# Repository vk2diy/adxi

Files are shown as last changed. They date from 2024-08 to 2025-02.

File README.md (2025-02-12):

# adxi - ADX Improved

[ADX](https://github.com/WB2CBA/ADX) is an abbreviation for Arduino Digital Xceiver, a project emphasizing simplicity and Arduino hardware creating a [direct-conversion receiver](https://en.wikipedia.org/wiki/Direct-conversion_receiver) focused on [digital modes](http://www.arrl.org/digital-data-modes).

The ADX project was based upon firmware by [JE1RAV](https://github.com/je1rav/QP-7C) extending on original work by Burkhard Kainka (DK7JD) ([original German](https://www.elektronik-labor.de/HF/FT8QRP.html), [English translation](https://www-elektronik--labor-de.translate.goog/HF/FT8QRP.html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)).

This (very distant!) fork of ADX is called __adxi__ (or "ADX Improved") with the following major changes:
 * __abandon simplicity as a design philosophy__ since it limits our feature set and understanding
 * __improved design documentation__ to facilitate learning
 * __restores access to the project for modern KiCad__
 * __integrate known bug fixes__
 * __operates from a single USB-C cable__ replacing the need for an MCU programming cable, a power cable, an audio input cable, an audio output cable, and a host computer sound card.
 * __USB-C power supply__
 * __full computer control__ (remove buttons/blinkenlights interface)
 * __improved filtering__
 * __SWR, forward power and reverse power metering__ for debugging, safety and performance analysis
 * __supports more amateur bands__: 70cm/2m/10m/15m/17m/20m/30m/40m/60m/80m/160m/630m/2200m
 * __use of modern surface mount components__ for repeatability
 * __using platformio__ to manage the firmware build and dependencies in a modern way

## Other projects
 * Same MCU
   * [ADX](https://github.com/WB2CBA/ADX) ($? / ATMega328P based / multiple bands with effort / LED blinkenlights/ CD2003GP direct conversion receiver)
   * [(tr)uSDX](https://dl2man.de/) (PE1NNZ and DL2MAN) ($50 / ATMega328P based / multiple bands with effort / small OLED / direct sampling)
     * Based on [µSDX](https://github.com/threeme3/usdx)
 * Fancy-pants MCU
   * [sbitx](https://github.com/afarhan/sbitx) ($150+ / RPi4 based / 8 bands preconfigured / large OLED) ([documentation](https://www.sbitx.net/), [designer website](https://www.hfsignals.com/index.php/sbitx-v3/)) (newer zbitx)
 * Discussion
   * [ucx discussion group](https://groups.io/g/ucx)

## Project scope

The project scope generally includes the following:
 * Main board
 * Late stage board modules (each for different frequency bands)
 * Assembly information
 * Design documentation
 * Debugging documentation

## Current status of this fork

The first boards have been received and despite issues have been verified as partly functional.

Completed:

 - [x] Updated schematic (Kicad 8)
 - [x] Layout
 - [x] Late stage module interface design
 - [x] Design and layout of first late stage module 
 - [x] Firmware building correctly under platformio
 - [x] Final design review
 - [x] Order boards

Underway:

 - [x] Board testing and bringup
   - [x] USB hub verified
   - [x] USB audio verified
   - [x] USB MCU module passthru verified
   - [x] Power stage testing completed (issues found; resolution proposed and partly bench tested)
     - [x] Design and order power stage fix board
     - [x] Receive and assemble power stage fix board
     - [x] Debug power stages with fix board
   - [x] Assemble, solder-configure and mount late stage module
   - [ ] Firmware authoring to verify remaining functional blocks (in progress)
   - [ ] WSJT software integration testing (in progress)
 - [ ] Test late stage module
 - [ ] Verify overall system functionality
 - [ ] adxi-1.3 main board revision - incorporating power stage fixes and other improvements.
   - [x] Created new board tree

## Update (2025-01-27)

 * Started on looking at the late stage module (LSM) board.
 * Isolated 40M band LPF on a new board by cutting the trace from the impedance matching.
 * Instrumented both sides with NanoVNA but did not get expected results from the 7th order Butterworth approximation with values produced by [classe2-calculator](https://github.com/vk2diy/classe2-calculator), namely:
   * Command line: `./classe2 -p 5 -v 12 -b 40m -t infinite --l1 7.755uh -m SI2304DDS`
     * ie. Power 5W, voltage 12V, band 40m, type infinite, Class E L1 value 7.755uH, MOSFET SI2304DDS.
   * Output for precise configuration (not used): `7th = (0.23% error, 18 parts): C1_lpf=132.00pF (220.00pF || 330.00pF) L1_lpf=0.93µH (2.2µH || 2.7µH || 3.9µH) C2_lpf=536.00pF (33.00pF + 33.00pF + 470.00pF) L2_lpf=1.5µH (2.7µH || 3.3µH) C3_lpf=536.00pF (33.00pF + 33.00pF + 470.00pF) L3_lpf=0.93µH (2.2µH || 2.7µH || 3.9µH) C4_lpf=132.00pF (220.00pF || 330.00pF)`
   * Output for approximation configuration (used): `7th ≈ (13.57% error, 7 parts): C1_lpf=150.00pF L1_lpf=1µH C2_lpf=470.00pF L2_lpf=1.5µH C3_lpf=470.00pF L3_lpf=1µH C4_lpf=150.00pF`
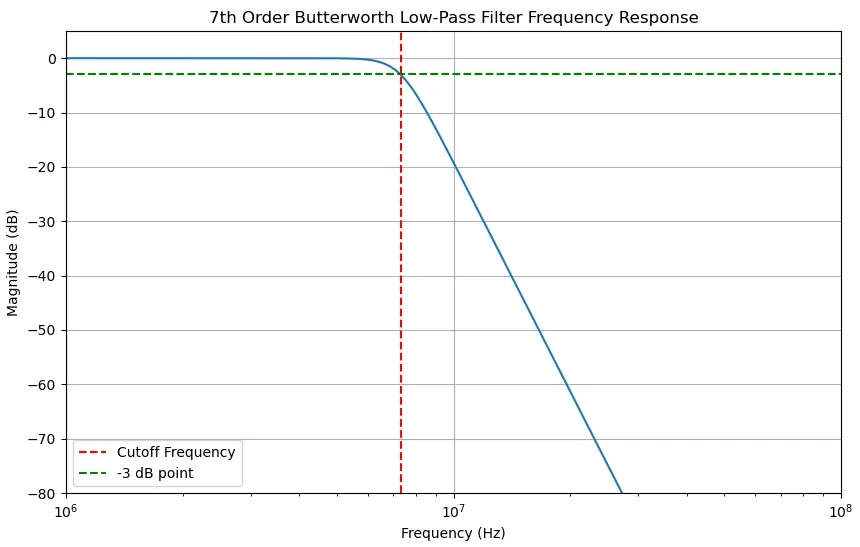
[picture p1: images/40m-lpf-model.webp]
 * I had expected to see a rapid falloff at a specific frequency, like this modeled version: 
 * However, instead I obtained very different results.
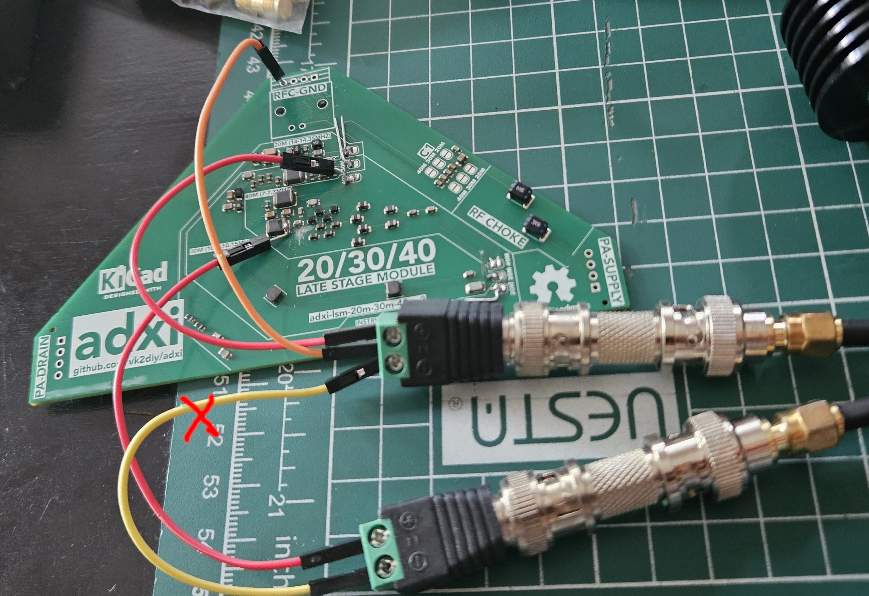
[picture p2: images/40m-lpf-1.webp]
   * __Test setup__. I did try to test with the extra ground cable shown with a red X, but removed it (ground loop). No substantial change.  
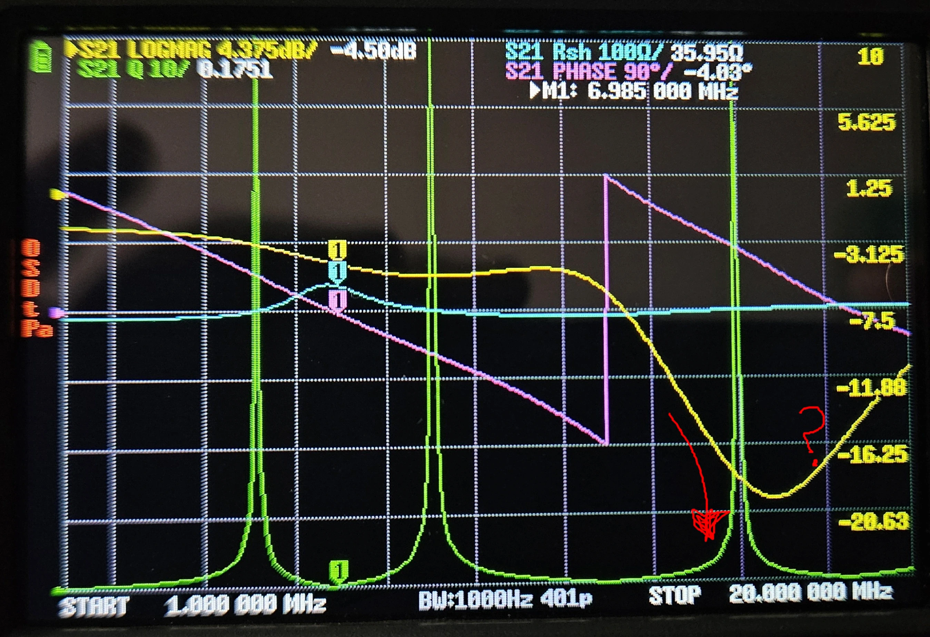
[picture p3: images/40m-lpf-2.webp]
   * __Test result__. This remained fairly constant in all test configurations (with and without termination resistors, various ground configurations). 
     * What we can see here is:
       * __S21 Logmag__ in yellow (~"through signal attenuation") shows a downward slope within the target band (marker location) before a flat response through around 13MHz at which it begins to taper off fairly steeply until 17MHz at which point it begins to climb again.
         * Our expectation would have been "falling off a cliff" after the filter cutoff frequency and not recovering until very high frequencies due to self-resonance of individual components.
         * This is a head scratcher.
       * __S21 Q10__ in green (~"resonance or energy storage potential") is an undesirable feature in a low pass filter. However, we can see significant Q values around 5MHz and 9MHz.
         * This would seem to indicate there is a source of resonance within the test circuit which we have not identified. However, without other points of comparison it may be hard to determine how abnormal this is.
       * __S21 Rsh__ in cyan (~"shunt resistance") exhibits a small peak around the target frequency but is otherwise flat.
       * __S21 Phase__ in magenta (~"phase angle") shows the target frequency band exists within the middle of a smooth phase cycle. There is no information in this to suggest an issue. However, it is notable that the phase shifts at 13MHz where we see the attenuation increase markedly. From prior experience it is common and expected for phase change to align with the end of designed frequency ranges.
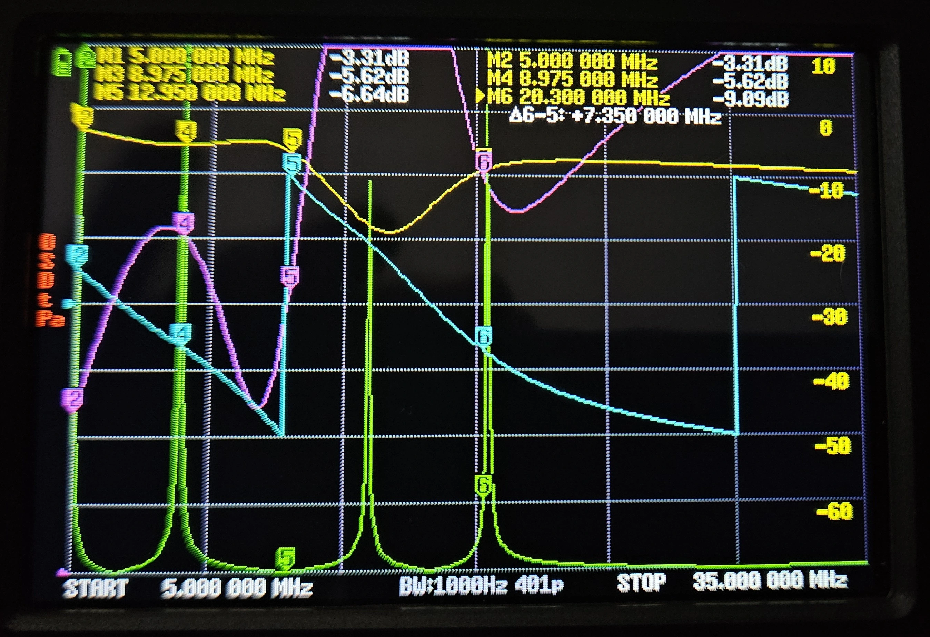
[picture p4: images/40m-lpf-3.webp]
   * __Broader result__. This shows markers for the 40m as well as 30m and 20m bands. You can see the attenuation restores rather than decays with increasing frequency after 17MHz, which is unexpected.  
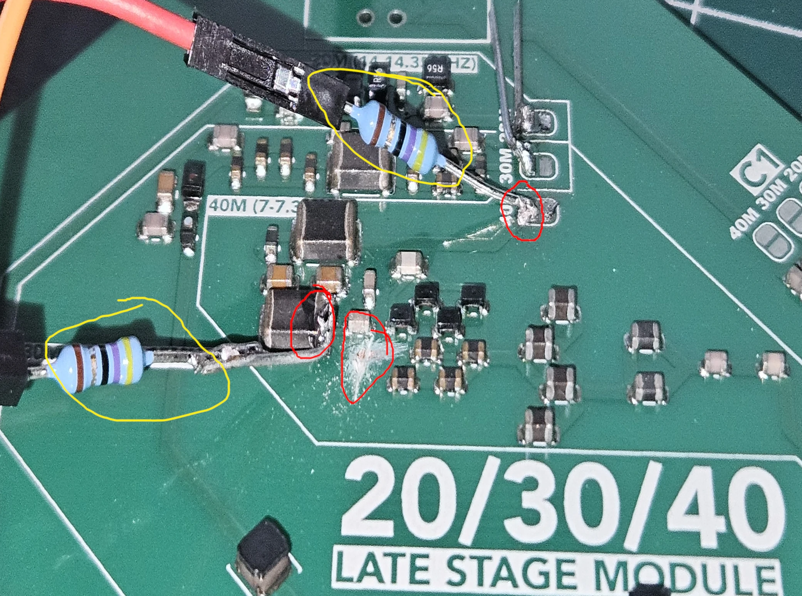
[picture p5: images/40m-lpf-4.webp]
   * __Final test setup__. Note cut trace, solder points and 47 ohm series resistors at either end. No substantial difference. 
 * I am as yet uncertain why this is.
   * Hypothesis: Incorrect impedance matching.
     * Determination: Invalid. Added 47Ω resistors either site of the LPF DUT with no substantial difference observed.
   * Hypothesis: Low SRF components.
     * Determination: Invalid. All components in the filter, both small capacitors and inductors should have higher SRFs, at least in the 100-200M+ range at a minimum. However, they are not reported in the datasheet as they are not high end components. Even with low end assumptions this should provide a safe 'order of magnitude' (<10M vs 100M+) buffer.
   * Hypothesis: Poor grounding.
     * Determination: Possible but unlikely. Connecting the ground at both ends of the DUT (ie. ground loop) causes no significant shift in the VNA output, versus just one end.
   * Hypothesis: Poor calibration.
     * Determination: Used a range of new calibrations, stored calibrations and recalibrations but in no case did this alter the general frequency response.
 * __Next steps__
   * I put it away and will come back to it another day to look at the 30M and 20M LPFs - hopefully one of them works!
   * I could try adding a solid ground plane just to see the difference.
   * I could try fabricating a range of physically separate filters as standalone PCBs to simplify debugging (no test points and cutting traces is a real pain).

## Update (2025-01-19)

 * Been awhile since an update, but haven't been idle.
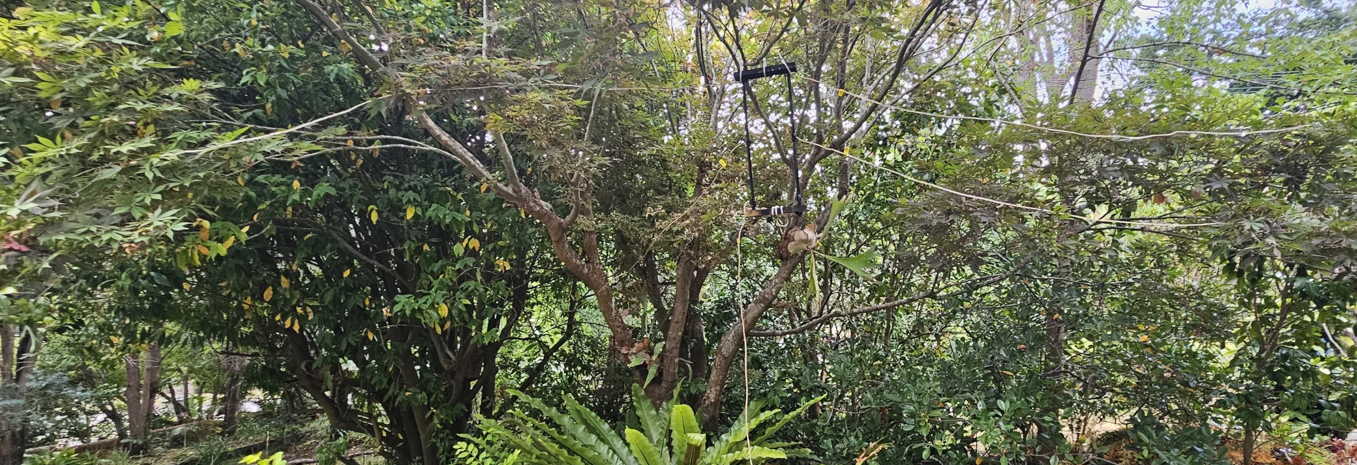
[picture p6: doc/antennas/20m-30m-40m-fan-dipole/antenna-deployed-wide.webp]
 * [Built, tuned and tested a 20m/30m/40m fan dipole antenna](doc/antennas/20m-30m-40m-fan-dipole) and got this running with an RTLSDR as a reference point in order to support further testing. Despite being barely 1.5m off the ground and threaded through foliage, it works! Signals have been received from most continents already. 
 * Updated test plan:
   - [x] Antenna system
     - [x] Build or acquire a viable antenna
     - [x] Verify with NanoVNA and attenuator for protection
     - [x] Verify with other radio hardware
   - [ ] The power amplifier
     * Power amplifier low pass filter, matching network and resonator
       * NanoVNA between the band-specific solder bridges (fresh board, none soldered closed)
     * RF choke
       * NanoVNA between the `PA-SUPPLY` and the nearby solder bridges (fresh board, none soldered closed)
   - [ ] MCU power amplifier drive PWM signal
     * Instrument appropriately with scope then test with custom firmware
   - [ ] MCU receive enable signal
     * Instrument appropriately with scope then test with custom firmware
   - [ ] The demodulator chip
     * Verify configuration straps with scope
     * Verify expected input signal is present with scope
     * Verify output signal is present with scope
   - [ ] The USB sound chip
     * Verify configuration straps and/or MCU control lines
     * Verify input from demodulator and channel mixing is present
     * Monitor computer audio through regular audio software
     * Try creating static if necessary by shorting low voltage leads
     * Verify static comes through to computer audio software

## Update (2024-12-04)
 * [Proposed test plan](kicad-pcbs/adxi/README.md) for resolving current state focused on iterative verification

## Update (2024-11-25)

 * Researched Linux-based serial data capture solutions with an eye toward [Wireshark](https://www.wireshark.org/) (which my brain still calls *Ethereal*!) and hit on [socat](http://www.dest-unreach.org/socat/), which is a spiritual successor to Hobbit's [netcat](https://sectools.org/tool/netcat/) that talks serial in addition to TCP/UDP and should therefore do the job.
   * It seems [very closely aligned functionality for logging devices under control by other programs was added in or before 2021](https://news.ycombinator.com/item?id=26604002)
   * To date I have been attempting to manually interact with the firmware using [minicom](https://salsa.debian.org/minicom-team/minicom) which is tedious.
   * It would be much better idea to create a test harness using [platformio](https://platformio.org/) to fire up [WSJT-X](https://wsjt.sourceforge.io/) and monitor the serial traffic to verify suspected interactions are taking place.
   * The best time to do this is immediately after a successful firmware upload, when the device firmware version, device name, etc. are all known.
   * Well written, such a test harness should:
     * Provide a high iteration speed platform for firmware testing and development
     * Catch changes to `WSJT-X`
     * Catch firmware bugs
     * Protect against firmware regressions.
     * Be portable to alternative, future MCUs (eg. `RP2040`).

## Update (2024-11-24)

 * [Stepping through manual clock control](kicad-pcbs/adxi/README.md) with the `SI5351` as a means to test the subsystem.

## Update (2024-11-22)
 * Got host system audio working.
 * WSJT initial errors all resolved
   * Audio interface errors resolved
   * USB serial interface errors resolved
   * Configuration errors resolved
   * Basic interface testing should now be possible.  The following error simply indicates the firmware is not responding as expected over serial (because we have been modifying it for testing).

```
Hamlib error: read_string_generic called, rxmax=4095 direct=1, expected_len=1
tcflush
write_block(): TX 3 bytes, method=2
0000    46 41 3b                                            FA;
read_string_generic called, rxmax=128 direct=1, expected_len=1
read_string_generic(): Timed out 0.200 seconds after 0 chars, direct=1
kenwood_transaction: read_string(expected=128, len=0)=''
kenwood_transaction: read_string retval < 0, retval = -5, retry_read=0, rs->rigport.retry=0
kenwood.c(628):kenwood_transaction returning2(-5) Communication timed out

kenwood_open: no response from rig
  2:kenwood.c(940):kenwood_open returning(-5) Communication timed out

  2:rig.c(7525):async_data_handler_stop entered
  2:rig.c(7555):async_data_handler_stop returning(0)
ser_close: restoring options
 1:rig.c(1301):rig_open returning(-5) Communication timed out

Communication timed out
Communication timed out
 while opening connection to rig

Timestamp: 2024-11-21T23:32:09.208Z
```
 * Turned out that even when dropping the effectively original serial handling code in place, the same error persisted.
   * This lead me to believe that there was some sort of timeout going on; perhaps in the I2C communication with the clock generator chip.
     * I tried uploading the same firmware to an MCU module with no hardware connected and obtained the same result; this was semi-confirmatory.
     * I instrumented the code by hand to obtain an understanding of where the latency was occurring.
     * After re-enabling `Serial.setTimeout(4)` things sped up.
   * I tried going back to the assembled board with this revised code to see if WSJT would initialize correctly.
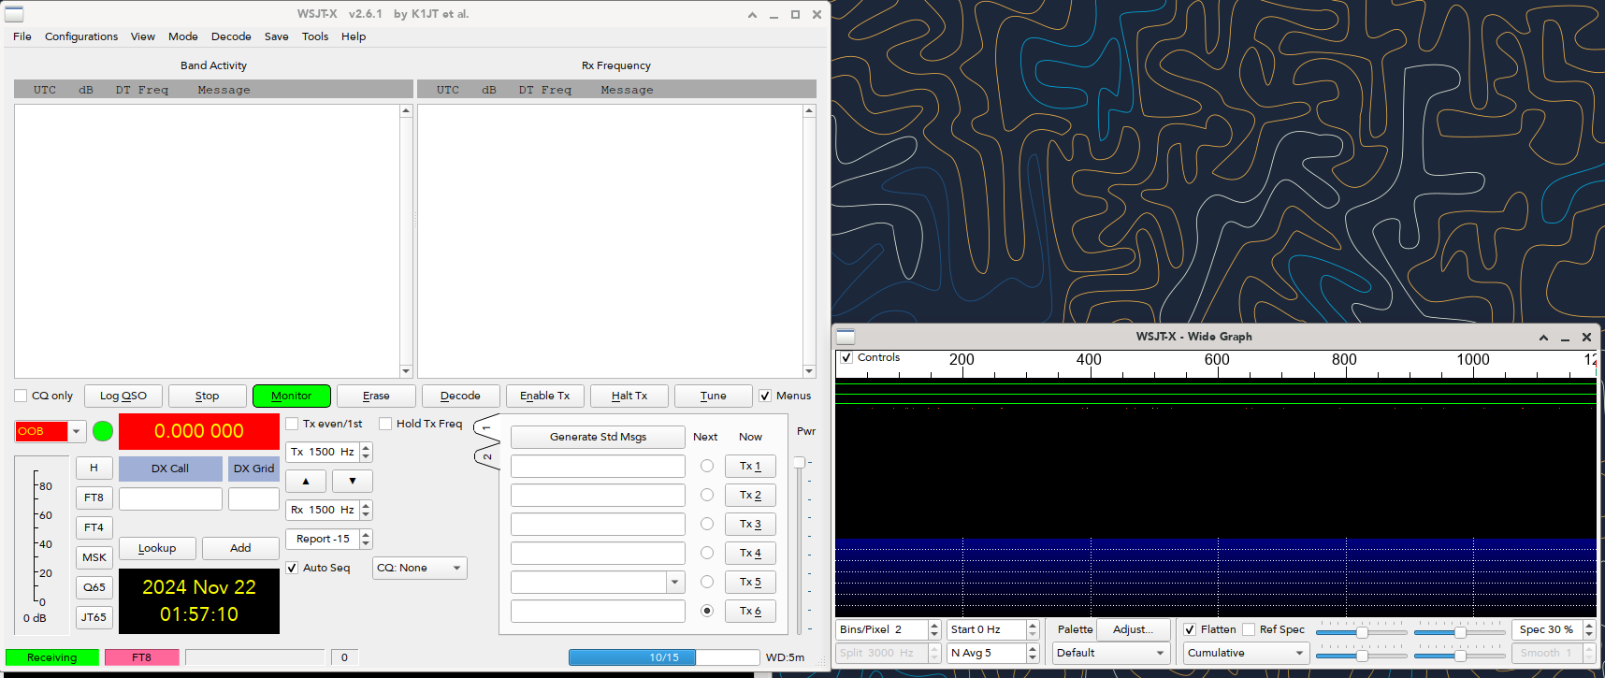
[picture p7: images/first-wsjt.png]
 * WSJT now starts with no error! This is a pretty good milestone for further work. 

## Update (2024-11-20)
 * Went to test the [WSJT](https://wsjt.sourceforge.io/) integration and found my kernel doesn't have audio, wasted most of a day rejigging Gentoo packages and kernels (to be fair, upgraded almost everything on the system to latest and overcame some rustic and pythonic meta-situational transgressions)

## Update (2024-11-19)
 * Power stage fix board [fully debugged](kicad-pcbs/adxi-1.2-powerfix-1/), plugs in and works from USB-C
 * Firmware can now be uploaded and tested with no bench supply
 * Modified platformio configuration to get firmware uploads reliably working 

## Update (2024-11-11)
 * Began rewriting firmware, made gross simplifications, probably broke some stuff, and found another hardware bug.
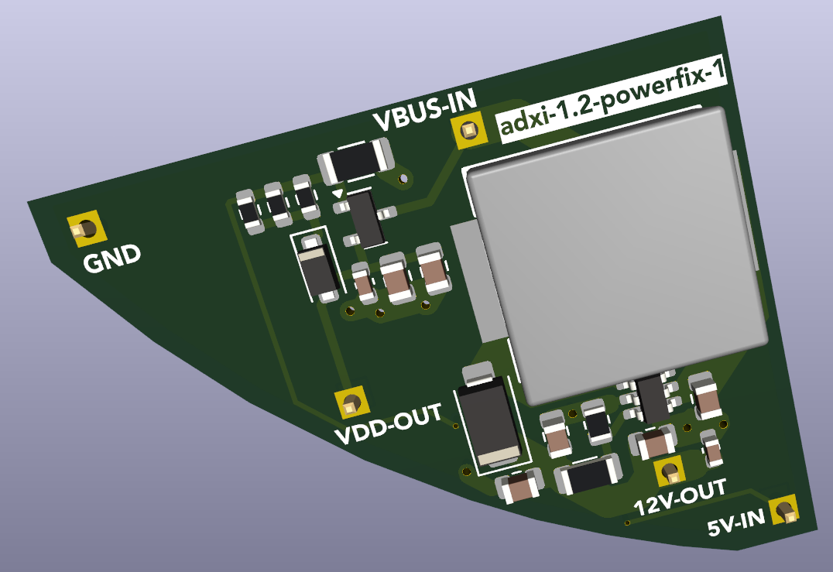
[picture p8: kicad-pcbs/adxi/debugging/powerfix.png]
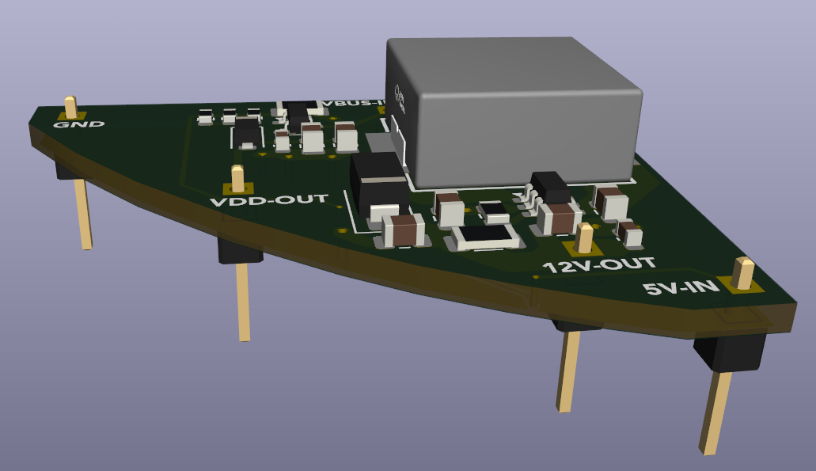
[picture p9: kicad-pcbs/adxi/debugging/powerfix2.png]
 * Designed and ordered a power stage fix board. This should resolve the issues detected to date.   

## Update (2024-11-10)
 * [Bench testing](kicad-pcbs/adxi/) of the switchover part of the proposed power solution did not go according to plan, despite attempting two different combinations of Schottky diodes in a passive configuration, adding resistors and generally investing time.
   * The final perspective was that the issue could be the components themselves, could be the topology or could be a property of the bench supply channels when simultaneously applied to a circuit (various earthing options were tested).
   * The conclusion was to move to an active switching topology using a power MOSFET in a standard package size. This will disconnect the early stage supply once the regulated supply becomes available.

## Update (2024-11-09)
 * A [very busy week testing](kicad-pcbs/adxi/). 
   * Issues found in the power stages were numerous.
     * First there was a topology error in the USB power, mostly due to lack of personal dilligence in critically evaluating the datasheets, but also inexperience with USB power.
       * I am confident this should be resolved in the next revision or in a fix.
     * Second the boost converter had huge issues
       * First it was missing capacitance which was actually critical (unlike bulk output capacitance which may often be removed or reduced, high frequency capacitors are very important for stable boost conversion)
       * Second the inductor was oversized, as the datasheet simply suggested a range and I'd picked the larger end. Well, turns out there's a way to select these and I should have picked the middle to low end.
     * Third the unstable boost converter output with huge 75V swings was probably responsible for burning itself out, but also it was responsible for making the subsequent 12V regulator fail. Thankfully I was able to demonstrate that as soon as power was cut, however, the capacitor (added) was able to feed the 12V regulator and achieve perfect output.
   * None of these issues are critical, all can be resolved by power bypass or modification.
   * A potential fix board has been generally designed, but firmware testing to allow the evaluation of other functional blocks will proceed before an order is placed, just in case we have other issues and it may be more useful to redo the board as a whole.
   * Once this has been done, the new problem of testing the late stage module begins, which will no doubt involve some pretty NanoVNA graphs. I might cut one board to segment it in to functional blocks so that each can be characterised independently. This will not cause any loss of boards, because after testing is complete the board can be solder-configured for an alternate band (each initial late stage module supports 20m/30m/40m bands, but only one at a time, and I had 20 made for only 10 radios).

## Update (2024-11-05)

 * Boards arrived yesterday!
 * A [detailed log of debugging is available here](kicad-pcbs/adxi/)
 * Currently there is an issue with the USB power circuitry which I am working to resolve. It seems I made a mistake on this part of the design due to inexperience.
 * Bypassing that supply with a bench supply results in correct USB connectivity to all devices, which is very promising and quite rewarding given this is my first USB device.  
 * Probably, this means I can use the current boards by adding some external components, which have been ordered.
 * Further testing continues.

## Update (2024-10-24)

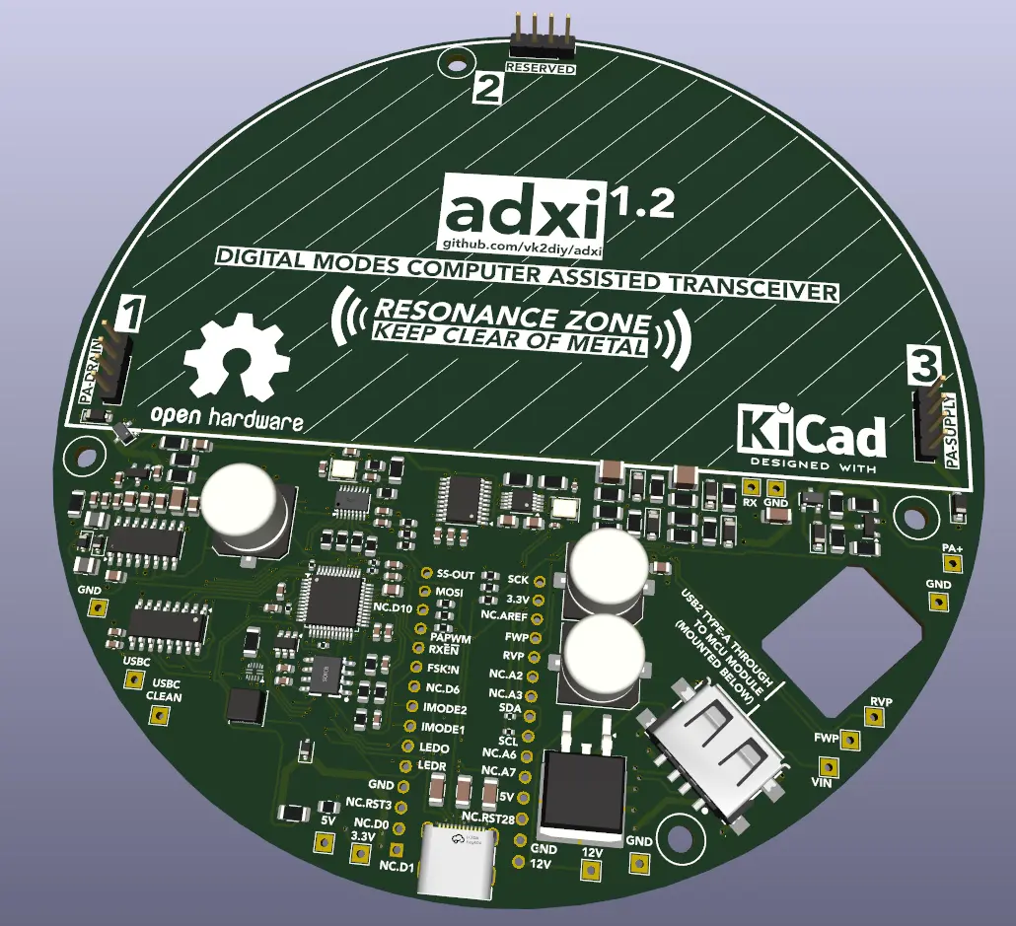
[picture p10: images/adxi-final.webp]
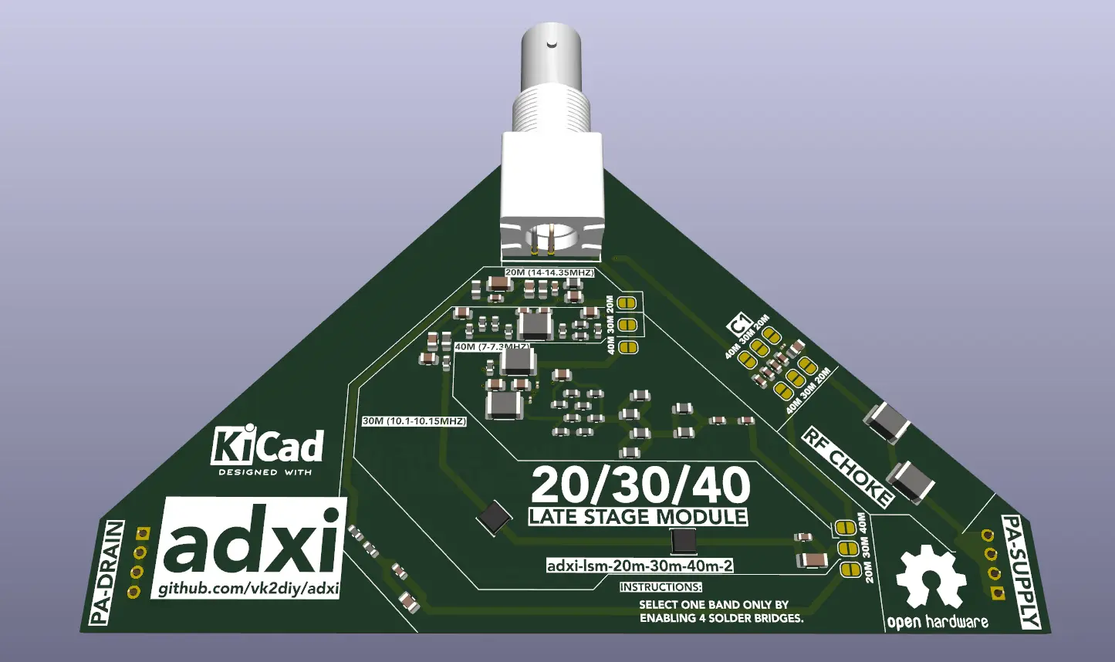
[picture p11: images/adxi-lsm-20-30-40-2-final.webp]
 * Finally ordered the boards, final versions as follows.  
   * Delays were mostly due to the need to update [classe2-calculator](https://github.com/vk2diy/classe2-calculator) to replace portions deemed inappropriate during DFM review and other matters taking my time.
   * I expect to receive the boards in a couple of weeks... looking forward to testing!

## Update (2024-10-03)

 * Quite a lot of progress.
   * [classe2-calculator](https://github.com/vk2diy/classe2-calculator) (pronounced "classier calculator") is reaching a fairly mature state with some very useful output.
     * Three power amplifier topologies are support: `-t infinite`, `-t finite` and `-t inverse`.
     * Three matching network topologies are supported: `-M l`, `-M t` and `-M pi`.
     * 1st-7th order low pass Butterworth filter networks are supported, these are automatically generated for all orders.
     * In all cases, practical approximations using standard component values are generated and ranked in descending order of accuracy along with part counts.
   * Late stage module
     * The late stage module has been redesigned with the new calculations.
     * Upon advice, the antenna tuning features have been dropped.
   * Main board
     * The main board has been redesigned as v1.1 and subsequently (underway) as v1.2
     * When the v1.1 was ordered, a number of issues were uncovered:
       * Component selection: overpriced components, unavailable components and undue component quantities
       * Double-sided assembly: one of the key components that is unrealistic to manually assemble is the USB-C port which had been placed on the underside. This however needs to move to the top side for process reasons.
       * In order to facilitate the above, a hole must be cut in the board for the MCU to MCU USB-2 interface port cable, since it cannot be on top of the board.
       * Thankfully some component upgrades (1000uF caps) and consequent board space downsizing has shown there is probably *just* enough space to make this happen.
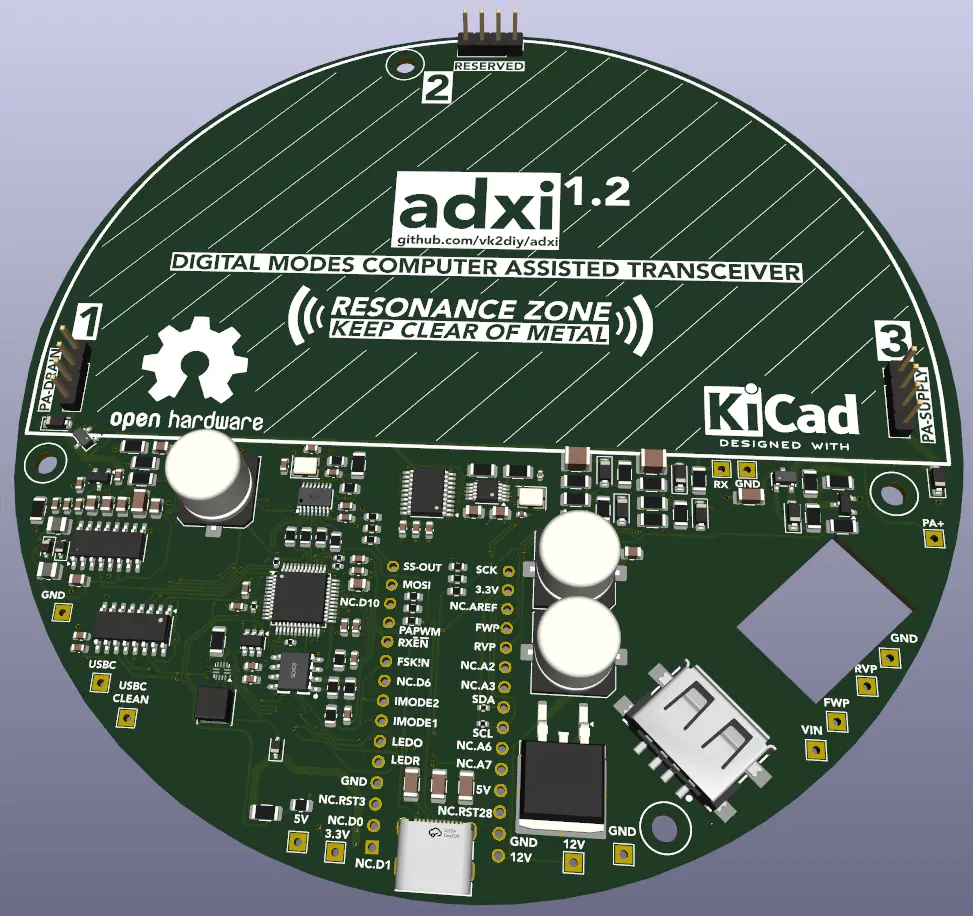
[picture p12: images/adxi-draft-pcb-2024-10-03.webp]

   * I will not be focused on this project for a little while due to other commitments but will finish it ASAP.

## Update (2024-09-18)

 * __Still working on the [novel Class E component calculator tool](https://github.com/vk2diy/classe2-calculator)__. Turns out there's a lot of background to the evolution of the physics equations and AC circuit theory is a bit different to the DC stuff I'm used to, so this is taking awhile.
 * __Discovered another component concern__, this time Zener Diodes. 
   * Basically due to the difficulty of finding high voltage rated components the approach of using zener protection had been put forward. This is not particularly common in resonators, and probably for good reason.
   * Further research revealed the reason why.  So it seems that the use of Zener Diodes creates an increase in effective shunt capacitance (somewhat similar to the output gate capacitance or `C(OSS)` of a MOSFET) which effectively works in parallel to the shunt capacitor `C1`.
   * The previous zener diode was selected for as low a voltage as possible, but this is not a good look, particularly when using multiple zener diodes in parallel (the design had three).
   * Apparently, the higher the zener diode voltage rating, the lower the capacitance, because:
     * Depletion region width: As the voltage rating of a zener diode increases, the width of the depletion region in the PN junction also increases, and the wider depletion region results in a lower capacitance, as capacitance is inversely proportional to the distance between charge carriers.
     * Doping levels: Higher voltage zener diodes typically have lower doping levels. Lower doping leads to a wider depletion region and thus lower capacitance
.
     * Junction area: For a given power rating, higher voltage zener diodes often have smaller junction areas. A smaller junction area results in lower capacitance.
     * Reverse bias effect: As reverse voltage is applied to a zener diode (before breakdown), the depletion region expands further, reducing capacitance.
     * Higher voltage zeners operate at higher reverse voltages, leading to lower capacitance.
     * This relationship can be expressed mathematically as $$C = \frac{K \times D^4}{(\rho V_C)^n}$$ or the Unicode equivalent `C = (K × D^4) / (ρV_C)^n`
       * `C` = Capacitance
       * `K` = Constant
       * `D` = Junction diameter
       * `ρ` ($\rho$) = Material resistivity (related to doping)
       * `V_C` ($V_C$) = Voltage across the junction
       * `n` = Exponent (typically around 0.5) 
     * As the voltage rating (`V_C`) increases, the capacitance (`C`) decreases.
     * Once the zener reaches its breakdown voltage, the capacitance tends to stabilize and doesn't change significantly with further increases in current.
 * __Discovered some low-voltage components__.
   * Certain components will be swapped out for higher voltage equivalents.
 * __Discovered less than ideal diode selection__.
   * Diode switching speed in the forward and reverse power sampling circuit was identified as a concern.
   * I have done a [write-up on this](doc/swr-and-power-metering)
 * __Discovered topology error__.
   * Through a manual review, discovered not one but two topology errors in the late stage modules.
   * One error was to do with the overall topology across the main board interface.
   * One error was to do with the ordering of resonator components (`L2`/`C2` inverse).
   * The first prototype late stage module schematic has been updated to reflect the correct topology.

## Update (2024-09-11)

 * No update for almost a week, but I have been busy! The design review has revealed a large number of issues requiring resolution.
 * __Two full days were spent creating and enhancing new Class E calculator software__.
   * This decision was prompted by the revelation that repeatedly running existing third party software was an inefficient means to explore the solution space and certain concerns were raised regarding ambiguities in the algorithm, inputs and outputs for third party tools. No final tool was created however a lot of functionality was explored, including:
   * The generation of basic Class E circuit values.
   * The generation of matching networks in both "L" and "Pi" configurations.
   * The storage, retrieval and referencing of band information, transistor information, capacitor and inductor information.
   * Efficient caching systems for achieving faster reslts than naive depth-first search in the solution space.
 * __Development of the tool put on hold temporarily, and to assist with verification a number of existing third party tools were surveyed__.
   * The conclusion of the existing software survey was that much existing (pre-SMD) software is sub-optimal for a modern SMD-based device design use case:
     * Often the software is produced by HAM hobbyists to scratch and itch and does not meet broader requirements.
     * A common shortcoming was the explicit assumption of the use of hand-wound coils and the provisioning of coil-winding instructions rather than SMD component selection information.
     * Another shortcoming was the use of imperial measurements (no metric support).
     * Another shortcoming was the use of simple algorithms where more advanced information and methods are now available. For example, it is generally impossible with most tools to model the use of a given circuit with anything but a 50% duty cycle.
     * The main and overwhelming shortcoming was a critical lack of design documentation, specifically including an explanation of which algorithm was in use, and for what purpose, informed by which literature, etc. The majority of HAM-grade tools just provide hand-wavey references to *Sokal*, *NM0S*, and it has been shown that the latter incorporate circular references of dubious or limited connection the broader scientific literature. This is just not a good basis for moving forward with a proper understanding of the design space.
 * From a practical standpoint:
   * __Transistor selection was shown to be bad__. The transistor somewhat arbitrarily selected has proven insufficient for the application and thus will be replaced. While the power handling was excellent, certain aspects of its design (in particular output capacitance) were shown to be far in excess of practical for this application. Currently it seems the preferred replacement citing availablity, cost and modeling will be the `SI2304DDS`.
   * In terms of design verification, education and tuning, __current sensing would be very useful__.
     * Specifically, the ability to sense current in order to visualize the switching action of the Class E Power Amplifier primary switching device across input drive signal, load current and load voltage in order to verify the primary properties of the Class E Power Amplifier are in tune with the required characteristics, ie. zero voltage and zero current at the time of switching.
     * According to various sources ([TI](https://www.ti.com/lit/eb/slyy154b/slyy154b.pdf), [Analog Devices / Linear Technology](https://www.analog.com/media/en/technical-documentation/app-notes/an-105fa.pdf), [Renesas](https://www.renesas.com/us/en/document/apn/current-sensing-low-voltage-precision-op-amps), [Bourns](https://www.mouser.com/pdfdocs/bourns_n1702_current_sense_accurate_measurement_appnote.pdf), [Mouser/Microchip/Vishay](https://www.mouser.com/pdfDocs/microchip-vishay-current-sensing-whitepaper.pdf) and [ElectroicDesign](https://www.electronicdesign.com/technologies/power/article/21806322/electronic-design-using-resistors-for-current-sensing-its-more-than-just-i-v-r)) and a cursory review of lab equipment available for current sensing with oscilloscopes, plus some prior experience building current sensing circuits within boards using op amps, __it seems that it would be desirable to provide a measurement test point across a shunt resistor specifically for the provisoning of current measurement__.
     * Not having had the need for higher frequency measurements in the past, __my oscilloscope is limited to 70MHz which the following calculations show is perhaps just within the recommended range for this purpose__. For the higher frequency bands, this sampling and verification strategy will certainly run in to issues with my current test equipment.

| Band | Frequency | Nyquist | Practical Rate (2.5x) | Recommended Rate (3-5x) |
| ---- | --- | --- | --- | --- |
| 20m  | 14 MHz	 | 28 MHz	 | 35 MHz | 42-70 MHz |
| 30m  | 10 MHz | 20 MHz  | 25 MHz | 30-50 MHz |
| 40m  | 7 MHz | 14 MHz  | 17.5 MHz | 21-35 MHz |

 * From a theoretical standpoint:
   * It was found that Class F and Class E/F circuits are sometimes mislabelled as Class E in software and this should be kept in mind.
   * The generation of Class F and Class E/F could be a rational decision for the analysis software.
   * It seems *critical* to actually visualize the actual switching-time voltage and current in order to fully comprehend and verify a Class E implementation, thus hardware must be designed to facilitate.
   * The degree to which different component blocks interact or are operation or replaceable should be more thoroughly investigated. For example:
     * Many source suggest the L1 RF Choke should be 10-15x L2 (resonator inductance) but do not further specify tuning.
     * Some sources suggest the L1 RF Choke can be larger than specified without incident, thus a common large inductor might be selected to cross all bands.
     * L1 (RF Choke) is apparently possible to replace with a "finite DC feed inductance" (FDI) and this is apparently well known and desirable at higher frequencies, eg. our targeted 70cm.
 * Next steps:
    * It now makes sense to spin the emergent calculation tool off in to its own tool which can be managed separately
    * After that is in a state of relative verification (re. generates values that generally concur with alternative calculators, includes reasonable defaults, provides useful output) then the component values will be recalculated for the initial late stage module board
    * The late stage module will be modified to include a current sense resistor and test point explicitly to facilitate the visualization of current information on the oscilloscope to demonstrate and tune the Class E circuit operation

## Update (2024-09-05)

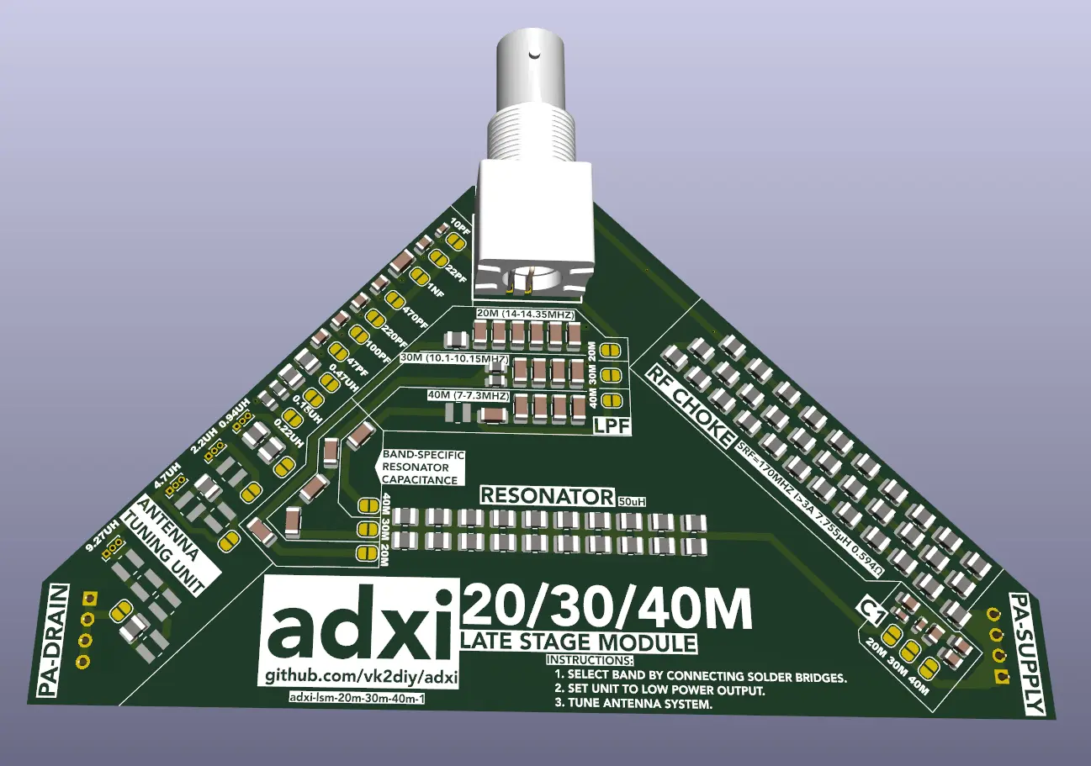
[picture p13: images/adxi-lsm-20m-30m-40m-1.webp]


 * Improved prototype late stage interface module for 20m, 30m and 40m bands
   * Correct rather than vague geometry
   * Correct orientation
   * Inclusion of RF choke
   * Inclusion of Sokal `C1` capacitor
   * Silk screen labels
 * Built-in antenna tuning
   * Based on a series of SMD-fixed elements with a solder-bridge enable
     * This should allow for reasonable tuning without the need for a separate antenna tuning system

## Update (2024-09-04)

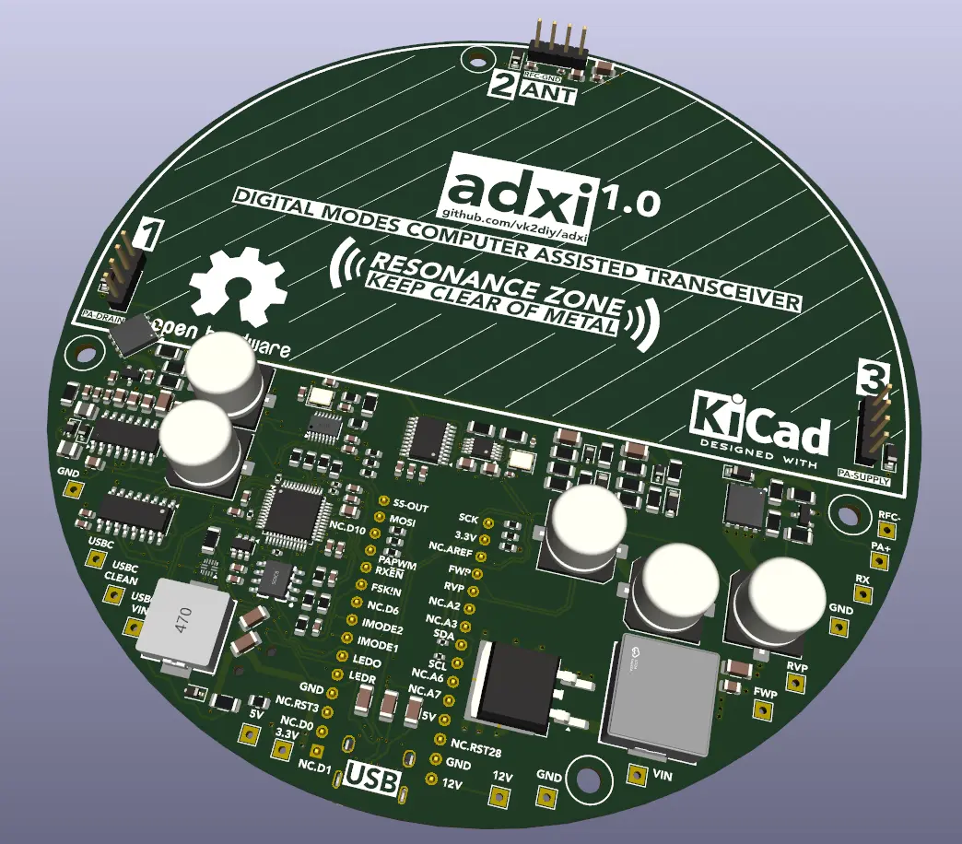
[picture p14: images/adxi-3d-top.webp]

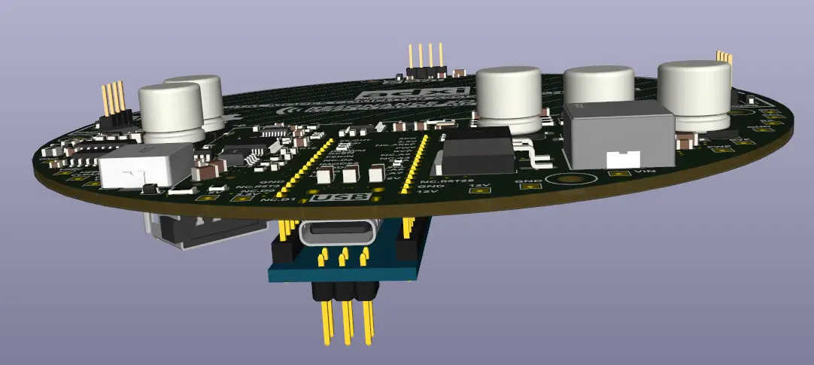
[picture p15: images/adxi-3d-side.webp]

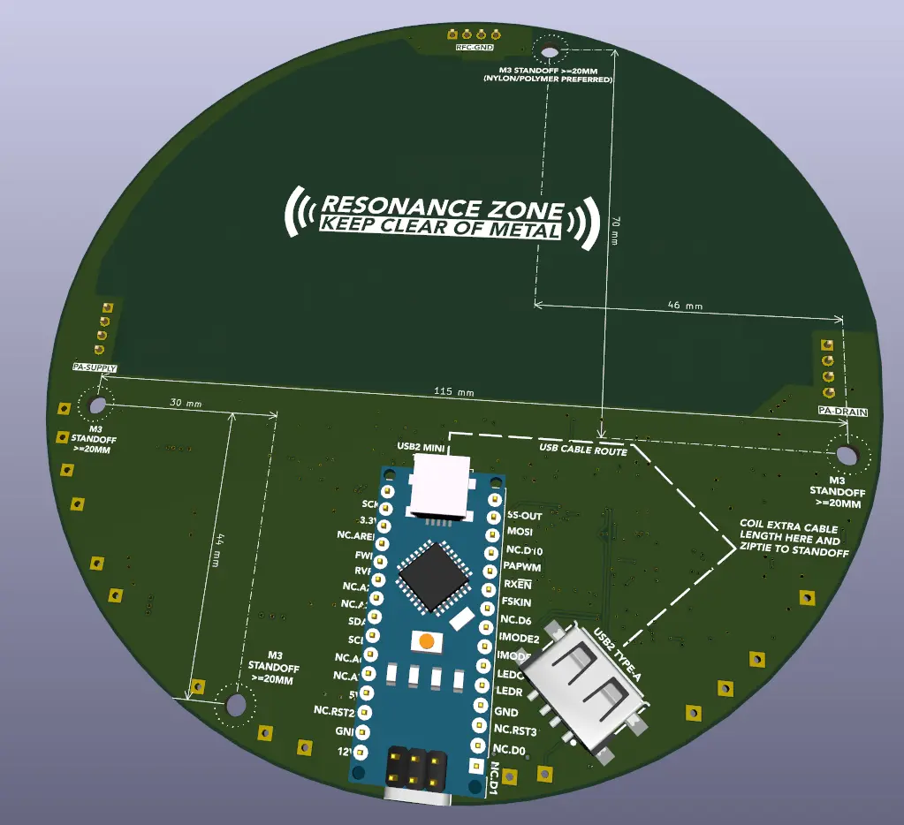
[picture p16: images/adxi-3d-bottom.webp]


 * Add mount point dimensions
 * Updates to silkscreen, including a "what it does" description and MCU labels visible on all pins
 * Significant updates test pads (preferred compact format for oscilloscope attachment, add more `GND` points, reposition a few pads)
 * Add 3D model of Arduino Nano from [over here](https://github.com/g200kg/kicad-lib-arduino) for demonstrative visualization purposes
 * Revisit layout for more cost effective vias (0.3mm vs 0.2mm)
 * Specify (and order) standoffs and cables
 * Moved out late stage schematics (done ages ago) to a separate directory in preparation for late-stage module PCBs
 * __Layout complete! This is version 1.__
 * Bullet point design review to date:
   * Total part-time design time was about 4.5-5 weeks. Actual design time maybe 2 weeks.
   * Initial estimate of "maybe one week" vs actual time investment of 2 weeks and calendar time investment of 5 weeks off by around 100%/500% (not a bad guesstimate!) ... 
     * Learning: Next time multiply the optimistic estimate by five for a real calendar time estimate.
   * Learned a *lot* of basic RF and radio design - both areas totally new to me - including:
     * Which stages require frequency-specific considerations (almost all of them, thus a combined [late stage interface](doc/late-stage-interface) incorporating parts of the Class E Power Amplifier and the band filter made sense, this being an architectural distinction from the previous project)
     * The various classes of amplifiers and detail regarding [Class E Power Amplifier design](doc/class-e-pa)
     * [How to design band-specific LPFs](doc/multi-band-lpfs) and why SRF is important
     * [How to get power from USB](doc/power-supply) and negotiate different power levels, without relying on the MCU module for the same
     * How to on-board a [USB hub](doc/usb-hub)
     * How to on-board a [USB audio chipset](doc/usb-audio-chipset)
     * How to [combine audio channels in hardware](doc/audio-summing)
     * [How to implement SWR, forward power and reverse power metering](doc/swr-and-power-metering)
     * The design history and AM-side configuration of a major family of [receiver chipsets](doc/receiver)
     * Why the old HAM radio trick of building your own coils is a pain in the ass but nonetheless useful to understand
     * A bunch about [antenna tuning hardware](doc/antenna-tuning)
     * Roughly how to use a vector network analyzer and link it with Linux software to characterize an antenna system, filter system, etc. with a frequency response curve
   * Also learned some better fundamentals including:
     * More of a decent background on available filter topologies (usually I just copy whatever's recommended)
     * How to torture AI in to giving you insights in to aspects of electronics design you have no clue about
   * Also came up to date with a few ecosystem state of play issues regarding KiCad 8 library management, fabrication partner file format preferences, etc.
 * Outstanding items
   * No idea if this will work, rather than attempting to roll in a frequency sweep / filter-characterization feature using the spare channel of the programmable clock generator I thought it was best to just order one revision and get things working.
   * Late stage boards with band-specific hardware still require layout
     * Perhaps first produce one popular band so that we can validate the overall design before investing in the others
     * The 20m band has been selected as the band to go for, based upon [WSPRNet Activity](https://www.wsprnet.org/drupal/wsprnet/activity) which is reporting the following bands have the highest recent activity levels:
       * 20m (675× contacts)
       * 40m (540× contacts)
       * 30m (437× contacts)
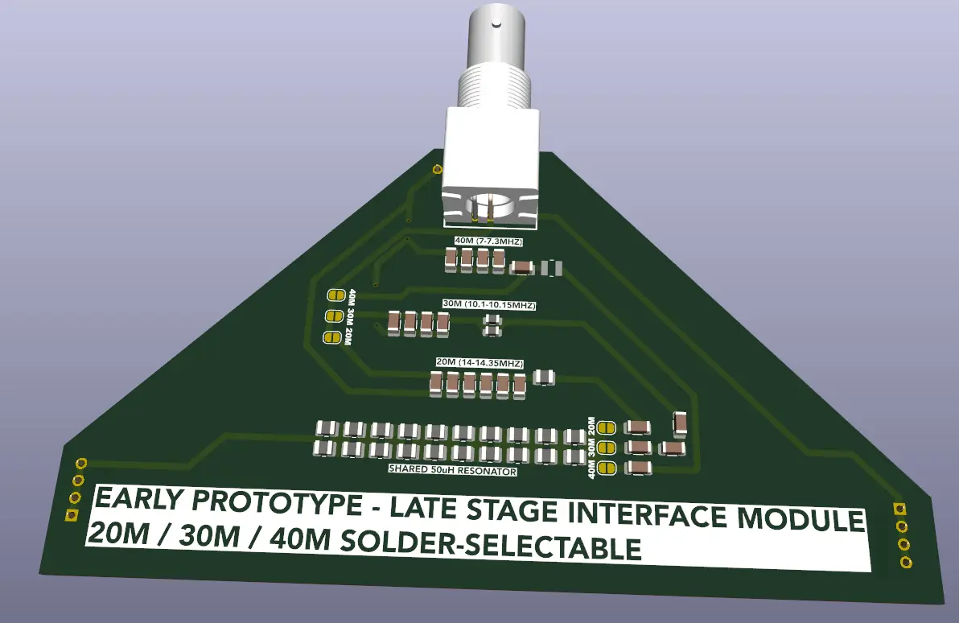
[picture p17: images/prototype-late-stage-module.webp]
     * Made an early-stage prototype with solder-selectable support for all three bands 
   * Ordering
   * Post-ordering
     * Further firmware review and development
     * Try to plan out a test process for each block

## Update (2024-09-03)

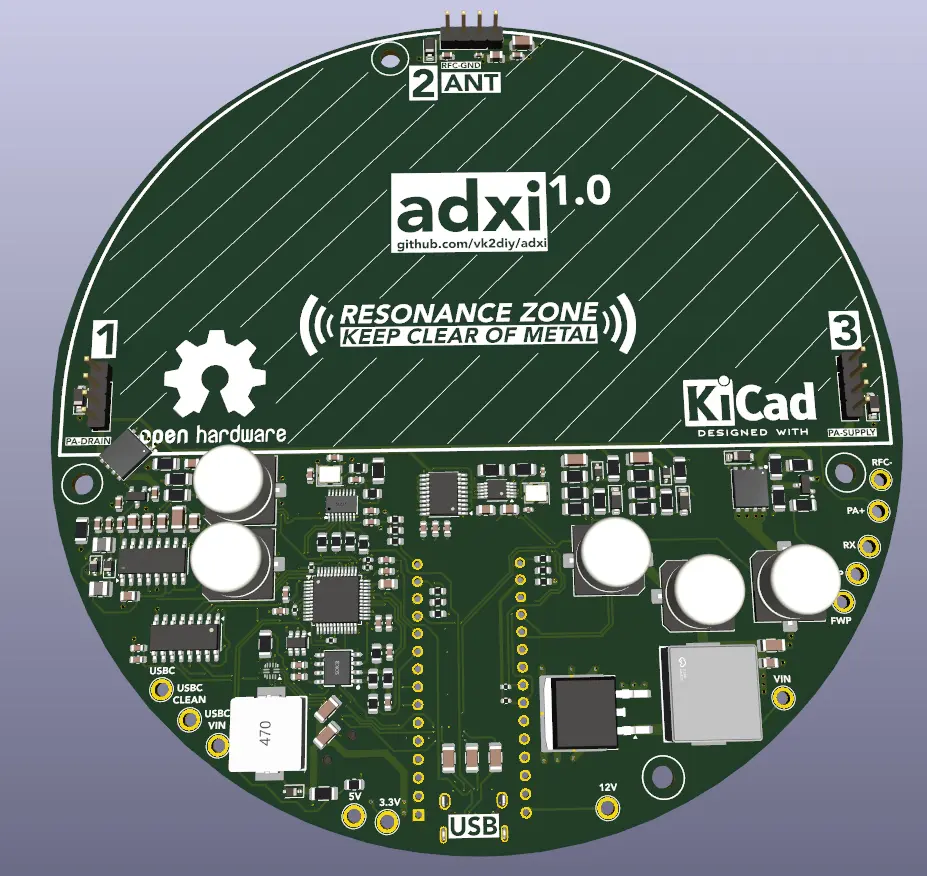
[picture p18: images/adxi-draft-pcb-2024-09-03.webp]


 * Add silkscreen graphics
 * Add four M3 mounting holes with screw head footprint indicator silkscreen
 * Improve certain footprints
 * Simplify power supply to USBC only
 * Complete layout and DRC. (Also [discover and report DRC bug in KiCad](https://gitlab.com/kicad/code/kicad/-/issues/18642).)

## Update (2024-09-02)

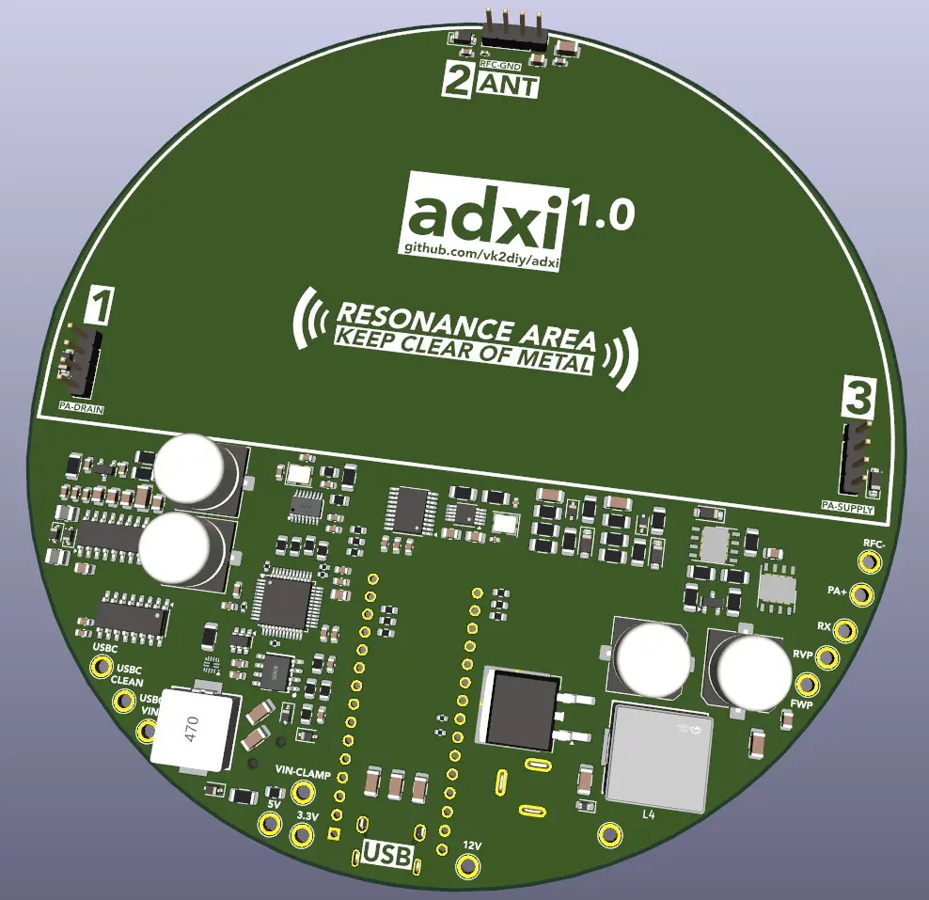
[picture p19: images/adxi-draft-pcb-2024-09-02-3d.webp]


 * Remodeled and improved [receiver chip](doc/receiver) [power filter](doc/filter-models/cd2003-supply-low-pass-filter).
 * Changed [stereo to mono audio summing to op-amp based](doc/audio-summing) (despite probable functional futility thereof since this is sourced locally) as theoretically this results in a cleaner output for an extremely nominal cost, and integrated the correct output bias line.
 * Found, reported and worked around [some](https://github.com/TousstNicolas/JLC2KiCad_lib/issues/77) [bugs](https://github.com/TousstNicolas/JLC2KiCad_lib/issues/76) in an [upstream library tool](https://github.com/TousstNicolas/JLC2KiCad_lib).
 * Executed most basic layout and verified all components fit in the allocated board space.

## Update (2024-09-01)

 * Specified the majority of schematic components still lacking footprints
 * Reconsider [receiver chip](doc/receiver) associated circuitry using a plethora of datasheets from chips in this family.
   * Learn more about the benefits of DC isolation for mixed AC/DC ICs.
   * [Model RF LPF](doc/filter-models/cd2003-rf-low-pass-filter).
   * Update peripheral circuitry to reduce cost and improve outcomes.

## Update (2024-08-29)

 * Detailed pin-wise documentation of MCU signals
 * Altered proposed PA schematic to show logical flow (top left to bottom right) with the proposed abstraction (*Sokal* flows "backwards" with respect to preferred schematic convention)
 * Completed crystal selection and load capacitance calculation for timer circuit (25MHz@12pF, 2x18pF)
 * Investigated frequency-specific questions regarding the MCU PA drive PWM line pullup, in particular to support 70cm frequencies, concluding no pullup is best (rely on MCU to set state, conserve power when operating in lower frequency bands, one less component)
 * Updated `TUSB321` power delivery chipset interface to remove mode-irrelevant pins and configuration.
 * Updated forward power, reverse power and standing-wave ratio (SWR) sensing schematic to provide better matching of voltage divider output to MCU ADC input range
 * Revised schematic for legibility, removed certain spurious elements
 * Reviewed original firmware

## Update (2024-08-28)

 * Completed audio summing for USB audio chip output
 * Wrapped frequency-response significant portions of the power amplifier (PA), the low pass filter (LPF) and antenna (ANT) interface in to a single unified prototype physical interface
   * Began to compare proposed component count board space with potential physical designs
   * An early stage prototype is shown in 3D and schematic views, based upon 3x2.54mm pin headers
   * Began to write this up as [doc/late-stage-interface](doc/late-stage-interface)

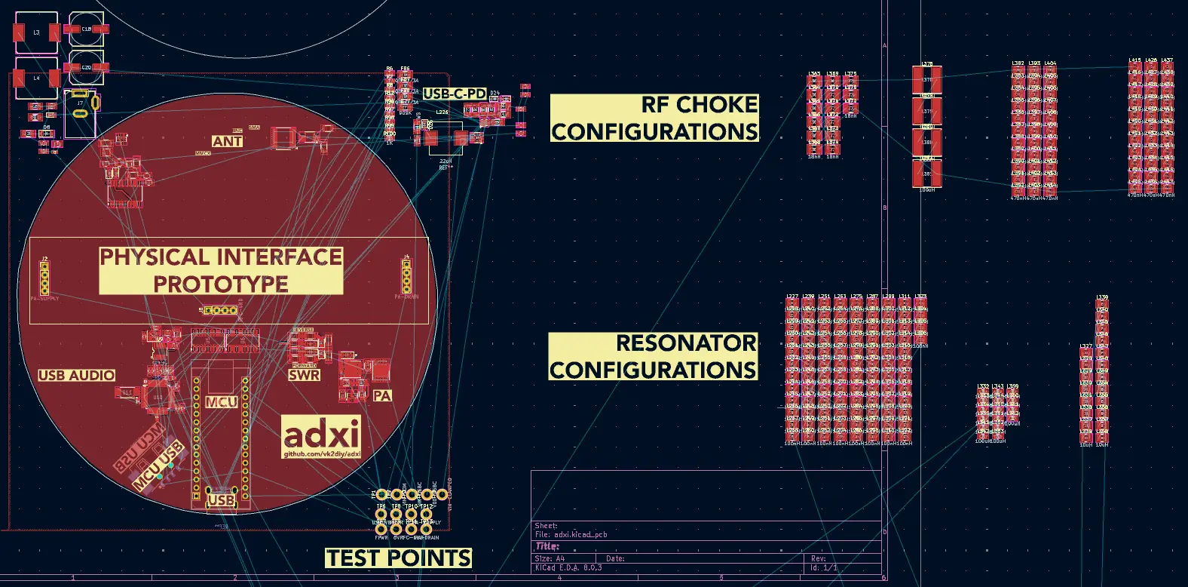
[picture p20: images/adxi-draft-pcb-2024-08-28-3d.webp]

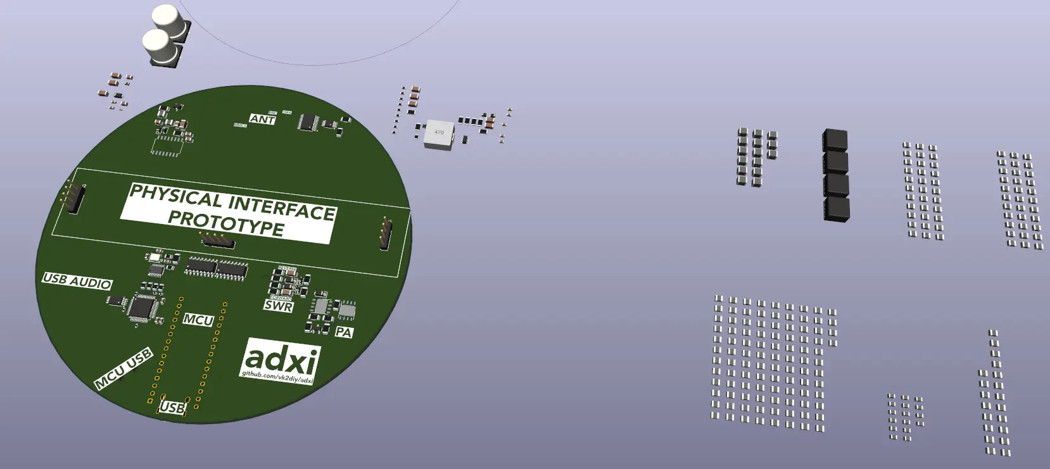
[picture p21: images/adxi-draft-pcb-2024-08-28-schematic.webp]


## Update (2024-08-27)

 * __Substantial amount of additional schematic work and documentation__
   * [USB hub](doc/usb-hub)
   * [Power supply](doc/power-supply)
   * [SPI level conversion](doc/spi-level-conversion)
   * Added many test points
 * More component footprints and models
 * Finished off some missing parts in earlier areas of the schematic
 * Readying to refocus on the new joint PA/LPF module mechanical and electrical interface design, after which layout should be straightforward

## Update (2024-08-24)

 * Power supply path further implemented
 * USB-C unified port for all purposes largely implemented including power delivery
 * USB hub configured
 * USB audio configured
 * New parts and footprints created
 * Minor amount of layout work

## Update (2024-08-22)

 * __New power supply mostly implemented__ with dual inputs, either USB-C PD or ~12-36V DC IN
   * Precise nature of fallback for USB-C power chain yet to be determined re. 1.5A negotiation failure
 * __Plan is now to onboard both the digital audio interface and a USB hub__ in order to facilitate the use of a __single USB-C cable to the host__ replacing six elements:
   * Batteries and a charge controller for mobile operation
   * DC-IN for fixed operation
   * Audio in
   * Audio out
   * Either an onboard module or external sound card for audio interfacing
   * Programming cable
 * It will be necessary to draw the schematics for these.

## Update (2024-08-21)

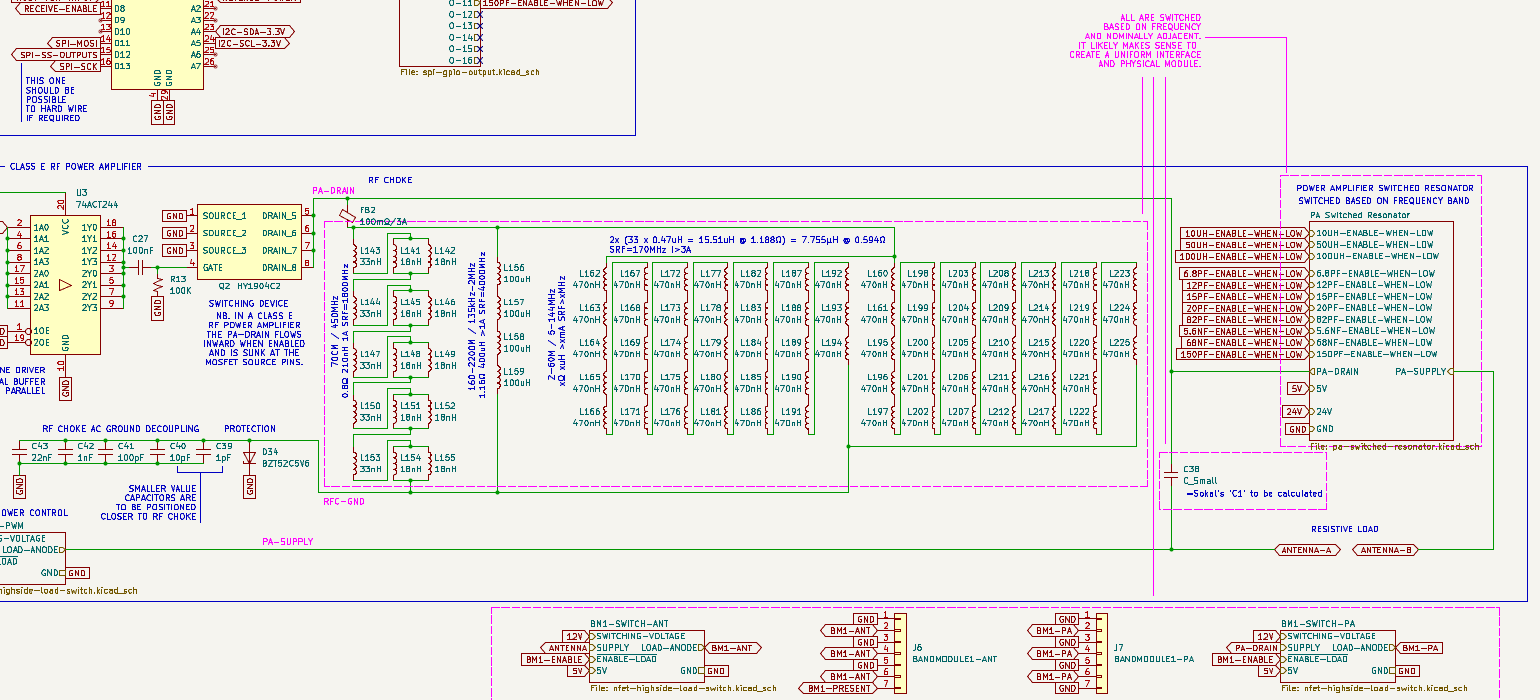
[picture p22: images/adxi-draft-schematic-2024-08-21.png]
 * Early stage band module schematic proposal. 
   * The primary difference to the prior ADX design is that the physical module will include portions of the power amplifier (RF choke, Sokals' `C1`, resonator) in addition to the low pass filter (LPF).
   * This is thought to make sense because:
     1.  All of these elements were found to require adjustment when considering the revised design's wide aggregate proposed band capabilities; and
     2. "Getting it right first time" may not be either (a) rational expectation; or (b) therefore a cost-effective development trajectory.
   * In other words:
     * I don't trust myself enough to commit to a PCB run where these aspects cannot be further tuned.
     * By putting in the thinking up front to reduce my own development cost, it should also make the process of extending or tweaking the design further by others much easier.
   * Outstanding questions:
     * Since the modular portion includes all of the last stages of the transceiver, it would thus logically include the antenna connection
     * Since the antenna connection is something that people may want in various formats to suit various wavelengths and usage scenarios (IPEX, BNC, SMA) and some of those physical interfaces are not designed for longevity, and the "tiffin" approach will facilitate both vertical layering and improved EMI, it might make sense to zoom out to consider whether or not the antenna should be part of that module or signals should be routed back to the main board before connecting to the antenna.
       * Layering up makes sense because an antenna connection on top of the system would be a logical position, batteries are heavy and could fit below, and minimizing the overall inter-module routing of RF signals would be desirable.
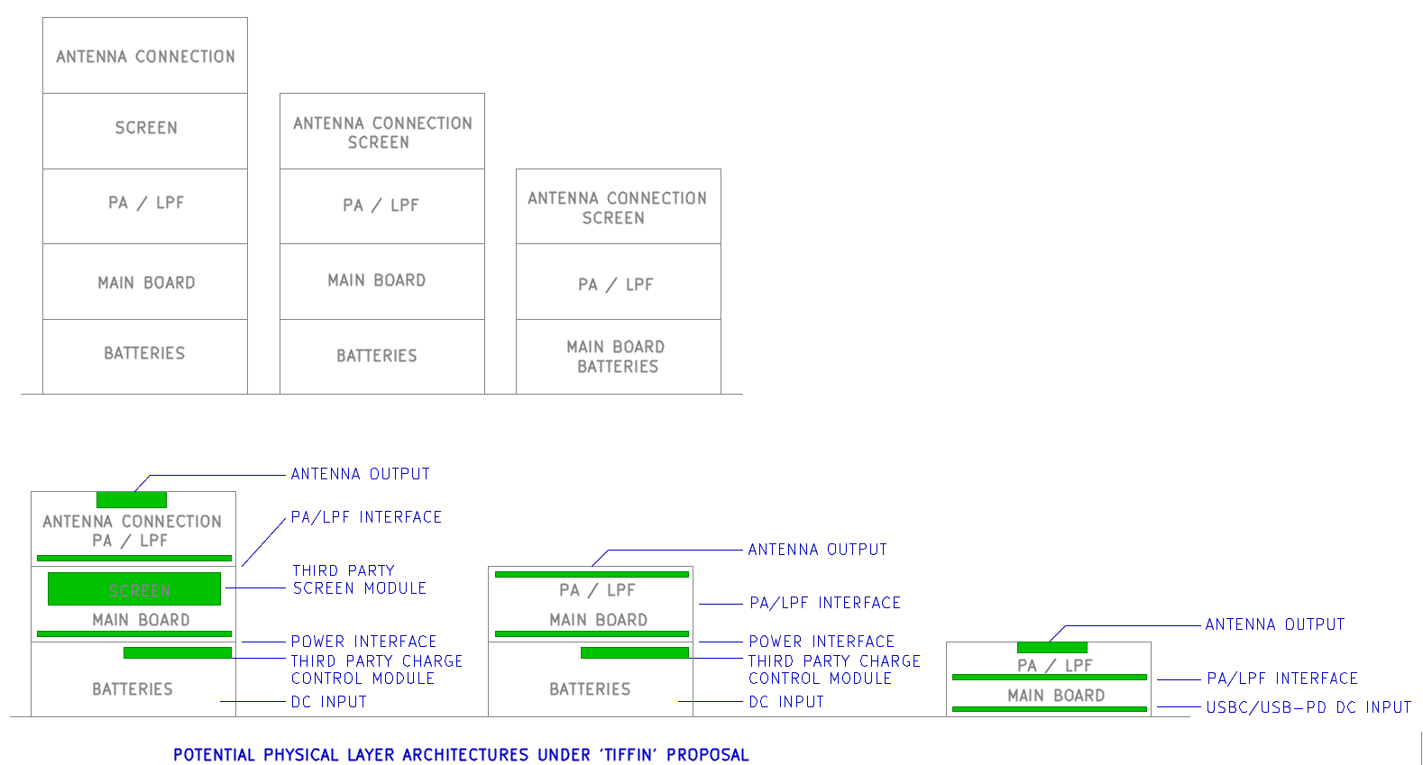
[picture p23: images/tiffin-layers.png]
       * Routing back makes sense because fewer modules are required and the specific modules would presumably work out cheaper. 
 * Design conclusions:
   * Don't bother with a screen, instead rely on the computer to provide status information.
   * Don't bother with a battery or charge controller, instead rely on an external USB power bank when mobile.
     * For the purposes of easier mobility and the fact that many laptops or embedded systems cannot supply anything near 1A on their USB ports it may be useful to obtain 5V nominal supply from one port and data from another port, ie. have two USB ports, one for MCU interfacing and one for power delivery.
     * For the purposes of maximum transmit power draw (~1A @ 5V) versus many USB supply limits (~900mA) and safety buffering, it may be useful to add a supercapacitor to the main board.
       * This could also allow switching between power sources without loss of operating state and configuration
     * Given that we are sailing so close to maximum draw it seems a tested solution would be desirable. A shortlist of potential integrated solutions includes:
       * TI TUSB312 - [Chinese](https://wmsc.lcsc.com/wmsc/upload/file/pdf/v2/lcsc/1809072322_Texas-Instruments-TUSB321RWBR_C139392.pdf), [English](https://www.ti.com/lit/ds/symlink/tusb321.pdf) @ $0.34
       * ST STUSB4500QTR - [English](https://wmsc.lcsc.com/wmsc/upload/file/pdf/v2/lcsc/2106070703_STMicroelectronics-STUSB4500QTR_C2678061.pdf) @ $1.29
       * ONSemi FUSB302 - [English](https://wmsc.lcsc.com/wmsc/upload/file/pdf/v2/lcsc/2304140030_onsemi-Fusb302mpx_C442699.pdf) @ $0.71
       * Cypress CYPD3177 - [English](https://wmsc.lcsc.com/wmsc/upload/file/pdf/v2/lcsc/2208051100_Infineon-Cypress-Semicon-CYPD3177-24LQXQ_C2959321.pdf) @ $0.81
     * Given that the TI chip is so much cheaper but they will all probably do the job I think it's worth moving forward with TI.
   * With increasing density comes decreased isolation and increased potential for electromagnetic coupling which is a double-edged sword.
 * Other developments:
   * Considering placing USB audio bridge, USB hub and port for MCU connection on board
     * This would allow programming and operation through a single port - no audio cables required
     * The only conceivable downside is, in a mobile scenario, USB power delivery capabilities of some host devices are limited
       * People can solve this themselves by using USB battery packs with built-in powered USB hubs
   * At this point, it sort of seems ridiculous to keep using the MCU as a module, but it is a pleasant eccentricity to preserve this design element and hard to match on price
     * Future versions could be released with newer MCUs, possibly mounted via adapter boards

## Update (2024-08-19)

 * Issues largely resolved with the PA choke.
   * Operating range was divided in to 3 band-groups (similar to resonator) and 2/3 completed with switching work yet to be done.
 * It seems that to obtain good values for `C1` (Sokal) it will be [necessary to recompute those at each end of the operating band for each resonator and choke selection](https://people.physics.anu.edu.au/~dxt103/calculators/class-e.php), and also to switch those when either PA or resonator change. If these figures work out, however, then confidence in the design should grow.
 * The fact that the Class E PA's RF choke, resonator, C1, and band-specific LPFs all require switching means it is probably best to redesign the group of adjacent passives as a single physical interface and module to support easier and more cost-effective experimental iteration.
 * This means the previous modularity scheme (ie. one of pluggable band-specific LPFs inspired by previous projects) is probably going to evolve to a higher component count, higher flexibility approach incorporating all of these functional blocks.

## Update (2024-08-18)

 * MCU output expansion added to drive switched PA resonator inductance and capcitance to achieve full band range
 * [Having issues](doc/class-e-pa/) identifying a sane strategy for an RF choke capable of the 70cm (450MHz) required
   * To this end, attempted to make at fabricating a coil for main RF choke but failed
   * Still keen to obtain an SMT solution

## Update (2024-08-15)

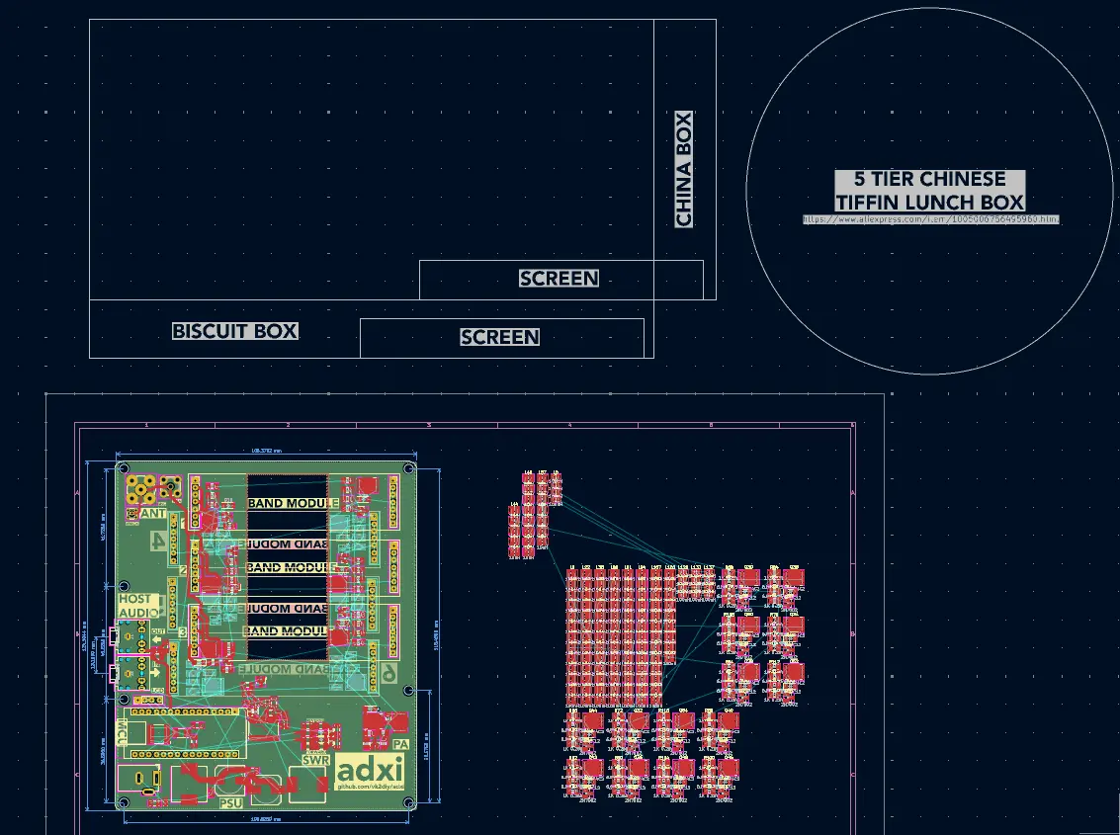
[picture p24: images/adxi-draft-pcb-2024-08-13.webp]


 * [Further work on power amplifier theory and component selection](doc/class-e-pa/)
   * We now have theoretically adequate SRF on inductor arrays for all bands
 * RF choke still needs a high SRF all-band solution but nominal values of near 220uF and an associated capacitor array have been chosen
 * Tiffin system added to potential footprint drawings

## Updated (2024-08-13)

Recent work:
 * More work on power amplifier
   * Three-mode RF choke inductor mostly completed (one tier to be re-specified)
   * Switchable capacitance calculated and to be added
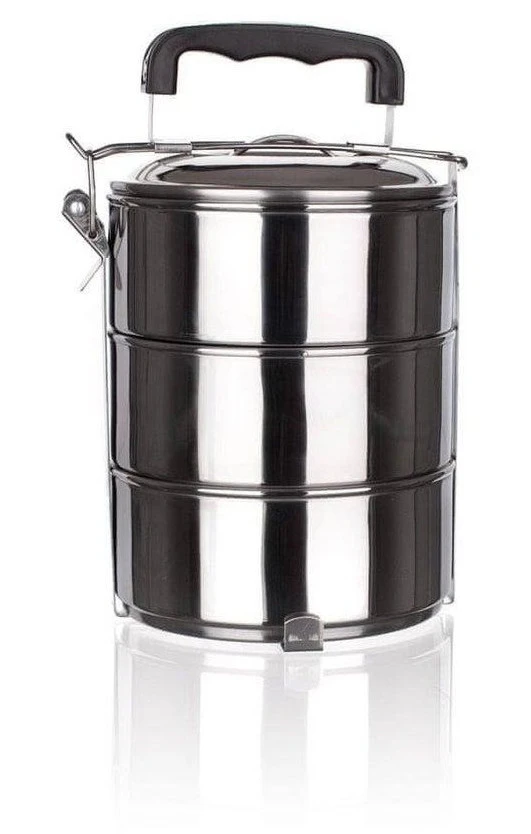
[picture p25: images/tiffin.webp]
 * Input of general dimensions of two boxes which have been selected as possible form factors. Have another idea to use this sort of thing as a modular approach: 
 * General cleanup of schematic

## Updated draft PCB (2024-08-10)

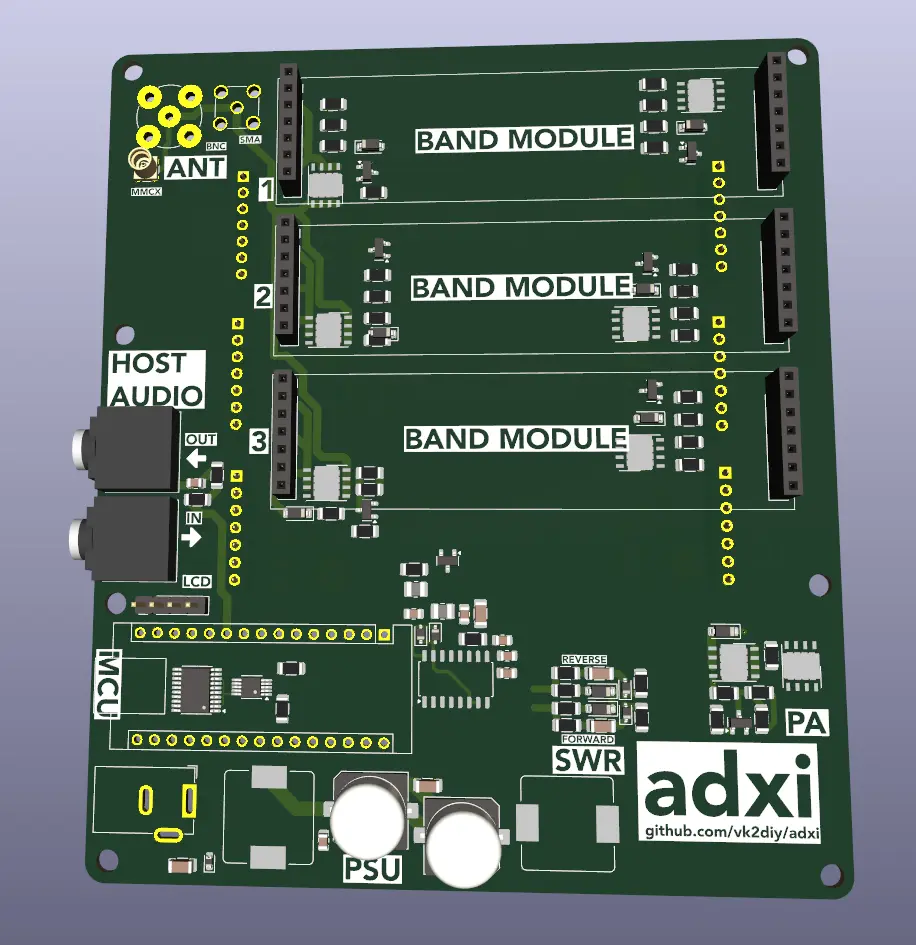
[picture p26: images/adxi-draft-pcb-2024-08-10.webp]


 * Further consideration of overall layout, switching placement.
 * It seems there will need to be a series-parallel array of RF choke inductors to cover the broad target frequency range.
   * This is not necessarily expensive, just complex.
   * There will also be at least one switchable inductor in the main RF choke.
 * Other additions:
   * I2C LCD pin header
   * Further antenna connector (MMCX)

## Updated draft PCB (2024-08-09)

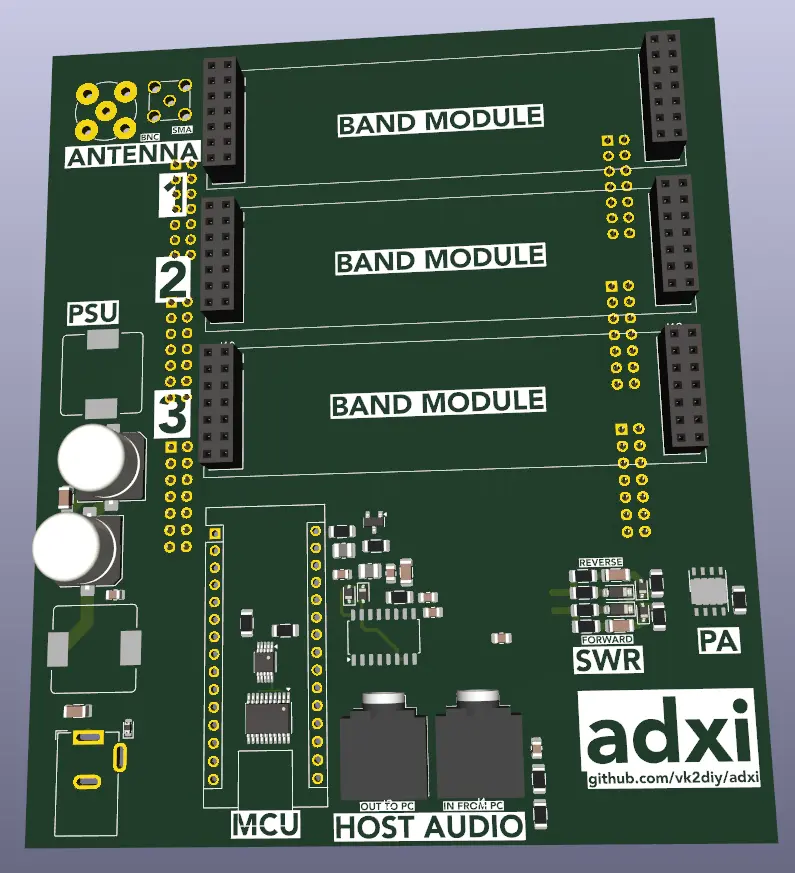
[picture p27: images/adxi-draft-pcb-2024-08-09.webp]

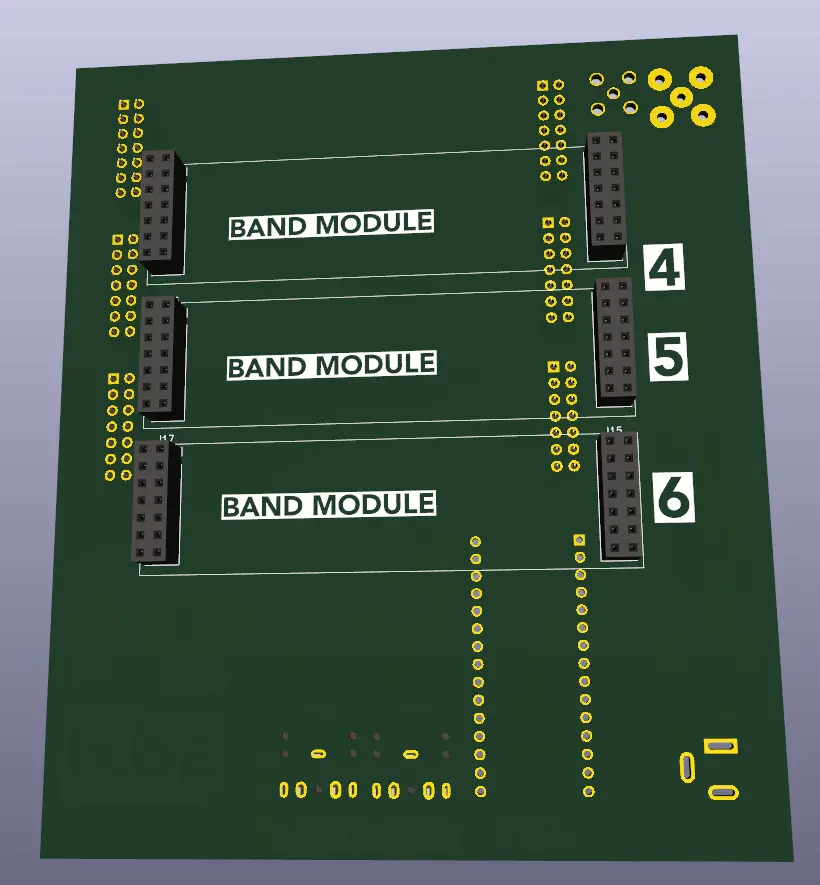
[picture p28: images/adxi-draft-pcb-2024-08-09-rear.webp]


This version adopts a band-module approach in order to reduce iteration cost.

The basic notion is that a 7x3cm module can be plugged in to provide band-specific low pass filtering.

There is space on the front of the PCB for three of these modules, and on the rear of the board another three modules. Modules are staggered to minimize the effects of electromagnetic coupling between modules and their terminals. Sockets are used on the board and pins on the filter modules in order to reduce the volume of metal present when less filters are connected.

## Initial draft PCB (2024-08-07)

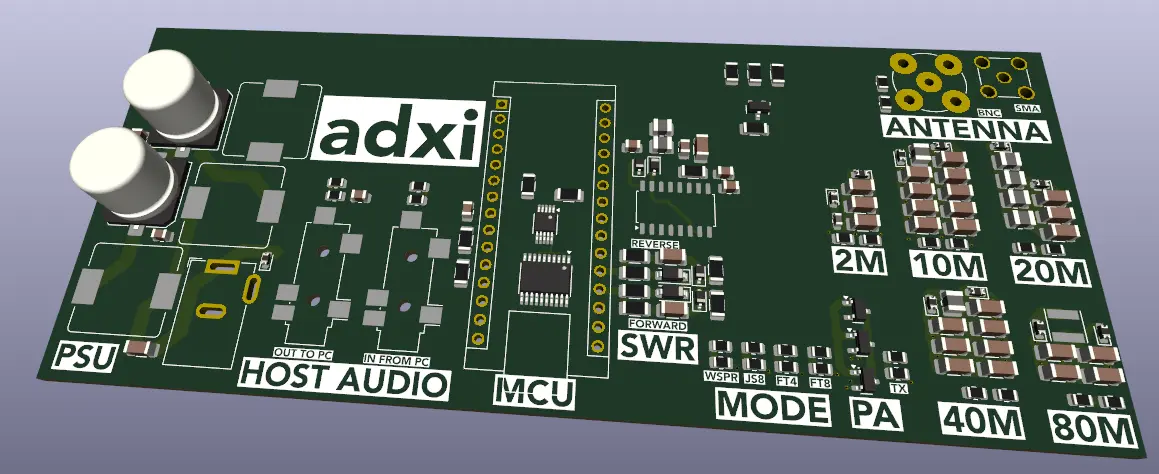
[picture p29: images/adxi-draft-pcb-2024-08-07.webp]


 * Draft now changed, potentially to have pluggable LPFs instead of a monolithic all-band-onboard architecture
   * This requires the design of an interface for the same
 * Filter switching added

## Current documentation
 * Filters
   * [Bandpass filter model](doc/filter-models/bandpass-filter/) showing audio frequency bandpass filter
   * [CD2003 5V supply filter model](doc/filter-models/cd2003-supply-low-pass-filter/) showing power supply filtering for the radio receiver chipset
   * [DC blocking filter](doc/filter-models/dc-blocking-filter/) showing how capacitors block DC and their nominal frequency relationship
 * Schematic design notes
   * [Multi-band low pass filters](doc/multi-band-lpfs) showing various third party designs for multi-band LPFs and including notes considering practical aspects of the design problem.
   * [SWR and power metering](doc/swr-and-power-metering) discussing the planned approach to obtaining this information simply
 * Wireless protocols
   * *[The FT4 and FT8 Communication Protocols](doc/wireless-protocols/FT4_FT8_QEX.pdf)*

## ADX Original Project

### Features

 * ADX is a mono band (actually quad band) digital modes optimized HF transceiver that can cover four pre-programmed bands one band at a time by swapping Band LPF Modules.
   * It can work on 80m, 40m, 30m, 20m, 17m, 15m and 10m bands
   * It can operate on four of the most popular digital modes, FT8, FT4, JS8call and WSPR.
 * ADX supports computer control (CAT) by emulating KENWOOD TS2000 HF Transceiver over a 9600 8N1 serial link to control Band and Mode changes.

### Goals

The project was originally designed by [Barb (WB2CBA)](https://github.com/WB2CBA/ADX) ([original project website](https://antrak.org.tr/blog/adx-arduino-digital-transceiver/))  with the goal to design a simple HF Transceiver optimized for operating on Digital modes:
 - Simple to procure – meaning not effected by chip shortage
 - Simple to build – 2 modules, 2 IC’s and 4 Mosfets!
 - Simple to setup and tune – One simple calibration procedure is all needed.
 - Simple to operate – Plug in ADX MIC to soundcard MIC input and ADX SPK to PC soundcard speaker input and we are good to go with any digital modes Software.
 - Dirt Cheap – Costs less than 25$ to get all parts and PCB if we exclude ridiculous shipping costs!
 - Plug in a USB cable between ADX Arduino and your PC, Select Kenwood TS2000 with 9600bps,8,1 setup as your CAT rig and you will have CAT control on ADX!

It has since been built all over the world.

### Design

The original design was based on the following major physical modules:
 * Main ADX PCB
   * CD2003 radio chip
   * 74ACT244 buffer/line driver
 * Arduino Nano (ATmega328P MCU module)
 * Si535x clock generator module
 * uSDX LPF band module
 * External PC microphone interface (for sending received signals to the computer)
 * External PC speaker interface (for receiving encoded signals from the computer)

## Building the firmware

Firmware is managed through [platformio](https://github.com/platformio/platformio-core).

Rationale:
 - While excellent in its simplicity, Arduino IDE is generally inappropriate for long lived projects.
   - Why?
     - It has brittle dependency management
     - It relies on non-scriptable GUI actions.
     - It lacks modern features like unit testing, CI/CD, etc.

Result:
 - You will need to install either [platformio-core](https://github.com/platformio/platformio-core) (command line) or [platformio IDE](https://platformio.org/platformio-ide).

Benefits:
 - Notes about specific versions of specific libraries and compatibility are now a thing of the past.
 - The addition of future libraries, compilers, or tools is easy
 - Users become familiar with more modern, cross platform and professional grade approach to firmware development and management while working on personal projects

### Under platform-io core (command line)

Simply change to the source code directory and type `pio run`.

```
$ cd firmware
$ pio run
```

### Under platformio IDE

Open the project in the IDE then use the buttons provided.

## History

### 2024-08-07
 - First 'mostly there' release of Kicad v8 schematic and board design

### 2024-08-03

 - Forked, general cleanup and migrated to [platformio](https://github.com/platformio/platformio-core).
   - Previously Arduino IDE builds were the norm
   - Apparently the files had apparently not been opened since KiCad v4 ... KiCad is now at v8.0.4
 - Outstanding issues
   - KiCad has altered its library management so much that the old files will not import directly to v8.0.4
   - KiCad has improved its internal libraries so that external libraries for many parts are no longer required
   - KiCad has integrated the historic DigiKey library
   - The schematic is missing known PCB fixes not integrated but documented by the original author
   - The schematic uses a non-standard symbol for the MCU which is unhelpful
   - The schematic has a number of further errors making it suboptimal for introducing new students
   - The layout used a type of fill which is no longer supported by modern KiCad
   - The layout can probably be improved
 - Conclusion
   - Given the simple nature of the schematic it is better at this point to redraw the schematic and redo the layout, removing all previous KiCad 4 era files

### 2023-07-14

- Release band display bug fixes by Peter Petrov (LA7WRA) and Mark Culross (KD5RXT).

### 2023-06-10

- Cowtown Amateur Radio Club ADX Buildathon Construction Manual v1.5 by Richard Hinsley (W5ARH/VK2ARH)

### 2023-04-08

- SI5351 module pull up resistor fix added to build manual v1.4 by Richard Hinsley (W5ARH/VK2ARH)

### 2022-12-20

- Calibration procedure changed to protect EEPROM from R/W wear.
- Add zener diode PA mosfet protection from excessive SWR conditions.

## Contributors

### adxi project

 * VK2DIY

### ADX Project

 * [Barb (WB2CBA)](https://github.com/WB2CBA/ADX): Project conception and original design.
 * [Richard Hinsley (W5ARH/VK2ARH)](https://www.qrz.com/db/W5ARH): Buildathons, outreach and build documentation.
 * [Joerg Frede (DK3JF)](https://www.qrz.com/db/DK3JF): CAT and other software contributions.
 * [Peter Petrov (LA7WRA)](https://www.qrz.com/db/LA7WRA) and [Mark Culross (KD5RXT)](https://www.qrz.com/db/KD5RXT): Band display bug corrections.
 * [Burkhard Kainka (DK7JD)](http://elektronik-labor.de/): Initial FSK TX signal generation code - http://elektronik-labor.de/HF/SDRtxFSK2.html
 * [Jason Mildrum (NT7S)](https://www.qrz.com/db/NT7S): SI5351 Library - https://github.com/etherkit/Si5351Arduino
 * [Lajos Höss (HA8HL)](https://www.qrz.com/db/HA8HL): Inspiration for CAT code based on his TS2000 CAT implementation.
 * [JE1RAV](https://www.qrz.com/db/JE1RAV): Improved FSK TX signal generation code - https://github.com/je1rav/QP-7C

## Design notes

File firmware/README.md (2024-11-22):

# Firmware directory

Firmware may be compiled using [platformio](https://piolabs.com/), which provides a vendor-neutral command line environment for embedded development supporting modern features such as continous integration, unit testing and operating system independence.

## Installing platformio

See [What is PlatformIO?](https://docs.platformio.org/en/latest/what-is-platformio.html?utm_source=github&utm_medium=core) and then either [PlatformIO IDE](https://docs.platformio.org/en/latest/integration/ide/pioide.html) or [PlatformIO CLI](https://docs.platformio.org/en/latest/core/index.html).

## Using platformio

### Python venv

You may need a python virtual environment to run. This cross-platform mechanism provides a way for different python environments to be manage on one system.

In order to create a python virtual environment, run `python venv init`.

In order to enter a pre-existing python virtual environment, change to the correct directory at the top of the tree and run `. ./bin/activate`.

In this environment, all python commands (including `pio` for platform IO) will use the virtual python environment and its packages.

When you are done, type `exit` to return to the normal system shell.

### General use

To compile simply type `pio run`.

For other commands, see [CLI command list](https://docs.platformio.org/en/latest/core/userguide/index.html#piocore-userguide).

For example:

 * `pio project config --lint` will verify project configuration.
 * `pio package install` will install missing dependencies.
 * `pio pkg update` will update dependencies.
 * `pio check` will run a static code analysis.
 * `pio run` will build the project.
 * `pio run -t upload` will upload the project to the device.
 * `pio test -h` will show testing related commands.

## Firmware architecture

Similar to other Arduino-inspired firmware, the general architecture of the firmware is as follows.

 * The firmware sets up the various pins of the microcontroller in its `setup()` routine.
 * The firmware then iterates repeatedly through a `loop()` routine.

The loop routine varies in its function depending upon operating mode and input, for example:
 * It may receive and send information from and to the host computer via USB serial interface.
   * The physical chip in use for serial UART interface on most Arduino Nano MCU modules is the CH341. In the past this needed drivers for various systems and did not work well on many Macs. It works well on Linux. If you are using Windows or similar, you may need to find a driver.
   * The protocol used for this purpose is an emulated subset of the Kenwood TS-2000 protocol, as [implemented](https://github.com/Hamlib/Hamlib/blob/master/rigs/kenwood/ts2000.c) in the [hamlib](https://github.com/Hamlib/Hamlib/) library which drives the [WSJT](https://wsjt.sourceforge.io/) software. The protocol is documented on pages 114-141 of the [Kenwood TW-2000 owner manual](https://erikarn.github.io/kenwood/TS-2000/TS-2000-Owner-Manual.PDF) ([wayback machine archive](https://web.archive.org/web/20240713202306/https://erikarn.github.io/kenwood/TS-2000/TS-2000-Owner-Manual.PDF), [archive.today archive](https://archive.is/gLoBM)).
   * It may reconfigure, enable or disable the radio and audio subsystems for disparate frequencies and output power levels.
   * It may obtain forward power or reverse power readings.
   * It may calculate standing wave ratio (SWR) readings from forward and reverse power readings.

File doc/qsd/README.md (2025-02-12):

# Quadrature Sampling Detection

Quadrature sampling detection (aka 'quadrature detection' or 'quadrature detector') circuits are used in signal processing to extract in-phase (`I`) and quadrature (`Q`) components from an input signal.

```

input signal ---> QSD ---> in-phase component (I) ------> further processing ---> output
                   |                                       ^
                   `-----> quadrature component (Q) -------'
```

## Types of QSD

There are several types of quadrature sampling detection circuits, each with its own advantages and implementation methods:

### Analog Quadrature Detector

This traditional method uses analog circuits to perform quadrature detection:

 * It multiplies the incoming signal with two local oscillators that are 90 degrees out of phase.
 * The resulting `I` and `Q` signals are then low-pass filtered to remove high-frequency components.
 * Advantages: Can handle high-frequency signals.
 * Disadvantages: Requires precise analog components and may suffer from imbalances.

### Digital Quadrature Detector

Modern transceivers often implement quadrature detection digitally:

 * The incoming analog signal is first converted to digital form using an analog-to-digital converter (ADC).
 * Digital multiplication and filtering are then used to extract `I` and `Q` components.
 * Advantages: More flexible, can be easily reconfigured in software.
 * Disadvantages: May be limited by ADC sampling rate for very high-frequency signals.

### Tayloe Quadrature Detector

This is a unique type of quadrature sampling detector:

 * It uses a switching mechanism to sample the input signal at four points, 90 degrees apart.
 * The sampled values are integrated using capacitors to produce `I` and `Q` outputs.
 * Advantages:
   * Near unity gain (much better than a diode mixer/detector, which will be worse than –6dB. QSD uses near peak detection instead of RMS and there is not a sum product which otherwise is thrown away and wasted)
   * Large dynamic range (primarily a function of operating voltage of the analog switches)
   * Simple design (no tuned circuits, agnostic to RF below the maximum switching rate of the analog switch input, easily adjusted, 
   * Built in front end selectivity (eg. if input = 10Mhz and filter knee = 1KHz (need to double this for the calculation), then front end selectivity `Q` = 10Mhz/2KHz = 5000)
 * Disadvantages:
   * Performance may degrade at very high frequencies.
   * Needs to be driven by a Local Oscillator (LO) at 4X the desired reception frequency. For example, to listen to a 10MHz station you need to generate 40MHz and divide into 4 (90 degree phased) clock signals).
   * Needs to be driven by a square wave – which introduces harmonic detecting and spurious signals. Front end selectivity will mitigate this.
   * The gain, bandwidth and noise of the detector are very sensitive to antenna impedance matching. Requires a well-defined RF input impedance for best performance.
   * AM leakage can be present, although it is much better than traditional product detectors (worse with huge resonant antennas)
   * Makes a beat note, so AM detection requires careful tuning with a really stable oscillator or requires tuning above 20KHz, band pass filtering, and summing to full wave rectified output (absolute value circuit) to create AM detection. Alternatively, you can A/D convert and use DSP signal processing.

At first glance, this circuit appears to be to be a switching mixer used as a product detector. This is not quite accurate. It really is a sampling detector which generates a difference beat(when LO is slightly out of tune with the incoming signal), but not a sum product. The very basic idea is to switch on and off  a RF input into an audio range low pass RC filter and detect (integrate) the difference beat frequency or modulation envelope, when exactly at zero beat. A simple diode detector is analagous to some degree – the difference is; it self switches so it is always perfectly synchronized to zero beat. Also, a diode only switches on for a portion of  a half cycle, hence there are losses.

The fact this is a detector (not a mixer) and that it is quadrature sampling leads to two very important benefits. One, I and Q signals are easily obtained. This allows sideband rejection via an analog all pass filter or DSP processing. Second, it provides near unity gain (since you have no sum product, you do not lose half of your energy in detection, aswell, you detect at 90% of peak not RMS).

References:
 * [this site](https://circuitsalad.com/2013/12/30/my-phasing-receiver-is-a-success/)

### Second Order Quadrature Detector

This method is particularly useful for narrowband signals:

 * It samples the input signal at a rate much lower than the carrier frequency.
 * In-phase samples are taken at intervals of `l/(2f0)`, where `f0` is the carrier frequency and `l` is an integer.
 * Quadrature samples are taken after a delay of `1/(4f0)` relative to the in-phase samples.
 * Advantages: Allows for a much lower sampling rate compared to the carrier frequency.
 * Disadvantages: May introduce some approximation errors for wider bandwidth signals.

### Interleaved Quadrature Detector

This method is optimized for efficient digitization:

 * It uses interleaved in-phase and quadrature clock pulses at twice the carrier frequency (or a subharmonic).
 * The interleaved clock is used as an external clock for digitization of the phase-modulated carrier.
 * Advantages: Requires sampling at only twice the information bandwidth rather than twice the carrier frequency.
 * Disadvantages: Requires precise timing control for the interleaved clock signals.

Each of these quadrature sampling detection methods has its own strengths and is suited for different applications depending on factors such as signal bandwidth, carrier frequency, and required precision.

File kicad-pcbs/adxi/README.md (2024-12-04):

# adxi

## Timeline

 * Conceived: 2024-08-03
 * Designed: 2024-08-03 - 2024-10-10ish
 * Ordered: 2024-10-24
   * Cost: $41.40 for 10 boards + $154.20 for 10 pieces SMT = $195.60 for 10 pieces / 10 = $19.56 each (ex shipping)
   * Note that the ordering was delayed for 2 weeks or something owing to the late stage module design needing revision and wanting to share shipping costs, and this required updates to the [classe2-calculator](https://github.com/vk2diy/classe2-calculator) software.
 * ETA: 2024-11-06 
 * Received: 2024-11-04 (~midday) - total time since ordering ~10-11 days
 * Testing:
   * 2024-11-04: Blew up two boards, discovered USB power issue.
   * 2024-11-05: USB hub, audio and MCU passthru verified with bypass supply. Restored lab to functionality. Worked on a fix, ordered parts.
   * 2024-11-06: Parts received. Testing done manually powering the `TUSB321` chipset and negotiation appears to occur. This suggests a fixable situation. The boost converter still needs debugging.
   * 2024-11-07: Boost converter block instrumentation and testing.
   * 2024-11-08: Plan for potential power stage resolution patch board, scheme for early stage power and failover, benchtop regulator testing.
   * 2024-11-09: Irregular 'regulator free' early stage power solution, new board setup, prepare for firmware programming.
   * 2024-11-24: Test clock generator.

## Initial test

 * Visual inspection
   * No obvious defects
   * The silkscreen now appears to be printed with an inkjet and is much less clear than previous eras
 * Multimeter inspection
   * The GND net appears to be consistent across the board
   * None of the power nets short to GND
 * Assembly test
   * Hard to get the cable through the hole.
   * While easy to thread (dimensions are fine) I failed to account for the solid plug being in the way of the cable
 * Fiddly to tighten nylon nuts around standoffs

## Initial soldering

 * Found pins for MCU not easy to solder, maybe soldermask problem
 * Put one in backwards (oops!)
   * Result: First destroyed board. Nine remain.

## Issue #1: USB-C Power Distribution
 * Next board tried connecting USB-C to a powered USB2 hub just to probe board power
 * See some power on USBC = 0.xV and USBC CLEAN = 0.xV but nothing elsewhere, have to trace back using schematic.
 * Soldered some test leads on to the related test points
 * Configured oscilloscope to view these channels:
   * The scope shows 300mV for CH2 = USBC CLEAN and 500mV for CH1 = USBC
 * Both boards show this issue, which suggests a probable design problem
 * Test results for all three cases (backwards MCU on otherwise new board, no MCU on new board, correct orientation MCU on new board):
   * Test point '5V' = 0V
   * Test point 'USBC' = 500mV
   * Test point 'USBC CLEAN' = 300mV
   * Net 'USB-C-VBUS' = 5V
 * __Conclusion__
   * Design, configuration or placement problem regarding `TUSB321` chipset.
   * Chip is too small to probe directly. but pins are as follows:
     * CC1 = bidirectional USB PD channel
     * CC2 = bidirectional USB PD channel
     * ...
   * __Hypothesis__
     * I misunderstood the datasheet.
       * Instead of the chip relaying the power, which is obtained through the CC channels, it in fact requires a separate supply, which it was not given (and I was treating as an output).
       * Therefore, no power was being relayed to the rest of the board.
       * Additionally, the last page of the datasheet specifies that a 100nF bypass should be present at the VDD pin.
     * The good news is this should be possible to fix without a board revision by bringing VDD power from the 5V verified as present on the `USB-C-VBUS` net, after the ferrite bead.

 * __Attempted fix #1: Jumper cable__
   * Soldered a cable between the `USB-C-VBUS` output after the ferrite and the `USB-C-CLEAN` net (which connects to the `TUSB321` `VDD` pin.
   * __Hypothesis__
     * This should have taken 5V to the 5V clean output as input to the `TUSB321` boost converter, allowing it to negotiate more power.
   * __Result__
     * The `TUSB321` boost converter released magic smoke instantly.
     * Second destroyed board. Eight remain.
   * __Analysis__
     * IC orientation is visually verified as correct
     * Unsure why this occurred, in particular:
       * Given that 5V was measured
       * Given `TUSB321` is supposed to have thermal shutdown
       * Given `TUSB321` only has two inputs, the feedback pin and the main input pin, the latter receiving 5V only
       * Given that the feedback circuit had been modeled.
   * __Conclusion__
     * Design, configuration or placement issue within the `TUB321` circuit
   * __Potential next steps__
     * Use the first destroyed board where this section is intact to test the circuit more carefully using a bench supply and the oscilloscope.
       * This will rely on restoring the test equipment network which appears to be down right now.
       * Very short pulses of power or power with a current cutoff could be measured on the input, output and feedback pins to understand the behaviour without destroying the chip.
       * In the worst case, it should be possible to simply relegate this portion of the circuit to next edition and power the board through the 12V test point.
       * If it appears things are generally in order, then, to reduce inrush current, bulk capacitors could perhaps be disconnected.
     * Bypass the power stage with a direct supply

 * __Attempted bypass #1: Direct 12V supply__
   * Prepared an LXI network configurable power supply Rigol DP832 to connect to 12V test point and GND test point
     * Channel configuration is 12V with overvoltage protection enabled, and 0.05A with overcurrent protection enabled
   * A timed script will enable power for a short time so that the oscilloscope can capture the effect of the power on the other power rails (5V, 3.3V) which should come up.
     * The current limit will be iteratively increased slightly until bring-up succeeds.
     * If these come up, based on the MCU module's internal regulator, then we should be in business, and can move on to testing USB functionality.
     * We may also discover additional problems, although shorts have already been ruled out with multimeter-based continuity probing.
   * Before this test can proceed:
     * I had to debug some issues with my test network due to long period of disuse (network cable had been removed and replaced for another purpose)
     * I had to verify connectivity to the oscilloscope (for screenshot capability) and power supply (for control purposes)
     * It would be good to to first verify the script and control circuit with no load using the multimeter.
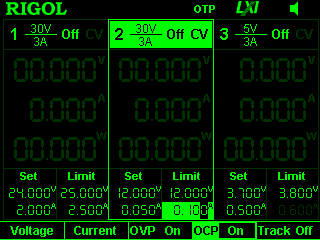
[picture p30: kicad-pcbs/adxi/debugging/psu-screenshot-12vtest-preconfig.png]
   * Configuration screenshot: 
   * Script output: 
```
Tue Nov  5 09:21:44 AM AEDT 2024
DP832 PSU
 - Status: OFF
 - Version: RIGOL TECHNOLOGIES,DP832,DP8C233203778,00.01.16
 - Self test: TopBoard:PASS,BottomBoard:PASS,Fan:PASS

Turning channels off... OK
Setting up channel #1
 - Voltage: 24.000V
 - Voltage limit: 24.000V
 - Voltage limiting: ON
 - Current: 0.500A
 - Current limit: 0.500A
 - Current limiting: ON
Setting up channel #2
 - Voltage: 12.000V
 - Voltage limit: 12.000V
 - Voltage limiting: ON
 - Current: 0.050A
 - Current limit: 0.050A
 - Current limiting: ON
Setting up channel #3
 - Voltage: 5.000V
 - Voltage limit: 5.000V
 - Voltage limiting: ON
 - Current: 0.500A
 - Current limiting: ON

Triggering channel 2 (12V) for test period
 - Enable
Saved screenshot_192.168.8.3_2024-11-05T09:21:44.png
 - Disable

Tue Nov  5 09:21:45 AM AEDT 2024
```

   * Analysis:
     * The screenshot showed no current consumption
     * Connections were therefore checked and an alligator clip was replaced with a soft solder tie-down to the test point
     * The script still ran without change, however re-enabling the channel manually resulted in an overcurrent alarm
     * The current was manually increased as follows: 0.1A, 0.2A
     * At 0.2A power-on occurs and the LED from the MCU can be seen, but this is not reliable.
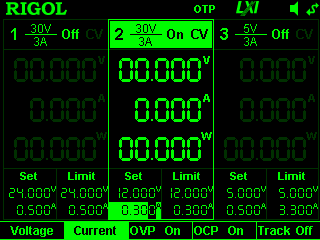
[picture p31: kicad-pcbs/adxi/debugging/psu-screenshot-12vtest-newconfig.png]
     * At 0.3A reliability is attained 

```
Tue Nov  5 09:37:42 AM AEDT 2024
DP832 PSU
 - Status: OFF
 - Version: RIGOL TECHNOLOGIES,DP832,DP8C233203778,00.01.16
 - Self test: TopBoard:PASS,BottomBoard:PASS,Fan:PASS

Turning channels off... OK
Setting up channel #1
 - Voltage: 24.000V
 - Voltage limit: 24.000V
 - Voltage limiting: ON
 - Current: 0.500A
 - Current limit: 0.500A
 - Current limiting: ON
Setting up channel #2
 - Voltage: 12.000V
 - Voltage limit: 12.000V
 - Voltage limiting: ON
 - Current: 0.300A
 - Current limit: 0.300A
 - Current limiting: ON
Setting up channel #3
 - Voltage: 5.000V
 - Voltage limit: 5.000V
 - Voltage limiting: ON
 - Current: 0.500A
 - Current limiting: ON

Triggering channel 2 (12V) for test period
 - Enable
Saved screenshot_192.168.8.3_2024-11-05T09:37:43.png
 - Disable

Tue Nov  5 09:37:44 AM AEDT 2024
```

   * Conclusion:
     * Board is at least partly functional with MCU power-on detected
     * Additional channels of 5V and 3.3V also come up as follows  

## USB testing

Now that we have power, it may be possible to test USB connectivity.

Firstly we should take care before plugging in the USB to ensure that the USB VBUS does not burn anything else. The jumper lead that allowed this to burn the boost converter has been removed and the initial state (some minor voltage seen through `TUSB321` `VDD` pin presumably bleeding through from `VBUS_DET` via the large resistor) should be replicated. Since this is insufficient to enable `TUSB321` we should see it remain idle, and the subsequent power stage which burned, namely the jumpered input to the boost converter `MT3608B`, has been removed. Subsequent diodes should prevent further issue.

So the plan is:
 * Plug in USBC
 * See whether anything burns or gets hot
 * If not, then proceed to apply power.
 * After applying power, see if the USB hub comes up, USB audio chipset comes up, or the passthru to the MCU for serial control and programming over the shared USB-C line works.

Here we go... success! `dmesg` output showed the following.

```
[131935.240875] usb 5-4.3: new high-speed USB device number 9 using xhci_hcd
[131935.354394] usb 5-4.3: New USB device found, idVendor=1a40, idProduct=0101,
bcdDevice= 1.00
[131935.354397] usb 5-4.3: New USB device strings: Mfr=0, Product=1, SerialNumbe
r=0
[131935.354399] usb 5-4.3: Product: USB2.0 HUB
[131935.364516] hub 5-4.3:1.0: USB hub found
[131935.364585] hub 5-4.3:1.0: 4 ports detected
[131935.747540] usb 5-4.3.2: new full-speed USB device number 10 using xhci_hcd
[131936.021358] usb 5-4.3.2: New USB device found, idVendor=1a86, idProduct=7523
, bcdDevice= 2.54
[131936.021362] usb 5-4.3.2: New USB device strings: Mfr=0, Product=2, SerialNum
ber=0
[131936.021365] usb 5-4.3.2: Product: USB2.0-Ser!
[131936.360870] usb 5-4.3.1: new full-speed USB device number 11 using xhci_hcd
[131936.635396] usb 5-4.3.1: New USB device found, idVendor=0d8c, idProduct=0012
, bcdDevice= 1.00
[131936.635398] usb 5-4.3.1: New USB device strings: Mfr=1, Product=2, SerialNum
ber=0
[131936.635399] usb 5-4.3.1: Product: USB Audio Device
[131936.635400] usb 5-4.3.1: Manufacturer: C-Media Electronics Inc.
[131936.675747] input: C-Media Electronics Inc. USB Audio Device as /devices/pci
0000:00/0000:00:02.1/0000:03:00.0/0000:04:0c.0/0000:14:00.0/usb5/5-4/5-4.3/5-4.3
.1/5-4.3.1:1.3/0003:0D8C:0012.0009/input/input33
[131936.734251] hid-generic 0003:0D8C:0012.0009: input,hidraw8: USB HID v1.00 De
vice [C-Media Electronics Inc. USB Audio Device] on usb-0000:14:00.0-4.3.1/input
3
[131936.762002] usbcore: registered new interface driver usbserial_generic
[131936.762010] usbserial: USB Serial support registered for generic
[131936.766921] usbcore: registered new interface driver ch341
[131936.766929] usbserial: USB Serial support registered for ch341-uart
[131936.766937] ch341 5-4.3.2:1.0: ch341-uart converter detected
[131936.767494] ch341-uart ttyUSB0: break control not supported, using simulated
 break
[131936.767523] usb 5-4.3.2: ch341-uart converter now attached to ttyUSB0
[131937.067790] usb 5-4.3: USB disconnect, device number 9
[131937.067792] usb 5-4.3.1: USB disconnect, device number 11
[131937.137341] usb 5-4.3.2: USB disconnect, device number 10
[131937.137450] ch341-uart ttyUSB0: ch341-uart converter now disconnected from t
tyUSB0
[131937.137464] ch341 5-4.3.2:1.0: device disconnected
```

This tells us that:
 * USB data lines work both on the host-side and the board-side
 * The USB hub works
 * The audio chipset is detected
 * The USB cable passthru to the MCU module works
   * The CH341 serial UART on the MCU is detected

Fantastic! Let's power it on a bit longer to get a USB tree display.

```
        |__ Port 003: Dev 015, If 0, Class=Hub, Driver=hub/4p, 480M
            |__ Port 001: Dev 017, If 0, Class=Audio, Driver=snd-usb-audio, 12M
            |__ Port 001: Dev 017, If 1, Class=Audio, Driver=snd-usb-audio, 12M
            |__ Port 001: Dev 017, If 2, Class=Audio, Driver=snd-usb-audio, 12M
            |__ Port 001: Dev 017, If 3, Class=Human Interface Device, Driver=usbhid, 12M
            |__ Port 002: Dev 016, If 0, Class=Vendor Specific Class, Driver=ch341, 12M
```

Great. 

Here we can see four device interfaces on the audio chipset, three audio and one USB HID (used for microphone buttons).

The audio devices are used to receive audio from and send audio to the transceiver.

The final device is the MCU module's CH341 serial UART interface which is used for serial control and programming.

## Next steps

A reasonable step might now be to __attempt to program the device__ in order to better verify on-board functionality.

Alternatively, we could __go back and try to solve the USB C power distribution issue__.  Let's do that as it's annoying me that we've been so lucky with the later-stage USB devices but failed with the base power.

## Back to the USB power distribution problem

It seems that what may have happened is that I misunderstood the USB-C power distribution system, as it is my first time designing both USB devices and USBC powered devices.

Basically, there are three logical lines related to power on the USB C standard:
 * The `VBUS` line, which is the USB bus voltage. This goes all the way back to USB 1.0.
 * The `CC1` and `CC2` lines, which are new to USB-C and used for the negotiation of more power.

It seems that my wrong-headed design-time assumption was that the power would be negotiated on *and distributed on* the `CC1` and `CC2` lines, because `VBUS` has far too many backwards compatibility issues to be brought up to a high voltage and amperage.

However, it seems this assumption was wrong, and that in fact the `VBUS` line is used for the power distribution and the `CC1` and `CC2` lines are only used for power negotiation. This is odd to me, but I suppose that's how it is, because it would explain our situation as follows:
 * The `TUSB321` chip never comes up
 * The `TUSB321` documentation final page suggests adding a 100nF bypass cap on the `VDD` pin (implying external power input required through this pin)
 * The direct connection between `VBUS` and the boost converter fried it, because:
   * After `VDD` was powered on for `TUSB321` (since it's on the same net that was directly powered), it negotiated more power which was in excess of the boost converter `MT3608B` `IN` pin's absolute maximum voltage.

This is a sketchy comprehension but seems like it may be heading in the right direction.

If that holds, and we could probably do some further testing to verify the theory, then:
 * In terms of safely bringing up the TUSB321 using only USB power, we could perhaps cut the connection from VDD to the `MT3608B` and instead connect it to pin 5 (`VBUS_DET`) which lies behind a protective 909K resistor which the `TUSB321` datasheet states is for reducing modern high VBUS voltages to a safe small level. Presumably this power level may be adequate for powering the chip.
 * The `TUSB321` datasheet says that it should be functional at 4.5V, that all pins have an absolute maximum of 6-6.3V, and that the threshold voltage should be 4V
 * We should perhaps go back to re-measure the threshold voltage presented before and after the 909K resistor, however I believe the voltage is well below 1V and thus insufficient.

Some potential fixes:
 * Some __parallel, alternate resistor configuration__ to obtain a higher voltage (eg. 200K instead of 909K)
 * A __5V regulator__ capable of the higher voltages that may be presented on the `VBUS` line
   * Most regulators seem to fail around 17V (AMS1117)
   * I found a local supply of 35V 1.5A capable 5V regulators, L7805CV, and procured them. They should arrive tomorrow.
 * A __12V regulator__ to reduce the `VBUS` line (if higher than 5V) down to 12V stable, instead of the current boost converter

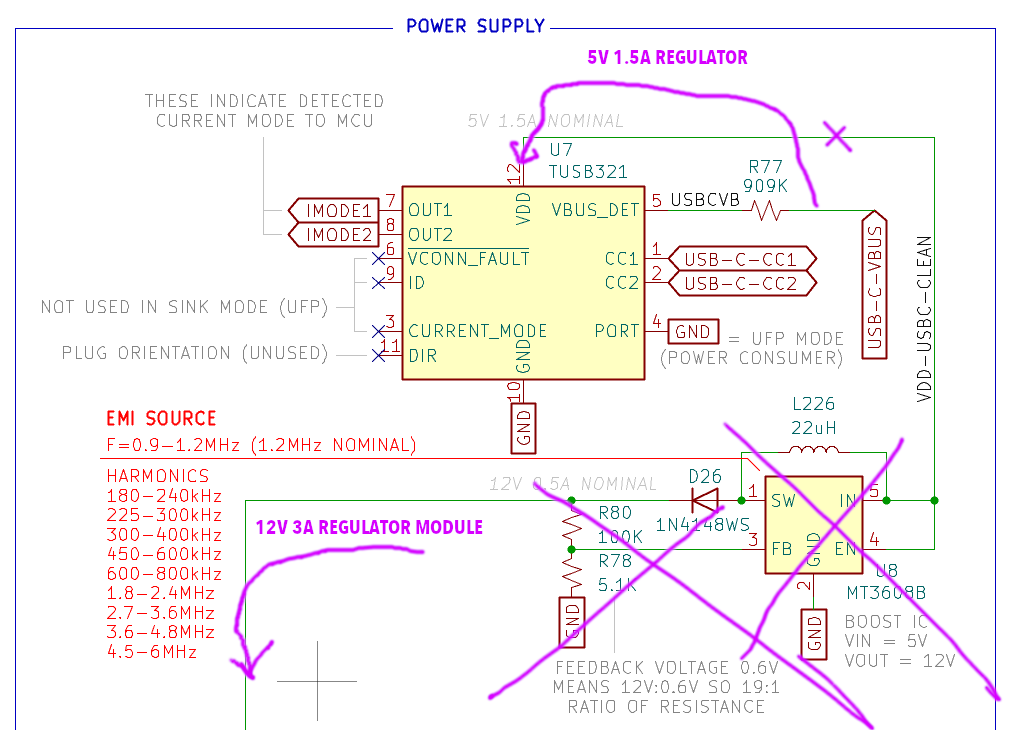
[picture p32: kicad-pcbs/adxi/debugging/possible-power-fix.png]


## The Plan

 * Cut the connection between the `TUSB321` and the `MT3608B`.
 * Wire a 5V regulator output or a resistor setup to the `TUSB321` chip's `VDD` pin.
 * Instrument `CC1`, `CC2`, `VDD` and the USB `VBUS` line.
 * Run a power-up test capturing oscilloscope output to verify that `TUSB321` is now powering up correctly, and what effect this has if any on the `VBUS` line voltage.
 * Then, move on to `MT3608B` subsystem testing based on the newly clarified and verified context.
   * If, as suspected, the `TUSB321` negotiates changes to the `VBUS` line that present a voltage higher than desired for the `MT3608B`, use a 12V regulator module instead.
   * If, after verifying power-up, the `TUSB321` negotiates changes to the `VBUS` line that only present a higher amperage, further consideration will be required.

## Regulator insertion

It seems this test point is the correct place to target: solderable, large, out of the way.

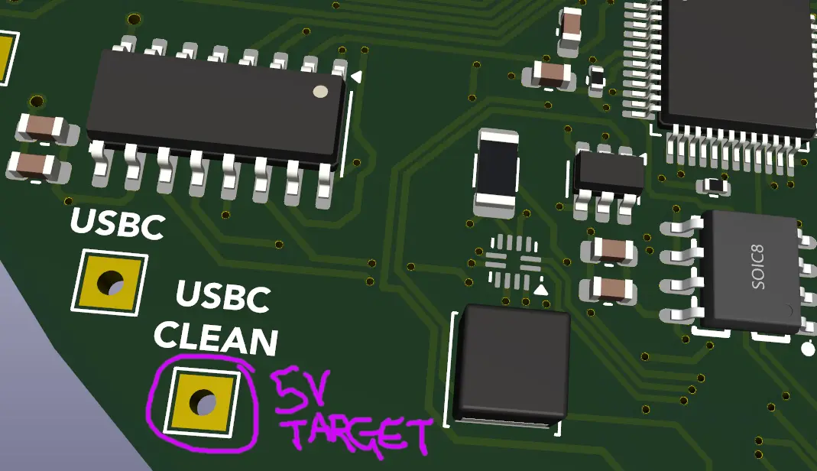
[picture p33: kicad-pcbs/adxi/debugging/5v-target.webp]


However, before executing that plan it may be beneficial to first use the bench supply with a low current set just to see what happens when voltage is applied.

### Bench supply pre-test

The first step was removing the `MT3608B` boost converter which had anyway blown up. After failing with the soldering iron I succeeded with the hot air gun, while holding the part with tweezers and applying horizontal pressure to dislodge it. This effectively isolates the `VDD` pin of the `TUSB321` so that the 'USBC CLEAN' test point can be used to feed it a specific and precise current from the bench supply.

The next step was to move the alligator clip for supply from the previous 12V configuration used for board bringup to 5V terminals on the PSU and this new target test point on the board.

The next step was to solder on test leads to allow instrumenting the lines of interest in order to monitor the power-up and functioning of the `TUSB321` chip.
 * `CC1`
 * `CC2`
 * `VBUS-DET` (detection pin input, after 909K resistor, at 'USBC' test point)
 * `VBUS` (post ferrite, pre-resistor)

The final step is to write a test program to set the PSU configuration and enable power temporarily.

The expected functionality is something like:
 * USB is connected to an external powered hub
 * Power is introduced to the `VDD` pin from the bench supply
 * Some sort of process occurs on `CC1` and `CC2` representing negotiation for more power
 * Change occurs on the `VBUS` and should be measured
 * The bench supply powers off

The orignal state, with USB disconnected and no power applied, is as follows.



In other words, everything is at zero as expected.

More interestingly, the original state, with USB connected and no bench power applied, is as follows.



Here you can see:
 * `CH1` = `CC1` is ~0V
 * `CH2` = `CC2` is ~0.9V
 * `CH3` = `VBUS-DET` is ~0.5V
 * `CH4` = `VBUS` is ~5.25V

We now need to define a trigger from which to action our oscilloscope capture.

Perhaps a voltage higher than 5.5V occuring on `VBUS` would be good signal, or a signal appearing on `CC1`. Let's try the latter first, since it should occur before any VBUS rise.

I tested the proposed trigger on plugging in the USB cable and obtained this capture.



Here you can see:
 * `CH1` = `CC1` begins at an initial 0.4V or so before rapidly dropping to 0V.
 * `CH2` = `CC2` rises from an initial 0.6V to 0.9V within around 100us.
 * `CH3` = `VBUS-DET` remains stable at 0.5V
 * `CH4` = `VBUS` remains stable at ~5.25V

This may be useful as a point of comparison for subsequent captures.

Let's try powering up the `TUSB321` chipset with the bench supply and seeing what happens.

```
DP832 PSU
 - Status: OFF
 - Version: RIGOL TECHNOLOGIES,DP832,DP8C233203778,00.01.16
 - Self test: TopBoard:PASS,BottomBoard:PASS,Fan:PASS

Turning channels off... OK
Setting up channel #1
 - Voltage: 24.000V
 - Voltage limit: 24.000V
 - Voltage limiting: ON
 - Current: 0.500A
 - Current limit: 0.500A
 - Current limiting: ON
Setting up channel #2
 - Voltage: 12.000V
 - Voltage limit: 12.000V
 - Voltage limiting: ON
 - Current: 0.300A
 - Current limit: 0.300A
 - Current limiting: ON
Setting up channel #3
 - Voltage: 5.000V
 - Voltage limit: 5.000V
 - Voltage limiting: ON
 - Current: 0.100A
 - Current limit: 0.100A
 - Current limiting: ON

Triggering channel 3 (5V) for test period
 - Enable
Saved screenshot_192.168.8.3_2024-11-06T11:43:32.png
 - Disable
```

I repeated the test a few times, but in each case the screenshot showed no power draw, the scope did not trigger.

After that, attempting to power on the 5V channel manually resulted in an error about overvoltage protection.

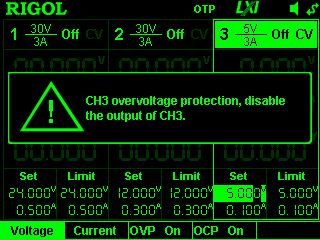
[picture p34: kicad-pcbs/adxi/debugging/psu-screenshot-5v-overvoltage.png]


The overvoltage protection was adjusted to 5.5V and then the test was retried.

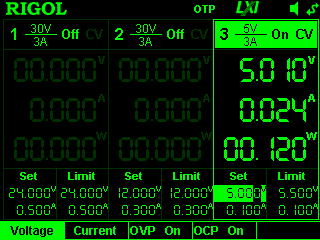
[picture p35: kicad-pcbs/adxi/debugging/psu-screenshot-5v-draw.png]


This appears to work.

However, still the scope does not trigger.

Rather than worrying about triggering, I switched it to auto mode to see if anything was visibly changing when the `TUSB321` chip is powered by the bench supply.

It was then apparent that things were changing.

Recall the USB connected, `TUSB321` unpowered state.



 * `CH1` = `CC1` is ~0V
 * `CH2` = `CC2` is ~0.9V
 * `CH3` = `VBUS-DET` is ~0.5V
 * `CH4` = `VBUS` is ~5.25V

Contrast the USB connected, `TUSB321` powered state.



 * `CH1` = `CC1` is ~0V (same)
 * `CH2` = `CC2` is ~0.4V (reduced from ~0.9V)
 * `CH3` = `VBUS-DET` is ~0.5V (same)
 * `CH4` = `VBUS` is ~5.25V (same)

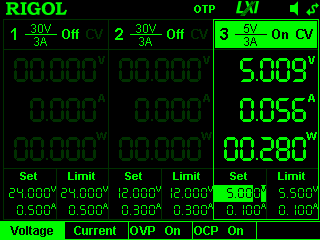
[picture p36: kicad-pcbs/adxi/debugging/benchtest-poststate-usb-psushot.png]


We also note some 56mA of power draw evidenced on the PSU.

So what's going on here? According to the `TUSB321` datasheet, there are various signalling levels used on the `CC1` and `CC2` channels.

 * "LOW" is 0.4V, which is perhaps what we are seeing in the second state
 * "MEDIUM" is 0.28-0.56 x VDD which works out to 1.47-2.94V, most likely in the middle, or around 2.2V
 * "HIGH" is VDD-0.3V which works out to 4.95V

None of these levels appear to describe the rest state we are seeing (0.9V).

Probably it would be best not to try to spend time understanding all of the signalling state transitions and just get the thing working.

Given that the `VBUS` voltage doesn't change in this case, but some negotiation does appear to have occurred, perhaps a higher amperage 5V supply has been negotiated successfully.

Checking the power supply design notes I did state that 5V 1.5A = 7.5W was the negotiation target, so this would appear to be the case.

In terms of next steps:
 * We could connect a DC load to test what the power draw is under each scenario: no `TUSB321` power, and `TUSB321` powered and negotiations complete.
   * The hypothesis would be that ~1.5A can be drawn in the second case only.
 * Since the USB powered device which we plugged in to in this case is a USB2.0 hub, perhaps we will see a different result if we plug in to a USBC "wall wart" AC charger with known high current capability. Unfortunately that's hard to achieve in the current position due to cable length constraints and AC outlet locations on my bench.
   * While I could muck around with existing extension cords, it's a lot of hassle. Instead, I have ordered a small benchtop AC extension lead and sockets to resolve this, it should arrive tomorrow and make this feasible.
 * We could instrument the output pins of the `TUSB321` and look for state changes.

## 2024-11-07 Testing

The game plan today is to instrument the `MT3608B` boost converter stage of the power system and see what happens when very short pulses of controlled power are inserted in order to characterise its performance and determine why it may have blown up on board 2.

Since exposure to any very short pulses is less likely to damage the system, and we have access to an easy insertion point for power in, the main challenge is going to be finding a way to get a read off of the other pins, such as the feedback pin (critical) and the output pin (what the rest of the system takes as input).

In this way we can test the performance of the subsystem against projected behaviour and determine the magnitude of any differences.

In theory when 5V is applied, 12V is output.

For this testing I will revert from using board 2 to using board 1. Board 1 has a backward MCU hard-soldered in, but that's OK because we're uninterested in any later stages. This gives us a clean start with the boost converter in place without risking another board.

Oscilloscope configuration:
 * `CH1` = 'USB CLEAN' test point and also our input voltage supply point. Anticipated range in test: 0-5V.
 * `CH2` = Boost converter output (after the diode). Anticipated range in test: 0-12V.
 * `CH3` = Boost converter feedback (scaled down with resistor divider). Anticipated range in test: 0-1V.
 * `CH4` = '12V' test point, after subsequent regulator. In case everything works (wouldn't that be nice!). Anticipated range in test: 0-12V.

According to the [`MT3608B` datasheet](https://www.olimex.com/Products/Breadboarding/BB-PWR-3608/resources/MT3608.pdf), page 3:
 * `VIN` can take 2-24V. Anticipated range in test: 0-5V.
 * `EN` needs only 1.5V, but we are feeding it 5V, which is allowed and expected. Anticipated range in test: 0-5V.
 * `FB` should range between 0.588-0.612V (ie. 0.6V is the target). Anticipated range in test: 0-1V.
 * `SW` can take up to 4A of current at 50% duty cycle and 5V.

In double-checking the configuration against the datasheet we do not notice anything significant, only missing input-side capacitance which should not be required to test basic circuit configuration and one may assume mainly comes in to play under dynamically supply and load conditions.

Now we are ready to write a test routine for the boost converter subsystem.

Our general strategy should be to start at a short interval of supply, for which we will use the datasheet to ascertain a reasonable value, and a low voltage.

We will then work our way up in terms of time until we see the output stabilise (ie. the integrated feedback process has enough time to enter a stable state).

Once we have a stable output at a low voltage, we will increase the voltage toward the target input voltage of 5V.

In this way we will minimize the potential for damage to the component.

The suggested start parameters are 2.1V (being a safe margin above the 2V nominal input limit) and 5ms. We note that on page 5 of the datasheet poor efficiency and reduced switching frequency are anticipated until around 4V, therefore we should not worry too much about behaviour seen at 2.1V and seek to verify any observations at higher voltages 4V, 4.5V, 5V. The datasheet had no information on timing, which may possibly be because it is circuit-dependant and thus of dubious utility to include.

Before power is applied, the oscilloscope setup is as follows.



After running a setup script, the PSU configuration is as follows.

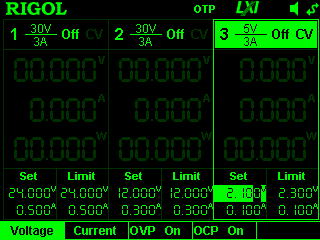
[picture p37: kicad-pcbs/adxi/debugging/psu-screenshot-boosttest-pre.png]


Since there is no easy way to apply a voltage for a very short interval, I have written the script to simply apply power with one command then immediately run another command to disable it.

This should provide a short burst that is safe, at least 2.1V 0.1A should not burn anything!

```
./psu-boosttest
DP832 PSU
 - Status: OFF
 - Version: RIGOL TECHNOLOGIES,DP832,DP8C233203778,00.01.16
 - Self test: TopBoard:PASS,BottomBoard:PASS,Fan:PASS

Turning channels off... OK
Setting up channel #1
 - Voltage: 24.000V
 - Voltage limit: 24.000V
 - Voltage limiting: ON
 - Current: 0.500A
 - Current limit: 0.500A
 - Current limiting: ON
Setting up channel #2
 - Voltage: 12.000V
 - Voltage limit: 12.000V
 - Voltage limiting: ON
 - Current: 0.300A
 - Current limit: 0.300A
 - Current limiting: ON
Setting up channel #3
 - Voltage: 2.100V
 - Voltage limit: 2.300V
 - Voltage limiting: ON
 - Current: 0.100A
 - Current limit: 0.100A
 - Current limiting: ON

Triggering channel 3 (2.1V) for test period
 - Enable
 - Disable
```

This test obtained the following result.



Here we can see the `VIN` ramping up, the `OUT`put ramping up, and the `FB` (feedback) ramping up.

However, we can't see enough detail owing to scale. I will reconfigure the oscilloscope to show higher scale and place all channels at the base.

We can't see any 12V output past the subsequent regulator, which is to be expected as its threshold turn-on voltage is never achieved.

Let's see the same result with more details.



Here we can see the same data, partly obscured by overlay and with some significant abberations on the feedback pin.

The key takeaway is that the maximum voltage attained on the input pin is still short of the target voltage, implying that we haven't provided power long enough.

We should therefore add a small delay in the script and determine whether input reaches the programmed level before proceeding.



We now see the boost converter appear to reach a fully ramped-up state, with stable output attained.

While we're seeing quite some abberations on the feedback pin, this may partly be to do with the lack of a load and the lack of capacitance before the subsequent 12v regulator.

The stable output levels are:

| Input | Feedback | Output |
| ----- | --- | --- |
| 2.1V  | 75mV | 1.95V  |

Let's try again, increasing the maximum current from 0.1A to 0.2A, just to see if there's a change.



We see similar curves with similar final values and a similar period here, that is to say again with about a 20ms ramp-up time. So it seems the additional current has not really changed things. We can turn it down again and proceed to increase voltage. Let's try 2.5V.



OK, so that's interesting. We appear to have reached a particularly high abberation point within the circuit. This is certainly not looking healthy.

When we zoom in here's what we see.



This shows that the output is cycling between a series of decreasing peaks, and the feedback pin (which should be a scaled-down version of the same waveform, albeit at higher scale/detail) echoes this perspective. The input voltage is very stable.

We note that the peak of the feedback pin occurs at nearly 8x50mV = 600mV which is around the point at which it is supposed to stabilize. So this is potentially correct activity.

Let's look at the frequency ranges shown at this voltage in the `MT3608B` boost converter datasheet and compare those to any curves present in the inductor datasheet and in the capture.

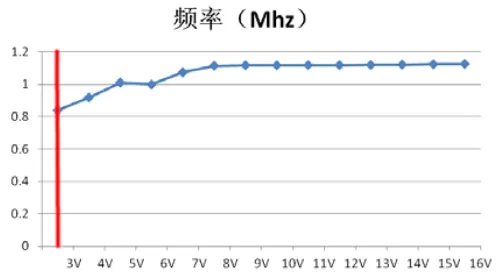
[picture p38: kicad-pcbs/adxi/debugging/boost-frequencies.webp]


This implies that the boost converter switching frequency we are seeing should be around 800kHz which works out to around one cycle per 1250ns.

In the oscilloscope output we can see the cycle repeats at around 1000ns. This is in the range of expected behaviour.

A key problem seems to be that the output is not stable, this is due to lack of capacitance, and may improve with load.

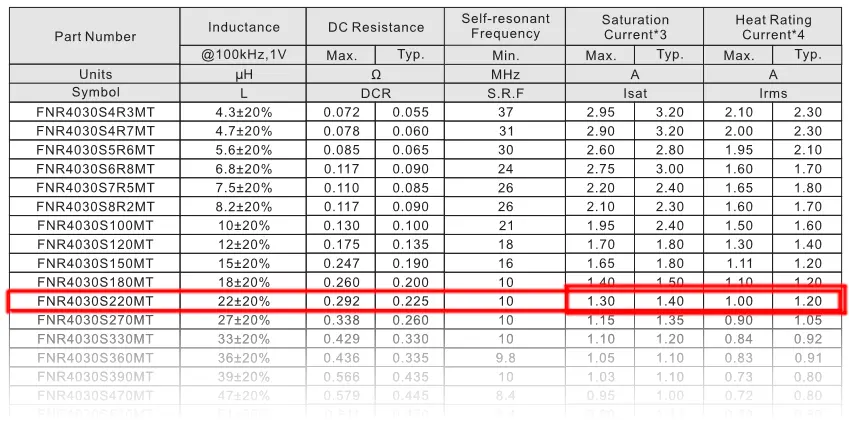
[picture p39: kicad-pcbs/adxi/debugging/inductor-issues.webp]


Double-checking the inductor we find that it is not really rated for more than 1.2A which at 5V gives us only around 6W less losses, which is cutting it fine for a 5W output.

Probably we could have selected a better inductor, but this one should - at a minimum - function fine until we exceed 1A load, at which heat should be expected, and safely for short periods up to 1.2A load (if the datasheet may be believed). So in short we're probably slightly underpowered but that may not be a problem given bulk capacitance is present in later stages.

Now let's try the same capture after updating the voltage to 3.5V and observe how the detailed curves change. We would anticipate the potential of an increased switching frequency, according to the frequencies graph we just saw in the boost converter datasheet.



Here we see the same frequency as we had before, which is around 1000ns.

Notably, we only see a small increase in the input voltage and the output power which is not in line with the input voltage increase. This implies the current may be insufficient. Let's increase the current to 0.2A and see what happens.



Wow, that's a substantial difference. We're seeing periods of total output power absence which implies we're browning out the boost regulator in some way. This is definitely bad news.

Let's increase the current again to 0.3A and see what happens.



We are still seeing this issue. Let's increase it again, this time to 0.4A.



We are still seeing this issue. Let's increase it again, this time to 0.5A.



OK, so that's not really doing it for us. Let's try to increase the voltage instead. We'll bring it up from 3.5V to 4.0V and look for change.



Here we can see that the previously flat period with no output has begun to recover. I think we're just sailing too close to the low-end of the functional paramters for this subsystem and this is made worse by a lack of local capacitance on the input side. Let's bring the voltage up to 5V and get in to standard operating territory. This should give us a clear view of what's going on and move us now closer to the intended circuit configuration.



We're still seeing similar results. We can try adding a load now and we'll likely see things become stable.

I had a 12V 0.3A fan lying around, we'll see what that does to things.



Well that's apparently working. The fan began to move before the power cut out, and what we see in the oscilloscope that has changed is the introduction of a period of oscillations in the feedback output which matches the addition of a load. If we add a capacitor rather than just the load itself the anticipation would be a smoothing out of the curves.

However, first of all let's zoom back out to the bigger picture before making any changes.



Here we see the ramp-up period of around 4ms. Let's get a slightly better view.



And better...



Here we can see some interesting properties.

Firstly, we are seeing the output (light blue) touching around 15V.

Secondly, we are seeing the feedback exceed the range which is set to 8x50=600mV. That's expected, since we were anticipating 680mV. Let's scale that down and see how high it gets. We'd expect it to move higher than the reference point during the periods at which the output oscillates beyond 12V.



So here we can see a much more useful view of the overall system startup. 
 * `VIN` scales up smoothly but oscillates with the switching load due to lack of local capacitance.
 * `OUT` reaches around 15V at peak but generally is in the range we would anticipate but oscillates probably due to lack of local capacitance.
 * `FB` oscillates as high as around 4.5V or slightly below `VIN`, which again is probably expected and will disappear if capacitance is added.
 * `12V` is actually powering on, it seems the regulator downstream begins to generate output as power arrives albeit at something less than its input level in this time period. We should zoom out further to see if it actually completes its rise.



Well that's interesting. Looking at the overall picture now, we notice that the regulator flattens its output to around 6V or half of what it should anticipate. This may be due to the effect of the fan as an additional load drawing too much power. Let's unplug that and see what happens.



A very different picture as we anticipated.

We're seeing the downstream 12V regulator output plateau, this is unexpected.

Next steps:
 - Double check the calculations for the resistor divider on the feedback pin. If these are wrong, it can affect the output voltage. However, they appear correct, and we are actually seeing ~15V peaks.
 - Add some capacitance to see how this smooths out the curves.
 - Try increasing the length of on time and seeing what happens, checking for thermal buildup.

On the double-checking front, from the datasheet:
 * "The feedback voltage is 0.6V." (Elsewhere the range is specified as 0.588-0.612V)
 * The formula is given: `VOUT = VREF x (1 + (R1/R2))`
 * Substituting:
   * `12V ~= 0.6V x (1 + (100K/5.1K))`
   * `12V ~= 0.6V x (1 + (19.6078431))`
   * `12V ~= 0.6V x 20.6078431`
   * `12V ~= 12.36470588V`
 * In the most extreme cases within stated manufacturing tolerance (ie. VREF is misplaced between 0.588V or 0.612V) we expect instead 12.12V through 12.61V

So in theory the output should be correct or within a few percent, we should not see a half output. We could add a capacitor to smooth things out, this will need to be ordered as I don't have any leaded ones lying around. Correction, found one! 1000uF.

Let's see what a recapture looks like now.



That's looking a lot cleaner. We can see a substantial reduction in the oscillations.

Let's try increasing the current to 0.9A and see what happens.



The 12V regulator output now rises to around 7V. Let's give it a bit more time and see what happens.



This is interesting. It seems at a later point we now see the boost converter circuit state change. Once this occurs, feedback oscillations decrease, output voltage oscillation decreases and he 12V regulator settles on a 7V output. As we are stil seeing large oscillations in the input volatage, it seems that area is critically missing capacitance. If only we could find another leaded cap... I will go hunt one down. Got one, 100uF 50V.

Let's retry with both the input cap and the output cap and see what happens.



This has removed the state change, and the voltage continues to ramp upwards.

Overall however we still see the following picture:
 * __Very high oscillation in the input voltage__ due presumably to non-local capacitance, insufficient current, and wrong capacitor type. The switched inductor is 'right next to' the boost converter (actually the layout of this part of the board is sub-optimal) but the off-board capacitor is some distance away. This does not help. Checking the datasheet for the boost converter, the recommended capacitor type is ceramic whereas we are using electrolytic which are less suitable for high frequencies. I have ordered some ceramics to test with. This may become stable once downstream caps have charged and the load has normalized.
 * __Input and output voltage still both trending upwards at input termination__. This suggests a longer power-on period may assist with achieving more stable output.

While waiting for new capacitors to arrive, let's give the system a bit more time and see what happens.

### More power!



Here we can see:
 * Input voltage stabilizes around 3.5V after 250ms. This suggests it is insufficiently powerful to drive the boost converter.
 * Boost output voltage stabilizes around 10V after 250ms. Given we have checked our calculations and added capacitance, this suggests a power shortage.
 * The feedback pin continues to oscillate with peaks up to 6.5V
 * The 12V regulator output voltage does stabilize (around 250ms) at 9V.

At this point we will try adding more power by bringing the amperage up to 1.1A.



Here we see much the same picture, although the input voltage stabilizes at 3.5V more quickly, here about 100ms or so.

We could try raising the input voltage slightly to see if it affects the output voltage.
 * Hypothesis: If the input voltage increase yields a higher than 9V output of the 12V regulator, then we are still underpowered. Otherwise, we are not underpowered and the issue may be in the resistor divider being inaccurate.

Let's try 5.3V.



This appears to have triggered the built-in overvoltage protection in the third channel of the bench PSU.

I will reprogram the PSU to have 5V on channel 2 (which has higher output capacity to 30V/3A) and retry the same capture.



This appears to have the same curve, which appears to show the input voltage rising abruptly before decreasing.

Here is the channel 1 view.



As you can see it drops quite abruptly.

Theories:
 * The boost converter changed state, eg. frequency?
   * We can verify or discount this by zooming in to the detailed curves around the time of transition.   
     * Result: The switching indeed appears to have altered in character although not necessarily frequency. Could this be the boost converter unexpectedly entering a stable "hold" state? Could it be that the resistors defining the output voltage point are poorly matched to their nominal values?
 * The boost converter enters a state in which it requires more power than is available?
   * Unlikely, since we are supply a lot of power at this point.
     * Result: Discount this theory.
 * Non-local input or output capacitance finished charging?
   * We can potentially confirm or discount the capacitance as a cause of state change by adding and removing capacitance.
 * The downstream 12V regulator changed state? 
   * We should discount the 12V regulator as the cause since it curves down slowly in resonse to the abrupt change earlier in the circuit, the earliest of course being the input voltage, which is affected by the boost converter switching frequency and current draw.
     * Result: Discount this theory.

### Bad resistance?

Other than waiting for extra and superior capacitance to arrive, it seems the best way to move forward at this point is perhaps to cover the basics by double-checking the resistor values. If the resistors do not appear to be correct, we may have found our issue. Reflowing the area with the heat gun may also help. First let's measure.
 * 97.1k
 * 5.04k

After recalculating against the 0.6V nominal reference, 12.16v. If the reference is at the extreme ends of the datasheet quoted range, then this could be as low as 11.9V and as high as 12.4V.

None of these account for the observed behaviour.

### Irregular regulator?

Another option is that the 12V regulator is outputting 9V because the wrong part was added.

However, the label on the part matches the label on the [JLCPCB component page](https://jlcpcb.com/partdetail/Xblw-L7812CDTR_XBLW/C22357877), and the label in the datasheet for a 12V part, specifically `XBLW L7812 CHN 343B`.

What if I remove the regulator part from the board, and test it with the bench supply? This would finally determine whether in fact the part is 9V internally or 12V.

After investigation, removal seems irritating owing to the close proximity to other components, and the soldered ground plate being a large surface area.

Another option would be lifting a pin, however this is hard to achieve with my present hand tools.

A final option which does seem feasible is to cut the regulator's output pin, bend a portion upward, and instrument that. This would presumably isolate it from the rest of the circuit sufficiently to identify whether or not there is a problem. I have ordered a precision cutting tool for this purpose, which should arrive tomorrow.

In the mean time, I will consider that the 9V being shown is some sort of mix between 12V correct output and 5V elsewhere (so 7V difference meaning 8.5V is the nominal middle) due to the MCU module being incorrectly installed and thus through some combination of circumstance this regulator may be fighting another regulator, or some kind of alternate circumstance having similar outcomes.

### Third time lucky?

Perhaps a fresh board would not have this problem, in other words. Re-instrumenting a third board could be a way forward, since this board #1 has the backward MCU and board #2 had a burned out boost converter. The question that then remains is why did the boost converter burn out? It seems I may have found the issue in terms of current. Nothing is really limiting current on the board, whereas the boost converter only supports ~1.2A (or really 1A comfortably) the other components like the 12V regulator are higher rated and there's quite a bit of capacitance to fill. Perhaps the issue was that the boost converter simply fried due to too much inrush current?

This would explain everything.

However, this does not position things well for a revision without a new board.

Perhaps a plug-in board could be developed which provides an alternative circuit path to the part of the board currently broken.

I will look in to alternative boost converters with higher current potential.

Shortlist:
 * [MT3540-F23](https://jlcpcb.com/partdetail/xi_an_AerosemiTech-MT3540F23/C181783) @ 1.5A (Xi'an Aerosemi Tech) - same manufacturer as current chip
 * [L7812CV-DG](https://jlcpcb.com/partdetail/Stmicroelectronics-L7812CVDG/C2914) @ 1.5A (STMicro)
 * [MC34063ECN](https://jlcpcb.com/partdetail/Stmicroelectronics-MC34063ECN/C5180) @ 1.5A (STMicro)

... argh! So it turns out the component selection was good, and it's actully a 4A part. However, it's a 'China clone' part that's based on an original part with ~1-1.2A limits.

The China ones are much better, and available from multiple manufacturers for ~nothing. So the part selection was actually ideal.

Unsure what the issue is/was about it blowing up then.

I've managed to find a tool to cut the leg on the downstream regulator and re-instrument directly off the pin, so let's check out a retry.

### Reintroducing Mr. Regulator (Xi'an Special Edition)

A retry with the same settings yielded this capture.



Looking a lot more regular. Let's zoom out and see where we're at.



This looks like now we are only getting around 5V output from the regulator.

I am now worried that we've fried the resistor through over-zealous soldering (the probes came loose).

To test this theory I will run the multimeter over both sides to determine resistance.

Yes, it appears to have dropped from ~100K to ~35K.

This explains the drop in voltage, from `VOUT = VREF × (1 + (R1/R2))`.

```
VREF = 0.6V (reference voltage)
R1 = 35k (damaged upper resistor)
R2 = 5.04k (lower resistor, previously measured) Let's calculate: VOUT = 0.6V × (1 + (35k/5.04k))
= 0.6V × (1 + 6.9444444)
= 0.6V × 7.9444444
= 4.76666667V
```

Therefore, with the damaged upper resistor now measuring 35k, the expected output voltage of the boost converter would be approximately 4.77V. 

This is exactly what we are seeing. We note also that the previous 9V may have also been due to resistor damage from soldering performed after measuring the resistor.

## New Mister Resistor

Found another 100K resistor and installed in place. It measures 96.4K which should be fine.

Let's try again.



Well, here we can see very little, it's all over the place. Let's try a second capture, after moving some probes around to ensure good grounding.



Very similar to what we had before the resistor replacement, except all the curves are much higher. It seems that the output voltage continues to rise the whole way through the capture until power is cut, reaching something like 15V average but 30V peaks.

Let's see if we scale that down and recapture just how high it goes.



Wow. Again off the charts, reaching something like 50V or more.

Let's see what happens if we temporarily remove the 1000uF capacitor.



OK that's definitely bad.

I think we need to wait for the capacitors to arrive and try some functioning caps.

I put the cap back in and got back to this sort of thing, similar to two images ago.



The key takeaway is that, once the power is cut and all is said and done, the 12V regulator actually outputs 12V.

The hope is that, after we add some more capacitance, we will see this without unplugging, and that will be a stable output suitable for the rest of the circuit.

In the mean time we will try running a little longer to see what happens.



I flipped the acquire mode to 'high res' which seems to have removed the sketchyness and shows more of a reasonable output.

Here you can see:
 * The `VIN` voltage comes up in about 200ms on the supply side (yellow)
 * While this is happening, the boost output (light blue) ramps steadily upward toward 20V or more
 * While this is going on the 24V regulator is cutting its output back to something tiny, probably sensing dangerous levels of supply.
 * Finally, the power is cut. Immediately, boost output begins to drain as the 1000uF 25V capacitor empties, but the regulator is now happy and switches to a 12V output which remains stable.

It seems, perhaps, that the state of the circuit between the boost converter and the regulator is causing issues for the regulator. 

We can hope that the new capacitance fixes the problem, noting the old 1000uF is ~25 years old and only rated for 25V which is already being exceeded.



This was the 'peak' acquire mode, zoomed out to maximum level. Less clear, but it shows some high voltages on the output side well above 35V.

After that we see stability, which continues until the boost stage output drops below 12V, at which point the later-stage 12V regulator begins a steady decline.



This is the same capture in 'normal' acquire mode.



Here is a zoomed in version, with layers selected so as to increase legibility.



Here is the same capture in peak mode.

### MT3608B Design Review

 * With regards to the mode switch we have been seeing, it seems the datasheet has a clue: "The MT3608B has internal soft start to limit the amount of input current at startup and to also limit the amount of overshoot on the output." This suggests we're seeing the end of the soft start ramp-up.
 * Layout is specified strictly and we have an absolute chop-shop slop job, so this needs rejigging.
   * Key issues are large loops, unduly long traces, and thin traces.
 * Inductor is specified as 4.7uH-22uH and we selected 22uH. Just relying on general assumption, it may be beneficial to move toward the middle of the range (10uH). [This option](https://jlcpcb.com/partdetail/Sunlord-WPN4020H100MT/C98364) looks good, or an [overkill high current option](https://jlcpcb.com/partdetail/Sunlord-MWSA0603S100MT/C132141). Checking relevant theory, based on the circuit parameters we should have selected something in the 5-10uH range anyway, 6.8uH or 10uH would be better. 22uH is too large which leads to feedback loop issues and slow transient response which is what we were perhaps seeing.
 * Inductor should be low DCR, according to [this similar (same clone) part Chinese datasheet](https://www.lcsc.com/datasheet/lcsc_datasheet_2105242005_NATLINEAR-LN2220PAR_C2833712.pdf).
 * Recommended 22uF caps missing on input and output pins
 * Schottky diode is 75V rated, and must have current rating over RMS, so looks OK from that perspective.
 ```
ID(RMS) = SQRT(IOUT x IPEAK)
ID(RMS) = SQRT(12V x 67V)
ID(RMS) = SQRT(804V)
ID(RMS) = 28.35V
```
 * Schottky diode should be selected for low forward voltage drop, to achieve higher load efficiency.

### 2024-11-08 Debugging

I am going to start the day by reading up on boost converter design equations, documenting the novel material in the power supply notes, and then revisiting the current situation with a new board. Only electrolytic capacitors arrived last night, I have no ceramics, and the fundamental problem of a larger inductor than is preferred is going to be difficult to solve without a new board given that the inductors are so small and come in such a range of disparate form factors.

#### New board plan

One option is to produce an intermediate board that upgrades the current boards with a reimplmentation of the power supply stages. This would have to pull in the `VBUS` current to power the `TUSB321` chipset. Presumably we can rely on the `VBUS` current never being over 5V because we will not negotiate such. Therefore, we should aim to have a resistor just large enough to provide power to the `TUSB321` directly from bus power, with some kind of protection diode, but perhaps have this circuit disabled once the local 5V comes online so that supply is continuous and transitions to onboard 5V as the preferred source. It would implement interfaces to the `VDD` and `VBUSDET` pins, as well as to a reimplementation of the `MT3608B` block, then output to the input of the 12V regulator. So it would need connections to raw `VBUS`, `TUSB321:VDD`, `5V`, `GND`, and the 12V regulator input. On the board itself, some modifications would be required, including the removal of at last one of the feedback resistors and the `MT3608B` chip.
 * `VBUS`: Raw USB bus voltage
   * Used for: Early stage and later stage power to boot the `TUSB321`, new input to re-implemented `MT3608B` block for main power draw.
   * Source from: Ferrite bead terminal or resistor terminal (both dangerous as overheating may damage the components)
 * `TUSB321:VDD`: Power input to `TUSB321`
   * Used for: Powering on the chip to negotiate a higher amperage on `VBUS`.
   * Source from: Test point 'USBC CLEAN', after removing existing `MT3608B` and inductor which are the only other things on the net.
 * `5V`: Regulated 5V supply
   * Used for: Power input to `TUSB321` after boot completes
   * Source from: Test point '5V'.
 * `GND`: Ground
   * Used for: Everything
   * Source from: Test point 'GND'.
 * `L7812:VIN`: Regulator input.
   * Used for: Boost stage power passthru from bus.
   * Source from: L7812 VIN pin directly (trace width too thin on test point).

Here's what I came up with in terms of those five connection points.



This could be quite a small 2 layer board, the only issue is I will need to import the geometry which KiCad is not great for.

Its components will be: 100uF + 100nF cap for TUSB321 VDD, diodes and resistors for smooth power transition sourcing from `VBUS` to `5V`, `MT3608B` and associated inductor (6.8uF or 10uF this time), diode (same as last time), resistors (same as last time) and input and output capacitors (22uF each), 330nF cap before `L7812:VIN`, and 100nF cap after `L7812:OUT` output before passing to mainboard 12V regulator.

Although it seems from various comments that TI does not encourage people to power `VDD` from the `VBUS` source although other people have stated this goal and tried. [One attempt](https://e2e.ti.com/support/interface-group/interface/f/interface-forum/873752/tusb321-configuration-issues-when-using-tusb321-as-ufp) (inconclusive result) tries to use two bypass capacitors of 10uF and 0.1uF at the port with no filtering or limiting. We already have a ferrite, at least. Other sources suggest the combination of transients during connect/disconnect events and potentially higher bus voltages such as from misbehaving peers mean that this is a bad idea.

Overall I think that small board will be a good cheap fix, at least it should work.

The power transition stuff might be buggy, perhaps it would be good to model that first with a bench PSU changeover.

#### Bench model

The power switching situation to model would be a 4.5V-5.5V VBUS supply needing a schottky diode, some zener protection and a slight voltage reduction (say to 4.55V regulated, say through a 5V regulator like L6705CV plus a subsequent voltage divider of 10K/100K to reduce voltage) before feeding to an output. After this occurs, a second supply channel is switched on at 5V (simulating the regulated output) and should take over. We should see the bench supply current level switch over entirely to the new supply channel. If this works, we can progress with confidence.

The relationship between the two sources should be as follows:
 * A schottky diode from each source ensures unidirectional flow
 * When the higher voltage source appears, it will take precedence

I have ordered some schottky diodes for testing, they will arrive tomorrow.

I already have the other components: 5V regulator, associated 0.33uF/0.1uF in/out ceramic caps, 100K/10K resistors and 7.5V zener diodes.

With the following PSU configuration, ie. 6V...



We observe the following output, ie. 4.45V, as expected.



However, with the following PSU configuration, ie. 5V...



We observe the following output, ie. 3.4V, which is too low!

This means the output before the voltage divider was about 3.74V. Let's instrument that and confirm.



Yes, 3.72V.

There must be substantial losses in the regulator at low draw.

Internet hearsay suggests an 'LDO' type regulator will not have high levels of losses, however it turns out this is an LDO.

Unfortunately, I don't have any others lying around and such regulators are not available locally at short notice.

Therefore, I will have to trust the datasheet in selecting one in the final circuit and hope for adequate performance.

In the mean time, we could remove the divider network to yield the higher current.

Whether the current exceeds our required 4.5V threshold for turning on the `TUSB321` via its `VDD` pin or not, we still can test an automatic changeover of source channel when the zener diodes arrive. That will be the limit of available bench testing.

#### Stepping back

It would be worthwhile to check later stage functionality on a fresh board before committing to a fix. Point being, if there are other issues, we probably want to discover them first and decide whether it makes sense to just do a new revision of the main board instead of mucking about with fixes. Today then I will start to mark out those portions of the schematic which have been tested and work through programming the MCU. 

Areas needing attention:
 * MCU/audio chipset interface
 * Clock generator
 * Power amplifier
 * 3.3V outputs
 * Forward power, reverse power and SWR

Best approach:
 * Get a totally fresh board supplied with 12V bench power
 * Plug in a fresh MCU module (use mounts this time not direct soldering)
 * Begin process to alter firmware from previous reference firmware to current schematic

### 2024-11-09

Interesting to [see people recommending uSDX](https://news.ycombinator.com/item?id=42085304) today.

Began with looking at the datasheets for the LDOs. None of them seem to actually state 'for X voltage in, expect Y voltage out'. Maybe there is a good reason for this, maybe it is also and to a significant extent a function of current, load, temperature, etc.

However, the L7805s seem to be in higher efficiency category for what is out there. A quick look showed this is really *the* standard component and anything else is a hassle.

Given what we learned yesterday about efficiency, this makes the whole "regulate then reduce" architecture on the proposed `VBUS` early stage power supply prior to USB power distribution (PD) negotiation completing somewhat dead in the water. The mindset was 'achieve a known stable output, then precisely reduce'. This has to be reconsidered.

Perhaps:
 * We can try to add a nominal resistor divider to ensure:
   * The maximum anticipated legacy bus voltage remains below the MCU module's 5V regulator output
   * The minimum anticipated legacy bus voltage remains above the `TUSB321` chipset minimum voltage for turn-on
 * Protect from overvoltage transients with a zener diode
 * Assumptions
   * Maximum legacy bus voltage: 5.5V (ie. 5V+10% per USB spec) 
   * Minimum legacy bus voltage: 4.5V (ie. 5V-10% per USB spec)
   * Minimum MCU module 5V regulator output 4.9V
   * Minimum output voltage = workable `TUSB321` `VDD` turn-on voltage >=4.4V (since 4.5V is 'recommended')
   * Maximum output voltage < MCU module 5V regulator output = 4.85V (since MCU regulator output is 4.9V)

Given this requirement, a proposed resistor divider is as follows:
 * R1 = 11Ω 1%
 * R2 = 91Ω 1%

This should land us in the expected range:
 * At 5.5V input: `Vout = 5.5V * (91 / (11 + 91)) = 4.85V`
 * At 4.5V input: `Vout = 4.5V * (91 / (11 + 91)) = 4.40V`

While theoretically some issues may occur with `VBUS` voltages extremely close to the extreme limits if component tolerances are also taken in to account, it is perhaps reasonable to consider such situations to be extremely unlikely to occur in practice.

An alternative design would be to utilize some form of active switching, such that when `TUSB321` reports negotiation completed the raw `VBUS` supply is cut off.

This strikes me as unduly complicated, expensive, error-prone and component-linked for our purposes. The resistor approach should be sufficient.

So that's simplified things moving forward. Time to move on to the firmware testing, I'll clean the bench now and set up a new board, #3.

Cleaned the bench off, got to work setting up the new board and wanted to add some 2.54mm pin headers to make the MCU removable this time. Had to search a bit, found some but almost out. Bought some more. My soldering skills have returned, this one is much better than the previous board. I think part of it was changing soldering irons, but also JLC's default through hole finish must have changed, I guess they may have removed some lead from their HASL formula or something.

All set up: bench cleaned, new MCU module, new cable, standoffs attached, cable routed in. Ready for MCU programming.

### Bench test of power priority failover

[Schottky diodes 10SQ050 (10A 50V)](https://www.smc-diodes.com/propdf/10SQ050%20N0019%20REV.A.pdf) arrived, bench testing with first Schottky diode's anode to bench supply channel 1 (4.85V), second Schottky diode's anode to bench supply channel 2 (5.0V), cathodes are a common load point which links to GND through a 100K load resistor.

The common load point links is instrumented with the oscilloscope to determine the output voltage.

Test process:
 1. __Channel 1 (4.85V 0.1A) is on, Channel 2 (5.0V 0.05A) diode path is physically disconnected.__
   * Expected result: ~4.85V shows at common load point.
   * Result: 4.8V shows at common load point, equating to a loss of 0.05V for one diode present.  
 2. __Channel 1 (4.85V 0.1A) is on, Channel 2 (5.0V 0.05A) diode path is physically connected but switched off.__
   * Expected result: ~4.85V shows at common load point, or ~4.8V (previous result) or ~4.75V (less similar losses for second diode).
   * Result: Not as expected. 4.55V shows at common load point, equating to a further loss from 4.8V of 0.25V for the second diode present.   
   * Hypothesis: Some kind of reverse voltage loss is present in the second diode path. Perhaps this can be mitigated by adding a small, high amperage rated resistor? It is interesting to see the scale of difference between the two diodes, these diodes may have higher manufacturing tolerances because they are intended for less precision loads and therefore probably do not have many users considering this level of precision. I should really have acquired some smaller Schottky diodes... went off to the store, which was closing in 30 min, and got some `1N5822` for $3 for 2 (Bargain! And even included a stack of free [Silicon Chip](https://www.siliconchip.com.au/) back-issues!) which are 40V 3A rated. This is about the level we'd like.
 3. __Diodes both `1N5822`, repeated test 1 with Channel 1 (4.85V 0.1A) on, Channel 2 (5.0V 0.05A) diode path physically disconnected.__
   * Expected result: ~4.85V shows at common load point.
   * Result: 4.74V shows at common load point. 0.4V shows with the PSU off. So around 4.7V is present. This is a 0.15V loss from the source for one diode present. This is around 3x the losses we saw with the previous `10SQ050` diodes.   
 4. __Diodes both `1N5822`, repeated test 2 with Channel 1 (4.85V 0.1A) on, Channel 2 (5.0V 0.05A) diode path physically connected but switched off.__
   * Expected result: Increased losses.
   * Result: Better than expected! 4.75V shows at common load point.   
 5. __Diodes both `1N5822`. Scope trigger is set for 4.9V. Channel 1 (4.85V, with 4.75V presenting) remains on, Channel 2 (5.0V) is switched on as well.__
   * Expected result: 5.0V shows at common load point, limited or no overshoot.
   * Result: Doesn't trigger. While voltage raises from 4.75V to 4.89V, channel 1 continues to supply while channel 2 is available, despite having a higher voltage.   
   * Hypothesis: This may be due to the established state of the Schottky diode holding it open in preference to the second one, in terms of relative resistance being lower due to established current flow, or even just manufacturing differences in tolerance, but also perhaps due to the current limit on the bench supply channel. One way to vastly increase preference for a second source is to add a resistor to the first source to create a favourable circumstance for switching to the second source. Let's first increase the current limit to 0.3A and see what that does.
 6. __Diodes both `1N5822`. Same test as last time, with Channel 2 current set to 0.3A.__
   * Expected result: Possibly cleanly switches to Channel 2 when activated.
   * Result: Still fails to switch over, although voltage rise is seen.  
   * Hypothesis: Since the current limit didn't help, let's add a resistor to Channel 1. We'll make it 10K.
 7. __Diodes both `1N5822`. Same test as last time, with Channel 1 having a 10K resistor before the Schottky diode.__
   * Expected result: Possibly cleanly switches to Channel 2 when activated.
   * Result: Still fails to switch over, although voltage rise is seen.  
   * Hypothesis: The voltage difference is insufficient to make the change occur. To test this, we can increase the voltage to 10V and see if the change occurs.
 8. __Diodes both `1N5822`. Same test as last time, with Channel 1 having a 10K resistor before the Schottky diode.__
   * Expected result: Possibly cleanly switches to Channel 2 when activated.
   * Result: 9.88V, which is a difference of 0.12V from the nominal voltage. However, switchover does not occur.  
   * Hypothesis: Earthing the common multi-channel ground point may assist with establishing a switchover. Let's repeat with the bench PSU earth connected to the load resistor cathode at which the PSU supply channels connect.
 9. __Diodes both `1N5822`. Same test as last time, with earth lead from PSU earth to common cathode after load resistor.__
   * Expected result: Possibly cleanly switches to Channel 2 when activated.
   * Result: Changeover still fails.  

Further plans if it worked were:

 1. Both channels are switched off.
 2. A >5V zener diode is added between the load point and ground.
 3. The tests are repeated, but with Channel 1 being raised to 6V.
   * Expected result: Zener diode protection voltage shows at load, somewhere between the original voltage and 6V. This shows transient protection works. Channel 2 never engages and shows no load, even after being turned on, since it's under the Zener protection voltage.
 4. The tests are repeated, but with Channel 2 being raised to 6V.
   * Expected result: When Channel 2 is switched on, the Zener protection voltage is shown.

Since this fairly detailed bench test din't work however, and the power priority circuit therefore cannot be reasonably expected to function, we should look at alternatives.

It seems the alternative to two passive Schottkys is an active MOSFET switch, which would necessitate applying the voltage from the second source to the switch to cut off the initial supply.

### 2024-11-10 Power fix board

The goal for today is to get the power fix board designed and ordered.

With reference to yesterday's failed bench testing of a passive Schottky diode and resistor based topology, the fix will instead use an n-channel MOSFET to perform the changeover for the `TUSB321` chip from early-stage power (`VBUS`) to later stage power (regulated `5V` rail).

There are a few stages to this:
 * Get the correct geometry out of the existing board and in to the new board
 * Design the schematic
   * `VBUS` to n-channel MOSFET drain
   * `TUSB321:VDD` to n-channel MOSFET source
   * `5V` regulated supply to n-channel MOSFET gate via pulldown and current-limiting resistor
   * Zener diode between gate (cathode; but after a 100-1000 ohm transient current-limiting resistor) and source (anode) for transient protection with voltage rating:
     * less than MOSFET V_GS(max); but
     * significantly higher than MOSFET V_GS(th);
       * ... so that the MOSFET can turn on fully and reach its lowest RDS(on).
 * Final part selection
 * Lay out the schematic

OK, now time to get started on the KiCad.

#### Copy geometry

First I had to fix my KiCad project duplication script, which had a bug and had not been used in awhile. Fixed that.

Then I replicated the entire board to a new project, then began to edit it.

#### Design the schematic

 * Shifted the old schematic off the page
 * Copied the power block back to the page as a reference
 * Drew the five identified input/output points per last two days' research
 * Began reimplementing the power stages with recommended changes

#### Final part selection

 * During this phase I found a new error, the previously selected Schottky diode was insufficiently rated for the anticipated current. This may also have contributed to the breakdown seen in the earlier testing. This was duly replaced with an `SS34` which is 40V 3A rated with 80A peak support (should be adequate).
 * The MOSFET selected was JLCPCB's recommended ('basic') [`AO3401A`](https://jlcpcb.com/partdetail/Alpha_OmegaSemicon-AO3400A/C20917) which handily supports 4.7A RMS / 5.7A peak current.
   * `V_GS` is 12V
   * `V_GS(th)` is <1.45V
   * Therefore we need a zener diode with a voltage rating set to limit voltage between 1.45-12V.
   * However, since our supply voltage is only 5V, we actually need a zener diode with a voltage rating between 1.45V and 5V.
   * For this purpose, 3.3V would do.
 * The Zener diode selected was [BZT52B3V3](https://jlcpcb.com/partdetail/Hongjiacheng-BZT52B3V3/C19077392).
 * Current limiting resistors were selected from basic parts available at JLC which means 3 x 1.2k in parallel, based on the calculation on the schematic.
 * The inductor selected was [Changjiang FXL1350_100M](https://jlcpcb.com/partdetail/544122-FXL1350_100M/C526017) which has the benefits of being:
   * Wide and short, meaning a higher surface area to volume ratio, meaning lower EMI due to better shielding
   * Large in current rating and therefore stable over the anticipated range of current draw
   * In good stock
   * Unlikely to be suddenly a favourite of others, since it has a non-standard package size

The completed schematic looked like this:



## Lay out the schematic

First, I carefully added pad edges and placeholder positioning indicators to a board comment layer. This allows easier reasoning around interface pin placement, particularly where a test point is not available and an interface must be made at the edge of an existing component.

Second, I had to import the footprint for the inductor since it was non standard. This was achieved using a [modified form of the `JLC2KiCad_lib` python script](https://github.com/vk2diy/JLC2KiCad_lib) as follows:

```
$ cd ~/code/JLC2KiCad_lib/ # enter the directory
$ . ./bin/activate # activate previously prepared local virtual python environment (venv)
$ $ JLC2KiCadLib --no_symbol C526017
2024-11-10 11:49:12,310 - INFO - creating library for component C526017
2024-11-10 11:49:12,619 - INFO - creating footprint ...
2024-11-10 11:49:13,438 - INFO - creating 3D model ...
2024-11-10 11:49:14,378 - INFO - added /home/vk2diy/code/JLC2KiCad_lib/JLC2KiCad_lib/footprint/packages3d/IND-SMD_L12.6-W13.5.wrl to footprint
2024-11-10 11:49:14,379 - INFO - created 'JLC2KiCad_lib/footprint/IND-SMD_L12.6-W13.5.kicad_mod'
```

Owing to an [open pull request](https://github.com/TousstNicolas/JLC2KiCad_lib/pull/75) it is necessary to do some hacking.

```
$ sed -i -e 's/model .*\//model /' JLC2KiCad_lib/footprint/IND-SMD_L12.6-W13.5.kicad_mod # replace absolute path with relative path
```

Now we want to copy the footprint definition file and the associated 3D model to the KiCad project.

```
$ mkdir ../adxi/kicad-pcbs/adxi-1.2-powerfix-1/library # make a library subdirectory for the project
$ cp JLC2KiCad_lib/footprint/IND-SMD_L12.6-W13.5.kicad_mod JLC2KiCad_lib/footprint/packages3d/IND-SMD_L12.6-W13.5.wrl ../adxi/kicad-pcbs/adxi-1.2-powerfix-1/library/
```

Before associating the new footprint with the symbol in the schematic it was necessary to tell the KiCad project about the footprint library.

This is a very ridiculous process which will hopefully improve in future.

First, you have to enter the layout part of the program.

Then, you click 'Manage Footprint Libraries' from the top menus to specify the path using the shorthand value `${KIPRJMOD}/library`.



Then, once saved you go back to the schematic.

In the schematic you edit the symbol.



Here you specify the footprint via the chooser. To save time you can type a part of the footprint, like '12.6' and the long list will be shortened for easy selection.



Actually you should edit library footprint here, set 'SMD' instead of 'Through Hole' in the properties ([open issue here](https://github.com/TousstNicolas/JLC2KiCad_lib/issues/77)), and draw a courtyard box ([open issue here](https://github.com/TousstNicolas/JLC2KiCad_lib/issues/76)). Save. Then return to the dialog, and click 'Update from library footprint'. This prevents errors later.

I made a backup of the directory before updating the board to import new items to allow me to clear old components for clarity while maintaining geometry without fear of losing any data.

```
$ cp -R ../adxi/kicad-pcbs/adxi-1.2-powerfix-1/ ../adxi/kicad-pcbs/adxi-1.2-powerfix-1-backup/
```

Once the footprints were imported it looked like this.



With a few placements, the gist of the board began to appear.



The main problem is after adding the oversized inductor (good quality; nice part; worth testing) there wasn't a lot of board space left. I could have done a double-sided board for top dollar but that's sort of ridiculous. So I chose to drop the 27 ohm ripple rejection resistors which in aggregate take half the board since they are 1W each. I guess that's the price you pay for current. This should be safe enough to get us past the finish line regardless, since there's already a regulator between this part of the circuit and the functional blocks, and there's a lot of capacitance spread around.

After awhile, all done.

Deviated slightly from the recommended layout around the boost converter, but nothing that should be significant.




Got that ordered.

#### Firmware beginnings

Began the process of rewriting the prior firmware.

When I actually sat down and looked at it, something like 50% was LED control and button processing, the other 50% had about 50% comments.

Removing that stuff has whittled it down to a much shorter and more comprehensible length.

Removed the EEPROM use (not long-term reliable anyway), I would prefer to have the device power on to a known state and all configuration to be made from the host machine.

Discovered another hardware bug through the process of firmware alteration: namely the `SI5351` requires 6pf, 8pf or 10pf crystal load capacitance and this must be set internally. While alternatives are available, one must be selected. We had already set load capacitance externally with capacitors. While this is a supported mode, it appears to be a differential configuration rather than an exclusive configuration option with regards to the internal load capacitance setting which appears to be mandatory. This could be a significant source of timing inaccuracy in this hardware revision and will need a rejig at some future point. However, for now, it will suffice, and worst case we can probably fix it with a new external cap. Added this to the list of hardware issues. There's [way more Si5351 documentation than any sane person can read before taking it for a spin](https://github.com/MR-DOS/Si5351-lib/tree/master/documentation). The critical info was buried in an associated application note and not even in the main datasheet. Thanks a lot guys...

### 2024-11-11

Continued to set firmware initial states.

Discovered unduly thin traces in PA drain MOSFET area, added to issues list.

Discovered that the borrowed third-party optimized implementation for inbound receieve decoding in the original firmware ([documented narratively with reference to other projects and hardware in Japanese over here](https://github.com/je1rav/QP-7C); [auto-translation](https://github-com.translate.goog/je1rav/QP-7C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)) depended on having a seemingly but not actually redundant ground input to an otherwise unused pin via a relatively obscure microcontroller feature known as the "analog comparator", which has an explicit reliance on that particular pin despite never naming it in the code. Nowhere was this effectively documented, thus it was missed as design time as I have never used this feature despite making 100s of boards. It was necessary to read the [ATMega328P microcontroller datasheet](https://ww1.microchip.com/downloads/en/DeviceDoc/Atmel-7810-Automotive-Microcontrollers-ATmega328P_Datasheet.pdf) (page 202 onward of 294) to determine this dependency. This is a great example of why hardware is tedious: you can't make this stuff up. Anyway, the situation can be worked around with a jumper cable for now. Subsequent revisions will require explicit grounding of this pin.

### 2024-11-24

 * Watching the clock
   * I instrumented the TX clock line by soldering a pin to the corner of `U4`.
   * First clock generator output observed. 
   * The clock generator output appears to be short (around 12ms) and is occurring at a frequency of 2.94kHz with 170us peaks and troughs. 
   * Why is the output this brief?
     * Perhaps the clock is reconfigured
     * Perhaps the power state changes
     * Perhaps the input timing crystal signal exceeds anticipated capacitance due to duplicate capacitance being added
   * Tried changing the configuration to `si5351.init(SI5351_CRYSTAL_LOAD_0PF, 0, 0)` to account for external load capacitance. The result was 
   * Resoldered the tap pin after knocking it loose, tried disabling calibration calls
   * New capture looks like this: 
   * On the basis that was frequency related, I dropped the test frequency to `5 * 100ULL`, resulting in a 4kHz capture. 
   * On the basis that doubling that frequency should be feasible, I increased the test frequency to `10 * 100ULL`, still resulting in a 4kHz capture. 
   * After commenting out the test code, nothing changed. This meant the issue was coming from the device `setup()` routine.
   * After re-ordering the `setup()` code, specifically placing the output disable lines immediately after the `.init()` call, I was able to obtain a situation having no output during a reset.
 * Verifying control
   * After then adding the test code, I obtained correct signal frequency of 1MHz. 
   * After halving the frequency, I obtained correct signal frequency of 500kHz. 
   * It can now be said that the clock generator is functioning correctly for the TX clock channel (channel 0).
 * Verifying dual channel control
   * I instrumented the north pad of `C13` to get access to the RX clock channel (channel 1). Initial capture was as expected. 
   * After modifying the test code to set double frequency on the RX clock, the observed signals were not as expected, the RX showed nothing.
   * The reason was determined to be that the north pad instrumentation soldering had bridged to the adjacent capacitor ground pad. After much fiddling I was able to remedy this, and repeated the test. I obtained the correct frequency (1MHz) but not the correct levels (1.1V low to 2.8V high instead of 0V low to 3.3V high).
   * The issue could either be due to board damage due to hot air gun for instrumentation, or could be a topology problem in the original layout. 
   * One issue was the instrumentation pin breaking loose and shorting. Once replaced, the capture was restored.  
   * The levels are as expected, because the RXC line has a 100nF capacitor meaning the trace is [AC-coupled](https://www.youtube.com/watch?v=y5aAjd9YPok).
   * Therefore, we can reasonably expect that we can proceed with testing the Power Amplifier.

### 2024-12-03

 * After a week or so of other matters, I plugged the system in again and revisited the current status:
   * Board plugs in
   * USB devices detected
   * Firmware can upload
   * WSJTX starts
 * After studying the apparent functionality of WSJTX, I found that no audio is received from the device.

### 2024-12-04

 * First of all, strapping `D6` to `GND` to fix the analog comparator should be done 
 * There are a daunting series of layers between the verified core and audio reception
   * The antenna system
   * The antenna to late stage module connection
   * The power amplifier
     * The low pass filter
     * The matching network
     * The PA resonator inductance
     * The PA resonator capacitance
     * The RF choke
   * MCU power amplifier drive PWM signal
   * The demodulator chip
   * The channel-mixing logic
   * The USB sound chip
 * Proposed test strategies for:
   * The antenna system
     * NanoVNA with attenuator for protection
     * Need a viable antenna first
   * The antenna to late stage module connection
     * Multimeter on connectivity test mode, resistance test mode
     * NanoVNA for further verification as an option
   * The power amplifier
     * Power amplifier low pass filter, matching network and resonator
       * NanoVNA between the band-specific solder bridges (fresh board, none soldered closed)
     * RF choke
       * NanoVNA between the `PA-SUPPLY` and the nearby solder bridges (fresh board, none soldered closed)
   * MCU power amplifier drive PWM signal
     * Instrument appropriately with scope then test with custom firmware 
   * MCU receive enable signal
     * Instrument appropriately with scope then test with custom firmware 
   * The demodulator chip
     * Verify configuration straps with scope
     * Verify expected input signal is present with scope
     * Verify output signal is present with scope
   * The USB sound chip
     * Verify configuration straps and/or MCU control lines
     * Verify input from demodulator and channel mixing is present
     * Monitor computer audio through regular audio software
     * Try creating static if necessary by shorting low voltage leads
     * Verify static comes through to computer audio software
 * Potential test strategies
   * For individual PA stages
     * It would be possible to isolate these by cutting traces then repeating NanoVNA tests if necessary
   * Channel mixing logic
     * If problematic, bypass entirely
 * Progress
   * Soldered fix jumper for comparator to `GND`
     * Re-verified bootup contact, programming, WSJTX
   * Altered firmware to ensure receive enable pin is set low (enabled)
   * Soldered contact pin to instrument `RXEN`
   * Instrumented `RXEN` with scope
     * Verified pin is brought high momentarily during `setup()` then set low for 'force receive enable', which should trigger audio passthru at `Q1` 

## Complete issues list

 * Cable passthru too difficult, hole should be enlarged
 * `TUSB321` PD chip incorrect topology
 * `TUSB321` PD chip missing 100uF and 100nF caps at VDD
 * `MT3608B` self-destructed for unknown reasons, maybe voltage peaks from oversized inductor, current-incapable diode
 * `MT3608B` inductor too large at 22uH, reduce to 6.8uH or 10uH.
 * `MT3608B` inductor should be low DCR.
 * `MT3608B` missing 22uF cap at VIN input (place directly across terminals)
 * `MT3608B` missing 22uF output cap at OUT
 * `MT3608B` fast-switching diode had insufficient current capacity and should be replaced with `SS34`.
 * `MT3608B` block layout is crap: large loops, unduly long traces, thin traces.
 * `SI5351B` crystal capacitance is unsuitable: *must* be 6, 8 or 10pF per AN554
 * `SI5351B` external load capacitors for crystal unnecessary per AN554
 * `SI5351B` lacks test points on clock outputs
 * PA drain traces to MOSFET too thin, which will cause issuses with the power amplifier at higher current.
 * `ATMEGA328P` analog comparator input (undocumented in original design and firmware) requires grounding.

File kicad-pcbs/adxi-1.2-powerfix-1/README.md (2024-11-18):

# adxi-1.2-powerfix-1

## Timeline

 * Conceived: 2024-11-08ish
 * Designed: 2024-11-11
 * Ordered: 2024-11-11
   * Cost: $5 for 10 pieces of 2-layer PCB + $23.57 for surface mount and components = $28.57 for 10 boards, or $2.86 each
   * Shipping: $28.58
   * Effective cost: $5 each
 * ETA: 2024-11-21
 * Received: 2024-11-17 (morning) - ie. 6 days!
 * Assembled: 2024-11-17 (evening)
   * VBUS-IN pin and 12V-OUT pins must be clipped short by around 50% as they are not through-hole and the others are
   * Other pins may require some bending/re-alignment
 * Installation: 2024-11-18 (morning)
   * Proposed process:
     1. Remove `R80` (100K) beneath `VIN-OUT` pin. This has the effect of disabling existing boost conversion stage upstream connectivity from the 12V regulator.
       * Done
     2. Remove `L226` (22uH) east of below the `VDD-OUT` pin. This has the effect of disabling boost conversion stage resonance.
       * Done
     3. Remove `U8` (MT3608B) east of below the `VBUS` pin. This has the effect of disabling boost conversion entirely.
       * Done
     4. Verify pin alignment in all cases.
       * Done
     5. Solder in place.
       * First load solder on to the two non through-hole pins, ie. `VBUS-IN` and `12V-OUT`, because the first one is beneath an undercut and the second one also has reduce accessibility.
         * Done
       * Now tack down `VBUS-IN`. Verify the connectivity with a multimeter between the `VBUS-IN` pad on the fix board and the northern (inner) pad of the ferrite bead `FB6` at the `MCU`.
         * Done
       * Solder all through-hole pins from below.
         * Done
       * Finally solder the remaining pin, `12V-OUT`, to the pad. Verify the connectivity with a multimeter between the `12V-OUT` pad on the fix board and pin 1 on the mainboard regulator `U3`.
         * Done

## Test process

### Initial power tests

Rather than plugging the board straight in to USB-C it might be worth testing the power subsystems one by one before doing so, to prevent losing the soldering and assembly work and another board.

What can be realistically tested?

First of all we can test feeding 12V from the `GND` and `12V-OUT` pins on the fix board through to the regulator and see if the other power channels come up.

We will try 0.1A 12V for a short period and instrument 12V, 5V, and 3.3V during the test. If these all come up, then we know source power pass-through is working and should be able to plug in a USB source.

First, the power supply configuration will be programmed for 0.1 seconds in the test program `debugging/powertest` which activates the PSU's channel #2 for a short period and takes a PSU screenshot under load before shutting down.

A dry run resulted in the expected output.



After hooking up channel #2 as an input to the board, the oscilloscope channels need to be connected and set to trigger with input power. 

```
$ ./powertest
DP832 PSU
 - Status: OFF
 - Version: RIGOL TECHNOLOGIES,DP832,DP8C233203778,00.01.16
 - Self test: TopBoard:PASS,BottomBoard:PASS,Fan:PASS

Turning channels off... OK
Setting up channel #1
 - Voltage: 24.000V
 - Voltage limit: 24.000V
 - Voltage limiting: ON
 - Current: 0.500A
 - Current limit: 0.500A
 - Current limiting: ON
Setting up channel #2
 - Voltage: 12.000V
 - Voltage limit: 12.000V
 - Voltage limiting: ON
 - Current: 0.100A
 - Current limit: 0.100A
 - Current limiting: ON
Setting up channel #3
 - Voltage: 5.000V
 - Voltage limit: 5.000V
 - Voltage limiting: ON
 - Current: 0.500A
 - Current limiting: ON

Triggering channel 2 (12V) for test period
 - Enable
Saved screenshot_192.168.8.3_2024-11-18T07:02:51.png
 - Disable
```

Hrrm. Well the first run didn't trigger the scope or show any draw on the PSU screenshot.



A second attempt, leaving the channel on manually for a under a second resulted in an overcurrent condition on the PSU channel.

Let's increase the current to 0.3A, which was the level in the previous test scripts, and retry with the programmatic approach.



Same thing, no output, no capture.

Let's try increasing the time to one second or so.



Aha! We can see some draw at least. I wonder why the scope didn't trigger?

I tried switching it to real time and repeated, all the scope channels did move.

After changing the scope configuration (shorter time window, reset trigger level, change trigger to omnidirectional, etc.) I retried and it worked.




Needs to zoom out, clearly, but you can see the `VIN` input from the power supply is ramping up.




Zoomed out, retried.




And again... bang! We're in business.




Here you can see all channels have ramped up, although not yet stabilised.




And finally here is the full view of all power rails from zero to stable.




The conclusion is that, as expected, after performing surgery on the original board and connecting the fix board carefully we can confirm there is still expected and correct functionality obtained in terms of power system startup when powering the 12V rail directly from the fix board's output. The total time from power input to stable operation is around seven divisions of 20ms each, or 7x20 = 140ms.
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

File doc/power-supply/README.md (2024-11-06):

# Power Supply

## Requirement

ADXI aims to support 5 watt output since this is the most common output level limitation in regulations globally affecting amateur radio operators.

Given the 5 watt output goal, the majority of power consumption is going to be in trasmit power, since the rest of the components are unlikely to consume a significant amount of power.

Therefore, we should expect rapidly changing power draw as transmit is enabled and disabled, and this will nominally peak at 5 watts.

Almost all of this power will be on the 12V power supply (noting that power supply lines are conventionally termed "rail", so "12V rail" would refer to the 12V supply line).

Although the power amplifier (PA) operates at a nominal 12V, the minor current requirements for the rest of the system are mostly measured in 5V or 3.3V.

## Design evolution
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

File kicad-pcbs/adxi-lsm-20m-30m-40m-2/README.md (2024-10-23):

# adxi-lsm-20m-30m-40m-2

## Timeline

 * Conceived: 2024-10-01 or so
 * Designed: 2024-10-01 to 2024-10-24
   * Main design challenges were re-working existing designs coming out of [classe2-calculator](https://github.com/vk2diy/classe2-calculator)
   * The rework function `--equivalent-inductor` had to be authored and debugged
   * The reworked circuits are definitely better than the originals
 * Ordered: 2024-10-24
   * Cost: $17.80 for 20 boards + $98.70 for 20 boards assembly = $116.5 / 20 = $5.825 each
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

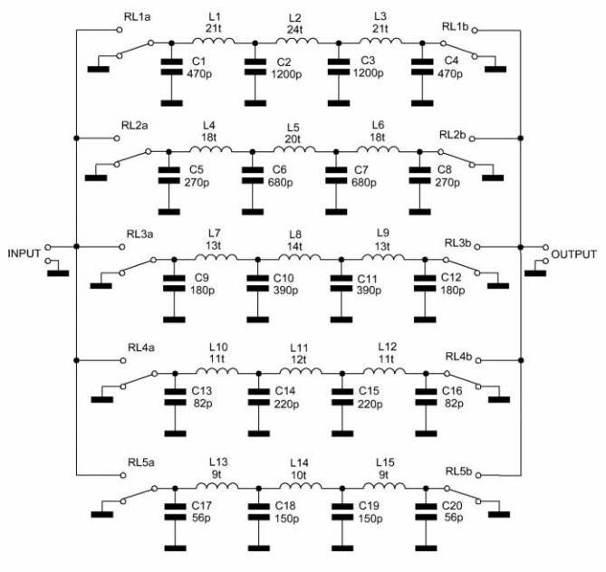
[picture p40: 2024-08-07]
doc/multi-band-lpfs/reference-lpf-design-7-f5npv.png

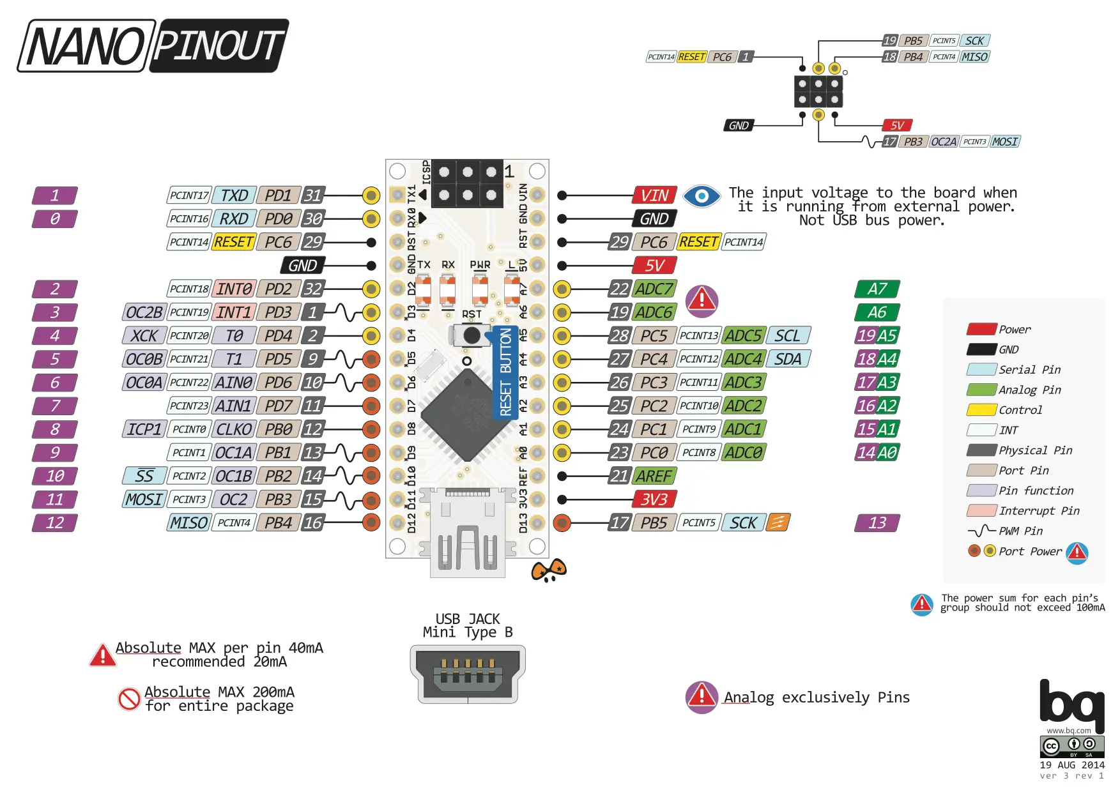
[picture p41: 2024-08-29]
doc/mcu/arduino-nano-pinout.webp

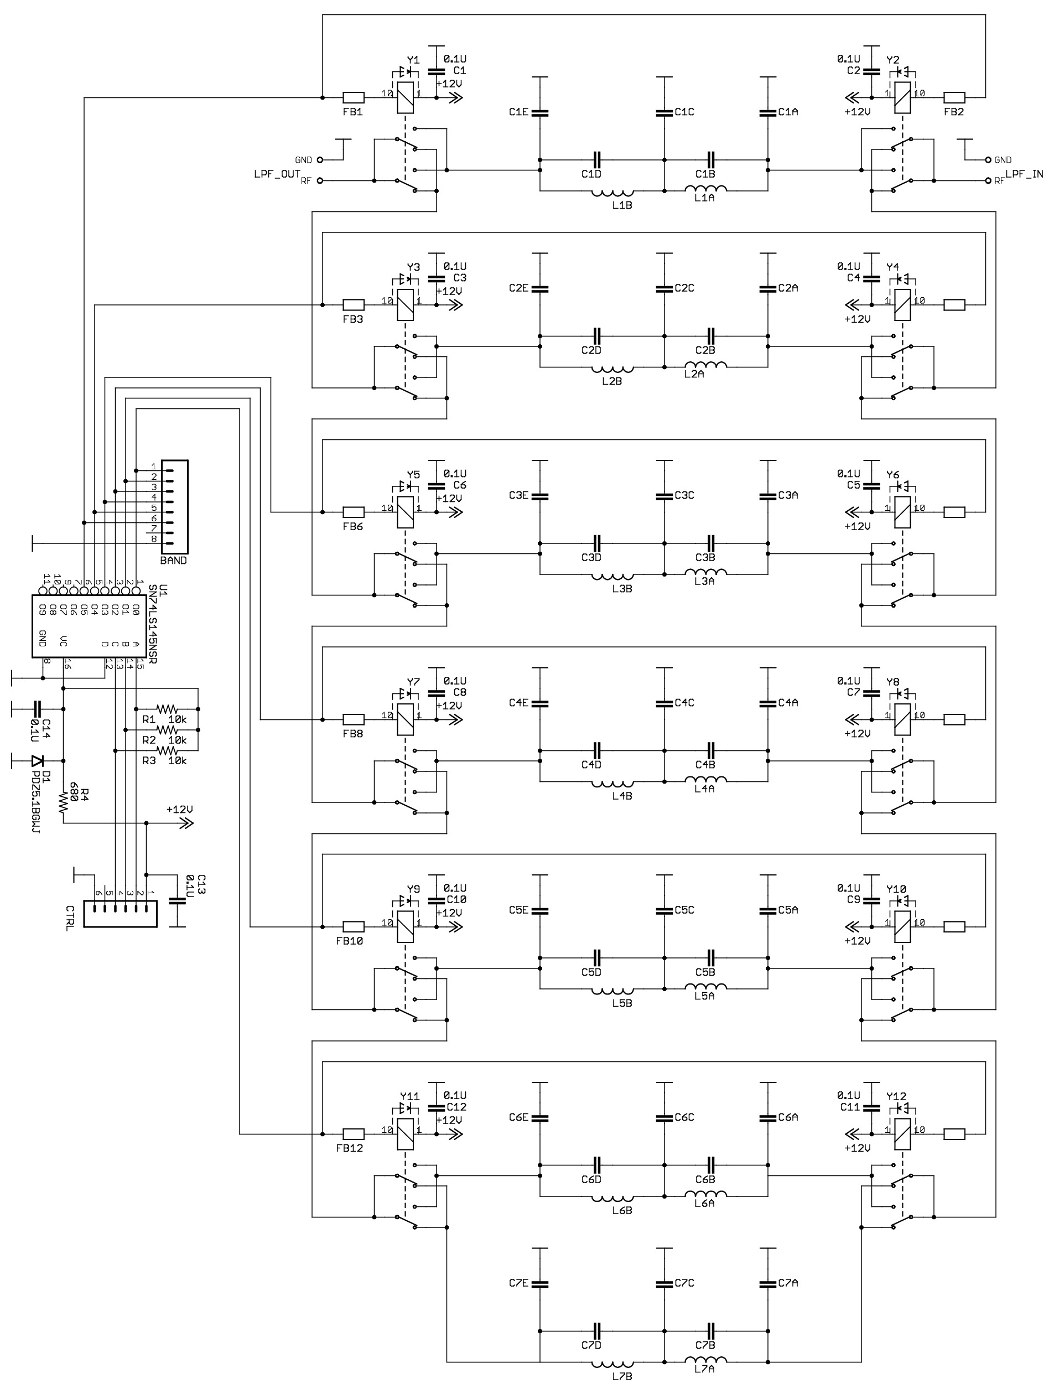
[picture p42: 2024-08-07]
doc/multi-band-lpfs/reference-lpf-design-3-rf-power-tools.png

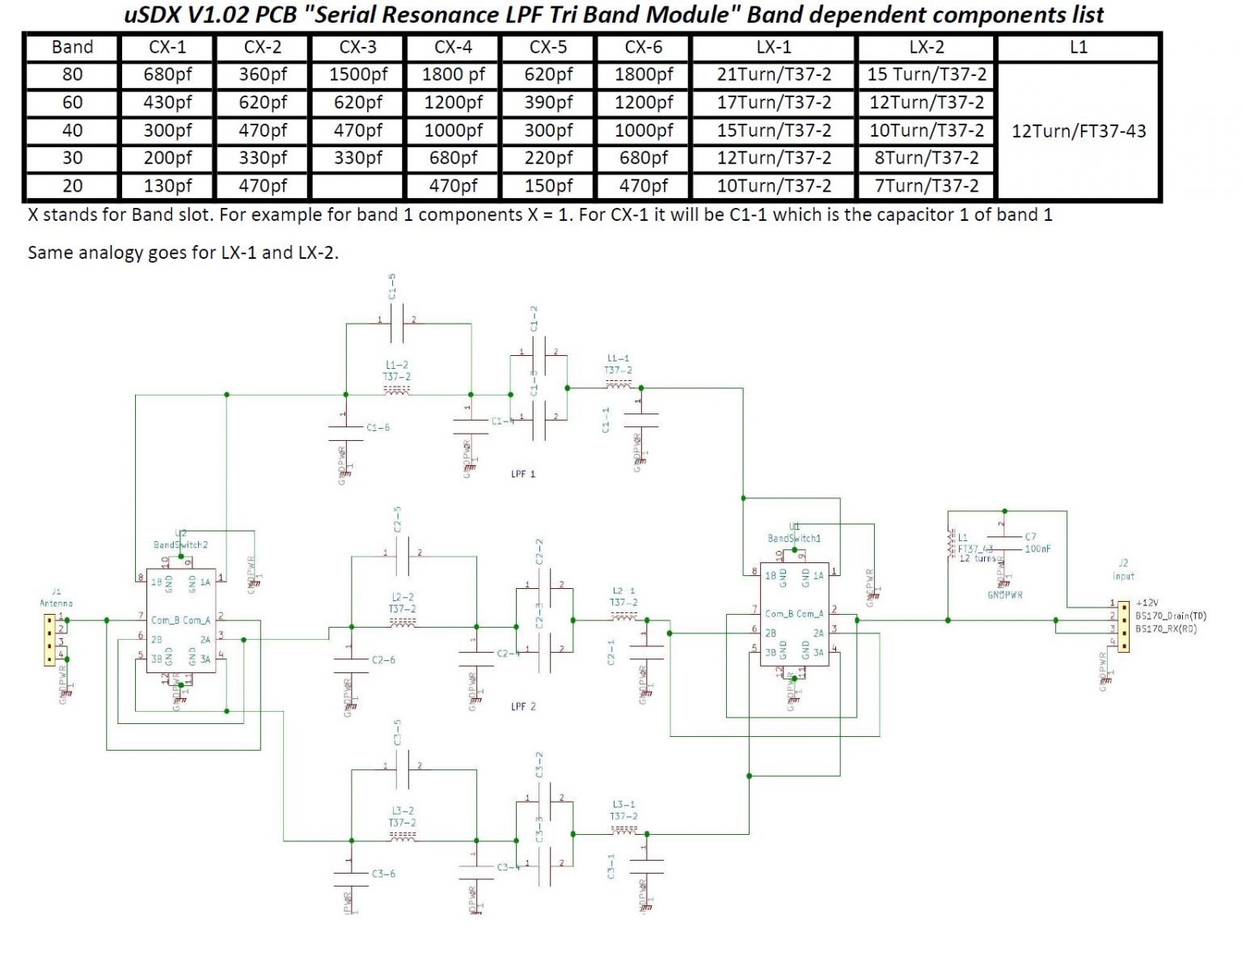
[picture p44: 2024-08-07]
doc/multi-band-lpfs/reference-lpf-design-4-usdx.jpg

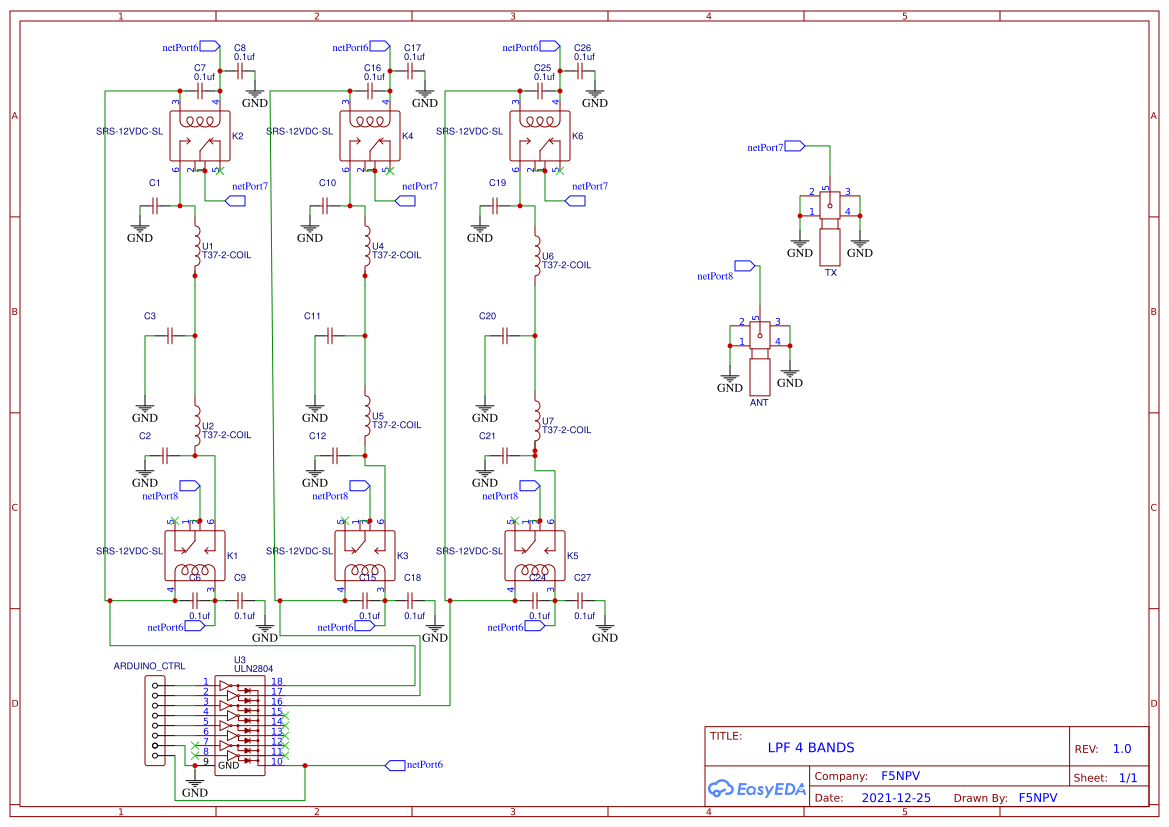
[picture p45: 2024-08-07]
doc/multi-band-lpfs/reference-lpf-design-6-f5npv.png

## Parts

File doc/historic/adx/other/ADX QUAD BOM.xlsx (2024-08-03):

Part | Designator | Footprint
100uF/16V | C1,C16,C24 | Capacitor_THT:CP_Radial_D5.0mm_P2.50mm
620pF | C11 | Capacitor_THT:C_Disc_D3.0mm_W1.6mm_P2.50mm
10nF | C12,C17 | Capacitor_THT:C_Disc_D3.0mm_W2.0mm_P2.50mm
10uF/16V | C13,C18 | Capacitor_THT:CP_Radial_D5.0mm_P2.50mm
100nF | C2,C3,C6,C8,C9,C10,C14,C15,C19,C20,C21,C22,C23 | Capacitor_THT:C_Disc_D3.0mm_W1.6mm_P2.50mm
10nF | C4,C5 | Capacitor_THT:C_Disc_D3.0mm_W1.6mm_P2.50mm
470nF | C7 | Capacitor_THT:C_Disc_D3.0mm_W1.6mm_P2.50mm
SPK | CON1 | digikey-footprints:Headphone_Jack_3.5mm_SJ1-3523N
MIC | CON2 | digikey-footprints:Headphone_Jack_3.5mm_SJ1-3523N
TX | D1 | LED_THT:LED_D3.0mm
FT8 | D2 | LED_THT:LED_D3.0mm
FT4 | D3 | LED_THT:LED_D3.0mm
JS8 | D4 | LED_THT:LED_D3.0mm
WSPR | D5 | LED_THT:LED_D3.0mm
1N4148 | D6 | Diode_THT:D_A-405_P2.54mm_Vertical_AnodeUp
1N4148 | D7,D8 | Diode_THT:D_A-405_P2.54mm_Vertical_KathodeUp
1N5817 | D9 | Diode_THT:D_A-405_P2.54mm_Vertical_KathodeUp
SMA | J1 | SMA_EDGE:SMA_Samtec_SMA-J-P-X-ST-EM1_EdgeMount
BNC | J1A1 | Connector_Coaxial:BNC_Amphenol_B6252HB-NPP3G-50_Horizontal
PJ-102A | J2 | digikey-footprints:Barrel_Jack_5.5mmODx2.1mmID_PJ-102A
1uH | L1 | Inductor_THT:L_Toroid_Vertical_L10.0mm_W5.0mm_P5.08mm
100uH | L2 | Resistor_THT:R_Axial_DIN0204_L3.6mm_D1.6mm_P2.54mm_Vertical
BS170 | Q1,Q2,Q3 | Package_TO_SOT_THT:TO-92_HandSolder
BS170 | Q4 | Package_TO_SOT_THT:TO-92L_HandSolder
1M | R1 | Resistor_THT:R_Axial_DIN0204_L3.6mm_D1.6mm_P1.90mm_Vertical
2.7k | R12 | Resistor_THT:R_Axial_DIN0204_L3.6mm_D1.6mm_P1.90mm_Vertical
100 | R14 | Resistor_THT:R_Axial_DIN0204_L3.6mm_D1.6mm_P1.90mm_Vertical
4.7k | R2 | Resistor_THT:R_Axial_DIN0204_L3.6mm_D1.6mm_P1.90mm_Vertical
10k | R3,R4,R10,R11,R15 | Resistor_THT:R_Axial_DIN0204_L3.6mm_D1.6mm_P1.90mm_Vertical
1k | R5,R6,R7,R8,R9,R13 | Resistor_THT:R_Axial_DIN0204_L3.6mm_D1.6mm_P1.90mm_Vertical
UP(BAND) | SW1 | Button_Switch_THT:SW_PUSH_6mm
DOWN(CAL) | SW2 | Button_Switch_THT:SW_PUSH_6mm
TX | SW3 | Button_Switch_THT:SW_PUSH_6mm
CD2003GB_GP | U1 | Package_DIP:DIP-16_W7.62mm_Socket_LongPads
SI5351_Module | U2 | VFO_footprint:SI5351 Module_Vertical
74ACT244 | U3 | Package_DIP:DIP-20_W7.62mm_LongPads
uSDX_LPF_BAND_MODULE | U4 | uSDX_LPF_BAND_MODULE:uSDX_mOnO LPF_Band_Module
Arduino_Nano_Socket | XA1 | Arduino:Arduino_Nano

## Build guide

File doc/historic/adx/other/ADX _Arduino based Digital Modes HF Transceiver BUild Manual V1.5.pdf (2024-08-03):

## ADX – An Arduino based HF Digital Modes Transceiver

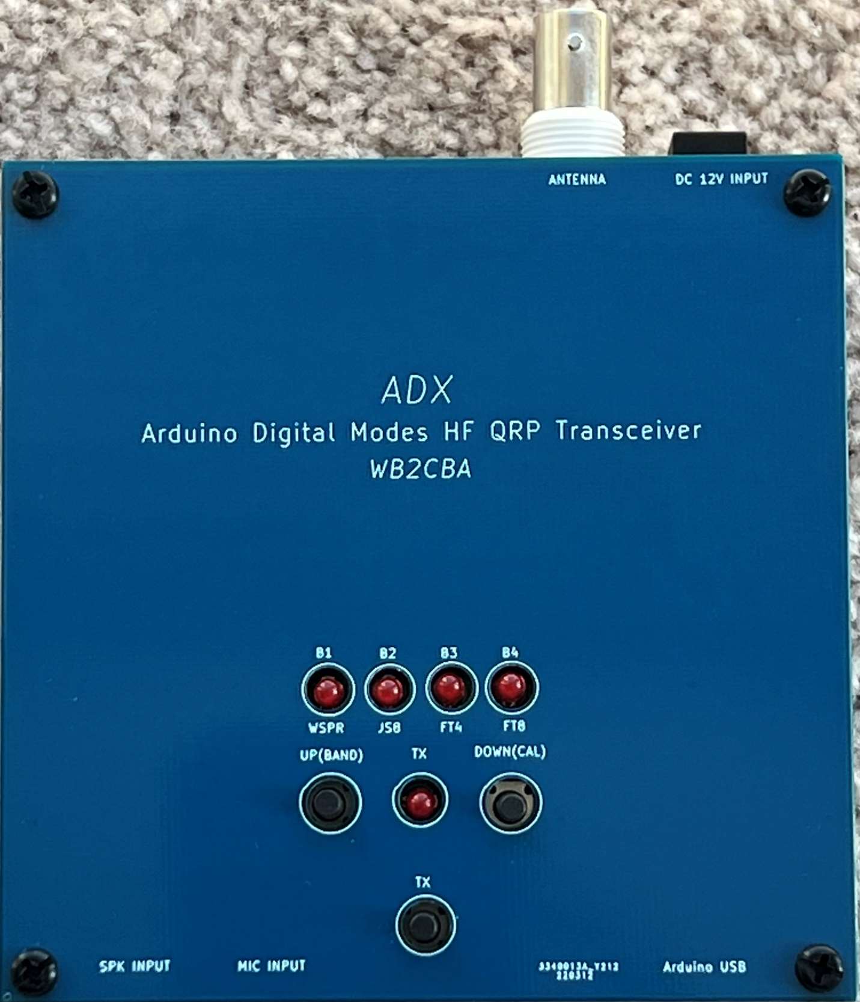
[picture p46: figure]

## Build Manual V1.5

## UPDATE:

- Calibration Procedure Change.
- Caution Note on SI5351 Library.
- ZENER DIODE PA MOSFET PROTECTION.
- CAT Control Functionality added. Changing CAT baud rate to 9600 bps as hamlib has problems with 115200 bps for TS2000.
- FSK TX code improved to perform under 500 Hz audio TX.
- ADX_CAT_VX.X Firmware
- SI5351 Module Pull UP Resistor FIX
ADX is an Arduino based Digital Modes Transceiver. ADX is abbreviation for Arduino Digital Xceiver. So where does thing come from?

When QRP labs released QDX Transceiver for Digital Modes I watched with fascination Hans Summers’s youtube video explaining details of QDX. For me QDX is the perfect optimized Transceiver for digital modes. Inspired by QDX I decided to put together my own!
Of course I wasn’t Hans Summers and QRP Labs so no way I had all that programming and RF skills to create something as sophisticated as QDX so I cheated and settled for something super stripped and simple! I christened it as ADX. It has an Arduino which justifies “A” and it is for digital modes so a “D” and it is a transceiver so it is a “X”! ADX fit that purpose for naming

convention quite nicely!
ADX is a mono band (actually quad band) digital modes optimized HF transceiver that can cover four pre-programmed bands one band at a time! More on that later. It can work on 80m,40m,30m,20m, 17m, 15m and 10m bands and also covers four of the most popular digital modes, FT8, FT4, JS8call and WSPR. I thought about using SA612 though this CD2003GP IC gave much better sensitivity results as it has a RF preamplifier section and it is dirt cheap and readily available from every online Chinese marketing site!
My goal with this project is to design a simple HF QRP Transceiver optimized for Digital modes:
- Simple to procure – meaning not effected by chip shortage
- Simple to build – 2 modules, 2 IC’s and 4 Mosfets!
- Simple to setup and tune – One simple calibration procedure is all needed.

- Simple to operate – Plug in ADX MIC to soundcard MIC input and ADX SPK to PC soundcard speaker input and we are good to go with any digital modes Software.
- Dirt Cheap – Costs less than 25$ to get all parts and PCB if we exclude ridiculous shipping costs! ADX Building Blocks:

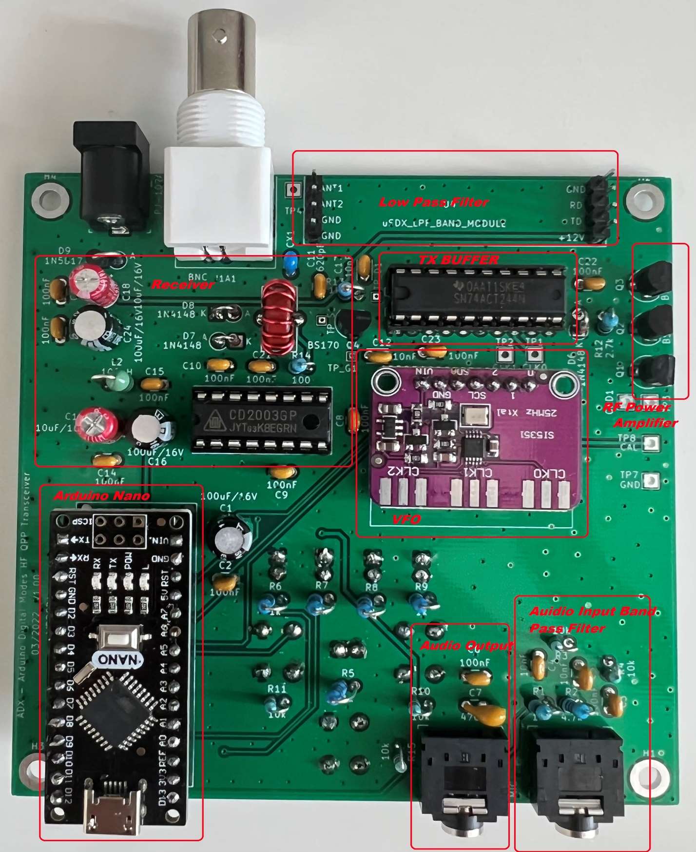
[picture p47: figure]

Building blocks of ADX Transceiver:
- Brain of ADX is an Arduino Nano which takes care of signal generation from audio tones of digital modes, user interface and calibration of SI5351 Module. ADX uses direct FSK Signal generating method similar to QDX or QRPGUYS Digital Transceiver III.
- Audio interface consists of a Speaker input from PC sound card which is actually an input to Arduino nano analog comparator for tone frequency detection and sampling. Before inputting signal to analog comparator of Arduino it passes through a band pass filter which has an audio band pass frequency range of 500 Hz to 3500 Hz.

This input acts like a VOX so no need for any PTT or serial PTT CAT input. When ADX hears a tone from for example WSJT/X audio output it starts transmitting. And when the tone of digital mode stops it stops TX. It’s that simple. The AFP-FSK (Audio frequency processed Frequency shift keying) technique used in ADX is developed by Burkhard Kainka(DK7JD) - http://elektronik-labor.de/HF/SDRtxFSK2.html

So how does this actually work?
Any digital tonal mode consists of varying audio tones that change frequency in relation to the data they correlate to. This audio tone generated for example for FT8 with WSJT/X software is passed through an audio band pass filter and then it is compared with Arduino Nano’s Atmega328P processor A/D comparator for start and stop zero cross detection to determine period of that tone. From that period, frequency of that particular tone that is determined and added to base transmit frequency, for example 14074000 Hz for 20m FT8. If the tone let’s say is 1000 Hz then the carrier TX is now 14074000 Hz + 1000 Hz = 14075000 Hz.
As it is summed it will be in USB frequency range of any SSB receiver though the signal is not pure SSB signal still any SSB TRX set to USB can’t tell the difference! This tone frequency detection and adding to base frequency is continuously repeated 400 times per second and refreshed until the FT8 tone transmission generation is over. In that case TX stops.
What fascinates me about this FSK signal generation technique is to generate a signal that is received in USB without any SSB mixing or filtering which eliminates problems of IMD or phase differences etc that comes with SSB signal generation technique which allows such a simple Transceiver to be conceived with minimal parts.
- VFO: VFO is a classic cheap SI5351 Module from Aliexpress or any other site similar to that. VFO generates CLK0 TX signal, CLK1 RX signal and CLK2 calibration signal. No need to modify SI5351 Module as we did in uSDX rig builds. SI5351 module works in a cozy 400khz I2C speed.
- TX BUFFER: TX buffer is an inverting 74ACT244 octal buffer connected in parallel to drive Class E RF power amplifier consisting of 3 x BS170 mosfets. RF power output -varies from band to band - around 5 watts.
- Low Pass Filter Module is a serial resonance class E LPF filter similar to that one used in uSDX designs.
- RECEIVER is CD2003GP – A Chinese clone of Toshiba’s TA2003GP AM/FM radio IC. Only AM section is used as a direct conversion receiver.
- And some caps for RF and VCC filtering etc.
- 5 LEDs and three tactile pushbutton switches for user visual interface and controls. No fancy displays or rotary encoders!
- Now we have CAT support!

Here is ADX Schematics:

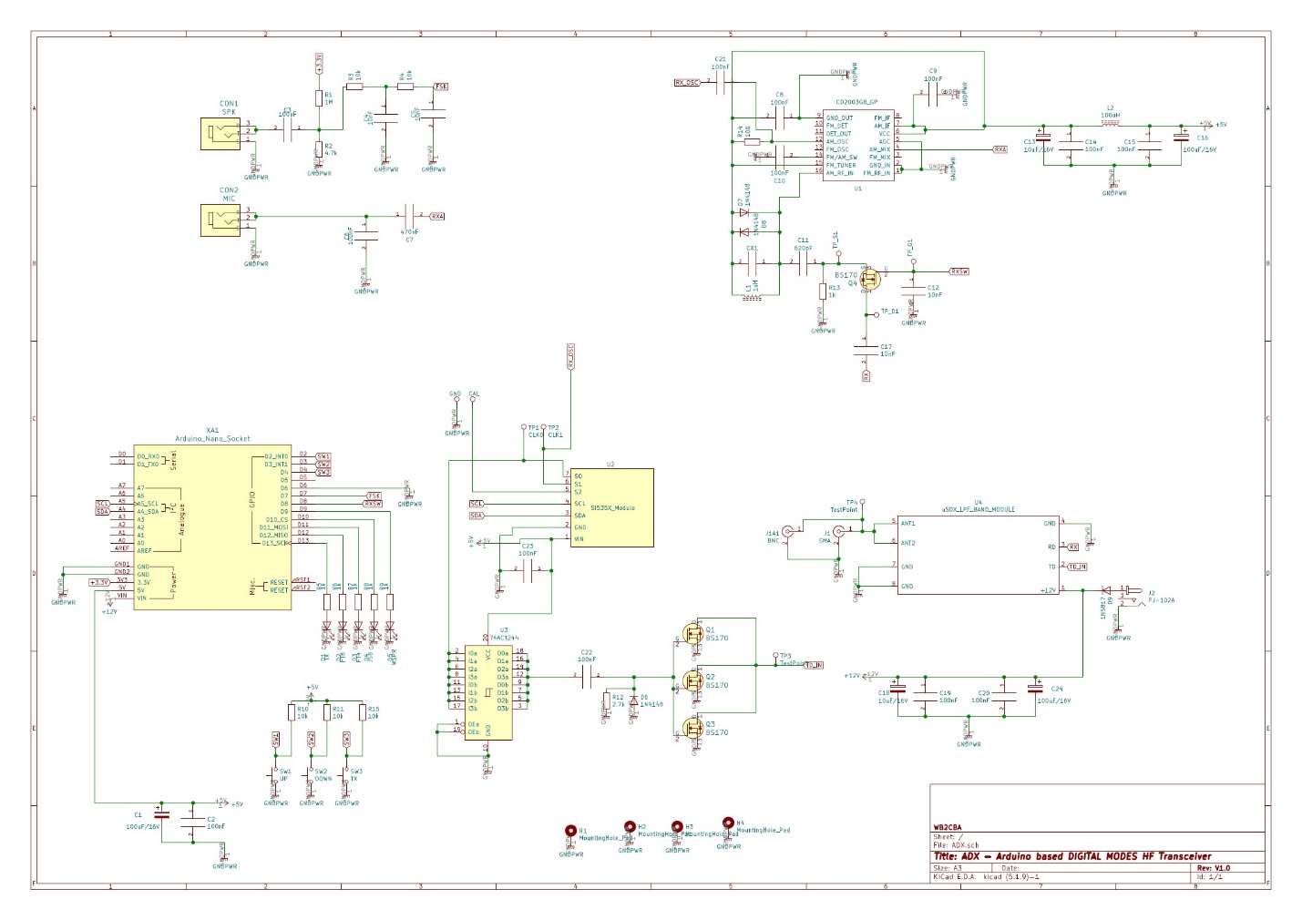
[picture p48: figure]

Here is ADX PCB layouts:

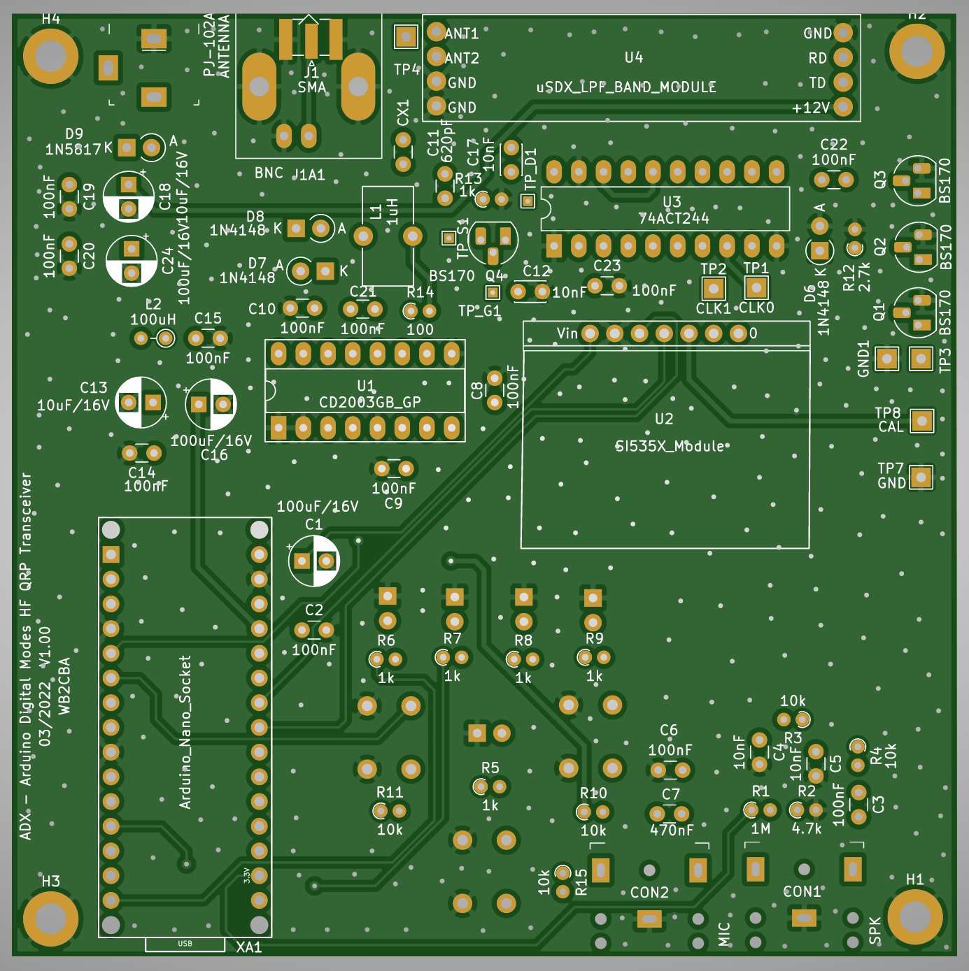
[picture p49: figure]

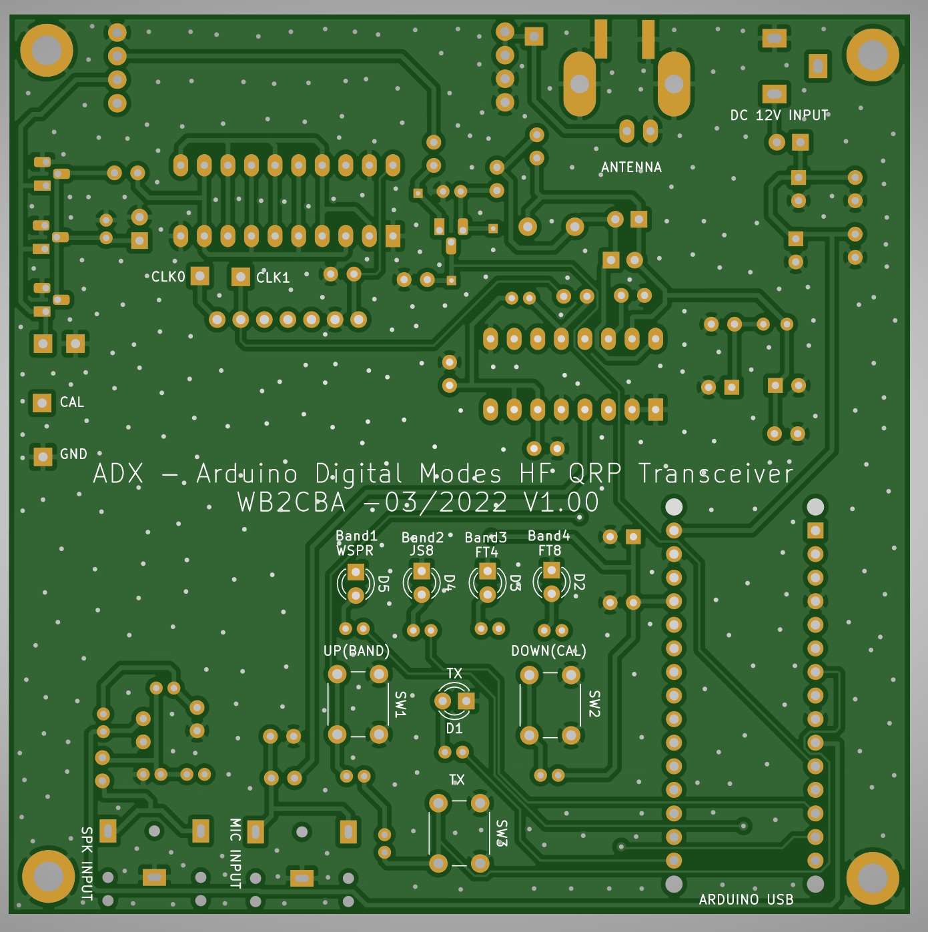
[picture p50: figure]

These are Top and Bottom Panels to give a professional rig appearance to ADX !

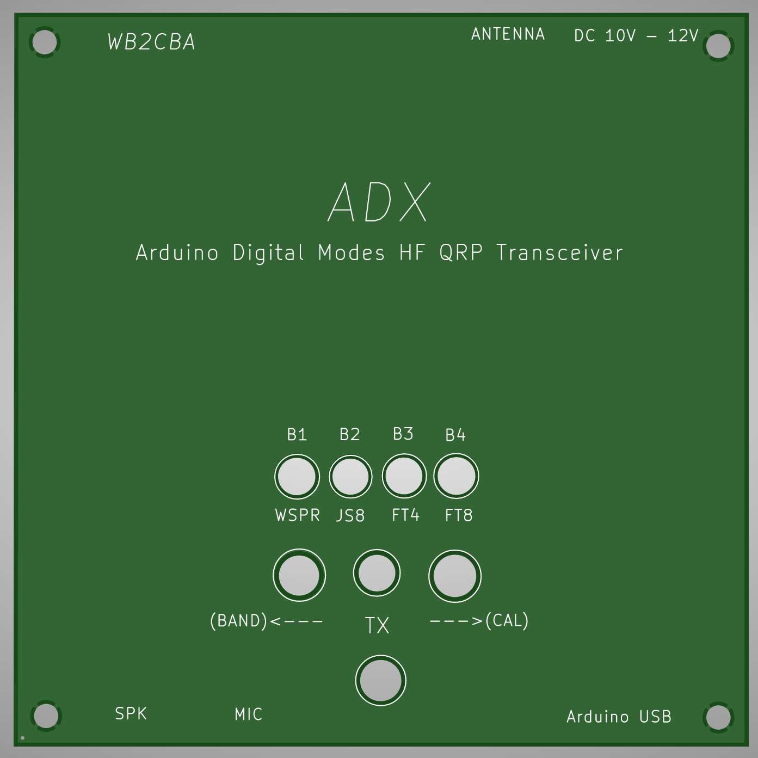
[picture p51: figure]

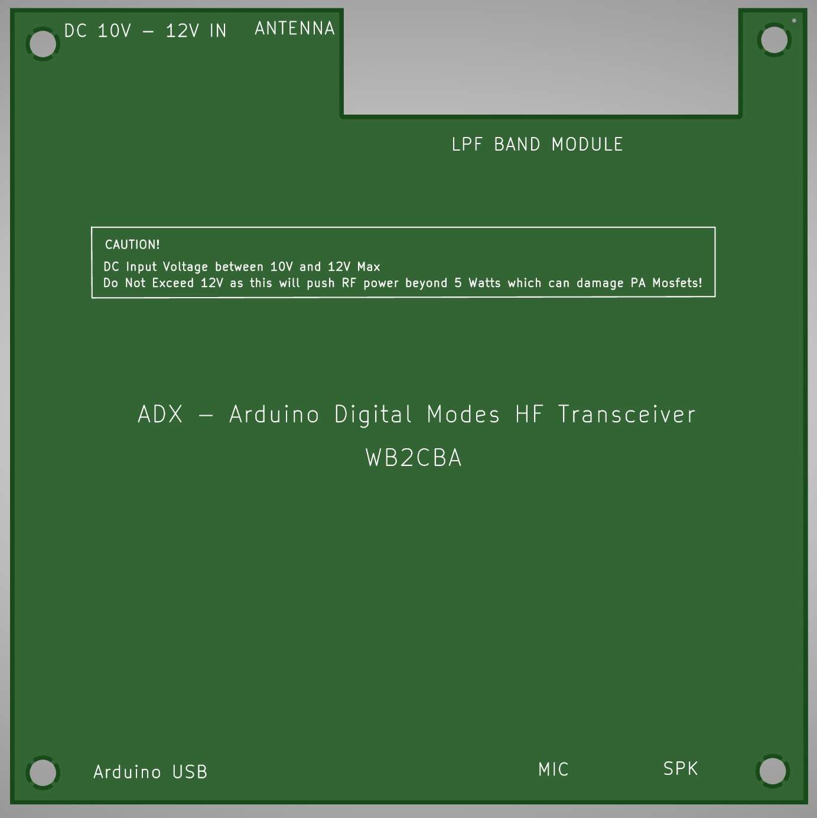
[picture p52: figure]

ADX Top Panel with LPF carrier slots:
I even designed a top panel with LPF carrier slots so that extra 3 band LPFs can be carried on top of ADX transceiver! How crazy is that!

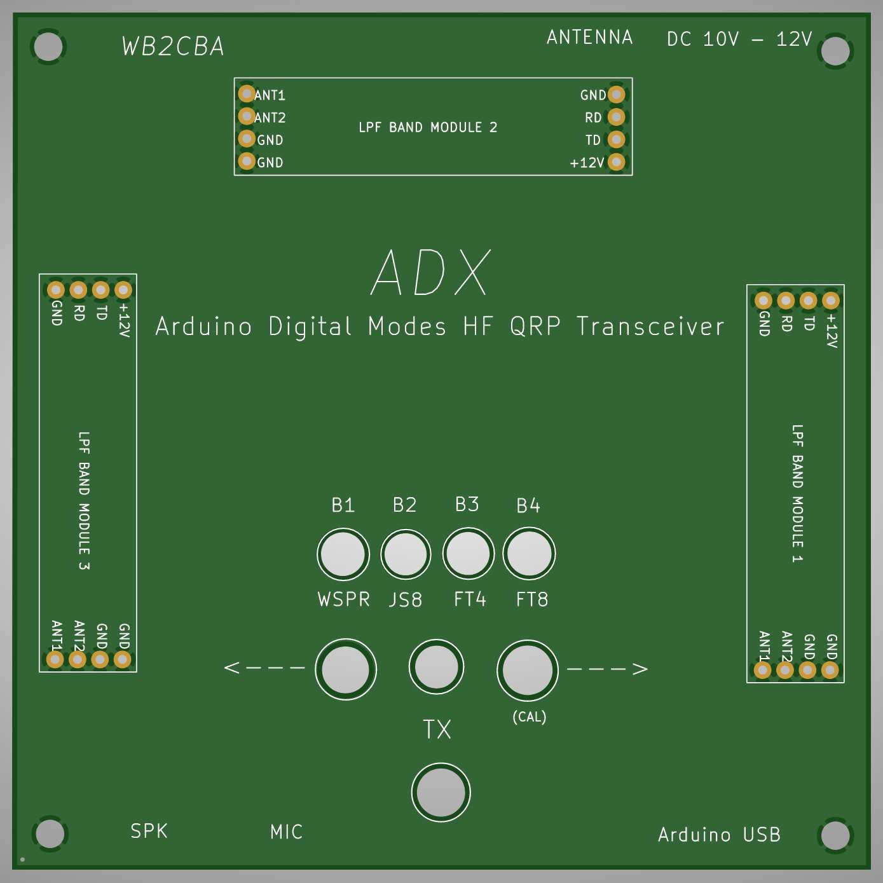
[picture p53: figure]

## 1- Building ADX:

Building ADX is simple and straight forward. All the files including Gerbers for PCBs and ADX firmware can be found in my GITHUB page on this link:
https://github.com/WB2CBA/ADX
Here is list of essential files in ADX Github page:
- ADX PCB gerber File
- ADX TOP panel Gerber File
- ADX BOTTOM panel Gerber File
- uSDX mOnO LPF Band Module Gerber File
- ADX Arduino Firmware
- SI5351 Library
- ADX User Build Guide - which is this write up
- ADX band dependent LPF Component Selection Excel sheet
- ADX BOM(Bill Of Materials) Excel Sheet
- The first step is to download all these files from ADX Github page.
- Now we need to order PCBs( Printed Circuit Board) for ADX :
The easiest way is to order from a Chinese PCB house online. I generally use www.jlcpcb.com . JLCPCB’s production is good quality , relatively cheap compared to quality and fast though shipping might be pricey if DHL is chosen to be faster. A cheaper shipping method is via snail mail which is regular post service though it is much slower.
To order a PCB first create an account with JLCPCB and upload supplied GERBER files in github page. There are videos on youtube how to upload and order PCBs from any of these online PCB houses. I strongly recommend to watch those if you haven’t ordered a pcb before.
- BOM excel sheet has all parts used in ADX. Parts used in ADX are not critical and not effected by part shortage as of writing of this article!
- Now if all parts and PCBs are gathered it is time to solder main pcb. I generally start with resistors and then capacitors. Then MOSFETS and LEDs and tactile switches. Don’t make an error, LEDs and switches are soldered on solder side of PCB!

- When soldering LEDs first solder switches. Then adjust LEDs so that top of each LED is flush with the top of switch lever. This way LEDs can stick their head nicely out of the top panel holes. Tactile Switches should be 6 mm lever ones.
- Now we can solder IC sockets and Arduino headers. I strongly recommend to use headers for Arduino nano. This way if something is not right it will be easy to replace nano. Same goes for IC’s.
- You can solder SI5351 module straight on to the pcb.
- The last items to solder are BNC, Power socket, Audio jack connectors and LPF headers.
- CX-1 is an optional capacitor for single band build giving a better band pass capacity. I added for experimental purposes. Not needed for the time being. Leave it blank.
- LX-1 is 1uH inductor made up of T37-2 toroid with 16 turns of 0.40 mm (AWG 26) enameled copper wire. Also a fixed 1uH inductor can be used.

This will complete main ADX PCB Build.

Now it is time to build LPF Band Filter Modules!

To use full four band capability of ADX Transceiver you need to choose four bands among 7 bands ADX supports.

These bands are 80m/3.5Mhz, 40m/7Mhz, 30m/10Mhz, 20m/14Mhz, 17m/18Mhz, 15m/21 Mhz and 10m/28Mhz.

Now for the chosen four bands four LPF band Modules needs to be assembled! By switching these 4 band LPF modules 4 different bands to operate can be covered.

2- ADX Band specific LPF(Low Pass Filter) BAND Modules:
ADX Transceiver uses Serial Resonance Low pass filter modules for each band it operates. For each band we choose to operate on we need to build a Band LPF Filter Module. We will swap these modules for the band we will operate on. Let’s say we want to operate FT8 on 40m/7Mhz band. Then we will grab and plug in 40m/7Mhz Band Module and select that band on ADX and Voila! Now we can operate ADX on 40m/7Mhz. Same applies to other bands. Although ADX is a mono band transceiver these plug in band modules gives it a multiband capability and flexibility.
ADX uses same LPF band module PCB of my uSDX mOnO transceiver. This way I didn’t have to design a new module. Lazy!
LPF band module PCB’s can be ordered by using GERBER file for uSDX mOnOLPF band Module. These Band filter modules can be built either using surface mount device (SMD)capacitors or through hole device(THD) capacitors.
Capacitor footprint on band module pcb allows to use 0805 or 1206 footprint standard SMD(Surface Mount Device) capacitors or 2.54 mm lead spacing THD(through hole) capacitors.
Toroids used are:
1x FT37-43
2 x T37-2 Red toroid or T37-6 Yellow toroid depending on band selection for each band module. Up to 20m/14Mhz band T37-2 toroids work pretty good. From 17m/18Mhz band to 15m/28Mhz band T37-6 yellow toroids are used.
Here is a photo of Band filter module built using THD(Through hole Device) capacitors:

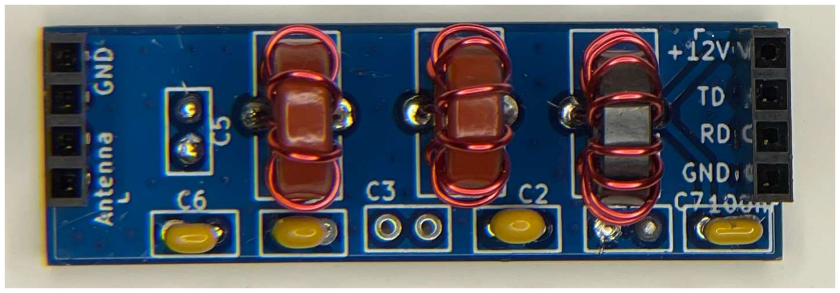
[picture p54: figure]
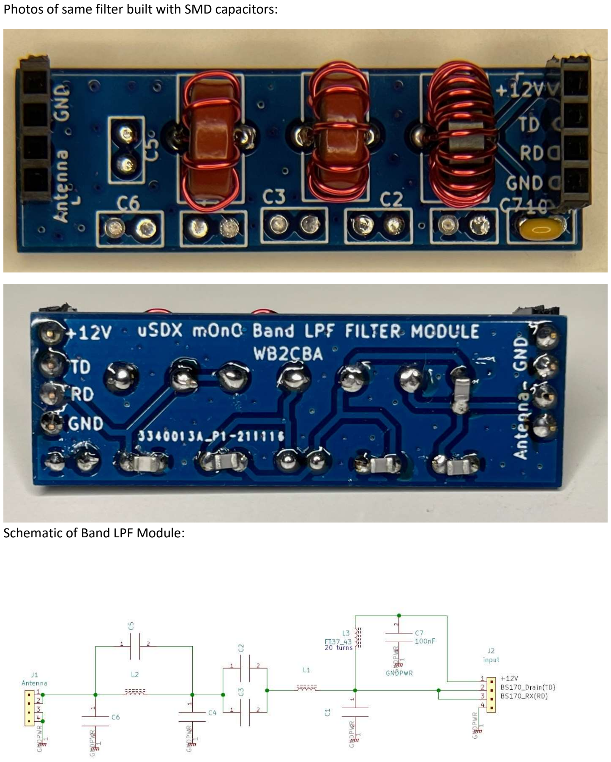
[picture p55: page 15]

Photos of same filter built with SMD capacitors:

Schematic of Band LPF Module:

BOM for LPF Band Module:
2 x 4 pin header – These headers can be male or female headers depending on what is soldered on RF board. These band module headers should the opposite mate of RF board 4 pin headers. i.e if we used male 4 pin headers on RF board then Band modules must have female 4 pin headers to plug in and vice versa.

### 1 x C1 – Band Dependent THD or 0805 NPO 100V or more Capacitor

### 1 x C2 – Band Dependent THD or 0805 NPO 100V or more Capacitor

### 1 x C3 – Band Dependent THD or 0805 NPO 100V or more Capacitor

### 1 x C4 – Band Dependent THD or 0805 NPO 100V or more Capacitor

### 1 x C5 – Band Dependent THD or 0805 NPO 100V or more Capacitor

### 1 x C6 – Band Dependent THD or 0805 NPO 100V or more Capacitor

### 1 x C7 – 100 nF THD or 0805 Capacitor (Non band dependent capacitor)

### 1 x L1 – T37-2 RED or T37-6 YELLOW toroid - Band dependent

### 1 x L2 – T37-2 RED or T37-6 YELLOW toroid - Band dependent

1 x L3 – FT37-43 Ferrite Toroid – 20 turns. Non band dependent and same detail applies to all band LPF Modules.
AWG 26 or 0.40 mm enameled copper wire can be used for Toroid turns.
So how are we going to know which capacitor values for each band required and what Toroid to be used for L1, L2 and L3 and turn for each band?
This table will help us choosing all band dependent component values and details for each band. Beware that these values are a bit differing from uSDX mOnO band module values, they are optimized for ADX Transceiver.

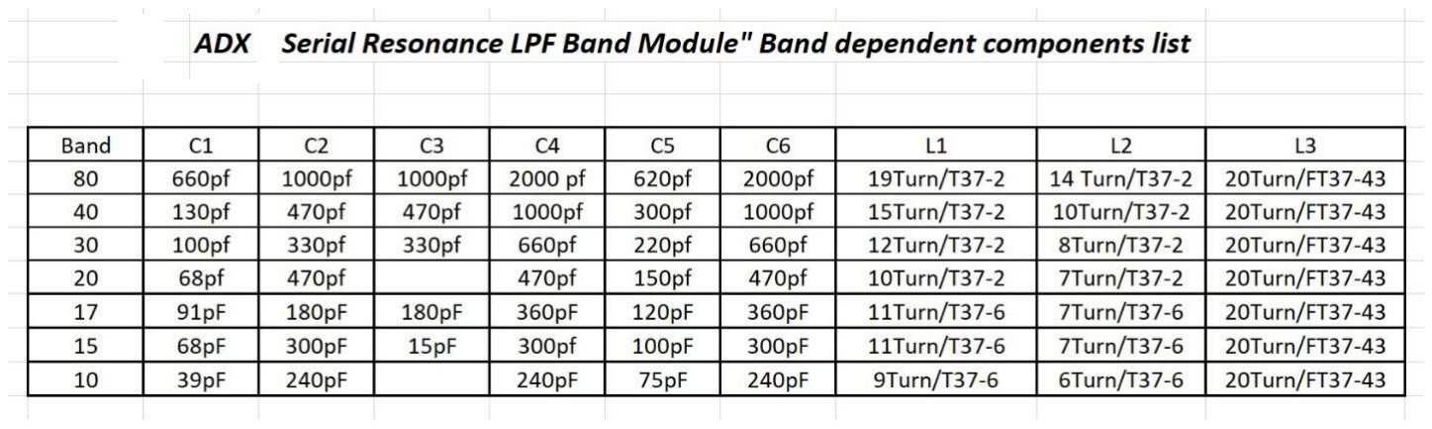
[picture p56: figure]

This table is a base for building various band LPF modules. If you have a knack to experiment and need a bit more power here are some useful tips:

1- Lower one turn from L1 in each band. This will slightly increase RF output power though might increase TX current too so exercise caution!
2- For L3 12 turns also works pretty good so this can be a nice option to play with.
Though caution here! DO NOT EXCEED 5 WATTS RF POWER! Otherwise BS170 voltage limit will be exceeded which will end up in magic smoke!

CLASS E RF POWER AMPLIFIER BASICS and Some useful tinkering knowledge:
ADX Transceiver uses Class E type RF power amplifier scheme. Class E is an efficient class of power amplifier which can go up to 85 to 90 % efficiency which means less thermal heat dissipation on RF power transistors and lower supply current vs more RF power output. These are the advantages of Class E RF amplifiers. Disadvantage of this amplifier type is it is harder to tune and get the required efficiency when compared to other classes like Class A,B or C amplifiers. ADX uses this efficient class E amplifier like uSDX transceiver. 3 x BS170 mosfet transistors parallel when tuned properly can easily give up to 5 watts RF output power without dissipating any excess heat under 12V DC.
uSDX mOnO LPF band filter board consists of all parts related to fine tune ADX Class E mosfet Power amplifier. Above table has component values of each LPF Band Filter which will give a reasonable power efficiency on all 6 bands covered. Efficiency values for each band can be further tweaked and it is a great way to learn and experiment with class E amplifiers. ADX uses so called serial resonance LPF design for Class E and all values are calculated by WA0ITP’s excellent excel Class E design spreadsheet: http://www.wa0itp.com/class%20e%20design.html
Here are some class E readouts for curious ADX kit Builders: http://www.norcalqrp.org/files/Class_E_Amplifiers.pdfhttps://people.physics.anu.edu.au/~dxt103/class-e

TIPS on TOROID Winding:

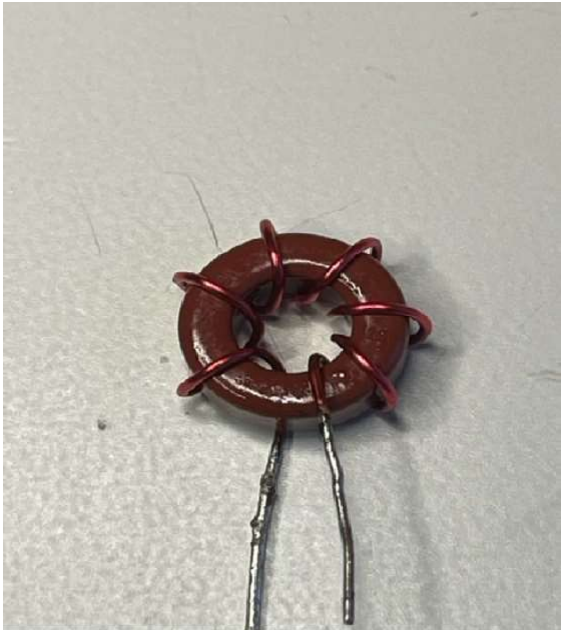
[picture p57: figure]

This is T37-2 RED Toroid with 7 turns of enameled copper wire.

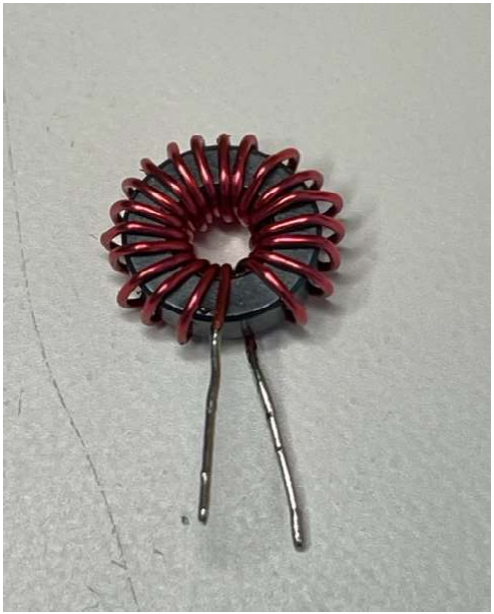
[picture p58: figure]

This is FT37-43 L3 Toroid with 20 turns of enameled copper wire.

One important point to consider is that the edges of FT37-43 Toroids are quite sharp which can scrape enamel coating on inductor wire. To fix this issue the easiest method is tapering the edge a little with an oversized drill bit. Use the oversized drill bit to turn with your fingers inside the toroid ring to smoothen out sharp edges. Do not use a drill to turn the drill bit! You will snap the toroid and most importantly will harm your fingers in the process!

3- One turn means enameled copper wire passes once inside the toroid ring. For example, in 7 turns T37-2 toroid in the above photo wire passes 7 times inside the ring.
4- Always after passing the turn stretch the wire so it is tightly wound around the toroid.
5- When all turns are in count carefully every turn that passes through the inner ring of toroid. The best method to do is to take a close up photo of the toroid and count the turns. This way it is easier to see turns and you won’t miss a turn.
6- Never ever let one turn go over another one. Every turn should be side by side! This is important in toroids that have 20 or more turns and it is easy to overlap turns.
7- Always scrape ends of toroids to clean enamel coating for soldering. To clean enamel coating there are two methods which can be used separately or together.
Scraping enamel coating with a cutter knife thoroughly and then apply a bit solder coating. Second method is to heat up wire with soldering iron so that enamel coating just burns out and then cover with a solder coating. Scraping first and then burning the residue enamel coating is the best approach! Then apply a bit solder coating before soldering toroid into pcb.
8- Before soldering wound toroid try to spread as even as possible as in the photos above.
9- After soldering toroid in its place check with a continuity tester if solder joints are okay and connected electrically.

ADX CLASS E RF POWER AMPLIFIER MOSFET HIGH SWR PROTECTION and SI5351 Pull Up resistors Fix: While experimenting with ADX transceiver I smoked out BS170 mosfet many times due to high SWR or operating without antenna!
So I tinkered to find a way to prevent MOSFET demise in case of bad or excessive SWR! And thankfully there is a very simple solution to prevent just that! A 47Volt 1 Watt zener diode is all needed and works like charm! The beauty of this zener protection is even without antenna no harm will be done to PA Mosfets!

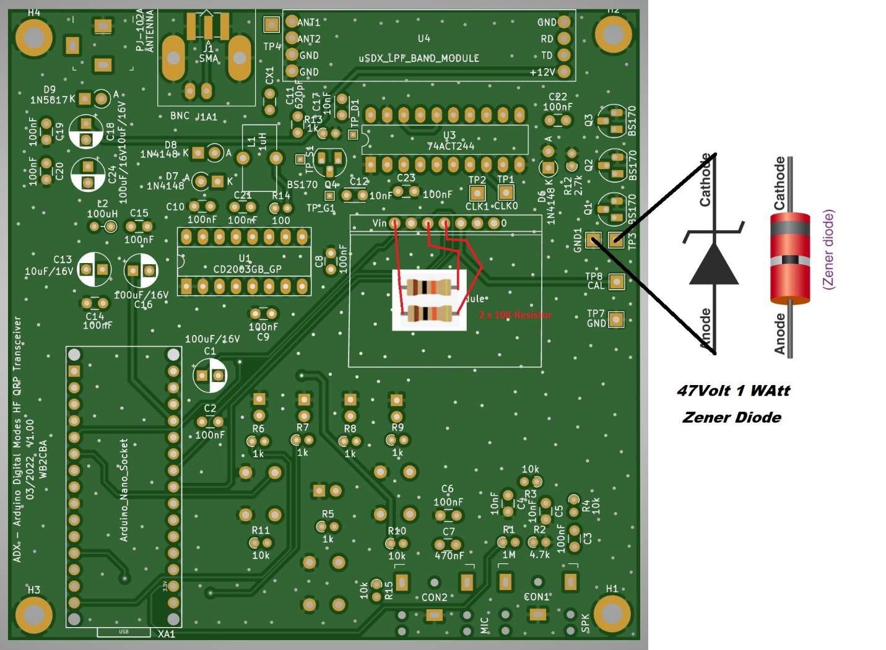
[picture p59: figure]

Solder 47V / 1 Watt zener diode as shown in the photo above between TP3 and GND solder points in ADX PCB. Cathode of Zener Diode goes to TP3 test point and Anode of zener diode goes to GND1 test point. Zener diode can be any zener diode with 47V and 1 Watt rating. I used 1N4756 from On semiconductor. The other option can be BZX85C47 zener.
This will protect your PA mosfets from accidental smoke out! I strongly recommend to add this zener to your ADX pcb.
Here is my test video on youtube with another variant of ADX called ADX UnO which identical to ADX but with smd components:
https://youtu.be/7hUmkE84kfA

SI5351 Modules are coming in various qualities and they are not identical sadly. Some of these modules don’t have I2C pull up resistors on them. If there is no pull up resistor then Arduino can’t address I2C ports SDA and SCL as they are open collector and needs to be pulled up by 10k resistors. If you are experiencing SI5351 related no signal generation fault it will be a good idea to add those two 10k resistors as shown in the photo above to cure that problem.
ADX FIRMWARE:
ADX firmware is developed in Arduino C language and Arduino IDE can be used for visualization and experimenting with it.
ADX uses Arduino Nano board as microcontroller. This is a readily available and cheap Arduino development board that can be outsourced easily online.
The current version is updated to ADX CAT VX.X. X.X stands for version number. This will change as new features will be added. I will continue working on firmware in the future so this version number can increase with new features. So check out occasionally ADX Github site for an update! New features are listed at the first page of this manual in bold.
SI5351 needs an Arduino library to work with. This library is Jason Mildrum, NT7S’s SI5351 library with Version 2.1.3, Si5351Arduino-master.zip .
DO NOT USE Jason Mildrum NT7S’s latest version of SI5351 library from his github site as it is not compatible anymore with ADX firmware. Use SI5351 Library that is in ADX Github firmware page to avoid any I2C communication problems. ADX is using version 2.1.3 of NT7S SI5351 Library.
Install this library as you install any arduino library. Using Sketch/Include Library/Add .ZIP Library menu. Just select the above .zip file and it installs. Do not unzip the file!

ADX_CAT_VX.X.ino is the ADX firmware file and can be downloaded from ADX github page: https://github.com/WB2CBA/ADX
Before we upload ADX firmware we need to setup band assignment in the firmware for our needs! Which is assigning four preferred bands we plan to operate on. If default band assignment of Band 1 = 40m, Band 2 = 30m , band 3 = 20m and Band 4 = 17m is preferred band setup then skip this step.

This is the band assign code lines from ADX firmware which needs to tailored for our preference:

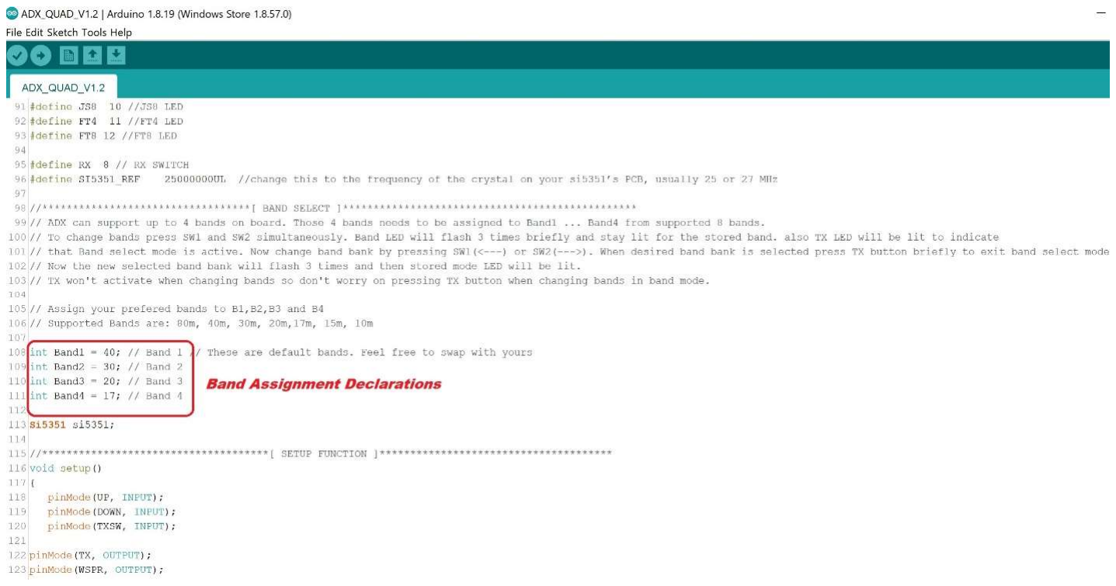
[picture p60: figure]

Assign your own preferred bands to those locations in the firmware which is inside the red rectangle above. My preferred bands are 40m for Band1, 30m for Band2, 20m for Band3 and 17m for Band4.
After this band assignment we can compile and upload ADX firmware to Arduino Nano as uploading to any Arduino board. Nothing special here.
First Power up and smoke test!
After firmware upload we are ready for first smoke test! Do not install LPF Band module at this time. Connect 12V DC power source.
DO NOT USE More than 12V DC for ADX Transceiver as this pushes RF power output beyond 5 Watts and over 60V which is over max limit of BS170 MOSFETS. This can release magic smoke on mosfets!
Now measure voltage of 12V and 5V in different locations such as IC VCC pins etc. to make sure everyone gets the right voltage share!

If all is ok in terms of voltage now we can test if SI5351 is generating any signal. To do this use a frequency counter or oscilloscope on CLK1 test point. The default band is Band 1 and default mode is FT8. You should observe your choice of band 1 base frequency for FT8. For example in my case my Band1 is 40m and for FT8 it is 7074000 Hz or anything close to that as we didn’t yet calibrated the SI5351 VFO. The important point is to see some kind of signal generation which is tell tale of SI5351 is working!
If no smoke and nasty smell and there is signal from SI5351 then we are in business and passed the smoke test!
(Calibration Procedure for SI5351 VFO: )
For SI5351 VFO Calibration Procedure follow these steps:
1 - Connect CAL test point and GND test point on ADX PCB to a Frequency Counter or Oscilloscope that can measure 1 Mhz up to 1Hz accurately.
2 - Press SW2 / --->(CAL) pushbutton and hold.
4- Power up with 12V or with 5V by using Arduino Nano USB socket while still pressing SW2 / --->(CAL) pushbutton.
5 – When FT8 LED and WSPR LED flashes 3 times and stay on, release SW2 / --->(CAL).
Now Calibration mode is active.
6 - Using SW1(<---) and SW2(--->) pushbuttons change the Calibration frequency until reading 1 Mhz = 1000000 Hz exact to the nearest hertz on Frequency counter or Oscilloscope.
The waveform is Square wave so frequency calculation can be performed easily.
7 - If you read as accurate as possible 1000000 Hz then calibration is done.
8 - Now we must save calibration value to EEPROM location.
9 – In order to save calibration value press TX button briefly. TX LED will flash 3 times which indicates that Calibration value is saved.
10 – Now Power off ADX.
DO NOT FORGET TO SAVE CALIBRATION VALUE BY PRESSING TX BUTTON BRIEFLY AT THE END OF EACH CALIBRATION SESSION. OTHERWISE CALIBRATION WILL REVERT TO THE DEFAULT VALUE.
Calibration will be loaded back in every power up so no need to repeat calibration once done. Also new firmware update won’t reset calibration and no need to re-calibrate again.
After calibration, plug in desired LPF band module. To activate Transmit for testing purposes we can always use TX button which acts as a ordinary PTT(Push To Talk) button and no need to connect to a digital modes software for transmit. This RF output a continuous wave signal only for testing RF power. Also this can be used for Antenna Tuner tuning.

Using ADX Arduino Digital Modes Transceiver:
ADX Arduino Digital Modes Transceiver can be used with CAT control via USB or using Manual control via switches and LEDs.
1- Manual Control of ADX using keys and LEDs:
Operating Controls and switching bands:
1- When you power on ADX one of the LED’s will briefly flash 3 times and then another LED will be on solid. The first LED which was flashing 3 times indicates the active or selected BAND bank. By default it is Band1.

For example if the LED was blinking in BAND1 which is 40m band in my ADX now I know my ADX is set for operate on 40m band.
The second LED which is solid is showing the active MODE. For example if it is in FT8 then ADX will operate on 40m in FT8.

So how we will change band?

- Press < --- and --- > switches simultaneously briefly.
- One of the BAND LED will blink 3 times and stay solid. Also TX LED will be on. This doesn’t mean that we are transmitting anything! It is just an indicator to show we are in band switch mode.
- Now using < --- and --- > switches we can turn on LED on different band banks. Of course we need to know which band is assigned to which bank. For that I use labeling tape to label each band bank corresponding to each band setup in the firmware.

See below photo for my band bank labeling as an example!
- After we select the band we would like to operate on, we can exit Band select mode by briefly pressing TX switch. As soon as we press TX switch the TX LED will turn off and the selected band’s LED will flash 3 times to notify us that is the band ADX will operate on. After blinking Band LED turns off, the mode LED will light up showing the mode we are on.
- Now we can scroll between modes with < --- and --- > switches. The on LED is the active mode. We can’t change band by scrolling left or right. This only changes operation mode such as FT8,FT4,JS8 or WSPR. To change band we need to simultaneously press two switches briefly. Then we enter band change mode which is indicated by TX LED on.

- Now the most important thing is not to smoke any finals! When we change a band we need to make sure that band’s LPF band module is plugged on!!!

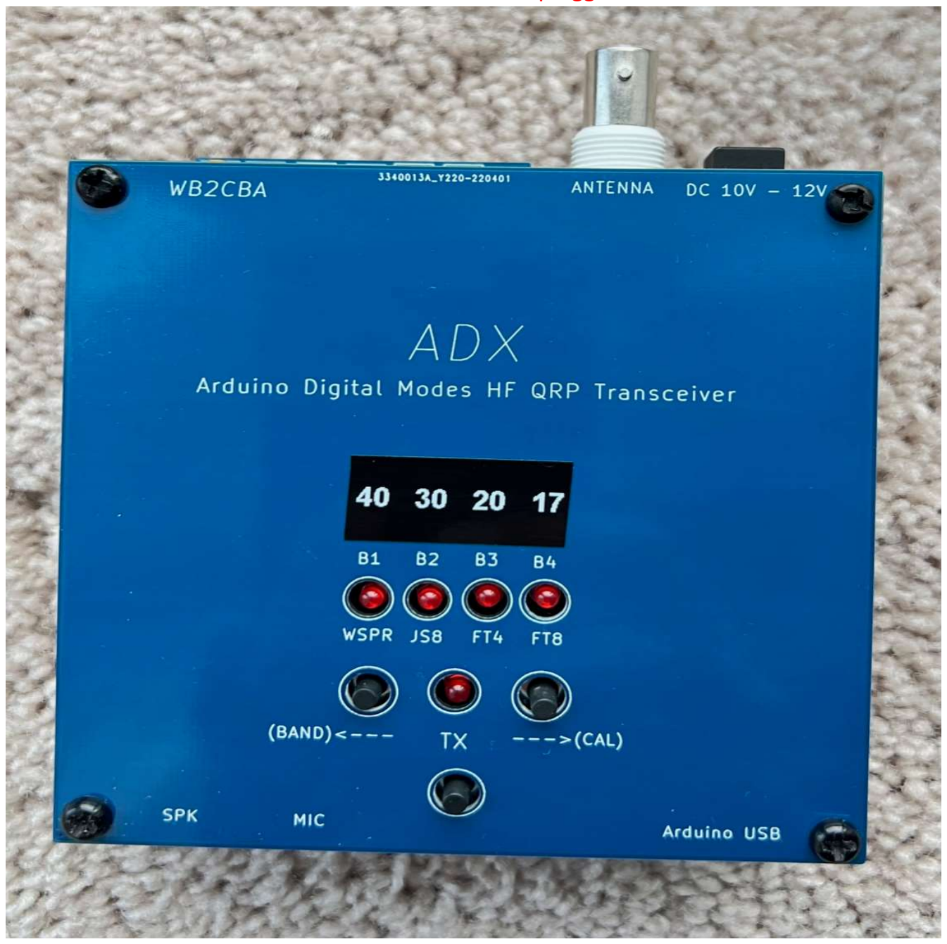
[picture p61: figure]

Connecting ADX Transceiver to Computer and firing up ADX:
1- Connecting ADX Transceiver to any computer is pretty straight forward. We need a MIC which is Microphone input and SPK which is Speaker input or headphone input. We can either use PC built in soundcard or one of those cheap USB Soundcard adapters. I suggest to use a USB soundcard adapter for couple of reasons! This way if anything goes wrong built in soundcard won’t be damaged. Also this will help on ground loop instances.

For USB isolation and peace of mind from ground loop dangers you can use one of these before USB soundcard plug in: https://www.amazon.com/GeeekPi-Isolator-ADUM3160-Isolation-Protection/dp/B07QKYYCD8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 =366402536789&hvpos=&hvnetw=g&hvrand=10336854439692763421&hvqmt=&hvde v=c&hvdvcmdl=&hvlocint=&hvlocphy=9003562&hvtargid=pla-814018215075

For USB soundcard adapter I use this sound card from amazon: https://www.amazon.com/Sabrent-External-Adapter-Windows-AU-MMSA/dp/B00IRVQ0F8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

- We also need 3.5mm audio jack male to 3,5 mm audio jack male extension adapter cables. Actually two of them!
Again from amazon I use this: https://www.amazon.com/Syncwire-Braided-Auxiliary-Adapter-Headphones/dp/B01I0SI1SG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

These are just examples. You can get anything similar to these.

2- Connect Soundcard MIC input to ADX MIC input with one of the 3.5mm audio cables. To do the same connection from soundcard SPK output to ADX SPK input with the other 3.5mm audio cable.
3- Run WSJT/X or JSCALL software.
4- Power on ADX.
5- When you power on ADX one of the LED’s will briefly flash 3 times and then another LED will be on solid. The first LED which was flashing 3 times indicated the active selected BAND bank. So now we know which band we are going to operate on so double check if that LPF Band Module is plugged in and we are good to go! Enjoy ADX with Digital modes similar to any other HF Transceiver you will operate digital modes on!

For setting WSJT/X to work with ADX in Manual Mode:
- Go to Settings/Radio and activate PTT as VOX.
- Choose your soundcard under Settings/Audio menu
- Set Speaker Volume to 100%.
That’s all you need to start working with WSJT/X. This applies pretty much to other software such as JS8Call or WSJT/Z etc.

2- Using ADX in CAT control Mode:
ADX can be controlled with CAT – Computer Aided Transceiver – control too.
In CAT control mode ADX emulates KENWOOD TS2000 Transceiver CAT commands. In CAT control, Frequency and TX/RX of ADX is controlled via CAT commands.
For example in WSJT/X CAT control can change bands, modes and control TX.
To operate on CAT:
- Connect Arduino Nano USB connection to PC USB port.
- Connect Audio jacks to MIC and Speaker of PC and ADX as in Manual mode described above.
Setup Audio in GUI application for your sound card. For example for WSJT/X, go to settings/audio menu and choose audio in and audio out sound card.
For CAT control SETUP:
1- Choose KENWOOD TS2000 as transceiver
2- Choose comm port for your ADX com port from the com port list of your GUI software and set for 9600 bps, 8 data bits and 1 stop bit.

Here is WSJT/X CAT RADIO setup page for ADX as an example:

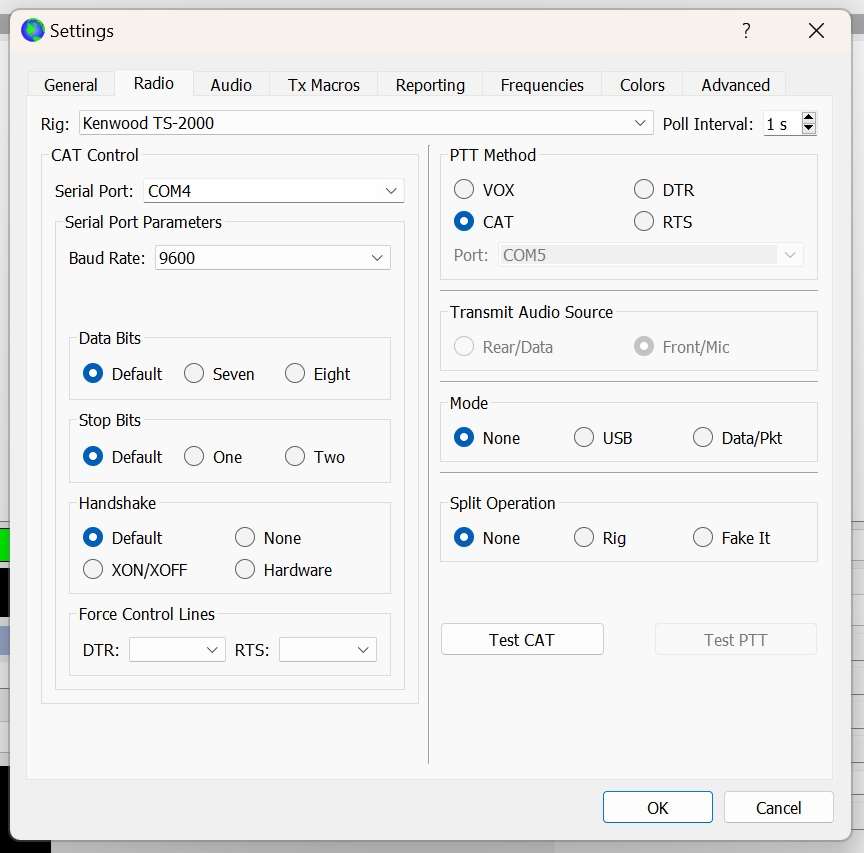
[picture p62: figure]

If all setup is selected right and USB is connected to ADX when Test CAT is pressed after a short pause it should be green. If it is green then CAT is working properly and active.

IMPORTANT POINTS WHEN OPERATING with CAT:
- When operating with CAT any band can be selected without any limitation though the important point is to plug in the right LPF Band filter module on ADX before band change!
If a wrong LPF filter is used for a band that is not matching the selected band with CAT , this can damage BS170 PA mosfets.

- When CAT is active JS8CALL and FT4 LEDS will illuminate and none of those switches or leds will work. Only TX led will be working when TX is on. This manual control lock out is designed on purpose to prevent any conflicting commands between manual mode and CAT.
- CAT Test PTT check button on CAT setup won’t work as ADX does not have a physical PTT control via a pin or button and this is totally normal. ADX PTT is controlled via audio that is transmitted from GUI application like WSJT/X. CAT PTT selection setup can be CAT or VOX and won’t make much difference.
- When ADX is first powered up it starts in Manual control mode with switches and leds as usual. When CAT is activated it automatically enters into CAT mode with default 20m FT8 selected. Make sure to choose the right band and mode before starting TX in accordance with plugged in LPF Band Module.
- When ADX is in CAT mode it will be working only in CAT mode. To exit CAT mode recycle power by brief on/off. Now ADX will start in Manual control mode again.

ADX Limitations and areas that need improvement with wish list! And what is this rig’s purpose in life?
ADX is a simple transceiver that can operate only in digital modes and especially those four popular digital modes, FT8,FT4,JS8Call and WSPR with pin point frequency settings. These are slow tonal modes which Arduino can cope with capturing, decoding and generating FSK signal. Can this rig work on faster digital modes? May be. I am not sure. I haven’t tried but it won’t hurt to experiment with.
The firmware of ADX is basic and there is a lot of room to improve and speed up things. My Arduino programming capabilities are limited as you will witness from the code I put together
Receiver works with reasonable performance for such a simple and dirt cheap receiver design though this is another block that can benefit from improvements. A better band pass filter, an rf amplifier may be a good addition. Currently I am using LPF filter’s first stage band pass which is working pretty good! It’s a cheat! A QSD type RX stage like uSDX’s FST3253 will improve RX sensitivity and most important, selectivity.
An onboard soundcard with a USB onboard hub for Arduino serial might be a nice addition too for single point usb connection control with CAT!
A quad band LPF board with I2C band switching similar to my design uSDX QuadBand LPF board might be another addition which can automate things with a CAT interface!

The wish list goes on and on but it boils down to the same conclusion! I started to tinker with this rig to be a simple and dirt cheap HF transceiver which performs reasonable with minimal hardware to lure young Amateur Radio enthusiasts with a Geek mindset and DIY knack to Amateur Radio and digital modes. I think ADX is hitting all these bullet points as a beginner HF Transceiver. Any of these additions will blow the main purpose of existence of this simple HF digital modes transceiver. So I leave that evaluation to you…
My hope and wish is that this simple HF Transceiver to serve its purpose and attract young hams to Amateur Radio Hobby and DIY Amateur Radio community.
Acknowledgments:
I would like to thank:
- Burkhard Kainka, DK7JD for his inspirational Audio FSK generation code for Arduino. Without it I would be still scratching my head how to solve this problem!
- Jason Mildrum, NT7S for his excellent SI5351 Arduino Library.
- ADX CAT code inspired from Lajos Höss, HA8HL TS2000 CAT implementation for Arduino.
- Improved FSK TX signal generation code of JE1RAV
- Joerg Frede, DK3JF for his contribution for cleaning up my initial ADX code and transforming it into a pro code which is now is the official ADX firmware.

Last word: No usage restrictions or silly licenses on this design. This is a Free and Open Source design for the ham community. Feel free to use in any means including commercial usage. Sky is the limit!
Enjoy your Digital QSOs!
Barbaros Asuroglu aka Barb, WB2CBA
06/10/2023
wb2cba@gmail.com

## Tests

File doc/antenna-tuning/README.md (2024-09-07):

# Antenna Tuning

## Manual methods

Generally some sort of external box / unit is used. Within that unit is typically an analog meter showing the __forward power__ and (sometimes simultaneously) __reverse power__ levels, which are individually metered after splitting the directional elements using a device called a directional coupler. Some devices can only read one at a time, these are known as power meters.  The relationship between the forward power and reverse power is known as the __standing wave ratio (SWR)__.  Those devices which can meter both and display the ratio are known as __standing wave ratio (SWR) meters__.

Some power units / SWR units include variable capacitors and inductors which can be tweaked to obtain a better match. Other times there is a separate antenna tuning unit (ATU) which performs this function.

Many people, like [this guy](https://www.aa5tb.com/tuner.html) or [this guy](https://www.hamradiosecrets.com/homebrew-antenna-tuner.html), build these by themselves with soldered components, it has apparently been a classic HAM project for many years.

The tuning process has been semi-automated by some people who generate different frequency signals and read SWR back to determine nominal 'fit-ness' of the antenna at different frequencies.

Examples of such approaches:
 * https://web.archive.org/web/20200220050317/http://www.hamstack.com/project_antenna_analyzer.html
   * Based on https://www.instructables.com/HF-Antenna-Analyser-With-Arduino-and-DDS-Module/
 * https://github.com/jmharvey1/DDS_AD9850_AntennaAnalyzer also profiled at https://hackaday.com/2015/08/06/40-antenna-analyzer-with-arduino-and-ad9850/

After making some readings, variables can be changed (ie. variable capacitors or inductors tweaked, different antenna connected, elements reconfigured in multi-element or reconfigurable antennas, etc.), until you get a better match.

This can obviously become a bit tedious if you are frequently swapping antennas or doing the "out and about" thing, which has made some people want to automate further.

## Automated methods

Some people have automated the tuning process using large backs of those horrible old clicky mechanical relays, which are just switches that turn one circuit on and off when power is applied to a different circuit.

Examples of such approaches:
 * http://www.ok2zar.cz/php/show_page.php?soubor=auto_tuner/auto_tuner.html
   * Based on http://f5rds.free.fr/F5RDS_remote_antenna_tuner.html
 * https://k6jca.blogspot.com/2016/01/antenna-auto-tuner-design-part-10-final.html (best project of the category in my view, especially the notes on [antenna tuning](https://k6jca.blogspot.com/2015/07/antenna-auto-tuner-design-part-6-notes.html) and [directional couplers](https://k6jca.blogspot.com/2015/07/antenna-auto-tuner-design-part-5.html))
 * https://hamprojects.wordpress.com/2016/12/31/hf-automatic-tuner/
 * https://github.com/Dfinitski/N7DDC-ATU-100-mini-and-extended-boards

Less commonly with servo motors:
 * https://www.pa3hcm.nl/?p=336
 * https://www.qsl.net/on7eq/projects/arduino_atu.htm (servo motor and mechanical variable capacitor based)

And you can even get kits:
 * http://www.merseyradar.co.uk/building-improving-the-atu-100-n7dcc-automatic-antenna-tuner/
 * http://www.krait-technologies.com/20240227_kt-005.pdf

However, clicky mechanical relays have a few problems.
 * They are big
 * They cost money
 * They take quite a long time to actuate
 * They take a lot of power to actuate
 * They can create a fairly large electrical impact on nearby circuits
 * They eventually wear out

## Conclusion

These days it makes more sense to use solid state alternatives wherever possible, because solid state switching is faster, more efficient, more reliable, and doesn't make noise.

While it would theoretically be possible to integrate an antenna tuning unit in to the adxi board, it seems like it would be more suitable as a later project.

As a temporary fudge, adding solder-bridged passive components to the late-stage modules should provide some tuning ability without the need for an external ATU or complex built-in automated ATU.

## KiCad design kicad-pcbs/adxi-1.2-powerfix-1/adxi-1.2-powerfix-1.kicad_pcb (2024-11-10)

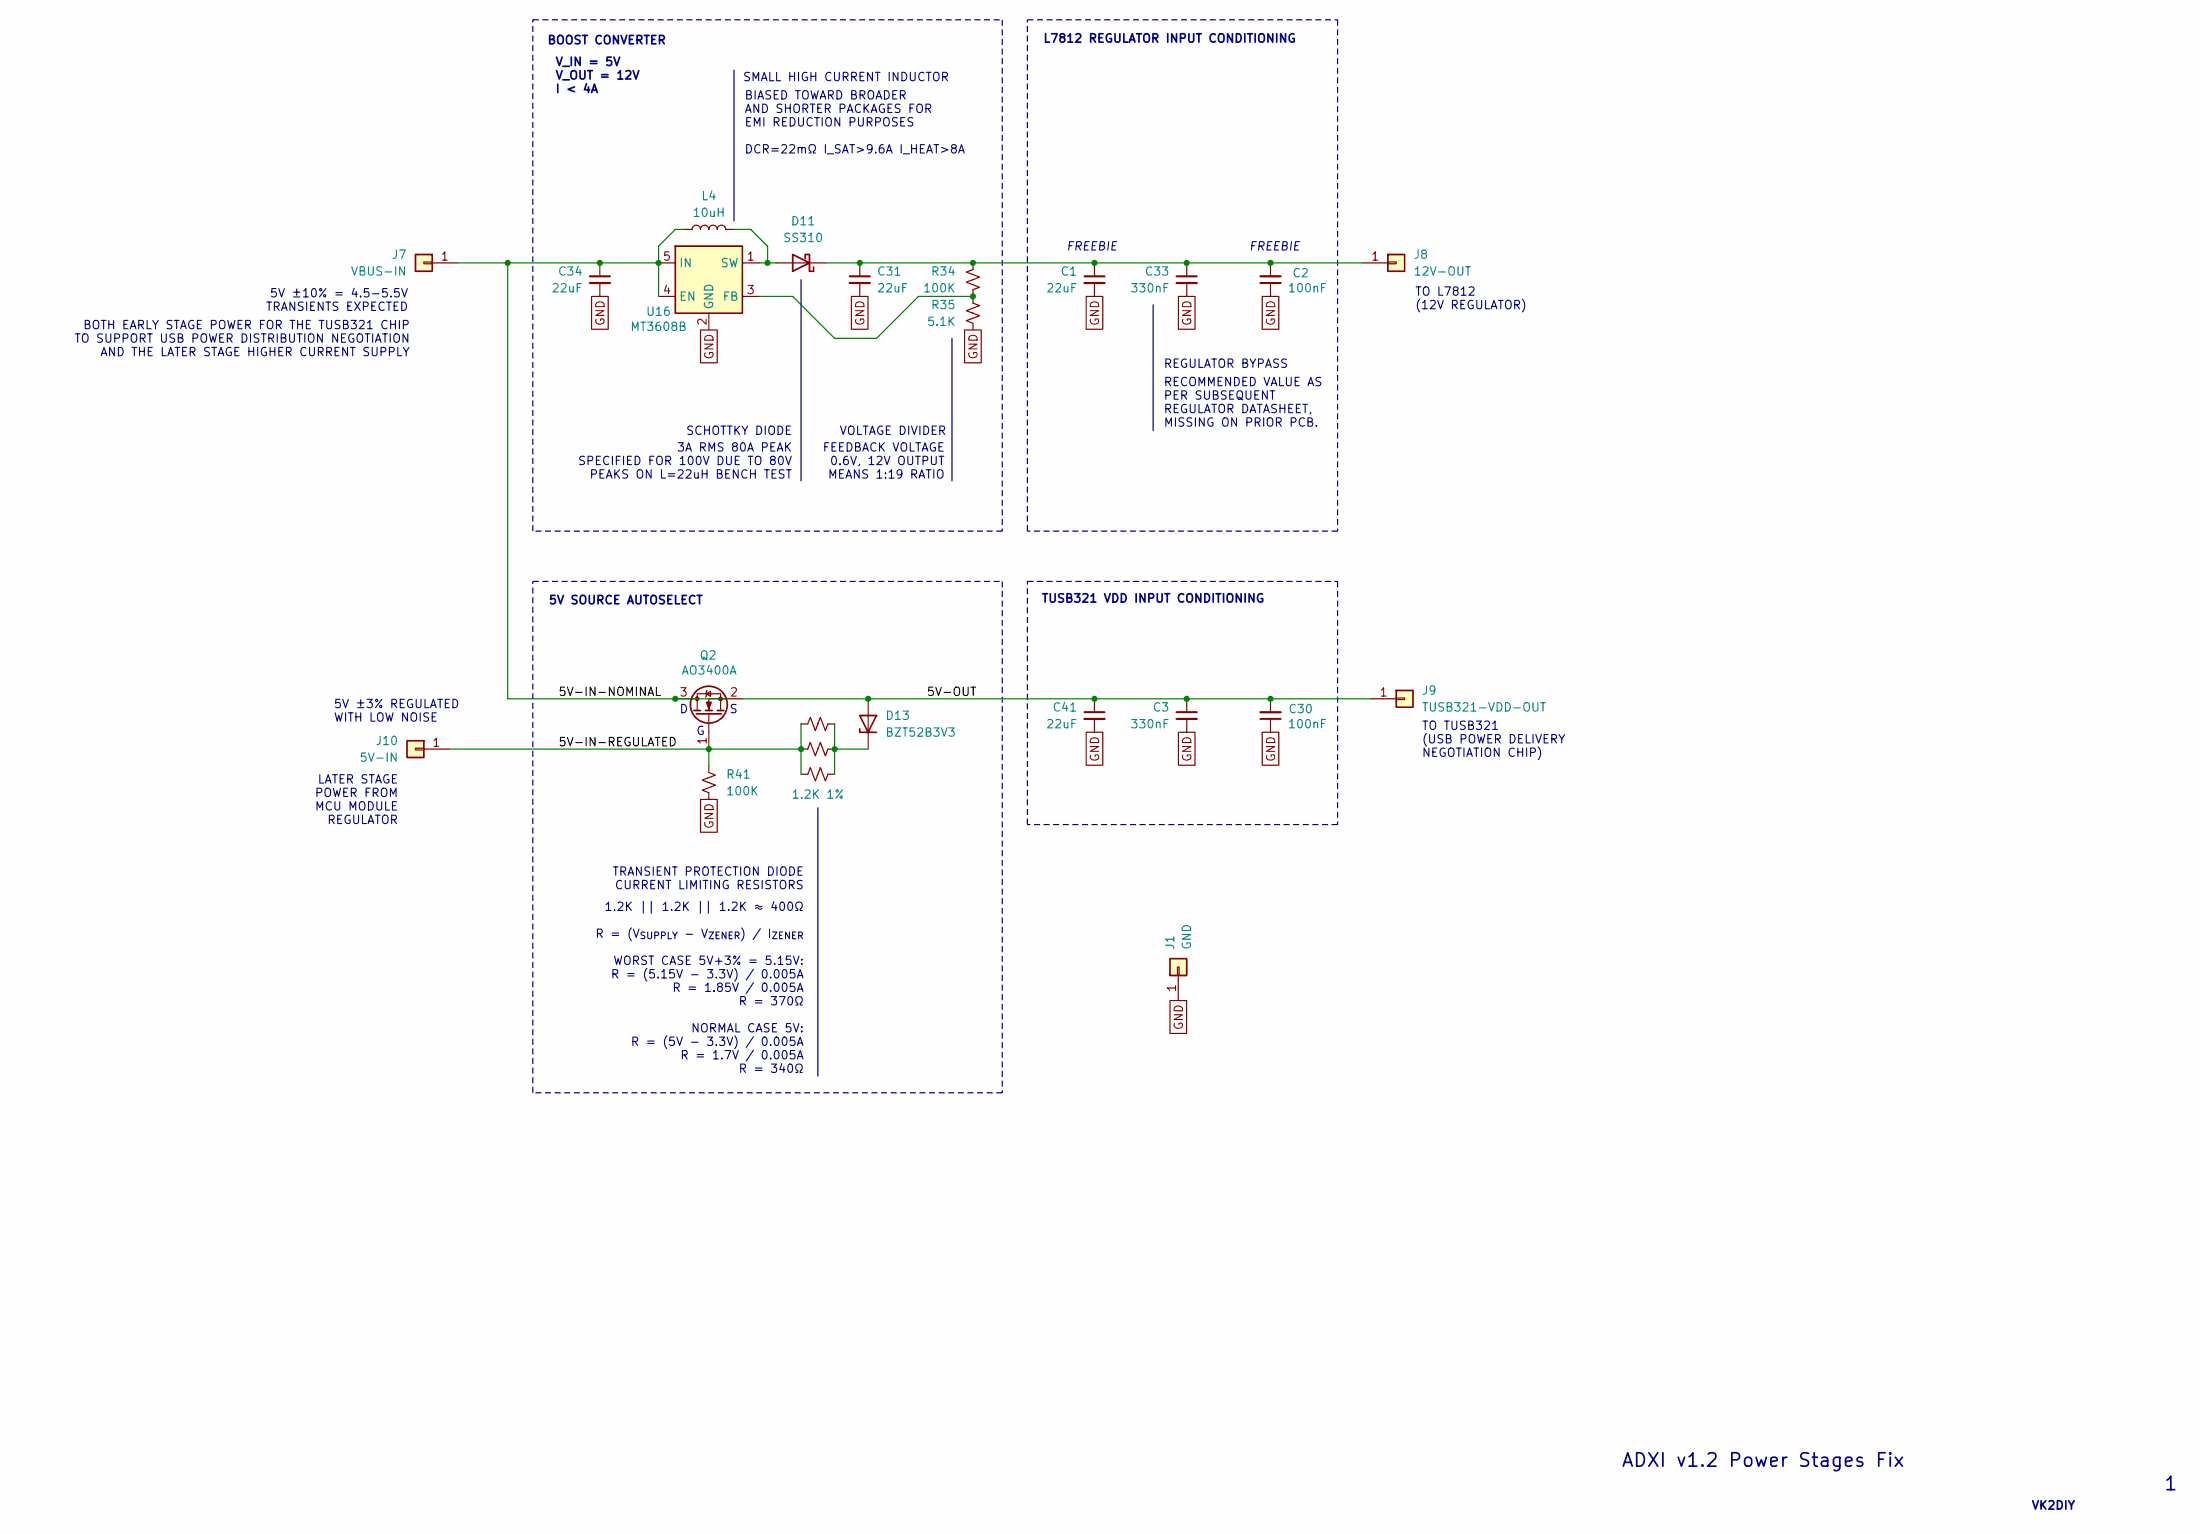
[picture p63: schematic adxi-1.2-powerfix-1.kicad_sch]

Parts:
C1, C31, C34, C41: 22uF; C_0805_2012Metric; MPN CL21A226MAQNNNE; LCSC Part # C45783
C2, C30: 100nF; C_0805_2012Metric; MPN CL21B104KCFNNNE; LCSC Part # C28233
C3, C33: 330nF; C_0603_1608Metric; MPN CC0603KRX7R9BB104; LCSC Part # C14663
D11: SS310; D_SMA; MPN SS310; LCSC Part # C7420364
D13: BZT52B3V3; D_SOD-123F; MPN BZT52B3V3; LCSC Part # C19077392
J1: GND; PinHeader_1x01_P2.54mm_Vertical
J7: VBUS-IN; PinHeader_1x01_P2.54mm_Vertical
J8: 12V-OUT; PinHeader_1x01_P2.54mm_Vertical
J9: TUSB321-VDD-OUT; PinHeader_1x01_P2.54mm_Vertical
J10: 5V-IN; PinHeader_1x01_P2.54mm_Vertical
L4: 10uH; IND-SMD_L12.6-W13.5; MPN FXL1350-100-M; LCSC Part # C526017
Q2: AO3400A; SOT-23; MPN AO3400A; LCSC Part # C20917
R34, R41: 100K; R_1206_3216Metric; MPN 1206W4F1003T5E; LCSC Part # C17900
R35: 5.1K; R_0805_2012Metric; MPN 0805W8F5101T5E; LCSC Part # C27834
R42, R43, R44: 1.2K 1%; R_0603_1608Metric; MPN 0603WAF1201T5E; LCSC Part # C22765
U16: MT3608B; SOT-23-6; MPN MT3608B; LCSC Part # C19189893

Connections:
/5V-IN-NOMINAL: C34.1, J7.1, L4.1, Q2.3 (D), U16.4 (EN), U16.5 (IN)
/5V-IN-REGULATED: J10.1, Q2.1 (G), R41.2, R42.1, R43.1, R44.1
/5V-OUT: C3.1, C30.2, C41.1, D13.2 (A), J9.1, Q2.2 (S)
GND: C1.2, C2.1, C3.2, C30.1, C31.2, C33.2, C34.2, C41.2, J1.1, R35.2, R41.1, U16.2 (GND)
unnamed: D11.2 (A), L4.2, U16.1 (SW)
unnamed: C1.1, C2.2, C31.1, C33.1, D11.1 (K), J8.1, R34.2
unnamed: D13.1 (K), R42.2, R43.2, R44.2
unnamed: R34.1, R35.1, U16.3 (FB)

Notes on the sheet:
FREEBIE
VK2DIY
SCHOTTKY DIODE
BOOST CONVERTER
FEEDBACK VOLTAGE 0.6V, 12V OUTPUT MEANS 1:19 RATIO
ADXI v1.2 Power Stages Fix
V_IN = 5V V_OUT = 12V I < 4A
REGULATOR BYPASS
3A RMS 80A PEAK SPECIFIED FOR 100V DUE TO 80V PEAKS ON L=22uH BENCH TEST
TO L7812 (12V REGULATOR)
TO TUSB321 (USB POWER DELIVERY NEGOTIATION CHIP)
VOLTAGE DIVIDER
5V ±10% = 4.5-5.5V TRANSIENTS EXPECTED
BIASED TOWARD BROADER AND SHORTER PACKAGES FOR EMI REDUCTION PURPOSES DCR=22mΩ I_SAT>9.6A I_HEAT>8A
LATER STAGE POWER FROM MCU MODULE REGULATOR
TUSB321 VDD INPUT CONDITIONING
TRANSIENT PROTECTION DIODE CURRENT LIMITING RESISTORS
L7812 REGULATOR INPUT CONDITIONING
1.2K || 1.2K || 1.2K ≈ 400Ω R = (V_{SUPPLY} - V_{ZENER}) / I_{ZENER} WORST CASE 5V+3% = 5.15V: R = (5.15V - 3.3V) / 0.005A R = 1.85V / 0.005A R = 370Ω NORMAL CASE 5V: R = (5V - 3.3V) / 0.005A R = 1.7V / 0.005A R = 340Ω
5V SOURCE AUTOSELECT
5V ±3% REGULATED WITH LOW NOISE
RECOMMENDED VALUE AS PER SUBSEQUENT REGULATOR DATASHEET, MISSING ON PRIOR PCB.
SMALL HIGH CURRENT INDUCTOR
BOTH EARLY STAGE POWER FOR THE TUSB321 CHIP TO SUPPORT USB POWER DISTRIBUTION NEGOTIATION AND THE LATER STAGE HIGHER CURRENT SUPPLY

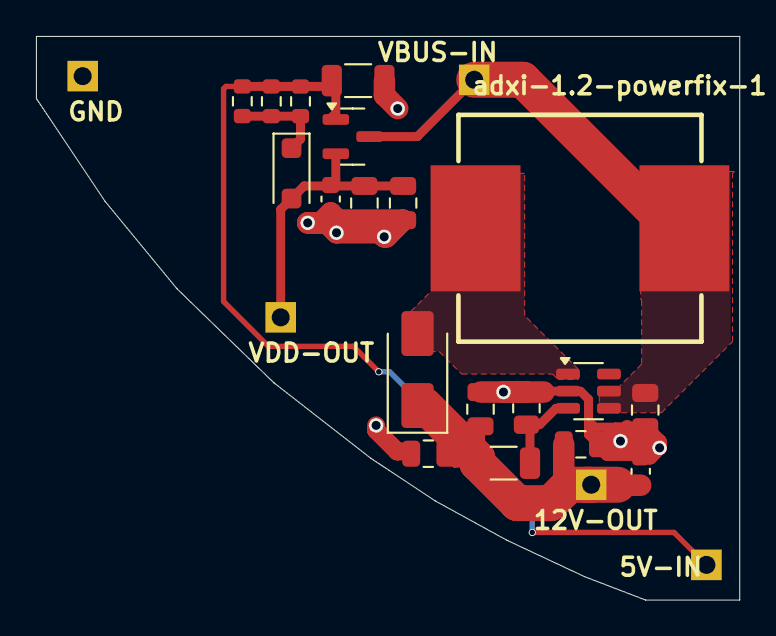
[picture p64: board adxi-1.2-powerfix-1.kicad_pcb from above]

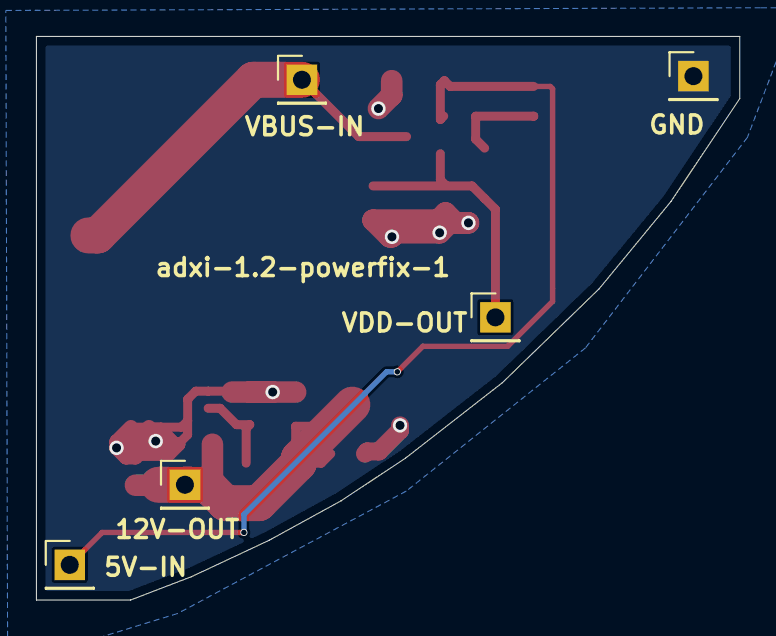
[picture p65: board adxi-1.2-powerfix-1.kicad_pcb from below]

Board: 2 copper layers, 39.1 x 31.3 mm, 24 parts (5 on the bottom side), 8 nets.

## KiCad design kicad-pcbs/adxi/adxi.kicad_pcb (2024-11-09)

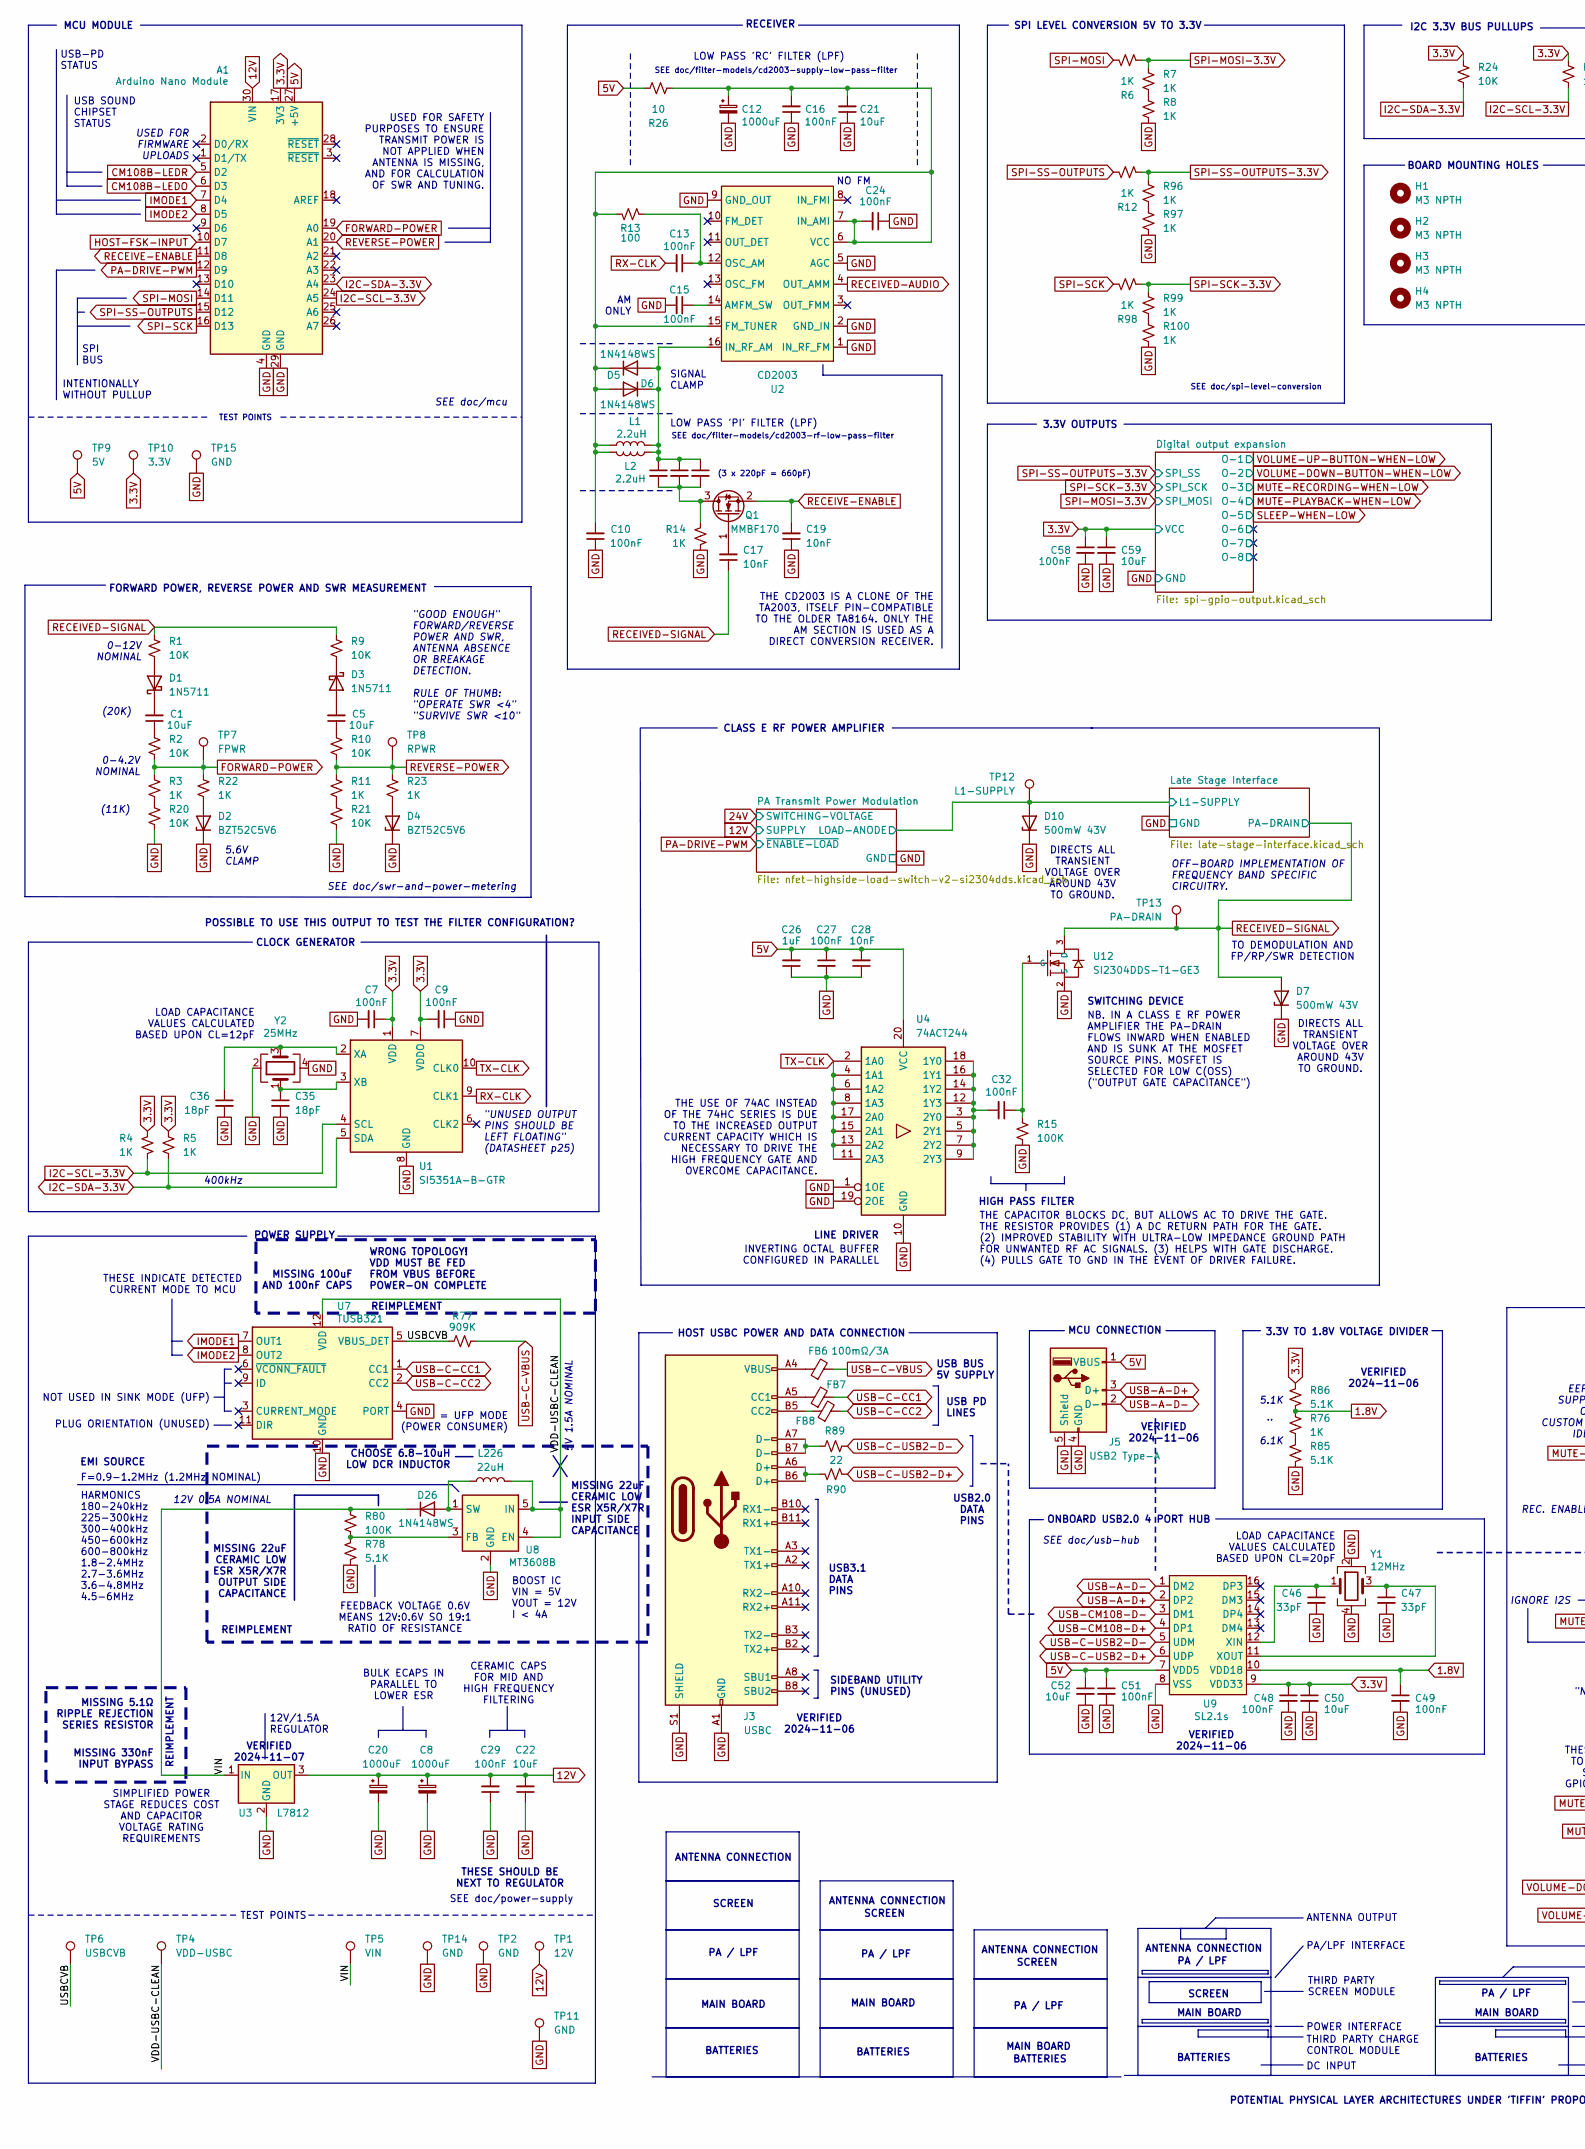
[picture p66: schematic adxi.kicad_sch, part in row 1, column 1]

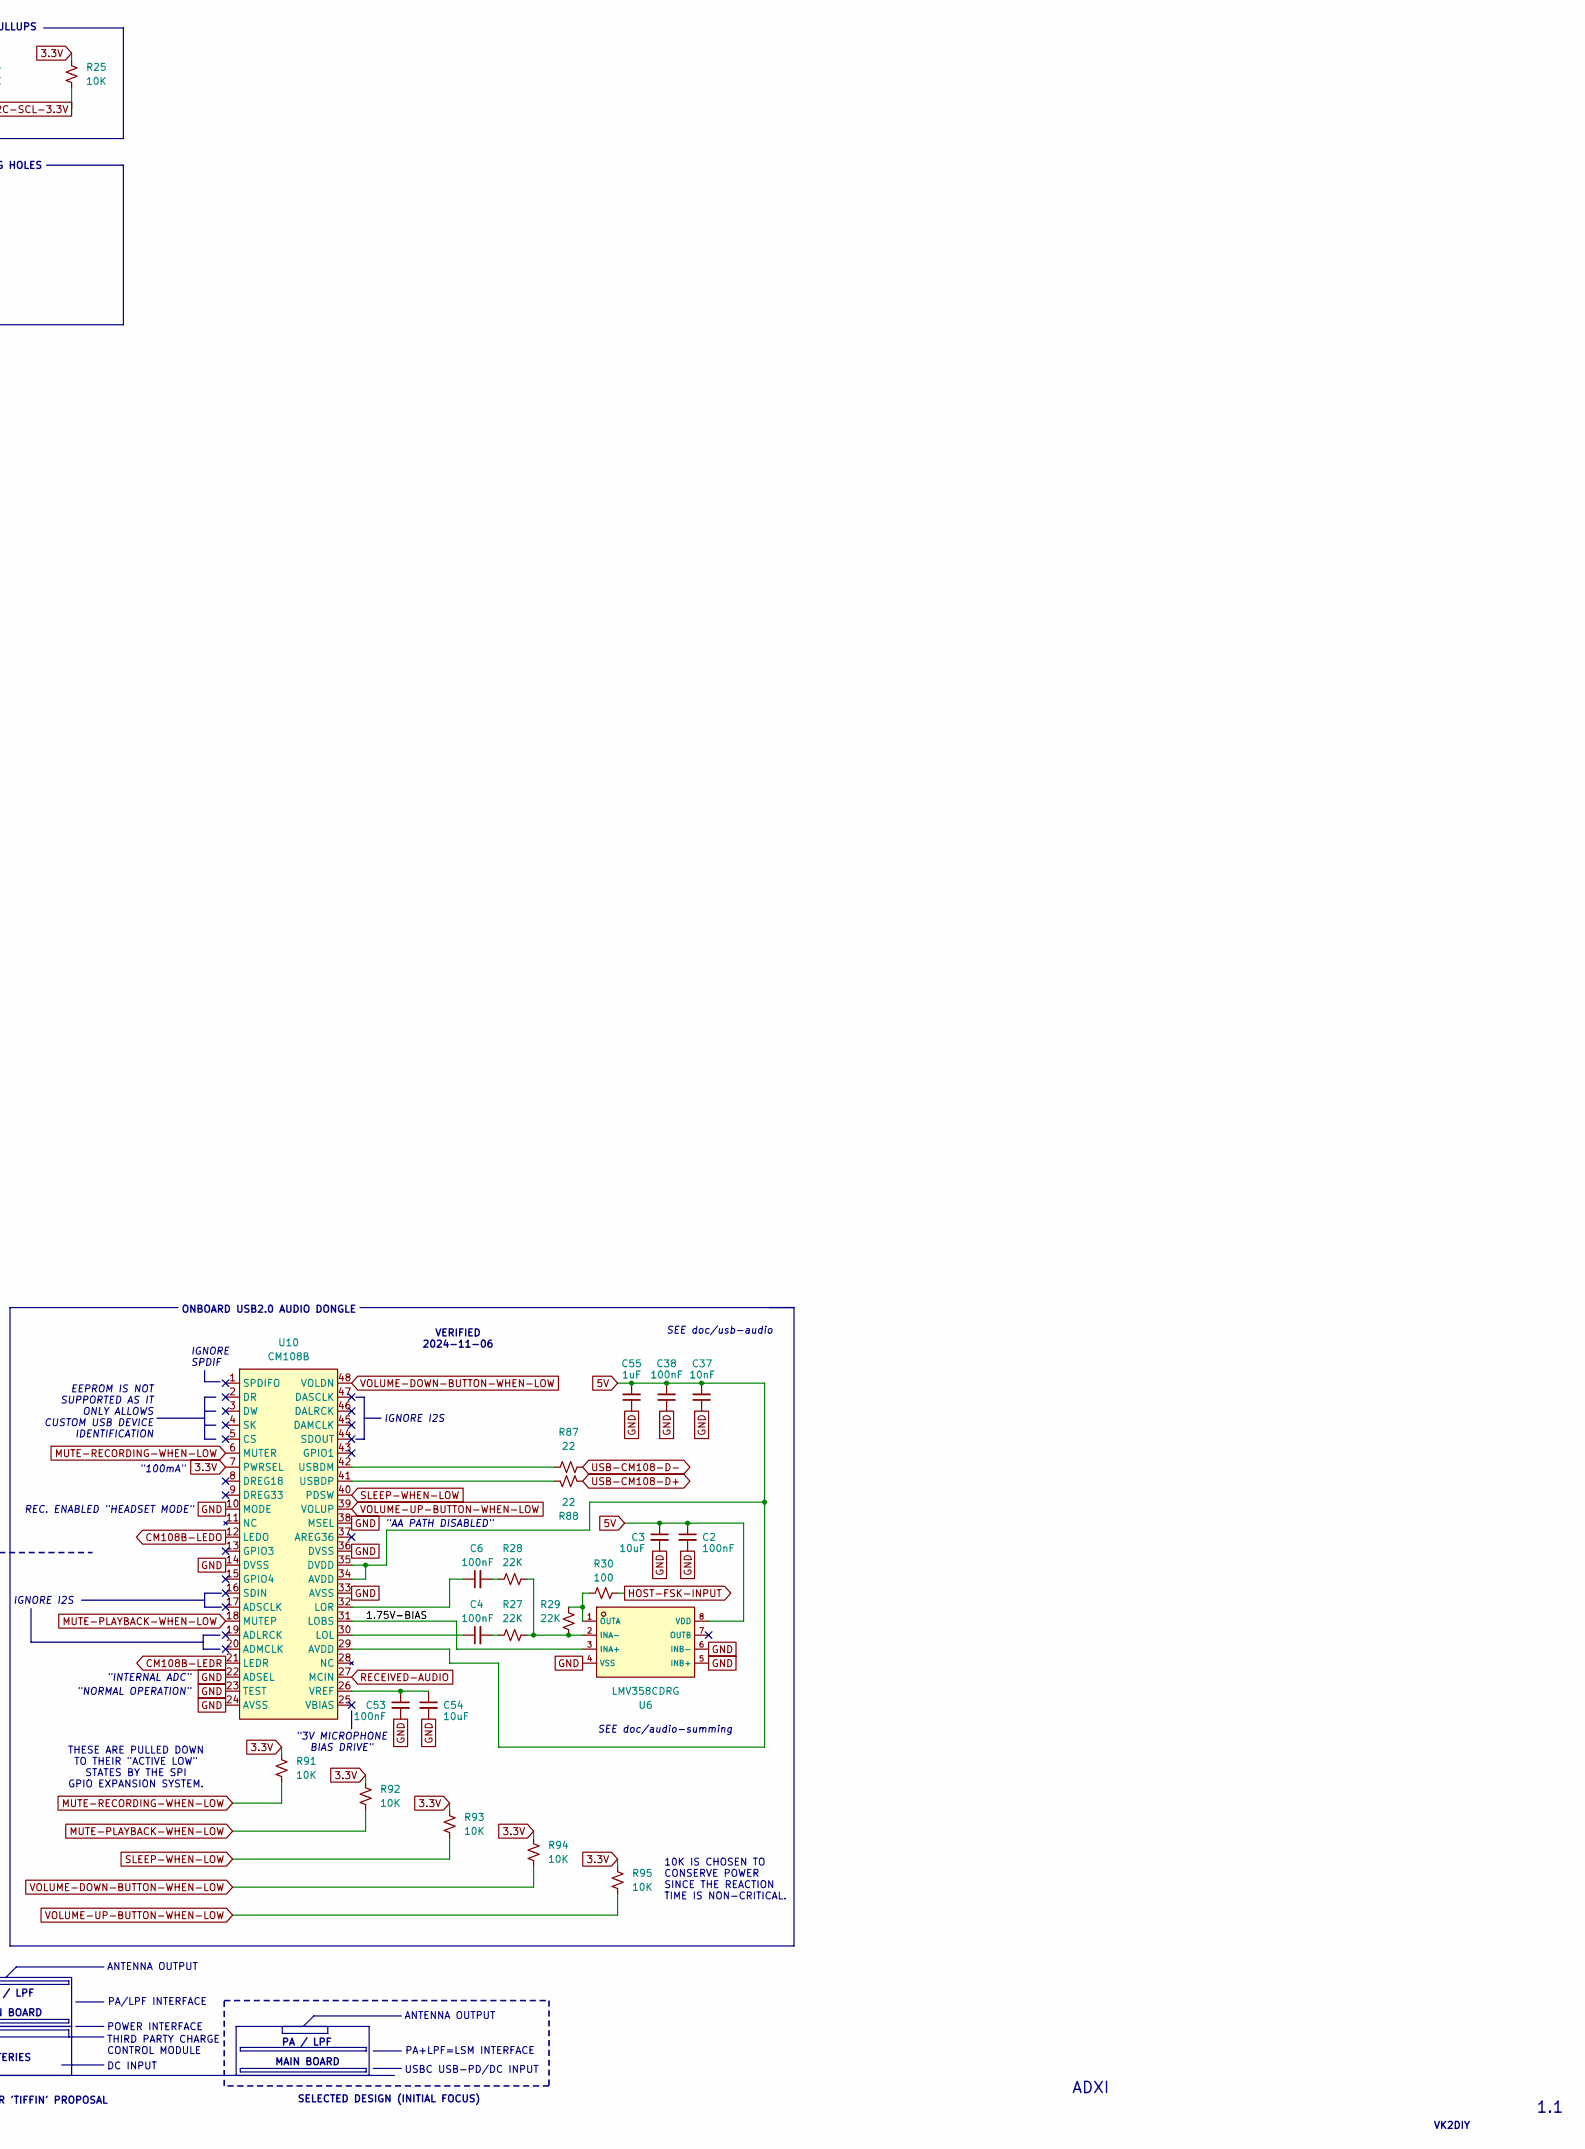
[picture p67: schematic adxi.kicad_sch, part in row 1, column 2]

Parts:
A1: Arduino Nano Module; Arduino_Nano
C1, C5: 10uF; C_1210_3225Metric; MPN FS32X106K101EGG; LCSC Part # C5156756
C2, C4, C6, C27, C48, C49, C51, C53, C58: 100nF; C_0603_1608Metric; MPN CC0603KRX7R9BB104; LCSC Part # C14663
C3, C50, C52, C54, C59: 10uF; C_0603_1608Metric; MPN CL10A106KP8NNNC; LCSC Part # C19702
C7, C9, C10, C13, C15, C16, C24, C29, C32, C38: 100nF; C_0805_2012Metric; MPN CL21B104KCFNNNE; LCSC Part # C28233
C8, C12, C20: 1000uF; C_Elec_10x10.2; MPN RVT1C102M1010; LCSC Part # C3359
C11, C39, C40: 220pF; C_0603_1608Metric; MPN CL10B221KB8NNNC; LCSC Part # C1603
C17, C19, C28, C37: 10nF; C_0603_1608Metric; MPN 0603B103K500NT; LCSC Part # C57112
C21, C22: 10uF; C_1206_3216Metric; MPN CL31A106KBHNNNE; LCSC Part # C13585
C26, C55: 1uF; C_0603_1608Metric; MPN CL10A105KB8NNNC; LCSC Part # C15849
C35, C36: 18pF; C_0402_1005Metric; MPN 0402CG180J500NT; LCSC Part # C1549
C46, C47: 33pF; C_0603_1608Metric; MPN CL10C330JB8NNNC; LCSC Part # C1663
D1, D3: 1N5711; D_SOD-123; MPN 1N5711W-7-F; LCSC Part # C154843
D2, D4: BZT52C5V6; D_SOD-123; MPN BZT52C5V6; LCSC Part # C173406
D5, D6, D26: 1N4148WS; D_SOD-323; MPN 1N4148WS; LCSC Part # C2128
D7, D10: 500mW 43V; D_SOD-123; MPN MMSZ5260B; LCSC Part # C268628
FB6, FB7, FB8: 100mΩ/3A; C_1206_3216Metric; MPN CBW321609U800T; LCSC Part # C130273
H1, H2, H3, H4: M3 NPTH; MountingHole_3.2mm_M3_DIN965
J3: USBC; TYPE-C-SMD_C9900025773; MPN TYPE-C 24P QT 143; LCSC Part # C5156605
J5: USB2 Type-A; USB-A-SMD_10.0-QTJ6.3; MPN 10.0 QTJ6.3; LCSC Part # C404966
L1, L2: 2.2uH; L_1008_2520Metric; MPN WPN252012H2R2MT; LCSC Part # C98350
L226: 22uH; L_Changjiang_FNR4030S; MPN FNR4030S220MT; LCSC Part # C167883
Q1: MMBF170; SOT-23; MPN MMBF170; LCSC Part # C130879
R1, R2, R9, R10, R20, R21: 10K; R_1206_3216Metric; MPN 1206W4F1002T5E; LCSC Part # C17902
R3, R4, R5, R11, R14, R22, R23, R76: 1K; R_1206_3216Metric; MPN 1206W4F1001T5E; LCSC Part # C4410
R6, R7, R8, R12, R96, R97, R98, R99, R100: 1K; R_0603_1608Metric; MPN 0603WAF1001T5E; LCSC Part # C21190
R13: 100; R_1206_3216Metric; MPN 1206W4F1000T5E; LCSC Part # C17901
R15, R80: 100K; R_1206_3216Metric; MPN 1206W4F1003T5E; LCSC Part # C17900
R24, R25, R91, R92, R93, R94, R95: 10K; R_0402_1005Metric; MPN 0402WGF1002TCE; LCSC Part # C25744
R26: 10; R_1206_3216Metric; MPN 1206W4F100JT5E; LCSC Part # C17903
R27, R28, R29: 22K; R_0805_2012Metric; MPN 0805W8F2202T5E; LCSC Part # C17560
R30: 100; R_0805_2012Metric; MPN 0805W8F1000T5E; LCSC Part # C17408
R77: 909K; R_1206_3216Metric; MPN RS-06K9093FT; LCSC Part # C323176
R78, R85, R86: 5.1K; R_0805_2012Metric; MPN 0805W8F5101T5E; LCSC Part # C27834
R87, R88, R89, R90: 22; R_0805_2012Metric; MPN 0805W8F220JT5E; LCSC Part # C17561
TP1: 12V; TestPoint_THTPad_2.0x2.0mm_Drill1.0mm
TP2, TP11, TP14, TP15: GND; TestPoint_THTPad_2.0x2.0mm_Drill1.0mm
TP4: VDD-USBC; TestPoint_THTPad_2.0x2.0mm_Drill1.0mm
TP5: VIN; TestPoint_THTPad_2.0x2.0mm_Drill1.0mm
TP6: USBCVB; TestPoint_THTPad_2.0x2.0mm_Drill1.0mm
TP7: FPWR; TestPoint_THTPad_2.0x2.0mm_Drill1.0mm
TP8: RPWR; TestPoint_THTPad_2.0x2.0mm_Drill1.0mm
TP9: 5V; TestPoint_THTPad_2.0x2.0mm_Drill1.0mm
TP10: 3.3V; TestPoint_THTPad_2.0x2.0mm_Drill1.0mm
TP12: L1-SUPPLY; TestPoint_THTPad_2.0x2.0mm_Drill1.0mm
TP13: PA-DRAIN; TestPoint_THTPad_2.0x2.0mm_Drill1.0mm
U1: SI5351A-B-GTR; MSOP-10_3x3mm_P0.5mm; MPN SI5351A-B-GTR; LCSC Part # C504891
U2: CD2003; SOP-16_3.9x9.9mm_P1.27mm; MPN CD2003GB/GP; LCSC Part # C7421626
U3: L7812; TO-263-2; MPN L7812CDTR(XBLW); LCSC Part # C22357877
U4: 74ACT244; TSSOP-20_4.4x6.5mm_P0.65mm; MPN SN74ACT244PWR; LCSC Part # C6930
U6: LMV358CDRG; SOIC-8_L4.9-W3.9-P1.27-LS6.0-TL; MPN LMV358CDRG; LCSC Part # C2977080
U7: TUSB321; Texas_X2QFN-12_1.6x1.6mm_P0.4mm; MPN TUSB321RWBR; LCSC Part # C139392
U8: MT3608B; SOT-23-6; MPN MT3608B; LCSC Part # C19189893
U9: SL2.1s; SSOP-16_L4.6-W2.6-P0.53-LS4.0-BL; MPN SL2.1s; LCSC Part # C2684433
U10: CM108B; LQFP-48_7x7mm_P0.5mm; MPN CM108B; LCSC Part # C371347
U12: SI2304DDS-T1-GE3; SOT-23-3_L2.9-W1.6-P1.90-LS2.8-BR; MPN SI2304DDS-T1-GE3; LCSC Part # C56372
Y1: 12MHz; Crystal_SMD_3225-4Pin_3.2x2.5mm; MPN X322512MSB4SI; LCSC Part # C9002
Y2: 25MHz; Crystal_SMD_3225-4Pin_3.2x2.5mm; MPN X322525MOB4SI; LCSC Part # C9006

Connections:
1.8V: C49.1, R76.1, R86.2, U9.10 (VDD18)
3.3V: A1.17 (3V3), C7.1, C9.2, C48.1, C50.1, C58.1, C59.1, R4.1, R5.1, R24.1, R25.1, R86.1, R91.1, R92.1, R93.1, R94.1, R95.1, TP10.1, U1.1 (VDD), U1.7 (VDDO), U9.9 (VDD33), U10.7 (PWRSEL); also elsewhere on the board
5V: A1.27 (+5V), C2.1, C3.1, C26.2, C27.1, C28.2, C37.2, C38.2, C51.1, C52.1, C55.2, J5.1 (VBUS), R26.1, TP9.1, U4.20 (VCC), U6.8 (VDD), U9.7 (VDD5), U10.29 (AVDD), U10.34 (AVDD), U10.35 (DVDD)
12V: A1.30 (VIN), C8.1, C20.1, C22.2, C29.2, TP1.1, U3.3 (OUT); also elsewhere on the board
/1.75V-BIAS: U6.3 (INA+), U10.31 (LOBS)
/Late Stage Interface/L1-SUPPLY: D10.2 (A), TP12.1; also elsewhere on the board
/USBCVB: R77.2, TP6.1, U7.5 (VBUS_DET)
/VDD-USBC-CLEAN: L226.2, TP4.1, U7.12 (VDD), U8.4 (EN), U8.5 (IN)
/VIN: D26.1 (K), R80.2, TP5.1, U3.1 (IN)
CM108B-LEDO: A1.6 (D3), U10.12 (LEDO)
CM108B-LEDR: A1.5 (D2), U10.21 (LEDR)
FORWARD-POWER: A1.19 (A0), R2.1, R3.1, R22.1, TP7.1
GND: A1.4 (GND), A1.29 (GND), C2.2, C3.2, C7.2, C8.2, C9.1, C10.1, C12.2, C15.2, C16.1, C19.1, C20.2, C21.1, C22.1, C24.1, C26.1, C27.2, C28.1, C29.1, C35.2, C36.2, C37.1, C38.1, C46.2, C47.2, C48.2, C49.2, C50.2, C51.2, C52.2, C53.2, C54.2, C55.1, C58.2, C59.2, D2.1 (K), D4.1 (K), D7.1 (K), D10.1 (K), J3.A1 (GND), J3.A12 (GND), J3.B1 (GND), J3.B12 (GND), J3.S1 (SHIELD), J5.4 (GND), J5.5 (Shield), R8.1, R14.2, R15.1, R20.1, R21.1, R78.2, R85.2, R97.1, R100.1, TP2.1, TP11.1, TP14.1, TP15.1, U1.8 (GND), U2.1 (IN_RF_FM), U2.2 (GND_IN), U2.5 (AGC), U2.9 (GND_OUT), U3.2 (GND), U4.1 (1OE), U4.10 (GND), U4.19 (2OE), U6.4 (VSS), U6.5 (INB+), U6.6 (INB-), U7.4 (PORT), U7.10 (GND), U8.2 (GND), U9.8 (VSS), U10.10 (MODE), U10.14 (DVSS), U10.22 (ADSEL), U10.23 (TEST), U10.24 (AVSS), U10.33 (AVSS), U10.36 (DVSS), U10.38 (MSEL), U12.2 (S), Y1.2, Y1.4, Y2.2, Y2.4; also elsewhere on the board
HOST-FSK-INPUT: A1.10 (D7), R30.2
I2C-SCL-3.3V: A1.24 (A5), R4.2, R25.2, U1.4 (SCL)
I2C-SDA-3.3V: A1.23 (A4), R5.2, R24.2, U1.5 (SDA)
IMODE1: A1.7 (D4), U7.7 (OUT1)
IMODE2: A1.8 (D5), U7.8 (OUT2)
MUTE-PLAYBACK-WHEN-LOW: R92.2, U10.18 (MUTEP); also elsewhere on the board
MUTE-RECORDING-WHEN-LOW: R91.2, U10.6 (MUTER); also elsewhere on the board
unnamed: C1.1, R2.2
unnamed: C4.2, R27.1
unnamed: C5.1, R10.2
unnamed: C6.2, R28.1
unnamed: D1.2 (A), R1.1
unnamed: C1.2, D1.1 (K)
unnamed: D2.2 (A), R22.2
unnamed: C5.2, D3.2 (A)
unnamed: D3.1 (K), R9.1
unnamed: D4.2 (A), R23.2
unnamed: C11.1, C39.1, C40.1, D5.2 (A), D6.1 (K), L1.2, L2.1, U2.16 (IN_RF_AM)
unnamed: C10.2, C12.1, C16.2, C21.2, C24.2, D5.1 (K), D6.2 (A), L1.1, L2.2, R13.2, R26.2, U2.6 (VCC), U2.7 (IN_AMI), U2.15 (FM_TUNER)
unnamed: D26.2 (A), L226.1, U8.1 (SW)
unnamed: FB6.1, J3.A4 (VBUS), J3.A9 (VBUS), J3.B4 (VBUS), J3.B9 (VBUS)
unnamed: FB7.1, J3.A5 (CC1)
unnamed: FB8.1, J3.B5 (CC2)
unnamed: J3.A6 (D+), J3.B6 (D+), R90.1
unnamed: J3.A7 (D-), J3.B7 (D-), R89.1
unnamed: C11.2, C39.2, C40.2, Q1.3 (D), R14.1
unnamed: C17.2, Q1.1 (G)
unnamed: R7.1, R8.2
unnamed: R11.2, R21.2
unnamed: R3.2, R20.2
unnamed: R76.2, R85.1
unnamed: R96.1, R97.2
unnamed: R99.1, R100.2
unnamed: C36.1, U1.2 (XA), Y2.3
unnamed: C35.1, U1.3 (XB), Y2.1
unnamed: C15.1, U2.14 (AMFM_SW)
unnamed: C13.1, R13.1, U2.12 (OSC_AM)
unnamed: C32.2, U4.3 (2Y0), U4.5 (2Y1), U4.7 (2Y2), U4.9 (2Y3), U4.12 (1Y3), U4.14 (1Y2), U4.16 (1Y1), U4.18 (1Y0)
unnamed: R27.2, R28.2, R29.1, U6.2 (INA-)
unnamed: R29.2, R30.1, U6.1 (OUTA)
unnamed: R78.1, R80.1, U8.3 (FB)
unnamed: C46.1, U9.12 (XIN), Y1.1
unnamed: C47.1, U9.11 (XOUT), Y1.3
unnamed: C4.1, U10.30 (LOL)
unnamed: C6.1, U10.32 (LOR)
unnamed: R87.1, U10.42 (USBDM)
unnamed: R88.1, U10.41 (USBDP)
unnamed: C53.1, C54.1, U10.26 (VREF)
unnamed: C32.1, R15.2, U12.1 (G)
PA-DRIVE-PWM: A1.12 (D9); also elsewhere on the board
RECEIVE-ENABLE: A1.11 (D8), C19.2, Q1.2 (S)
RECEIVED-AUDIO: U2.4 (OUT_AMM), U10.27 (MCIN)
RECEIVED-SIGNAL: C17.1, D7.2 (A), R1.2, R9.2, TP13.1, U12.3 (D); also elsewhere on the board
REVERSE-POWER: A1.20 (A1), R10.1, R11.1, R23.1, TP8.1
RX-CLK: C13.2, U1.9 (CLK1)
SLEEP-WHEN-LOW: R93.2, U10.40 (PDSW); also elsewhere on the board
SPI-MOSI: A1.14 (D11), R6.1
SPI-MOSI-3.3V: R6.2, R7.2; also elsewhere on the board
SPI-SCK: A1.16 (D13), R98.1
SPI-SCK-3.3V: R98.2, R99.2; also elsewhere on the board
SPI-SS-OUTPUTS: A1.15 (D12), R12.1
SPI-SS-OUTPUTS-3.3V: R12.2, R96.2; also elsewhere on the board
TX-CLK: U1.10 (CLK0), U4.2 (1A0), U4.4 (1A1), U4.6 (1A2), U4.8 (1A3), U4.11 (2A3), U4.13 (2A2), U4.15 (2A1), U4.17 (2A0)
USB-A-D+: J5.3 (D+), U9.2 (DP2)
USB-A-D-: J5.2 (D-), U9.1 (DM2)
USB-C-CC1: FB7.2, U7.1 (CC1)
USB-C-CC2: FB8.2, U7.2 (CC2)
USB-C-USB2-D+: R90.2, U9.6 (UDP)
USB-C-USB2-D-: R89.2, U9.5 (UDM)
USB-C-VBUS: FB6.2, R77.1
USB-CM108-D+: R88.2, U9.4 (DP1)
USB-CM108-D-: R87.2, U9.3 (DM1)
VOLUME-DOWN-BUTTON-WHEN-LOW: R94.2, U10.48 (VOLDN); also elsewhere on the board
VOLUME-UP-BUTTON-WHEN-LOW: R95.2, U10.39 (VOLUP); also elsewhere on the board

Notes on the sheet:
HIGH PASS FILTER
SIDEBAND UTILITY PINS (UNUSED)
BATTERIES
"AA PATH DISABLED"
"3V MICROPHONE BIAS DRIVE"
LINE DRIVER
REIMPLEMENT
FEEDBACK VOLTAGE 0.6V MEANS 12V:0.6V SO 19:1 RATIO OF RESISTANCE
I2C 3.3V BUS PULLUPS
0-4.2V NOMINAL
THE CAPACITOR BLOCKS DC, BUT ALLOWS AC TO DRIVE THE GATE. THE RESISTOR PROVIDES (1) A DC RETURN PATH FOR THE GATE. (2) IMPROVED STABILITY WITH ULTRA-LOW IMPEDANCE GROUND PATH FOR UNWANTED RF AC SIGNALS. (3) HELPS WITH GATE DISCHARGE. (4) PULLS GATE TO GND IN THE EVENT OF DRIVER FAILURE.
VERIFIED 2024-11-06
MAIN BOARD
0-12V NOMINAL
POWER INTERFACE
SCREEN
VK2DIY
THESE INDICATE DETECTED CURRENT MODE TO MCU
NB. IN A CLASS E RF POWER AMPLIFIER THE PA-DRAIN FLOWS INWARD WHEN ENABLED AND IS SUNK AT THE MOSFET SOURCE PINS. MOSFET IS SELECTED FOR LOW C(OSS) ("OUTPUT GATE CAPACITANCE")
12V/1.5A REGULATOR
AM ONLY
5.6V CLAMP
3.3V TO 1.8V VOLTAGE DIVIDER
WRONG TOPOLOGY! VDD MUST BE FED FROM VBUS BEFORE POWER-ON COMPLETE
REC. ENABLED "HEADSET MODE"
PLUG ORIENTATION (UNUSED)
CERAMIC CAPS FOR MID AND HIGH FREQUENCY FILTERING
MCU MODULE
HARMONICS 180-240kHz 225-300kHz 300-400kHz 450-600kHz 600-800kHz 1.8-2.4MHz 2.7-3.6MHz 3.6-4.8MHz 4.5-6MHz
(3 x 220pF = 660pF)
5V 1.5A NOMINAL
USED FOR SAFETY PURPOSES TO ENSURE TRANSMIT POWER IS NOT APPLIED WHEN ANTENNA IS MISSING, AND FOR CALCULATION OF SWR AND TUNING.
SPI BUS
BOARD MOUNTING HOLES
USBC USB-PD/DC INPUT
SEE doc/filter-models/cd2003-rf-low-pass-filter
USB BUS 5V SUPPLY
PA / LPF
THE CD2003 IS A CLONE OF THE TA2003, ITSELF PIN-COMPATIBLE TO THE OLDER TA8164. ONLY THE AM SECTION IS USED AS A DIRECT CONVERSION RECEIVER.
OFF-BOARD IMPLEMENTATION OF FREQUENCY BAND SPECIFIC CIRCUITRY.

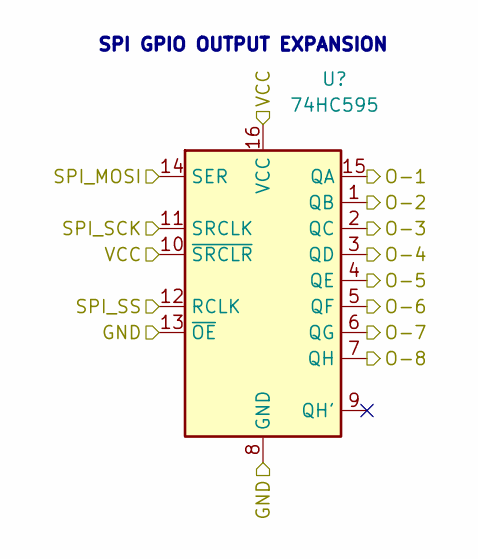
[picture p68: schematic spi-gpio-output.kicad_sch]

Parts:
U5: 74HC595; SOIC-16_3.9x9.9mm_P1.27mm; MPN 74HC595D,118; LCSC Part # C5947

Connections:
3.3V: U5.10 (~SRCLR), U5.16 (VCC); also elsewhere on the board
/Digital output expansion/O-6: U5.5 (QF)
/Digital output expansion/O-7: U5.6 (QG)
/Digital output expansion/O-8: U5.7 (QH)
GND: U5.8 (GND), U5.13 (~OE); also elsewhere on the board
MUTE-PLAYBACK-WHEN-LOW: U5.3 (QD); also elsewhere on the board
MUTE-RECORDING-WHEN-LOW: U5.2 (QC); also elsewhere on the board
SLEEP-WHEN-LOW: U5.4 (QE); also elsewhere on the board
SPI-MOSI-3.3V: U5.14 (SER); also elsewhere on the board
SPI-SCK-3.3V: U5.11 (SRCLK); also elsewhere on the board
SPI-SS-OUTPUTS-3.3V: U5.12 (RCLK); also elsewhere on the board
VOLUME-DOWN-BUTTON-WHEN-LOW: U5.1 (QB); also elsewhere on the board
VOLUME-UP-BUTTON-WHEN-LOW: U5.15 (QA); also elsewhere on the board

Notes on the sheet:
SPI GPIO OUTPUT EXPANSION

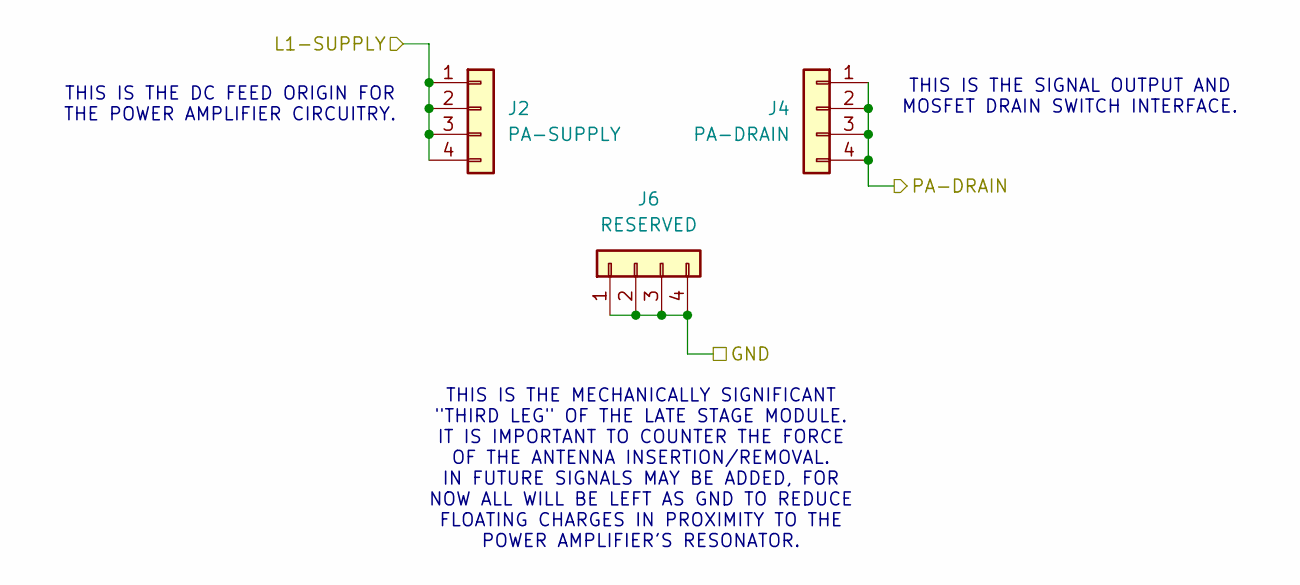
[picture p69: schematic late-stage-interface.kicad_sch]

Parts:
J2: PA-SUPPLY; PinHeader_1x04_P2.54mm_Vertical
J4: PA-DRAIN; PinHeader_1x04_P2.54mm_Vertical
J6: RESERVED; PinHeader_1x04_P2.54mm_Vertical

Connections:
/Late Stage Interface/L1-SUPPLY: J2.1, J2.2, J2.3, J2.4; also elsewhere on the board
GND: J6.1, J6.2, J6.3, J6.4; also elsewhere on the board
RECEIVED-SIGNAL: J4.1, J4.2, J4.3, J4.4; also elsewhere on the board

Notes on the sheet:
THIS IS THE DC FEED ORIGIN FOR THE POWER AMPLIFIER CIRCUITRY.
THIS IS THE MECHANICALLY SIGNIFICANT "THIRD LEG" OF THE LATE STAGE MODULE. IT IS IMPORTANT TO COUNTER THE FORCE OF THE ANTENNA INSERTION/REMOVAL. IN FUTURE SIGNALS MAY BE ADDED, FOR NOW ALL WILL BE LEFT AS GND TO REDUCE FLOATING CHARGES IN PROXIMITY TO THE POWER AMPLIFIER'S RESONATOR.
THIS IS THE SIGNAL OUTPUT AND MOSFET DRAIN SWITCH INTERFACE.

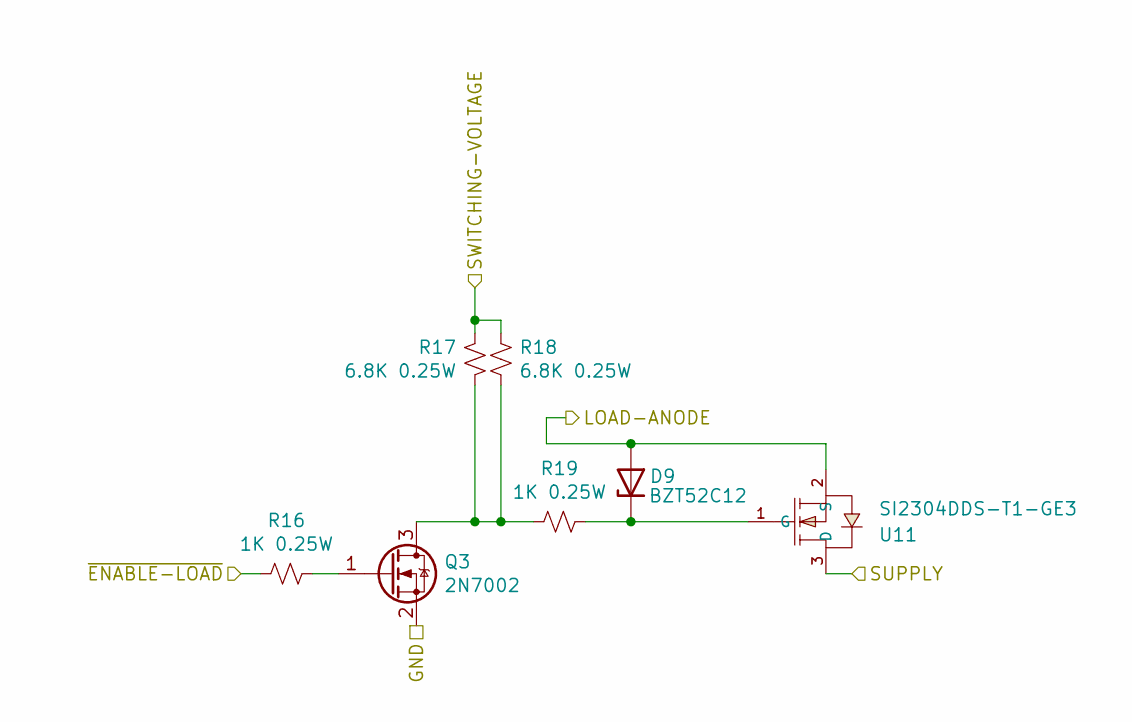
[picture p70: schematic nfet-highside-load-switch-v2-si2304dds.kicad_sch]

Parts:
D9: BZT52C12; D_SOD-123; MPN BZT52C12; LCSC Part # C173429
Q3: 2N7002; SOT-23; MPN 2N7002; LCSC Part # C8545
R16, R19: 1K 0.25W; R_1206_3216Metric; MPN 1206W4F1001T5; LCSC Part # C4410
R17, R18: 6.8K 0.25W; R_1206_3216Metric; MPN 1206W4F6801T5E; LCSC Part # C26034
U11: SI2304DDS-T1-GE3; SOT-23-3_L2.9-W1.6-P1.90-LS2.8-BR; MPN SI2304DDS-T1-GE3; LCSC Part # C56372

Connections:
12V: U11.3 (D); also elsewhere on the board
24V: R17.2, R18.2
/Late Stage Interface/L1-SUPPLY: D9.2 (A), U11.2 (S); also elsewhere on the board
GND: Q3.2 (S); also elsewhere on the board
unnamed: D9.1 (K), R19.1, U11.1 (G)
unnamed: Q3.3 (D), R17.1, R18.1, R19.2
unnamed: Q3.1 (G), R16.1
PA-DRIVE-PWM: R16.2; also elsewhere on the board

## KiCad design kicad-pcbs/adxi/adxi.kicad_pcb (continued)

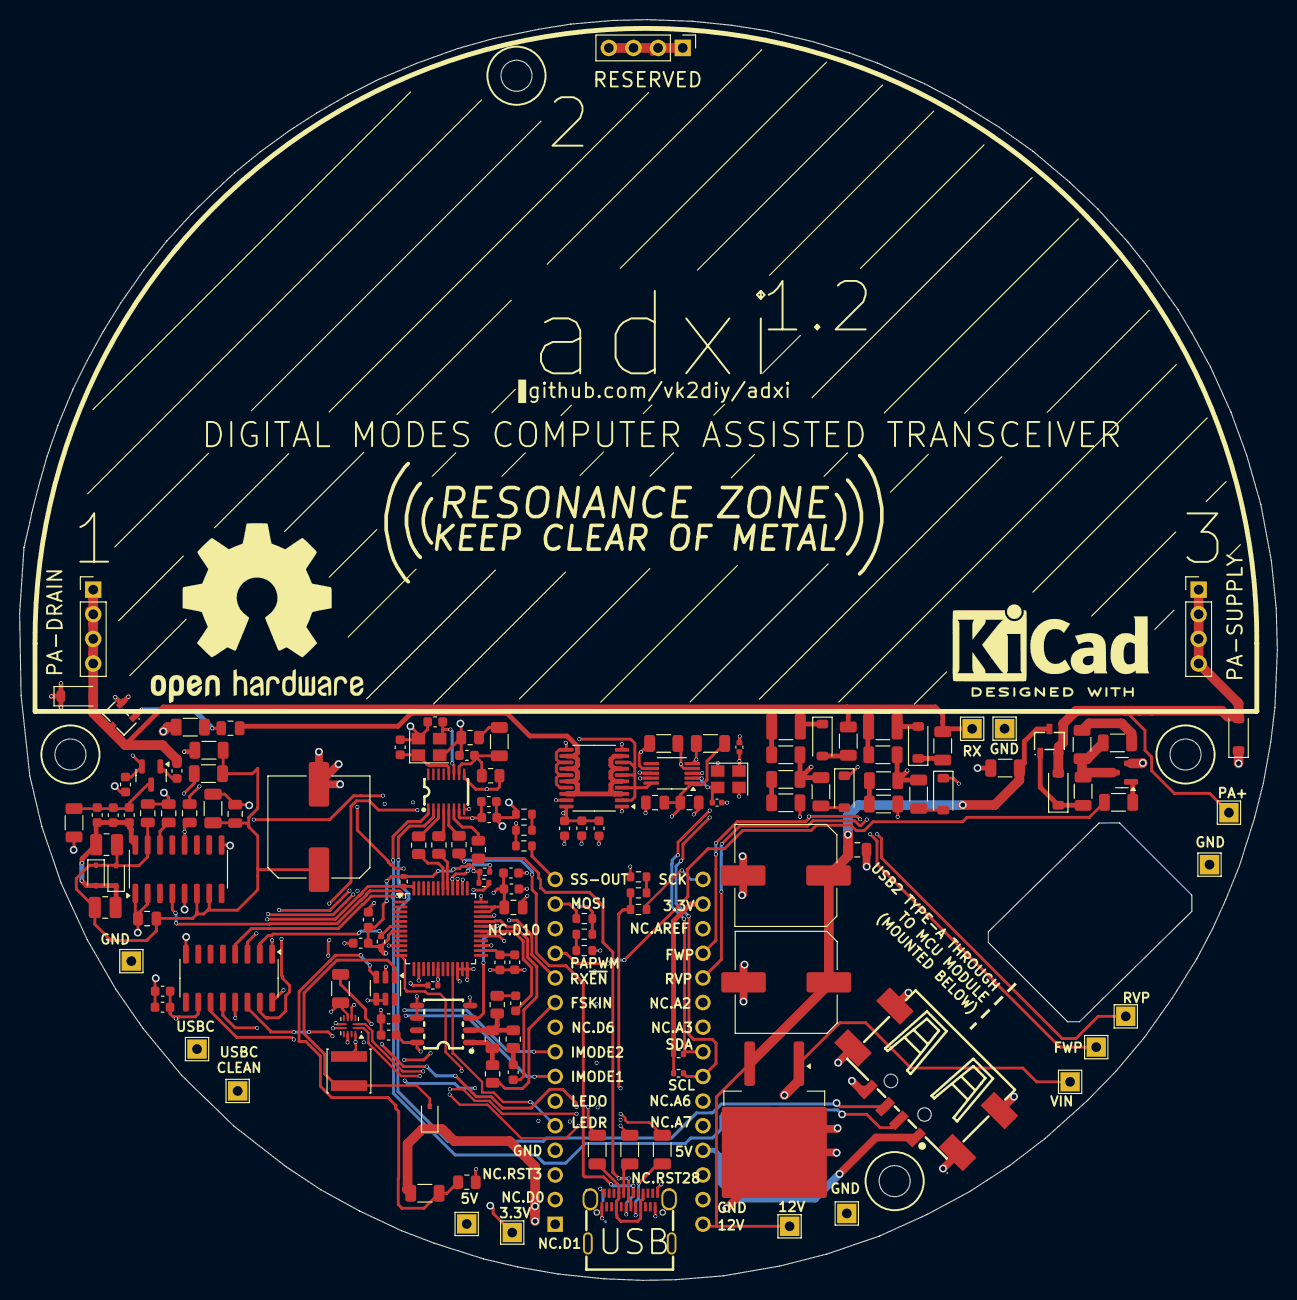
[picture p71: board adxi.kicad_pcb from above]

Board: 4 copper layers, 129.7 x 130.0 mm, 150 parts (1 on the bottom side), 91 nets.

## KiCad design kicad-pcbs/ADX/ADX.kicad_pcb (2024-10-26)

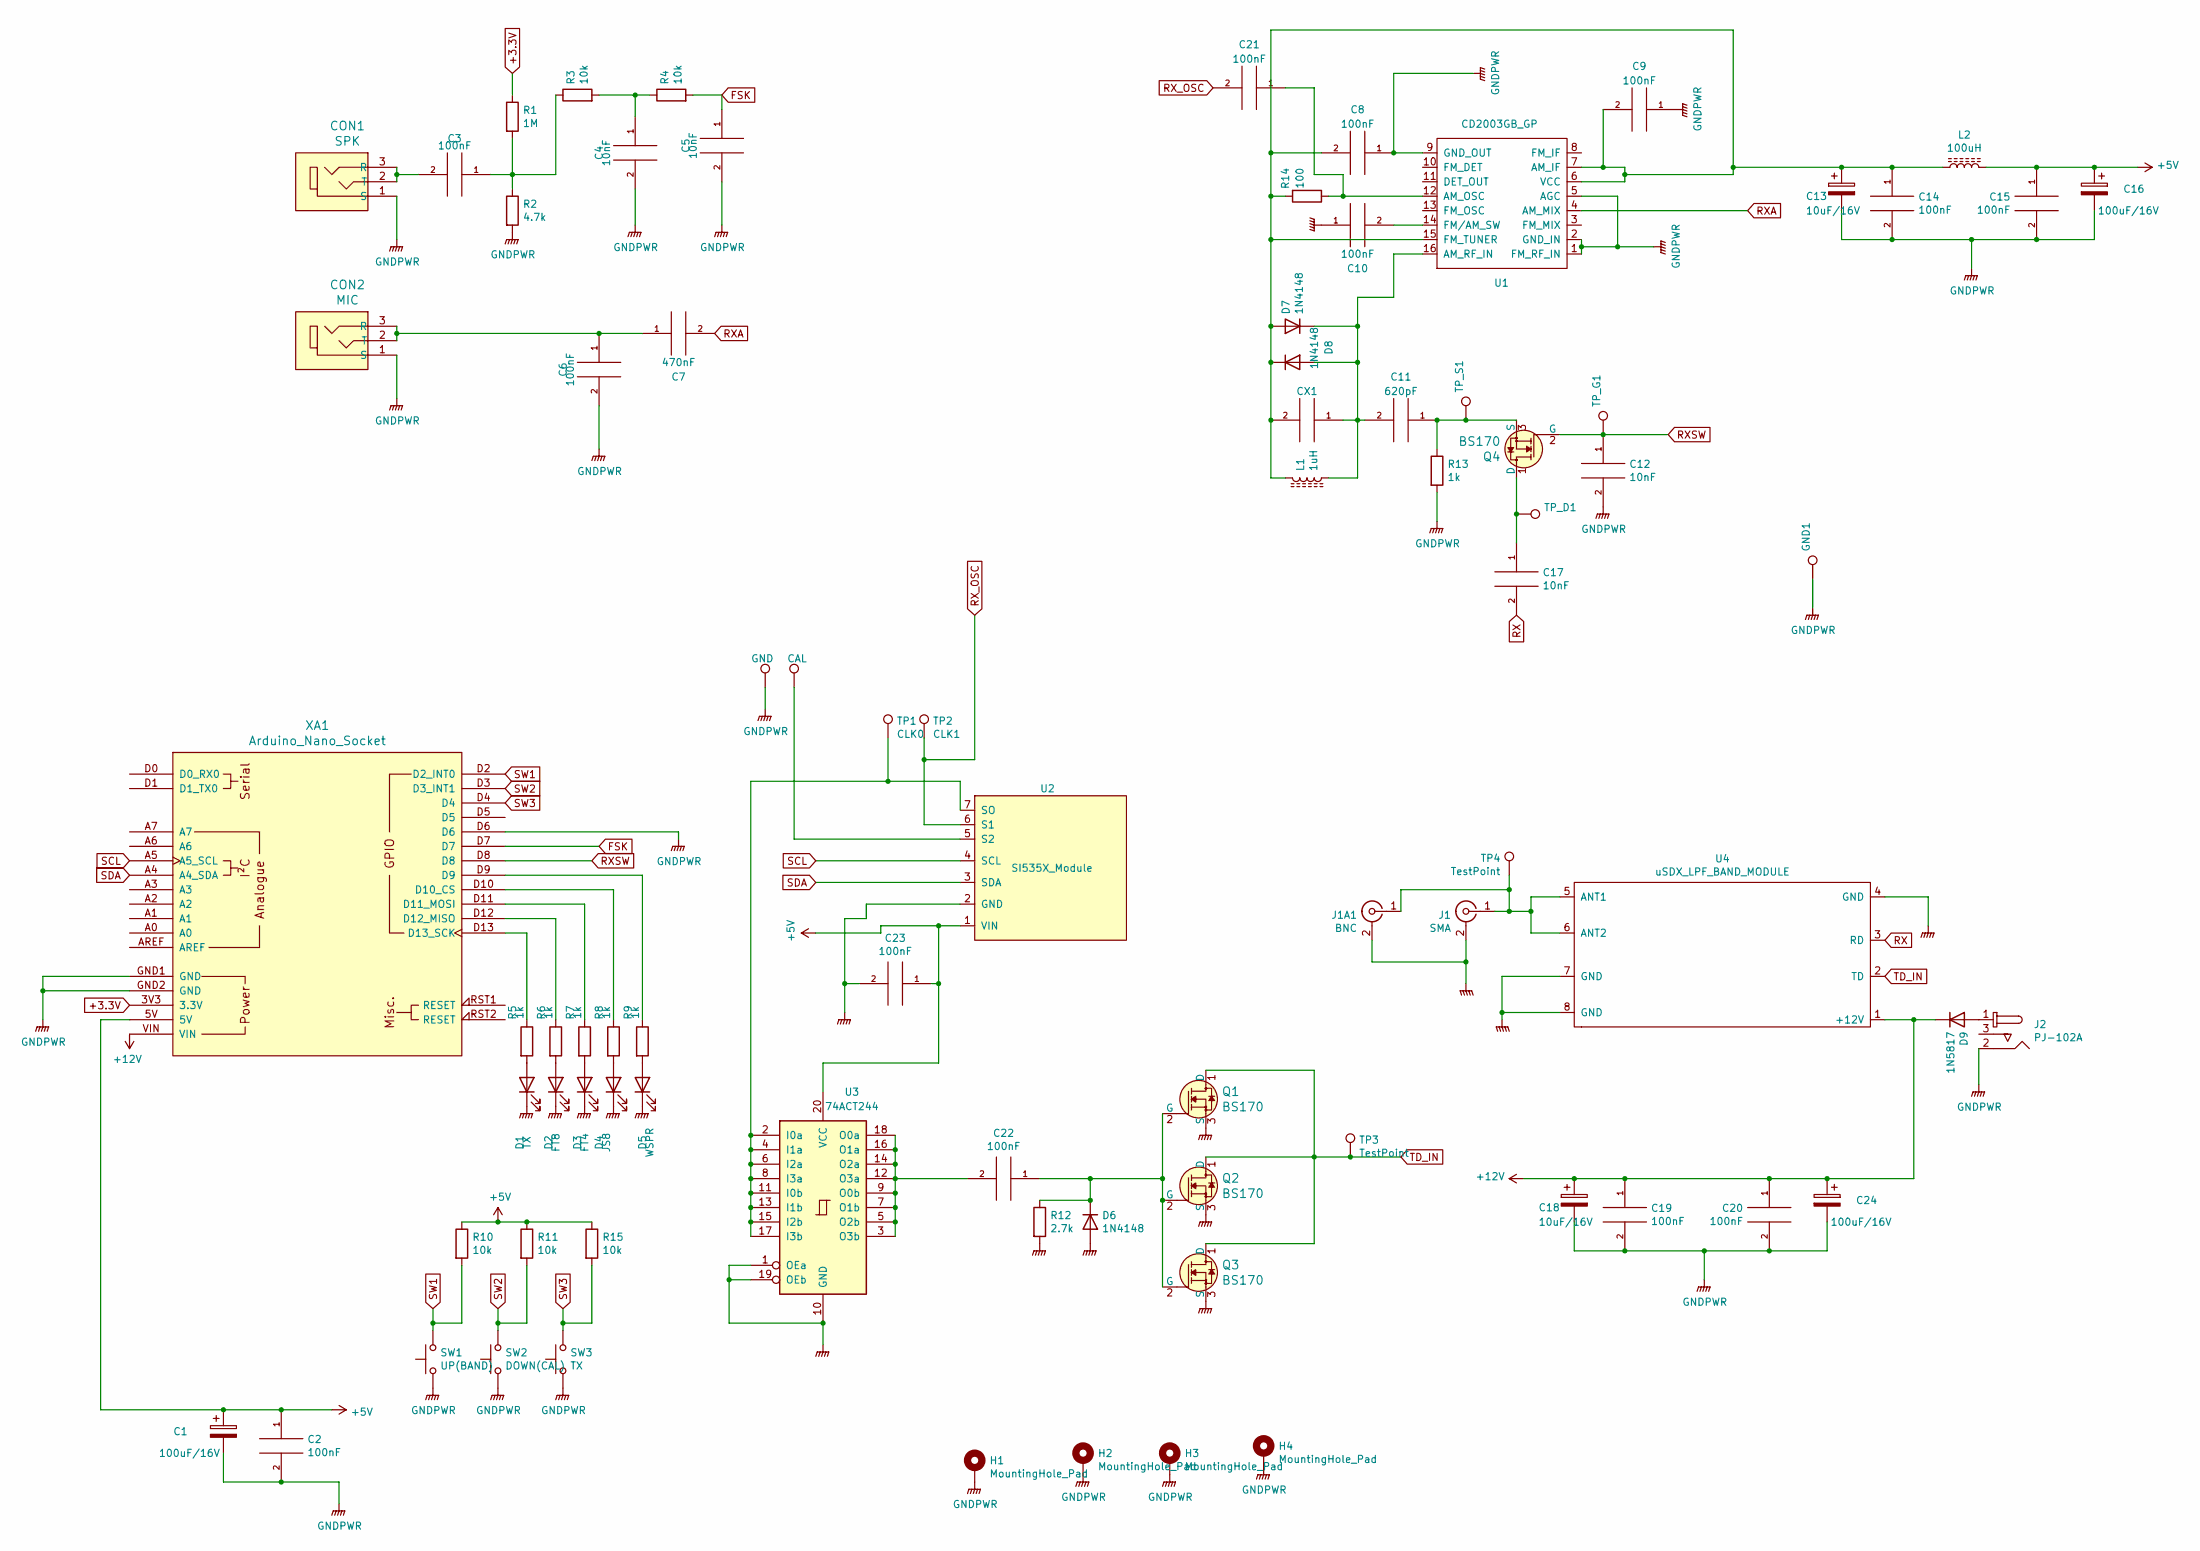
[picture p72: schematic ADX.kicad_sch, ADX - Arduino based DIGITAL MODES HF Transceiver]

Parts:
C1, C16, C24: 100uF/16V; CP_Radial_D5.0mm_P2.50mm
C2, C3, C6, C8, C9, C10, C14, C15, C19, C20, C21, C22, C23: 100nF; C_Disc_D3.0mm_W1.6mm_P2.50mm
C4, C5: 10nF; C_Disc_D3.0mm_W1.6mm_P2.50mm
C7: 470nF; C_Disc_D3.0mm_W1.6mm_P2.50mm
C11: 620pF; C_Disc_D3.0mm_W1.6mm_P2.50mm
C12, C17: 10nF; C_Disc_D3.0mm_W2.0mm_P2.50mm
C13, C18: 10uF/16V; CP_Radial_D5.0mm_P2.50mm
CON1: SPK; Headphone_Jack_3.5mm_SJ1-3523N; MPN SJ1-3523N; Digi-Key_PN CP1-3523N-ND
CON2: MIC; Headphone_Jack_3.5mm_SJ1-3523N; MPN SJ1-3523N; Digi-Key_PN CP1-3523N-ND
CX1: C_Disc_D3.0mm_W1.6mm_P2.50mm
D1: TX; LED_D3.0mm
D2: FT8; LED_D3.0mm
D3: FT4; LED_D3.0mm
D4: JS8; LED_D3.0mm
D5: WSPR; LED_D3.0mm
D6: 1N4148; D_A-405_P2.54mm_Vertical_AnodeUp
D7, D8: 1N4148; D_A-405_P2.54mm_Vertical_KathodeUp
D9: 1N5817; D_A-405_P2.54mm_Vertical_KathodeUp
GND1: TestPoint_THTPad_2.0x2.0mm_Drill1.0mm
H1, H2, H3, H4: MountingHole_Pad; MountingHole_3.2mm_M3_ISO7380_Pad
J1: SMA; SMA_Samtec_SMA-J-P-X-ST-EM1_EdgeMount
J1A1: BNC; BNC_Amphenol_B6252HB-NPP3G-50_Horizontal
J2: PJ-102A; Barrel_Jack_5.5mmODx2.1mmID_PJ-102A; MPN PJ-102A; Digi-Key_PN CP-102A-ND
L1: 1uH; L_Toroid_Vertical_L10.0mm_W5.0mm_P5.08mm
L2: 100uH; R_Axial_DIN0204_L3.6mm_D1.6mm_P2.54mm_Vertical
Q1, Q2, Q3: BS170; TO-92_HandSolder; MPN BS170; Digi-Key_PN BS170-ND
Q4: BS170; TO-92L_HandSolder; MPN BS170; Digi-Key_PN BS170-ND
R1: 1M; R_Axial_DIN0204_L3.6mm_D1.6mm_P1.90mm_Vertical
R2: 4.7k; R_Axial_DIN0204_L3.6mm_D1.6mm_P1.90mm_Vertical
R3, R4, R10, R11, R15: 10k; R_Axial_DIN0204_L3.6mm_D1.6mm_P1.90mm_Vertical
R5, R6, R7, R8, R9, R13: 1k; R_Axial_DIN0204_L3.6mm_D1.6mm_P1.90mm_Vertical
R12: 2.7k; R_Axial_DIN0204_L3.6mm_D1.6mm_P1.90mm_Vertical
R14: 100; R_Axial_DIN0204_L3.6mm_D1.6mm_P1.90mm_Vertical
SW1: UP(BAND); SW_PUSH_6mm
SW2: DOWN(CAL); SW_PUSH_6mm
SW3: TX; SW_PUSH_6mm
TP1: CLK0; TestPoint_THTPad_2.0x2.0mm_Drill1.0mm
TP2: CLK1; TestPoint_THTPad_2.0x2.0mm_Drill1.0mm
TP3, TP4: TestPoint; TestPoint_THTPad_2.0x2.0mm_Drill1.0mm
TP7: GND; TestPoint_THTPad_2.0x2.0mm_Drill1.0mm
TP8: CAL; TestPoint_THTPad_2.0x2.0mm_Drill1.0mm
TP_D1: TestPoint_THTPad_1.0x1.0mm_Drill0.5mm
TP_G1: TestPoint_THTPad_1.0x1.0mm_Drill0.5mm
TP_S1: TestPoint_THTPad_1.0x1.0mm_Drill0.5mm
U1: CD2003GB_GP; DIP-16_W7.62mm_Socket_LongPads
U2: SI535X_Module; SI5351 Module_Vertical
U3: 74ACT244; DIP-20_W7.62mm_LongPads
U4: uSDX_LPF_BAND_MODULE; uSDX_LPF_Band_Module
XA1: Arduino_Nano_Socket

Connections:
+3.3V: R1.1, XA1.3V3 (3.3V)
+5V: C1.1, C2.1, C15.1, C16.1, C23.1, L2.1, R10.1, R11.1, R15.1, U2.1 (VIN), U3.20 (VCC), XA1.5V
+12V: C18.1, C19.1, C20.1, C24.1, D9.1 (K), U4.1 (+12V), XA1.VIN
FSK: C5.1, R4.2, XA1.D7
GNDPWR: C1.2, C2.2, C4.2, C5.2, C6.2, C8.1, C9.1, C10.1, C12.2, C13.2, C14.2, C15.2, C16.2, C18.2, C19.2, C20.2, C23.2, C24.2, CON1.1 (S), CON2.1 (S), D1.1 (K), D2.1 (K), D3.1 (K), D4.1 (K), D5.1 (K), D6.2 (A), GND1.1, H1.1, H2.1, H3.1, H4.1, J1.2 (Ext), J1A1.2 (Ext), J2.2, Q1.3 (S), Q2.3 (S), Q3.3 (S), R2.2, R12.2, R13.2, SW1.1, SW2.1, SW3.1, TP7.1, U1.1 (FM_RF_IN), U1.2 (GND_IN), U1.5 (AGC), U1.9 (GND_OUT), U2.2 (GND), U3.1 (OEa), U3.10 (GND), U3.19 (OEb), U4.4 (GND), U4.7 (GND), U4.8 (GND), XA1.D6, XA1.GND1 (GND), XA1.GND2 (GND)
unnamed: C3.1, R1.2, R2.1, R3.1
unnamed: C3.2, CON1.2 (T), CON1.3 (R)
unnamed: C4.1, R3.2, R4.1
unnamed: C6.1, C7.1, CON2.2 (T), CON2.3 (R)
unnamed: C10.2, U1.14 (FM/AM_SW)
unnamed: C11.1, Q4.3 (S), R13.1, TP_S1.1
unnamed: C11.2, CX1.1, D7.1 (K), D8.2 (A), L1.1, U1.16 (AM_RF_IN)
unnamed: C8.2, C9.2, C13.1, C14.1, CX1.2, D7.2 (A), D8.1 (K), L1.2, L2.2, R14.2, U1.6 (VCC), U1.7 (AM_IF), U1.15 (FM_TUNER)
unnamed: C17.1, Q4.1 (D), TP_D1.1
unnamed: C21.1, R14.1, U1.12 (AM_OSC)
unnamed: C22.1, D6.1 (K), Q1.2 (G), Q2.2 (G), Q3.2 (G), R12.1
unnamed: C22.2, U3.3 (O3b), U3.5 (O2b), U3.7 (O1b), U3.9 (O0b), U3.12 (O3a), U3.14 (O2a), U3.16 (O1a), U3.18 (O0a)
unnamed: D1.2 (A), R5.2
unnamed: D2.2 (A), R6.2
unnamed: D3.2 (A), R7.2
unnamed: D4.2 (A), R8.2
unnamed: D5.2 (A), R9.2
unnamed: D9.2 (A), J2.1
unnamed: J1.1 (In), J1A1.1 (In), TP4.1, U4.5 (ANT1), U4.6 (ANT2)
unnamed: R5.1, XA1.D13 (D13_SCK)
unnamed: R6.1, XA1.D12 (D12_MISO)
unnamed: R7.1, XA1.D11 (D11_MOSI)
unnamed: R8.1, XA1.D10 (D10_CS)
unnamed: R9.1, XA1.D9
unnamed: TP1.1, U2.7 (SO), U3.2 (I0a), U3.4 (I1a), U3.6 (I2a), U3.8 (I3a), U3.11 (I0b), U3.13 (I1b), U3.15 (I2b), U3.17 (I3b)
unnamed: TP8.1, U2.5 (S2)
RX: C17.2, U4.3 (RD)
RXA: C7.2, U1.4 (AM_MIX)
RXSW: C12.1, Q4.2 (G), TP_G1.1, XA1.D8
RX_OSC: C21.2, TP2.1, U2.6 (S1)
SCL: U2.4 (SCL), XA1.A5 (A5_SCL)
SDA: U2.3 (SDA), XA1.A4 (A4_SDA)
SW1: R10.2, SW1.2, XA1.D2 (D2_INT0)
SW2: R11.2, SW2.2, XA1.D3 (D3_INT1)
SW3: R15.2, SW3.2, XA1.D4
TD_IN: Q1.1 (D), Q2.1 (D), Q3.1 (D), TP3.1, U4.2 (TD)

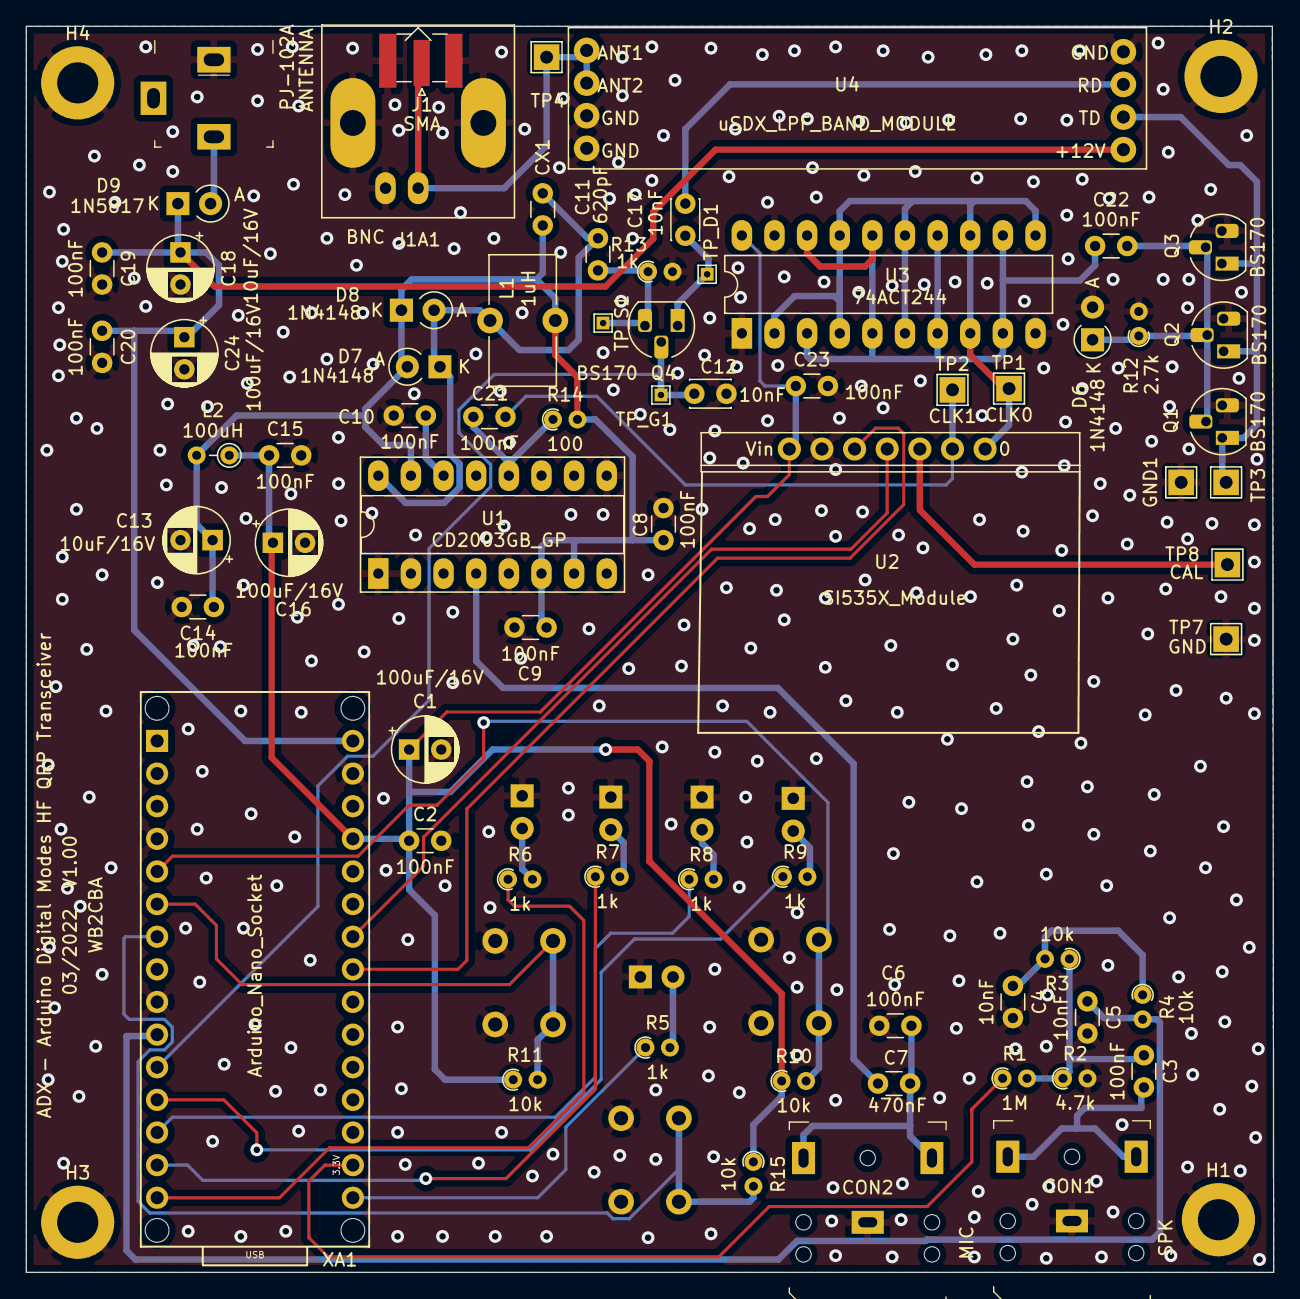
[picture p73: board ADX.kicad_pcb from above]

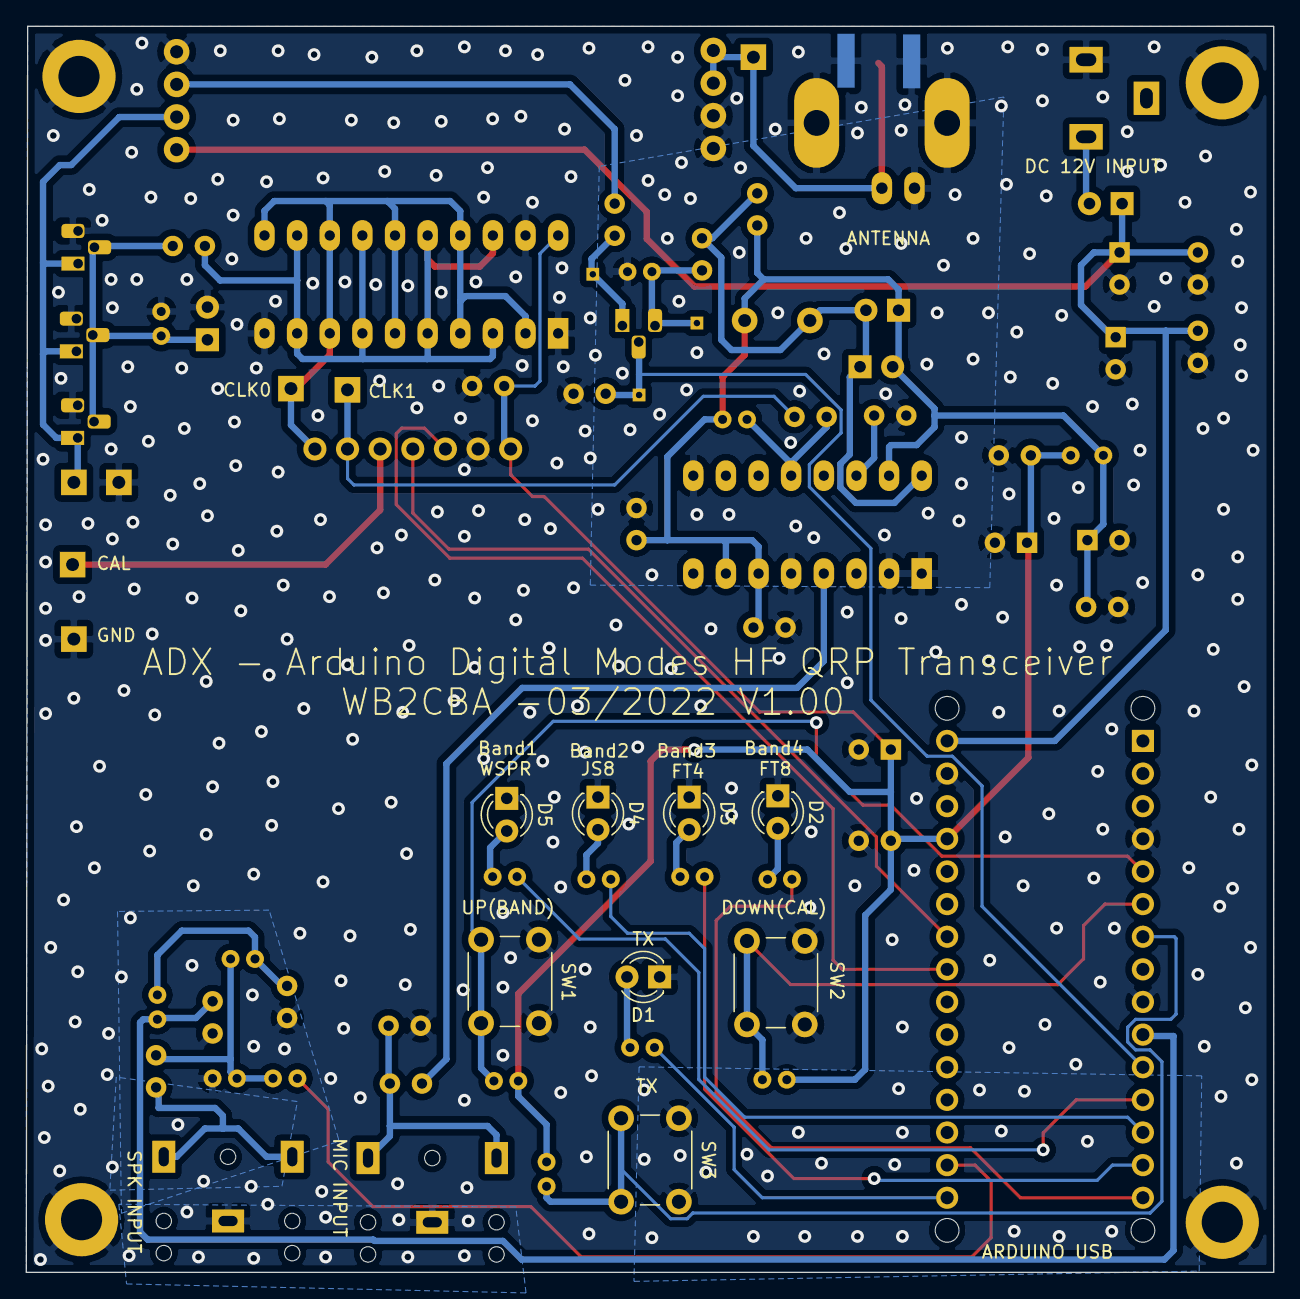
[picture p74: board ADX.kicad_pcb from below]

Board: 2 copper layers, 97.1 x 97.0 mm, 82 parts (8 on the bottom side), 41 nets.

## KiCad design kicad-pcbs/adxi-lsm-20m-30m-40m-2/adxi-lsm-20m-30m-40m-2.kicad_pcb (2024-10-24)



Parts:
C5: 22pF; C_0805_2012Metric; MPN CL21C220JBANNNC; LCSC Part # C1804
C7, C14, C16, C21, C36, C44: 330pF; C_0603_1608Metric; MPN CL10C331JB8NNNC; LCSC Part # C1664
C11: 470pF; C_0603_1608Metric; MPN 0603B471K500NT; LCSC Part # C1620
C12: 6.8pF; C_0603_1608Metric; MPN 0603CG6R8C500NT; LCSC Part # C1679
C13, C17, C20, C37: 100pF; C_0805_2012Metric; MPN CL21C101JBANNNC; LCSC Part # C1790
C18: 47pF; C_0805_2012Metric; MPN CL21C470JBANNNC; LCSC Part # C14857
C19, C39, C40: 470pF; C_0805_2012Metric; MPN 0805B471K500NT; LCSC Part # C1743
C28: 470pF; C_0603_1608Metric; MPN CC0603JRNPO9BN471; LCSC Part # C106211
C29, C41, C42: 150pF; C_0603_1608Metric; MPN 0603B151K500NT; LCSC Part # C1594
C30: 3.3nF; C_0603_1608Metric; MPN CL10B332KB8NNNC; LCSC Part # C1613
C31: 4.7pF; C_0603_1608Metric; MPN 0603CG4R7C500NT; LCSC Part # C1669
C32: 68pF; C_0603_1608Metric; MPN CL10C680JB8NNNC; LCSC Part # C28262
C33: 33pF; C_1206_3216Metric; MPN GRM31A5C2J330JW01D; LCSC Part # C415521
C35: 2.2nF; C_0805_2012Metric; MPN CL21C222JBFNNNE; LCSC Part # C28260
C38: 680pF; C_0805_2012Metric; MPN CC0805JRNPO9BN681; LCSC Part # C107121
C43: 1nF; C_1206_3216Metric; MPN 1206B102K202NT; LCSC Part # C9196
J1: ANT; ANT-TH_KH-BNC50-3511
J2: PA-DRAIN; PinSocket_1x04_P2.54mm_Vertical
J3: PA-SUPPLY; PinSocket_1x04_P2.54mm_Vertical
J4: C1-GND; PinSocket_1x04_P2.54mm_Vertical
JP4: 20M-B; SolderJumper-2_P1.3mm_Open_RoundedPad1.0x1.5mm
JP5: 30M-B; SolderJumper-2_P1.3mm_Open_RoundedPad1.0x1.5mm
JP6: 40M-B; SolderJumper-2_P1.3mm_Open_RoundedPad1.0x1.5mm
JP20: 40M-C; SolderJumper-2_P1.3mm_Open_RoundedPad1.0x1.5mm
JP26: 30M-C; SolderJumper-2_P1.3mm_Open_RoundedPad1.0x1.5mm
JP27: 20M-C; SolderJumper-2_P1.3mm_Open_RoundedPad1.0x1.5mm
JP28: 20M-D; SolderJumper-2_P1.3mm_Open_RoundedPad1.0x1.5mm
JP29: 30M-D; SolderJumper-2_P1.3mm_Open_RoundedPad1.0x1.5mm
JP30: 40M-D; SolderJumper-2_P1.3mm_Open_RoundedPad1.0x1.5mm
JP34: 20M-A; SolderJumper-2_P1.3mm_Open_RoundedPad1.0x1.5mm
JP35: 30M-A; SolderJumper-2_P1.3mm_Open_RoundedPad1.0x1.5mm
JP36: 40M-A; SolderJumper-2_P1.3mm_Open_RoundedPad1.0x1.5mm
L1, L94: 1.5uH; L_0603_1608Metric; MPN LQM18PN1R5MFRL; LCSC Part # C337909
L2: 4.7uH; L_0603_1608Metric; MPN LQM18PN4R7MFRL; LCSC Part # C114862
L3, L4: 22uH; L_Sunlord_SWPA3015S; MPN SWPA3015S220MT; LCSC Part # C83438
L11, L23, L69, L70: 2.2uH; L_0603_1608Metric; MPN LS0603-2R2J-N; LCSC Part # C2935084
L22, L83: 0.56uH; L_0805_2012Metric; MPN FHW0805UFR56JST; LCSC Part # C304279
L24, L58, L59, L60, L61, L62, L63, L64, L65, L66, L67, L68: 680nH; L_0603_1608Metric; MPN CMH160808BR68MT; LCSC Part # C394955
L25, L26: 3.9uH; L_1812_4532Metric; MPN FHW1812IF3R9JST; LCSC Part # C394117
L77, L78: 5.6uH; L_0805_2012Metric; MPN CMP201209XD5R6MT; LCSC Part # C395017
L79, L80, L81, L82: 6.8uH; L_0805_2012Metric; MPN LB2012T6R8M; LCSC Part # C223247
L84: 1.2uH; L_0805_2012Metric; MPN YWLD2012-1R2K; LCSC Part # C5563768
L85: 390nH; L_0603_1608Metric; MPN LCF0603-R39J-T; LCSC Part # C251955
L88, L92, L93: 1uH; L_1812_4532Metric; MPN CMI453215U1R0KT; LCSC Part # C75658
L90: 820nH; L_0805_2012Metric; MPN FHW0805UFR82JST; LCSC Part # C393988

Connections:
/GND: C13.2, C16.2, C17.2, C19.2, C20.2, C21.2, C36.2, C37.2, C38.2, C39.2, C40.2, C41.2, C42.2, C43.2, C44.2, J4.1, J4.2, J4.3, J4.4, JP28.1 (A), JP29.1 (A), JP30.1 (A)
unnamed: C12.2, C33.2, L3.1
unnamed: C13.1, C44.1, L22.1, L90.2
unnamed: C16.1, L22.2, L83.1
unnamed: C18.1, L84.1, L85.2
unnamed: C18.2, C19.1
unnamed: C20.1, L60.1, L61.1, L84.2
unnamed: C21.1, L62.2, L63.2, L88.1
unnamed: C5.2, C28.2, L1.1
unnamed: C31.2, C32.1
unnamed: C32.2, L77.1, L78.1
unnamed: C36.1, L64.1, L66.1, L88.2
unnamed: C38.1, L11.1, L23.1, L58.1, L65.1, L79.2, L80.2, L81.2, L82.2
unnamed: C39.1, L93.2, L94.1
unnamed: C40.1, L92.1, L94.2
unnamed: C41.1, L24.2, L59.2, L69.2, L70.2, L93.1
unnamed: C43.1, L2.2, L90.1
unnamed: J1.2 (Ext), J2.1, J2.2, J2.3, J2.4
unnamed: J1.1 (In), JP4.2 (B), JP5.2 (B), JP6.2 (B)
unnamed: J3.1, J3.2, J3.3, J3.4, L25.1
unnamed: C17.1, JP4.1 (A), L83.2
unnamed: C37.1, JP5.1 (A), L67.2, L68.2
unnamed: C42.1, JP6.1 (A), L92.2
unnamed: C14.1, C30.1, JP20.1 (A)
unnamed: JP20.2 (B), JP26.2 (B), JP27.2 (B), JP34.1 (A), JP35.1 (A), JP36.1 (A), L26.2
unnamed: C7.1, C11.1, JP26.1 (A)
unnamed: C29.1, C35.1, JP27.1 (A)
unnamed: C29.2, C35.2, JP28.2 (B)
unnamed: C7.2, C11.2, JP29.2 (B)
unnamed: C14.2, C30.2, JP30.2 (B)
unnamed: C5.1, C28.1, JP34.2 (B)
unnamed: C12.1, C33.1, JP35.2 (B)
unnamed: C31.1, JP36.2 (B)
unnamed: L1.2, L2.1
unnamed: L3.2, L4.1
unnamed: L4.2, L85.1
unnamed: L11.2, L69.1
unnamed: L23.2, L70.1
unnamed: L24.1, L65.2
unnamed: L25.2, L26.1
unnamed: L58.2, L59.1
unnamed: L60.2, L62.1
unnamed: L61.2, L63.1
unnamed: L64.2, L67.1
unnamed: L66.2, L68.1
unnamed: L77.2, L78.2, L79.1, L80.1, L81.1, L82.1

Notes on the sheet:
RF CHOKE
20m 30m 40m SOLDER SELECTABLE LATE STAGE MODULE (CLASS E PA + LOW PASS FILTER)
7th order Butterworth approximation (13.57% error, 7 parts): C1_lpf=150pF L1_lpf=1µH C2_lpf=470pF L2_lpf=1.5µH C3_lpf=470pF L3_lpf=1µH C4_lpf=150pF
RF choke configuration was regenerated using https://github.com/vk2diy/classe2-calculator from after a previous inefficient (high SRF target) design was discarded. This approach saved reconfiguration/respecification of all other components. $ ./classe2 --equivalent-inductor 7.755uh -b 20m 30m 40m -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
$0.10 SRF>23MHz / 1.3Ω / 520mA
6.2uH RESONATOR 20M (14-14.35MHz)
2.67% error, 3 parts
5th order Butterworth approximation (10.22% error, 5 parts): C1_lpf=100pF L1_lpf=0.56µH C2_lpf=330pF L2_lpf=0.56µH C3_lpf=100pF
30M
ANTENNA
20M Band (14-14.35 MHz)
=140.426pF
40M Band (7-7.3 MHz)
$0.21 7.8uH SRF 135MHz / 2x0.6=1.2Ω / 750mA
$0.09 SRF>100MHz 0.23Ω 800mA
$0.06 SRF>40MHz 0.44Ω 620mA
'PI'-STYLE
Class E Power Amplifier (PA) and low pass filter module schematic component specifications were generated using https://github.com/vk2diy/classe2-calculator $ ./classe2 -p 5 -v 12 -b 20m 30m 40m -q 40 -t infinite --l1 7.755uh -m SI2304DDS ...
C1 = 0.1836 ÷ (2π⋅f⋅R) where: f = Frequency (Hz) R = Resistance (Ω) - usually 50
LOW PASS FILTER (LPF)
5.95% error, 4 parts L_match: 0.519µH (0.68µH || 2.2µH) Series-parallel are for higher current. C_match: 680pF (680pF)
$0.04 SRF>32MHz 0.25Ω 500mA
'T'-STYLE
1.79% error, 4 parts L1_match: 0.39µH (0.39µH), C_match: 517pF (47pF + 470pF), L2_match: 1.2µH (1.2µH)
VK2DIY
BAND SELECTION
'L'-STYLE
MATCHING NETWORK
20M
=300pF
C1 CAP
SOKAL 'C2'
$0.15 SRF>40MHz / 0.67Ω / 620mA
30M Band (10.1-10.15 MHz)
43.96uH RESONATOR 30M (10.1-10.15MHz)
$0.16 SRF>38MHz 0.12Ω 540mA
SOKAL 'L1'
7.2~=7.5uH RESONATOR 40M (7-7.3MHz)
PA RESONATOR INDUCTANCE
SOKAL 'L2'



Board: 2 copper layers, 126.3 x 71.1 mm, 81 parts (3 on the bottom side), 46 nets.

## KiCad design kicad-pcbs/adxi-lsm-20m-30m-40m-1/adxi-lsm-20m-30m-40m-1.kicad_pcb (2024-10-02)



Board: 2 copper layers, 126.3 x 71.1 mm, 139 parts (3 on the bottom side), 94 nets.

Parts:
C1, C2, C4, C6, C8, C16, C17: 10pF; C_1206_3216Metric
C3: 8.2pF; C_1206_3216Metric
C5, C11: 12pF; C_1206_3216Metric
C7, C13, C34: 20pF; C_1206_3216Metric
C9, C33: 47pF; C_0805_2012Metric
C10, C28, C31: 100pF; C_0805_2012Metric
C12: 15pF; C_1206_3216Metric
C14: 82pF; C_1206_3216Metric
C15: 220pF; C_0805_2012Metric
C18, C19, C20, C21, C25: 1pF; C_1206_3216Metric
C22, C23, C24: 33pF; C_1206_3216Metric
C26, C32: 470pF; C_0805_2012Metric
C27: 1nF; C_1206_3216Metric
C30: 68pF; C_0603_1608Metric
J1: ANT; ANT-TH_KH-BNC50-3511
J2: PA-DRAIN; PinSocket_1x04_P2.54mm_Vertical
J3: PA-SUPPLY; PinSocket_1x04_P2.54mm_Vertical
J4: RFC-GND; PinSocket_1x04_P2.54mm_Vertical
JP1: 20M-A; SolderJumper-2_P1.3mm_Open_RoundedPad1.0x1.5mm
JP2: 30M-A; SolderJumper-2_P1.3mm_Open_RoundedPad1.0x1.5mm
JP3: 40M-A; SolderJumper-2_P1.3mm_Open_RoundedPad1.0x1.5mm
JP4: 20M-B; SolderJumper-2_P1.3mm_Open_RoundedPad1.0x1.5mm
JP5: 30M-B; SolderJumper-2_P1.3mm_Open_RoundedPad1.0x1.5mm
JP6, JP20: 40M-C; SolderJumper-2_P1.3mm_Open_RoundedPad1.0x1.5mm
JP7: 10PF; SolderJumper-2_P1.3mm_Open_RoundedPad1.0x1.5mm
JP8: 20PF; SolderJumper-2_P1.3mm_Open_RoundedPad1.0x1.5mm
JP9: 47PF; SolderJumper-2_P1.3mm_Open_RoundedPad1.0x1.5mm
JP10: 100PF; SolderJumper-2_P1.3mm_Open_RoundedPad1.0x1.5mm
JP11: 220PF; SolderJumper-2_P1.3mm_Open_RoundedPad1.0x1.5mm
JP12: 470PF; SolderJumper-2_P1.3mm_Open_RoundedPad1.0x1.5mm
JP13: 1NF; SolderJumper-2_P1.3mm_Open_RoundedPad1.0x1.5mm
JP14: 0.15UH; SolderJumper-2_P1.3mm_Open_RoundedPad1.0x1.5mm
JP15: 0.22UH; SolderJumper-2_P1.3mm_Open_RoundedPad1.0x1.5mm
JP16: 0.47UH; SolderJumper-2_P1.3mm_Open_RoundedPad1.0x1.5mm
JP17: 0.94UH; PinHeader_1x03_P1.00mm_Vertical
JP18: 2.2UH; PinHeader_1x03_P1.00mm_Vertical
JP19: 9.27UH; PinHeader_1x03_P1.00mm_Vertical
JP21: 0.94UH.; SolderJumper-2_P1.3mm_Open_RoundedPad1.0x1.5mm
JP22: 2.2UH.; SolderJumper-2_P1.3mm_Open_RoundedPad1.0x1.5mm
JP23: 4.7UH.; SolderJumper-2_P1.3mm_Open_RoundedPad1.0x1.5mm
JP24: 9.27UH.; SolderJumper-2_P1.3mm_Open_RoundedPad1.0x1.5mm
JP25: 4.7UH; PinHeader_1x03_P1.00mm_Vertical
JP26: 30M-C; SolderJumper-2_P1.3mm_Open_RoundedPad1.0x1.5mm
JP27: 20M-C; SolderJumper-2_P1.3mm_Open_RoundedPad1.0x1.5mm
JP28: 20M-D; SolderJumper-2_P1.3mm_Open_RoundedPad1.0x1.5mm
JP29: 30M-D; SolderJumper-2_P1.3mm_Open_RoundedPad1.0x1.5mm
JP30: 40M-D; SolderJumper-2_P1.3mm_Open_RoundedPad1.0x1.5mm
L1, L2, L3, L4, L5, L6, L7, L8, L9, L10, L12, L13, L14, L15, L16, L17, L18, L19, L20, L21: 10uH; L_1008_2520Metric
L11, L64, L65, L66, L68, L69, L70, L71: 2.2uH; L_Chilisin_NLC252018-2.92x2.50x2.20
L22, L25, L26, L27, L28, L29, L30, L31, L32, L33, L34, L35, L36, L37, L38, L39, L40, L41, L42, L43, L44, L45, L46, L47, L48, L49, L50, L51, L52, L53, L54, L55, L56, L57, L58, L61, L62, L63, L67, L72: 470nH; L_1008_2520Metric
L23, L24, L59, L60: 220nH; L_0805_2012Metric

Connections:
/GND: C1.2, C2.2, C4.2, C6.2, C8.2, C9.2, C10.2, C15.2, C16.2, C17.2, C18.2, C19.2, C20.2, C21.2, C22.2, C23.2, C24.2, C25.2, C26.2, C27.2, C34.1, J4.1, J4.2, J4.3, J4.4, JP28.1 (A), JP29.1 (A), JP30.1 (A), L57.2, L58.2, L59.2, L60.2, L61.2
unnamed: C2.1, C3.2, C4.1, C6.1, C8.1
unnamed: C7.2, L22.1
unnamed: C11.2, C12.1
unnamed: C12.2, C13.1
unnamed: C13.2, L23.1, L24.1
unnamed: C14.2, L11.1
unnamed: C28.1, C30.2
unnamed: C31.2, C32.1
unnamed: J1.2 (Ext), JP7.1 (A), JP8.1 (A), JP9.1 (A), JP10.1 (A), JP11.1 (A), JP12.1 (A), JP13.1 (A), JP14.1 (A), JP15.1 (A), JP16.1 (A), JP17.2
unnamed: J1.1 (In), JP4.2 (B), JP5.2 (B), JP6.2 (B)
unnamed: J2.1, J2.2, J2.3, J2.4, JP19.3, JP24.2 (B)
unnamed: J3.1, J3.2, J3.3, J3.4, JP20.2 (B), JP26.2 (B), JP27.2 (B), L1.1, L6.1, L25.1
unnamed: JP1.1 (A), JP2.1 (A), JP3.1 (A), L16.2, L21.2
unnamed: C7.1, JP1.2 (B)
unnamed: C11.1, JP2.2 (B)
unnamed: C14.1, JP3.2 (B)
unnamed: C16.1, C17.1, C18.1, C19.1, C20.1, C21.1, JP4.1 (A), L22.2
unnamed: C22.1, C23.1, C24.1, C25.1, JP5.1 (A), L23.2, L24.2
unnamed: C3.1, JP6.1 (A), L11.2
unnamed: C1.1, JP7.2 (B)
unnamed: C34.2, JP8.2 (B)
unnamed: C9.1, JP9.2 (B)
unnamed: C10.1, JP10.2 (B)
unnamed: C15.1, JP11.2 (B)
unnamed: C26.1, JP12.2 (B)
unnamed: C27.1, JP13.2 (B)
unnamed: JP14.2 (B), L58.1, L59.1
unnamed: JP15.2 (B), L60.1
unnamed: JP16.2 (B), L61.1
unnamed: JP17.1, L62.1
unnamed: JP17.3, JP18.2, JP21.2 (B)
unnamed: JP18.1, L64.1
unnamed: JP18.3, JP22.2 (B), JP25.2
unnamed: JP19.1, L68.1
unnamed: JP19.2, JP23.2 (B), JP25.3
unnamed: C31.1, JP20.1 (A)
unnamed: JP21.1 (A), L63.2
unnamed: JP22.1 (A), L64.2
unnamed: JP23.1 (A), L66.2, L67.2
unnamed: JP24.1 (A), L72.2
unnamed: JP25.1, L65.1, L67.1
unnamed: C5.2, C33.1, JP26.1 (A)
unnamed: C30.1, JP27.1 (A)
unnamed: C28.2, JP28.2 (B)
unnamed: C5.1, C33.2, JP29.2 (B)
unnamed: C32.2, JP30.2 (B)
unnamed: L1.2, L2.1, L6.2, L7.1
unnamed: L2.2, L3.1, L7.2, L8.1
unnamed: L3.2, L4.1, L8.2, L9.1
unnamed: L4.2, L5.1, L9.2, L10.1
unnamed: L5.2, L10.2, L12.1, L17.1
unnamed: L12.2, L13.1, L17.2, L18.1
unnamed: L13.2, L14.1, L18.2, L19.1
unnamed: L14.2, L15.1, L19.2, L20.1
unnamed: L15.2, L16.1, L20.2, L21.1
unnamed: L25.2, L26.1
unnamed: L26.2, L27.1
unnamed: L27.2, L28.1
unnamed: L28.2, L29.1
unnamed: L29.2, L30.1
unnamed: L30.2, L31.1
unnamed: L31.2, L32.1
unnamed: L32.2, L33.1
unnamed: L33.2, L34.1
unnamed: L34.2, L35.1
unnamed: L35.2, L36.1
unnamed: L36.2, L37.1
unnamed: L37.2, L38.1
unnamed: L38.2, L39.1
unnamed: L39.2, L40.1
unnamed: L40.2, L41.1
unnamed: L41.2, L42.1
unnamed: L42.2, L43.1
unnamed: L43.2, L44.1
unnamed: L44.2, L45.1
unnamed: L45.2, L46.1
unnamed: L46.2, L47.1
unnamed: L47.2, L48.1
unnamed: L48.2, L49.1
unnamed: L49.2, L50.1
unnamed: L50.2, L51.1
unnamed: L51.2, L52.1
unnamed: L52.2, L53.1
unnamed: L53.2, L54.1
unnamed: L54.2, L55.1
unnamed: L55.2, L56.1
unnamed: L56.2, L57.1
unnamed: L62.2, L63.1
unnamed: L65.2, L66.1
unnamed: L68.2, L69.1
unnamed: L69.2, L70.1
unnamed: L70.2, L71.1
unnamed: L71.2, L72.1

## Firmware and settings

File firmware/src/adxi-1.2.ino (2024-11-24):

// adxi-1.2 firmware
//
//  website: https://github.com/vk2diy/adxi
//  license: GPLv3 
//  credits: based on the ADX project @ https://github.com/WB2CBA/ADX
//
//  major changes from ADX-era firmware:
//   - restructured for platformio
//   - restructured for adxi-1.2 hardware
//     - added forward and reverse power and SWR sensing
//     - added USB and audio chipset status display
//   - removed blinkenlights / buttons interface
//   - removed EEPROM use

// debug strings
#define __COMPILER__ "gcc " __VERSION__ " @ " __DATE__ " " __TIME__
#define __FILENAME__ (strrchr(__FILE__, '/') ? strrchr(__FILE__, '/') + 1 : __FILE__)

// libraries
#include <si5351.h>     // clock generator
#include "Wire.h"       // I2C
#include "SPI.h"        // SPI

// MCU pin definitions
#define PIN_CM108B_LEDR_INPUT 2
#define PIN_CM108B_LEDO_INPUT 3
#define PIN_TUSB321_IMODE1_INPUT 4
#define PIN_TUSB321_IMODE2_INPUT 5
#define PIN_HOST_FSK_INPUT 7
#define PIN_RECEIVE_ENABLE_WHEN_LOW_OUTPUT 8
#define PIN_PA_DRIVE_PWM_OUTPUT 9
#ifdef PIN_SPI_MOSI
 #undef PIN_SPI_MOSI
#endif
#define PIN_SPI_MOSI 11
#define PIN_SPI_SS_3V3OUTPUTS 12
#ifdef PIN_SPI_SCK
 #undef PIN_SPI_SCK
#endif
#define PIN_SPI_SCK 13
#define PIN_FORWARD_POWER_INPUT 14
#define PIN_REVERSE_POWER_INPUT 15
#define PIN_I2C_SDA 18
#define PIN_I2C_SCL 19

// 3.3V output pin definitions
#define PIN_3V3OUT_CM108B_VOLUME_UP_WHEN_LOW 1
#define PIN_3V3OUT_CM108B_VOLUME_DOWN_WHEN_LOW 2
#define PIN_3V3OUT_CM108B_MUTE_RECORDING_WHEN_LOW 3
#define PIN_3V3OUT_CM108B_MUTE_PLAYBACK_WHEN_LOW 4
#define PIN_3V3OUT_CM108B_SLEEP_WHEN_LOW 5

// other
#define SI5351_REF 25000000UL // 25MHz

// constants
unsigned long SI5351_CALIBRATION_FREQUENCY_HZ = 1000000UL; // 1MHz = 1000000Hz
unsigned long SI5351_CALIBRATION_FACTOR = 0;

// ---------------- unsorted prior variable definitions: not yet reviewed ----------------
unsigned int temp = 0;
unsigned int mode = 0;
unsigned int Band_slot = 0;
unsigned int Band = 0;

boolean TX_State = 0;

unsigned long freq = 0;
unsigned long F_FT8;
unsigned long F_FT4;
unsigned long F_JS8;
unsigned long F_WSPR;

boolean cat_stat = 0;
boolean TxStatus = 0; //0 =  RX 1=TX
unsigned int CAT_mode = 2;
String received;
String receivedPart1;
String receivedPart2;
String command;
String command2;
String parameter;
String parameter2;
String serial_response;
String serial_response_additional;

//**********************************[ BAND SELECT ]************************************************
// ADX can support up to 4 bands on board. Those 4 bands needs to be assigned to Band1 ... Band4 from supported 6 bands.
// To change bands press SW1 and SW2 simultaneously. Band LED will flash 3 times briefly and stay lit for the stored band. also TX LED will be lit to indicate
// that Band select mode is active. Now change band bank by pressing SW1(<---) or SW2(--->). When desired band bank is selected press TX button briefly to exit band select mode.
// Now the new selected band bank will flash 3 times and then stored mode LED will be lit.
// TX won't activate when changing bands so don't worry on pressing TX button when changing bands in band mode.

// Assign your prefered bands to B1,B2,B3 and B4
// Supported Bands are: 80m, 40m, 30m, 20m,17m, 15m

unsigned int Band1 = 40; // Band 1 // These are my default bands. Feel free to swap with yours
unsigned int Band2 = 30; // Band 2
unsigned int Band3 = 20; // Band 3
unsigned int Band4 = 17; // Band 4

Si5351 si5351;

//*************************************[ SETUP FUNCTION ]**************************************
void setup() {
  Serial.begin(115200);
  Serial.setTimeout(4);

  //delay(150);

/*
  Serial.println();
  Serial.println();
  Serial.println(__FILENAME__);
  Serial.println(__COMPILER__);
  Serial.println();
  Serial.println(F("init"));

  Serial.print(F(" - "));
  Serial.print(F("pins"));
  Serial.print(F("..."));
  Serial.print(F(" "));
*/
  pinMode(PIN_CM108B_LEDR_INPUT,INPUT);
  pinMode(PIN_CM108B_LEDO_INPUT,INPUT);
  pinMode(PIN_TUSB321_IMODE1_INPUT,INPUT);
  pinMode(PIN_TUSB321_IMODE2_INPUT,INPUT);
  pinMode(PIN_HOST_FSK_INPUT,INPUT);
  pinMode(PIN_RECEIVE_ENABLE_WHEN_LOW_OUTPUT,OUTPUT);
  pinMode(PIN_PA_DRIVE_PWM_OUTPUT,OUTPUT);
  pinMode(PIN_SPI_MOSI,OUTPUT);
  pinMode(PIN_SPI_SS_3V3OUTPUTS,OUTPUT);
  pinMode(PIN_SPI_SCK,OUTPUT);
  pinMode(PIN_FORWARD_POWER_INPUT,INPUT);
  pinMode(PIN_REVERSE_POWER_INPUT,INPUT);
  pinMode(PIN_I2C_SDA,INPUT);
  pinMode(PIN_I2C_SCL,OUTPUT);
  digitalWrite(PIN_RECEIVE_ENABLE_WHEN_LOW_OUTPUT,HIGH);
  digitalWrite(PIN_PA_DRIVE_PWM_OUTPUT,LOW);
  digitalWrite(PIN_SPI_MOSI,LOW);
  digitalWrite(PIN_SPI_SS_3V3OUTPUTS,LOW);
  digitalWrite(PIN_SPI_SCK,LOW);
  digitalWrite(PIN_I2C_SCL,LOW);
/*
  Serial.println(F("OK"));
  
  Serial.print(F(" - "));
  Serial.print(F("si5351"));
  Serial.print(F("..."));
  Serial.print(F(" "));
*/
  //si5351.init(SI5351_CRYSTAL_LOAD_10PF, 0, 0); // Ooh dang! We have 12pF. That's not good. Bug!
  si5351.init(SI5351_CRYSTAL_LOAD_0PF, 0, 0); // Ooh dang! We have 12pF. That's not good. Bug!
  si5351.set_clock_pwr(SI5351_CLK0, 0); // disable at startup
  si5351.set_clock_pwr(SI5351_CLK1, 0); // disable at startup
  si5351.set_clock_pwr(SI5351_CLK2, 0); // unused
  si5351.set_correction(SI5351_CALIBRATION_FACTOR, SI5351_PLL_INPUT_XO);
  si5351.set_pll(SI5351_PLL_FIXED, SI5351_PLLA);
  si5351.drive_strength(SI5351_CLK0, SI5351_DRIVE_8MA); // maximum power on transmit clock
  si5351.drive_strength(SI5351_CLK1, SI5351_DRIVE_2MA); // reduced power on receive clock
  si5351.drive_strength(SI5351_CLK2, SI5351_DRIVE_2MA); // unused
/*
  Serial.println(F("OK"));

  Serial.print(F(" - "));
  Serial.print(F("SPI"));
  Serial.print(F("..."));
  Serial.print(F(" "));
*/
  SPI.begin();
/*
  Serial.println(F("OK"));

  Serial.print(F(" - "));
  Serial.print(F("timer"));
  Serial.print(F("..."));
  Serial.print(F(" "));
*/
  TCCR1A = 0x00;
  TCCR1B = 0x01; // Timer1 Timer 16 MHz
  TCCR1B = 0x81; // Timer1 Input Capture Noise Canceller
/*
  Serial.println(F("OK"));

  Serial.print(F(" - "));
  Serial.print(F("comparator"));
  Serial.print(F("..."));
  Serial.print(F(" "));
*/
  ACSR |= (1<<ACIC);  // Analog Comparator Capture Input
/*
  Serial.println(F("OK"));
*/


}

void receive_enable(void) {
 transmit_disable();
 digitalWrite(PIN_RECEIVE_ENABLE_WHEN_LOW_OUTPUT,LOW);
 si5351.set_freq(freq * 100ULL, SI5351_CLK1); // set receive frequency
 si5351.output_enable(SI5351_CLK1, 1); // receive enable
}

void receive_disable(void) {
 digitalWrite(PIN_RECEIVE_ENABLE_WHEN_LOW_OUTPUT,HIGH);
 si5351.output_enable(SI5351_CLK1, 0); // receive disable
}

void transmit_disable(void) {
 si5351.output_enable(SI5351_CLK0, 0); // transmit disable
}

void transmit_enable(void) {
 receive_disable();
 si5351.output_enable(SI5351_CLK0, 1); // transmit enable
}

unsigned int get_forward_power(void) {
 return analogRead(PIN_FORWARD_POWER_INPUT);
}

unsigned int get_reverse_power(void) {
 return analogRead(PIN_REVERSE_POWER_INPUT);
}

unsigned int get_standing_wave_ratio(void) {
 unsigned int rvp;
 unsigned int fwp;
 rvp = get_reverse_power();
 if(rvp!=0) {
  fwp = get_forward_power();
  return fwp/rvp;
 }
 return 0;
}

int get_cm108b_ledr(void) {
 return digitalRead(PIN_CM108B_LEDR_INPUT);
}

int get_cm108b_ledo(void) {
 return digitalRead(PIN_CM108B_LEDO_INPUT);
}

int get_tusb321_imode1(void) {
 return digitalRead(PIN_TUSB321_IMODE1_INPUT);
}

int get_tusb321_imode2(void) {
 return digitalRead(PIN_TUSB321_IMODE2_INPUT);
}

void test_signal() {
 // test signal
 //si5351.set_freq((1 * 100ULL), SI5351_CLK0);
 //si5351.output_enable(SI5351_CLK0, 1); // transmit enable

 si5351.set_freq(SI5351_CALIBRATION_FREQUENCY_HZ * 100ULL / 2, SI5351_CLK0);
 si5351.set_freq(SI5351_CALIBRATION_FREQUENCY_HZ * 100ULL, SI5351_CLK1);
 si5351.drive_strength(SI5351_CLK0, SI5351_DRIVE_2MA); // low power
 si5351.set_clock_pwr(SI5351_CLK0, 1); // enable clock
 si5351.drive_strength(SI5351_CLK1, SI5351_DRIVE_2MA); // low power
 si5351.set_clock_pwr(SI5351_CLK1, 1); // enable clock
 delay(100); // FIXTHIS: avoid delay()
 si5351.set_clock_pwr(SI5351_CLK0, 0); // disable clock
 si5351.set_clock_pwr(SI5351_CLK1, 0); // disable clock
 delay(100); // FIXTHIS: avoid delay()
}

void loop() {
 //test_signal();
/*
  unsigned int fwp;
  fwp = get_forward_power();
  unsigned int rvp;
  rvp = get_reverse_power();
  unsigned int swr;
  swr = get_standing_wave_ratio();
  unsigned int ledr;
  ledr = get_cm108b_ledr();
  unsigned int ledo;
  ledo = get_cm108b_ledo();
  unsigned int imode1;
  imode1 = get_tusb321_imode1();
  unsigned int imode2;
  imode2 = get_tusb321_imode2();

  // print status information
  Serial.print(F(" - "));
  Serial.print(F("FWP"));
  Serial.print(F(": "));
  Serial.print(fwp);
  Serial.print(F(" / "));
  Serial.print(F("RVP"));
  Serial.print(F(": "));
  Serial.print(rvp);
  Serial.print(F(" / "));
  Serial.print(F("SWR"));
  Serial.print(F(": "));
  Serial.print(swr);
  Serial.print(F(" / "));
  Serial.print(F("LEDR"));
  Serial.print(F(": "));
  Serial.print(ledr);
  Serial.print(F(" / "));
  Serial.print(F("LEDO"));
  Serial.print(F(": "));
  Serial.print(ledo);
  Serial.print(F(" / "));
  Serial.print(F("IMODE1"));
  Serial.print(F(": "));
  Serial.print(imode1);
  Serial.print(F(" / "));
  Serial.print(F("IMODE2"));
  Serial.print(F(": "));
  Serial.println(imode2);

  delay(500);

*/

  // ------------------------ start previous code (modified) --------------------------
  if ((Serial.available() > 0) || (cat_stat == 1)) {
//Serial.print(F("_"));
    cat_stat = 1;
//    Serial.print(F(" process_host_serial_input() "));
//    Serial.print(F("start"));
//    Serial.println(F("..."));
    process_host_serial_input();
//    Serial.print(F(" process_host_serial_input() "));
//    Serial.println(F("stop"));
//    Serial.print(F(" receive_enable() "));
//    Serial.print(F("start"));
//    Serial.println(F("..."));
    receive_enable();
//    Serial.print(F(" receive_enable() "));
//    Serial.println(F("stop"));
//    Serial.println(F("/"));
  }
  else {  
//   Serial.println(" other()");
//   Serial.print(F("*"));

   // The following code is from JE1RAV https://github.com/je1rav/QP-7C
   //(Using 3 cycles for timer sampling to improve the precision of frequency measurements)
   //(Against overflow in low frequency measurements)
 
   int FSK = 1;
   int FSKtx = 0;
 
   while (FSK>0) {
     int Nsignal = 10;
     int Ncycle01 = 0;
     int Ncycle12 = 0;
     int Ncycle23 = 0;
     int Ncycle34 = 0;
     unsigned int d1=1,d2=2,d3=3,d4=4;
 
     TCNT1 = 0;
     while (ACSR &(1<<ACO)) {
       if (TIFR1&(1<<TOV1)) {
         Nsignal--;
         TIFR1 = _BV(TOV1);
         if (Nsignal <= 0) {
           break;
         }
       }
     }
     while ((ACSR &(1<<ACO))==0) {
       if (TIFR1&(1<<TOV1)) {
         Nsignal--;
         TIFR1 = _BV(TOV1);
         if (Nsignal <= 0) {
           break;
         }
       }
     }
     if (Nsignal <= 0) {
       break;
     }
     TCNT1 = 0;
     while (ACSR &(1<<ACO)) {
         if (TIFR1&(1<<TOV1)) {
         Ncycle01++;
         TIFR1 = _BV(TOV1);
         if (Ncycle01 >= 2) {
           break;
         }
       }
     }
     d1 = ICR1;
     while ((ACSR &(1<<ACO))==0) {
       if (TIFR1&(1<<TOV1)) {
         Ncycle12++;
         TIFR1 = _BV(TOV1);
         if (Ncycle12 >= 3) {
           break;
         }
       }
     }
     while (ACSR &(1<<ACO)) {
       if (TIFR1&(1<<TOV1)) {
         Ncycle12++;
         TIFR1 = _BV(TOV1);
         if (Ncycle12 >= 6) {
           break;
         }
       }
     }
     d2 = ICR1;
     while ((ACSR &(1<<ACO))==0) {
       if (TIFR1&(1<<TOV1)) {
         Ncycle23++;
         TIFR1 = _BV(TOV1);
         if (Ncycle23 >= 3) {
           break;
         }
       }
     }
     while (ACSR &(1<<ACO)) {
       if (TIFR1&(1<<TOV1)) {
         Ncycle23++;
         TIFR1 = _BV(TOV1);
         if (Ncycle23 >= 6) {
           break;
         }
       }
     }
     d3 = ICR1;
     while ((ACSR &(1<<ACO))==0) {
       if (TIFR1&(1<<TOV1)) {
         Ncycle34++;
         TIFR1 = _BV(TOV1);
         if (Ncycle34 >= 3) {
           break;
         }
       }
     }
     while (ACSR &(1<<ACO)) {
       if (TIFR1&(1<<TOV1)) {
         Ncycle34++;
         TIFR1 = _BV(TOV1);
         if (Ncycle34 >= 6) {
           break;
         }
       }
     }
     d4 = ICR1;
     unsigned long codefreq1 = 1600000000/(65536*Ncycle12+d2-d1);
     unsigned long codefreq2 = 1600000000/(65536*Ncycle23+d3-d2);
     unsigned long codefreq3 = 1600000000/(65536*Ncycle34+d4-d3);
     unsigned long codefreq = (codefreq1 + codefreq2 + codefreq3)/3;
     if (d3==d4) codefreq = 5000;
     if ((codefreq < 310000) && (codefreq >= 10000)) {   // Frequency between 100 Hz and 3100 Hz
       if (FSKtx == 0) { transmit_enable(); }
       // update transmit clock frequency
       si5351.set_freq((freq * 100ULL + codefreq), SI5351_CLK0);
       if (cat_stat == 1) process_host_serial_input();
       FSKtx = 1;
     }
     else {
       FSK--;
     }
   }
 
   receive_enable();
   TX_State = 0;
   FSKtx = 0;
 }
 // -------------------------------- end previous code (modified) ----------------------------------

}

// void band_frequencies(void) {
//   switch (Band) {
//     case 80:
//       F_FT8 = 3573000;
//       F_FT4 = 3575000;
//       F_JS8 = 3578000;
//       F_WSPR = 3568600;
//       break;
//     case 40:
//       F_FT8 = 7074000;
//       F_FT4 = 7047500;
//       F_JS8 = 7078000;
//       F_WSPR = 7038600;
//       break;
//     case 30:
//       F_FT8 = 10136000;
//       F_FT4 = 10140000;
//       F_JS8 = 10130000;
//       F_WSPR = 10138700;
//       break;
//     case 20:
//       F_FT8 = 14074000;
//       F_FT4 = 14080000;
//       F_JS8 = 14078000;
//       F_WSPR = 14095600;
//       break;
//     case 17:
//       F_FT8 = 18100000;
//       F_FT4 = 18104000;
//       F_JS8 = 18104000;
//       F_WSPR = 18104600;
//       break;
//     case 15:
//       F_FT8 = 21074000;
//       F_FT4 = 21140000;
//       F_JS8 = 21078000;
//       F_WSPR = 21094600;
//       break;
//     case 10:
//       F_FT8 = 28074000;
//       F_FT4 = 28180000;
//       F_JS8 = 28078000;
//       F_WSPR = 28124600;
//       break;
//   }
// }

// void SI5351_VFO_calibration(){
//   // Set CLK2 output
//   //si5351.set_correction(SI5351_CALIBRATION_FACTOR, SI5351_PLL_INPUT_XO);
//   si5351.set_freq(SI5351_CALIBRATION_FREQUENCY_HZ * 100ULL, SI5351_CLK2);
//   si5351.drive_strength(SI5351_CLK2, SI5351_DRIVE_2MA); // low power
//   si5351.set_clock_pwr(SI5351_CLK2, 1); // enable clock
//   delay(100); // FIXTHIS: avoid delay()
//   si5351.set_clock_pwr(SI5351_CLK2, 0); // disable clock
// }

// this whole function needs rewriting and can probably be made substantially more efficient
//  ideas:
//   - accept only capitalized input
//   - parse character by character instead of converting to lines in multiple passes then pulling substrings
void process_host_serial_input(void) {

  received = Serial.readStringUntil("\n"); // was readString()
  //received.toUpperCase(); // this is a performance loss
  //received.replace("\n",""); // this is a performance loss

  String data = "";
  int bufferIndex = 0;

  for (unsigned int i = 0; i < received.length(); ++i) {
    char c = received[i];
    if (c != ';') {
      data += c;
    }
    else {
      if (bufferIndex == 0) {
        data += '\0';
        receivedPart1 = data;
        bufferIndex++;
        data = "";
      }
      else {
        data += '\0';
        receivedPart2 = data;
        bufferIndex++;
        data = "";
      }
    }
  }


  command = receivedPart1.substring(0,2);
  command2 = receivedPart2.substring(0,2);
  parameter = receivedPart1.substring(2,receivedPart1.length());
  parameter2 = receivedPart2.substring(2,receivedPart2.length());
 /*
  Serial.print("Command = '");
  Serial.print(command);
  Serial.println("'");
 */

  if (command == "FA") {
    if (parameter != "") {
      freq = parameter.toInt();
      //VfoRx = VfoTx;
    }
    serial_response = "FA" // Return 11 digit frequency in Hz.
      + String("00000000000").substring(0,11-(String(freq).length()))
      + String(freq) + ";";
  }
  else if (command == "PS") {
    serial_response = "PS1;";
  }
  else if (command == "TX") {
    serial_response = "TX0;";
    transmit_enable();
    TxStatus = 1;
  }
  else if (command == "RX") {
    serial_response = "RX0;";
    receive_enable();
    TxStatus = 0;
  }
  else  if (command == "ID") {
    serial_response = "ID019;";
  }
  else if (command == "AI") {
    serial_response = "AI0;";
  }
  else if (command == "IF") {
    if (TxStatus == 1) {
      serial_response = "IF" // Return 11 digit frequency in Hz.
        + String("00000000000").substring(0,11-(String(freq).length()))
        + String(freq) + "00000" + "+" + "0000" + "0" + "0" + "0" + "00" + "1" + String(CAT_mode) + "0" + "0" + "0" + "0" + "000" + ";";
    }
    else {
      serial_response = "IF" // Return 11 digit frequency in Hz.
        + String("00000000000").substring(0,11-(String(freq).length()))
        + String(freq) + "00000" + "+" + "0000" + "0" + "0" + "0" + "00" + "0" + String(CAT_mode) + "0" + "0" + "0" + "0" + "000" + ";";
    }
  }
  else if (command == "MD") {
    serial_response = "MD2;";
  }

  //------------------------------------------------------------------------------

  // Now actually respond
  if (command2 == "ID") {
    serial_response_additional = "ID019;";
  }
  if (bufferIndex == 2) {
    Serial.print(serial_response_additional);
  }
  else {
    Serial.print(serial_response);
  }

  if ((command == "RX") || (command = "TX")) delay(50); // FIXTHIS: avoid delay()

  // Flush for next iteration
  serial_response = String("");
  serial_response_additional = String("");
  command="";
  command2="";
}

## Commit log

2024-08-03 Initial cleanup
    [ADX QUAD BOM.xlsx, ADX Serial resonance Band filter module component selection table.xlsx, ADX.kicad_pcb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]
2024-08-07 Revised board in progress
    [adxi.kicad_pcb, adxi.kicad_sch]
2024-08-07 Draft PCB
2024-08-07 Input filter model
2024-08-07 Bandpass filter model
2024-08-07 DC blocking filter
2024-08-09 LPFs, footprints, component selection, switching
    [adxi.kicad_pcb, adxi.kicad_sch, lpf-10m-smt.kicad_sch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]
2024-08-09 More bands
    [adxi.kicad_sch, lpf-10m-smt.kicad_sch, lpf-12m-smt.kicad_sch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]
2024-08-09 Antenna tuning
2024-08-14 Working inductor array
    [pa-switched-rf-choke.kicad_sch]
2024-08-18 More outputs, etc
    [adxi.kicad_pcb, adxi.kicad_sch, nfet-highside-load-switch.kicad_sch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]
2024-08-18 RF choke for 70cm
    [adxi.kicad_sch, nfet-highside-load-switch.kicad_sch, pa-switched-rf-choke.kicad_sch]
2024-08-18 Closer to functional PA
    [adxi.kicad_sch]
2024-08-19 Further PA choke work
    [adxi.kicad_sch, nfet-highside-load-switch.kicad_sch]
2024-08-19 Pluggable PAs
    [adxi.kicad_sch, nfet-highside-load-switch.kicad_sch]
2024-08-21 Significant updates
    [adxi.kicad_pcb, adxi.kicad_sch]
2024-08-22 Toward one USB cable
    [adxi.kicad_sch]
2024-08-23 New footprints and 3D models
2024-08-23 USB work
    [adxi.kicad_pcb, adxi.kicad_sch, spi-gpio-output.kicad_sch]
2024-08-26 SPI level conversion
2024-08-26 Another model
    [adxi.kicad_pcb, adxi.kicad_sch]
2024-08-27 Model switching harmonics
2024-09-01 Improvements to receiver
    [adxi.kicad_pcb, adxi.kicad_sch]
2024-09-02 More work, getting close now!
    [adxi.kicad_pcb, adxi.kicad_sch, nfet-highside-load-switch.kicad_sch]
2024-09-02 Official footprint with shared drain pin, SMT type and courtyard added
2024-09-02 Simplify PSU, add 4xM3 mounting holes, silkscreen, better footprints
    [adxi.kicad_pcb, adxi.kicad_sch, nfet-highside-load-switch.kicad_sch]
2024-09-02 Update docs to match revised simplified PSU schematic
2024-09-02 Layout complete
    [adxi.kicad_pcb, adxi.kicad_sch]
2024-09-03 Fixed vias
    [adxi.kicad_pcb, adxi.kicad_sch, nfet-highside-load-switch.kicad_sch]
2024-09-03 move schematics out of board
    [lpf-10m-smt.kicad_sch, lpf-12m-smt.kicad_sch, lpf-15m-smt.kicad_sch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]
2024-09-03 Add extra silkscreen
2024-09-03 Minor changes only
    [adxi.kicad_pcb]
2024-09-03 Minor silkscreen updates
2024-09-03 First late-stage module band selection
2024-09-04 More symbols/footprints
2024-09-04 LSM prototype
    [adxi-lsm-20m-30m-40m-1.kicad_pcb, adxi-lsm-20m-30m-40m-1.kicad_sch]
2024-09-04 Prototype LSM
2024-09-05 20m/30m/40m late stage module
    [adxi-lsm-20m-30m-40m-1.kicad_pcb, adxi-lsm-20m-30m-40m-1.kicad_sch]
2024-09-17 Diode selection
2024-10-23 Final board
    [adxi-lsm-20m-30m-40m-2.kicad_pcb, adxi-lsm-20m-30m-40m-2.kicad_sch]
2024-10-24 Fix 150pF 0603 footprint incorrectly specified as 0201
    [adxi-lsm-20m-30m-40m-2.kicad_pcb, adxi-lsm-20m-30m-40m-2.kicad_sch]
2024-10-26 Move old files out of the way
    [lpf-10m-smt.kicad_sch, lpf-12m-smt.kicad_sch, lpf-15m-smt.kicad_sch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]
2024-10-26 Update footprint
2024-10-26 Commit outstanding files related to Kicad v8 updates
    [ADX.kicad_pcb, ADX.kicad_sch]
2024-11-09 Update notes
    [adxi.kicad_pcb, adxi.kicad_sch]
2024-11-10 Add analog comparator note; more explicit net names
    [adxi.kicad_sch]
2024-11-11 3V3 output pin name
2024-11-11 Explicit pin names
2024-11-24 Test routine; correct clock chip init; better variable names; RX/TX enable/disable; debugging; silence redef warnings
    [adxi-1.2.ino]
2025-01-18 Antenna build
2025-01-18 More antenna goodness
